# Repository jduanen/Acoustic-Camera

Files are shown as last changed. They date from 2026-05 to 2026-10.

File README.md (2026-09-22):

# Acoustic-Camera
The design and implementation of a low-cost, high-performance, acoustic camera

An Acoustic Camera computes a power map of the sound scene that exists within a video camera's field of view and overlays it onto the video in real time.
Capturing, visualizing, and tracking the position of sound sources is useful in a variety of different use cases, including the detection and localization of sources of vibration, gas leaks, electrical breakdown, etc. 
Acoustic Cameras can also serve as a useful prosthetic device for people who have lost hearing in one ear and can no longer localize sound sources.

See an example of a commercial product here [Fluke](https://youtu.be/UPVcwDzhBZ8) and a low-cost consumer product here [Fotric](https://youtu.be/MBhJoPzHv2Y)

# Table of Contents

* [Technical Background](#technical-background)
  - How Microphone Arrays Localize Sound Sources
  - Selected Beamforming Algorithm Families
  - Key Concepts in Beamforming
    * Half-Power Bandwidth (HPBW)
    * Max Sidelobe Level (MSL)
    * Far-Field vs. Near-Field Effects
    * Spatial Nyquist Frequency
    * Low-frequency Limit
    * Cross-Spectral Matrix (CSM)
    * Point Spread Function (PSF)
    * Incoherent Octave-band Averaging
  - Microphone Array Configurations
    * 2D patterns
    * 3D patterns
* [Design Trade-offs](#design-trade-offs)
  - Core Tradeoffs/Tensions
  - Key Specifications
    * Spatial Nyquist Frequency
    * Beamforming Sampling Grid Size
    * Resolution vs. Aperture (HPBW ≈ 58° × λ/D)
    * Array Pattern: Underbrink multi-arm log-spiral (chosen pattern)
* [System Requirements](#system-requirements)
* [Target Design](#target-design)
  - Microphone Array
  - Interface
  - Compute
  - Software
* [Development Plan](#development-plan)
  - [Phase 1: Simulation Findings](#phase-1)
    * Recommended Array Configuration
    * Beamwidth vs Frequency
    * Algorithm Selection
    * Where This System Works Well
    * Where This System is NOT Well-Suited
  - [Phase 2: Smoke Test -- ReSpeaker 4-Mic Array](#phase-2)
    * Hardware Findings
    * Pipeline Validation (nb13)
    * Calibration (nb14)
    * Live Script
  - [Phase 3: Intermediate Array Test -- miniDSP UMA-16 v2](#phase-3)
    * Hardware Findings
    * Live Script
      - Touch UI: Frequency Sliders & Spectrum Pan
      - Touch UI: Energy Threshold Tab & Auto/Manual Range
      - Touch UI: Zoom Mode
      - Power/Throttle Indicator
      - Settings Persistence
    * Algorithm Benchmark Script
    * Lessons from the UMA-16 Experiments
      - Key Intuition
      - Rule of Thumb
      - UMA-16 Usable Frequency Range
  - [Phase 4: Custom Hardware -- 96-mic with FPGA on custom PCB](#phase-4)
  - [Phase 5: ML-based approach](#phase-5)
* [Acoustic Camera Products Overview](#acoustic-camera-products-overview)
* [Beamforming Projects and Libraries](#beamforming-projects-and-libraries)
* [References](#references)
  - Beamforming Algorithms
  - Microphone Array Patterns
  - Commercial Acoustic Camera Products
  - Open-Source Projects and Libraries
* Docs
* Notes

---

## Technical Background

### How Microphone Arrays Localize Sound Sources

The mic array captures the sound field simultaneously at all microphones. A **steering matrix** encodes the expected inter-mic phase pattern for each candidate direction (az, el). A beamformer correlates the received signals against each steering vector and assigns a power value to each grid cell, producing an **energy map** that is overlaid on the video frame.

The key parameters are: **aperture** (sets beam width: larger = sharper), **mic spacing** (sets the spatial Nyquist ceiling; closer = higher frequency limit), and **snapshot count** (sets CSM estimation quality; more = lower noise floor).

### Selected Beamforming Algorithm Families

| Family | Algorithms | Characteristic |
|---|---|---|
| **Delay-and-Sum** | D&S (time or freq domain), Differential, Functional Beamforming | Simple; robust; wide beam; sidelobes mask weak sources |
| **Adaptive / data-dependent** | MVDR (Capon), LCMV, GSC, Frost | Null interferers; sensitive to CSM quality and steering errors |
| **Deconvolution** | CLEAN-SC, CLEAN-PSF, DAMAS, DAMAS2, CMF, COMET2 | Remove PSF artifacts iteratively; reveal secondary sources |
| **Subspace** | MUSIC, Root-MUSIC, ESPRIT, CSSM, TR-MUSIC | Decompose CSM into signal + noise subspaces; super-resolution; require source count estimate |
| **Sparse / Bayesian** | SBL, Atomic Norm Minimization | Gridless; auto-estimates source count; expensive |
| **Spherical-harmonic** | PWD, CroPaC | For spherical arrays; Ambisonics / HOA domain |
| **ML-based** | CNN/CRNN DoA, Transformer (SELD-Conformer), PILOT, Deep MUSIC, NN-MVDR | Learned models; top DCASE benchmarks; need training data matched to array geometry |

In the initial phases of this project, I will explore representative algorithms from each of the first for families -- i.e., D&S, MVDR, CLEAN, and MUSIC.
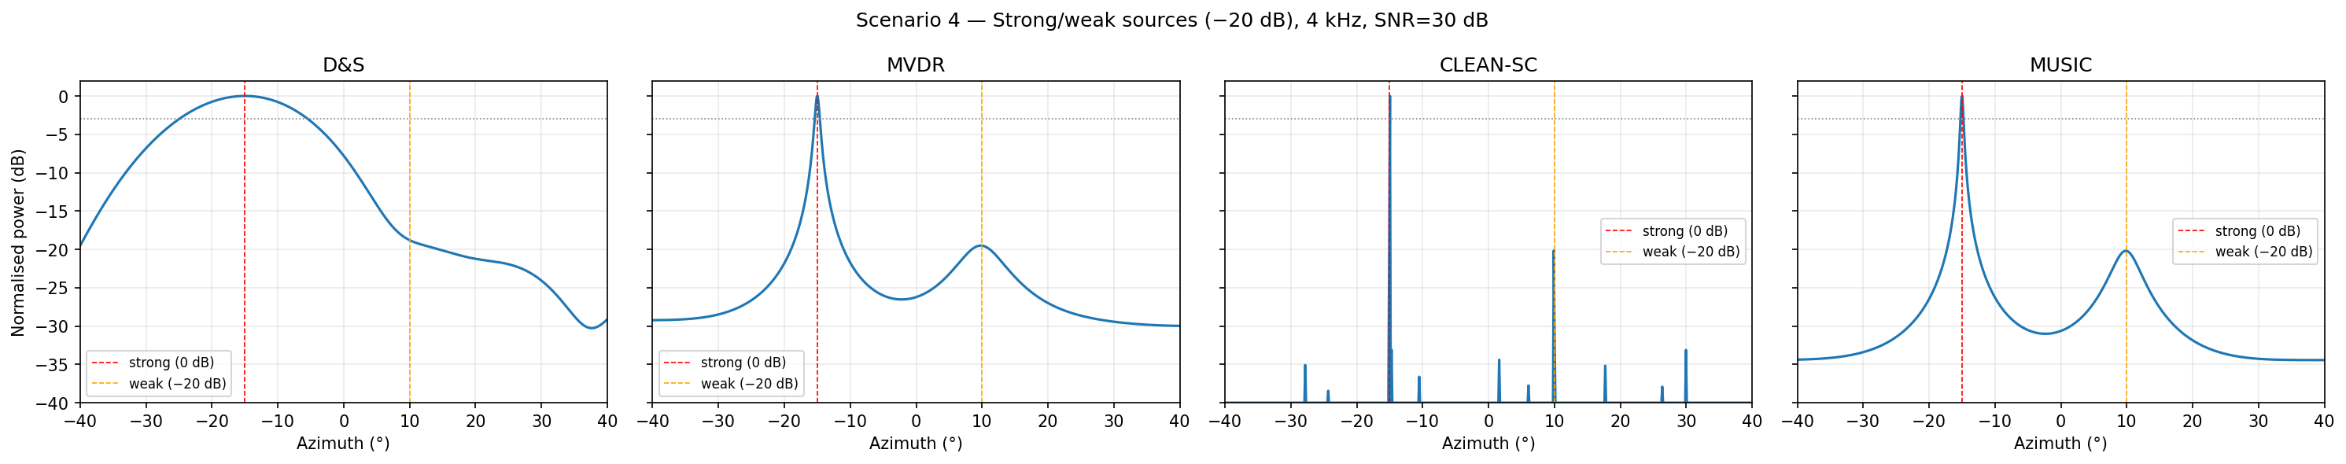
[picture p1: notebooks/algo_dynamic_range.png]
Power vs. Azimuth

**Figure:** *Example power vs. azimuth plots for a strong and a weak sound source for different algorithms*

### Key Concepts in Beamforming

#### Half-Power Bandwidth (HPBW)

HPBW characterizes the angular width of the main lobe of the beam pattern (typically at the −3 dB points).

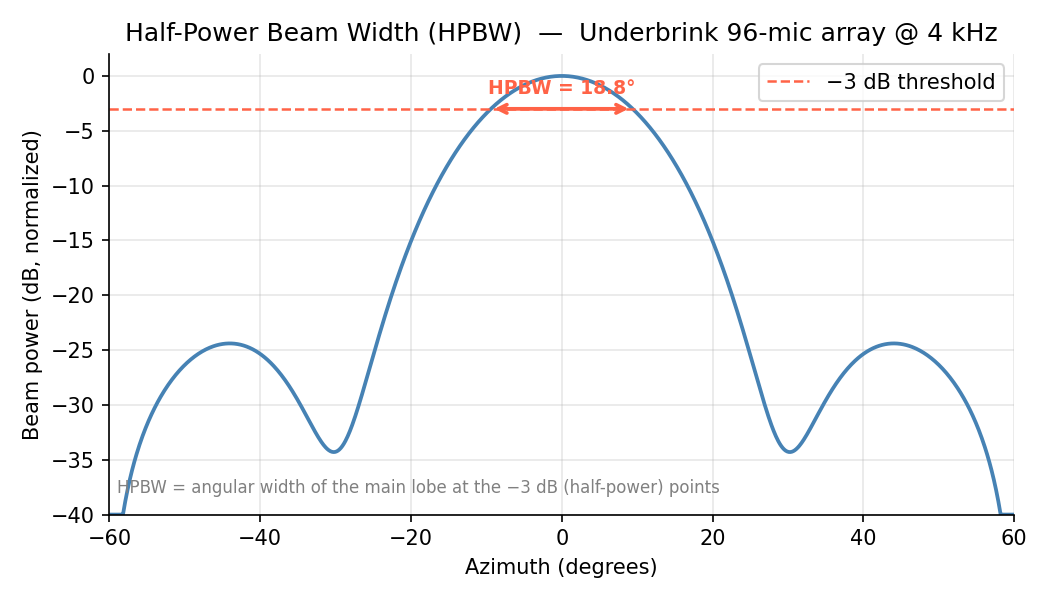
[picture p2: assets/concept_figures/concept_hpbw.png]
HPBW

**Figure:** *Beam pattern with -3 dB crossing points annotated*

#### Max Sidelobe Level (MSL)

MSL is a metric that measures the power of the sidelobes relative to the main‑lobe peak, usually expressed in decibels (e.g., "20 dB below the main lobe"). MSL is largely defined by the distribution of microphones; irregular spacing suppresses aliasing artifacts.

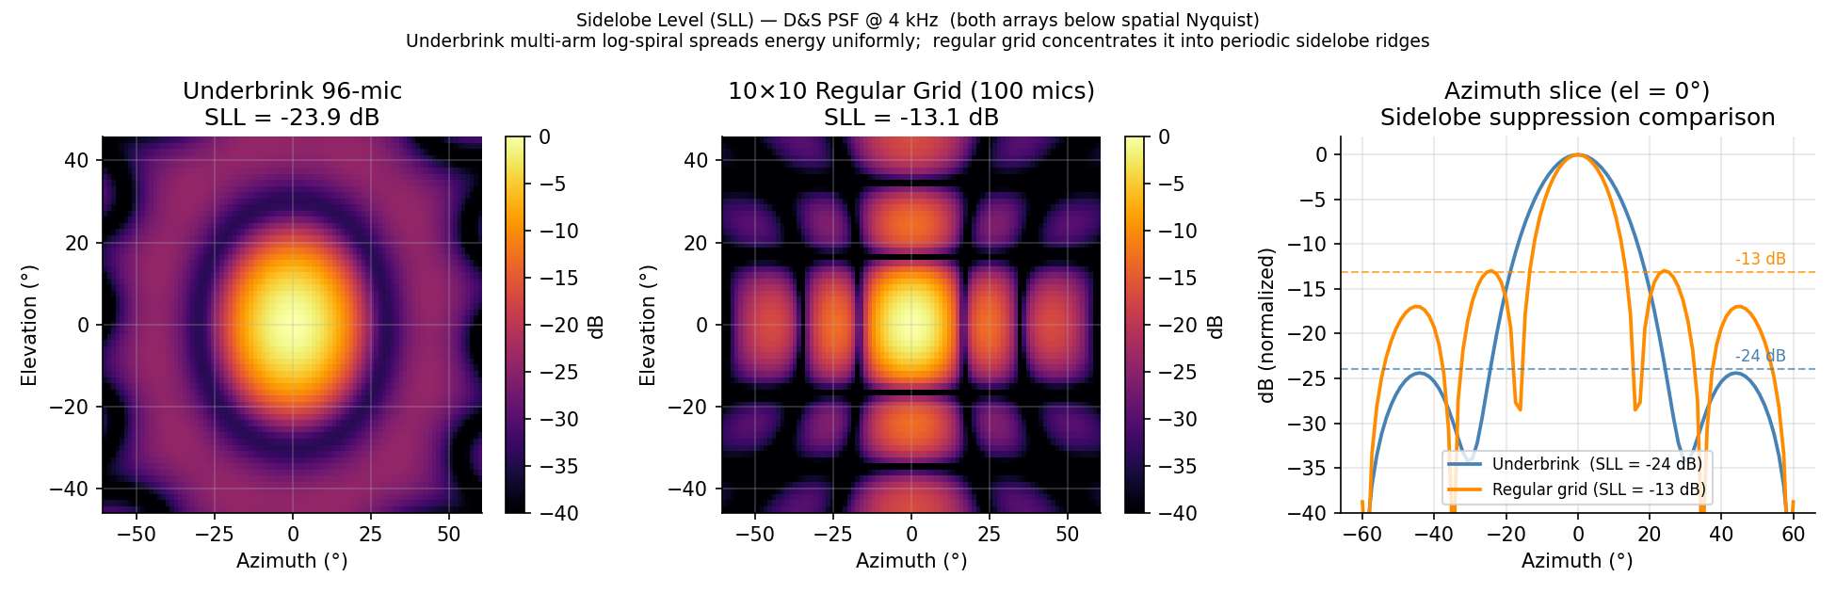
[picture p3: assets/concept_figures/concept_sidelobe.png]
Sidelobe Level

**Figure:** *2D PSF with azimuth slice for Underbrink vs. Regular Grid*

#### Far-Field vs. Near-Field Effects

Far-field (beyond the Fraunhofer distance: *r > 2D²/λ*) assumes plane waves and requires only angle steering; near-field requires a spherical-wave model and adds range estimation.

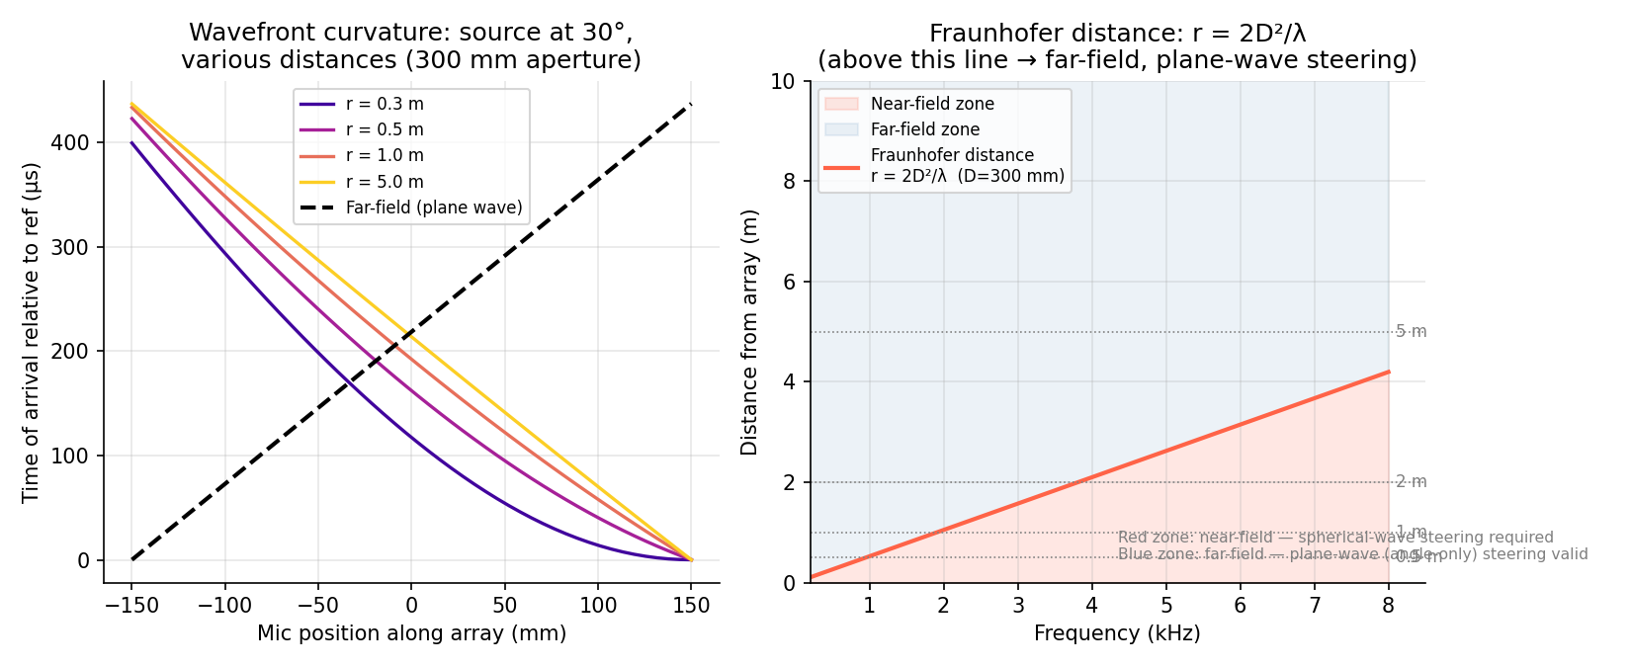
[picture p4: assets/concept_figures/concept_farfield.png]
Far-Field vs Near-Field

**Figure:** *Left: wavefront curvature at different distances; Right: Frauenhofer boundary vs. frequency*

#### Spatial Nyquist Frequency

The upper frequency limit set by mic spacing: *f_max = c / (2 × d_min)*; at frequencies above this, grating lobes appear.

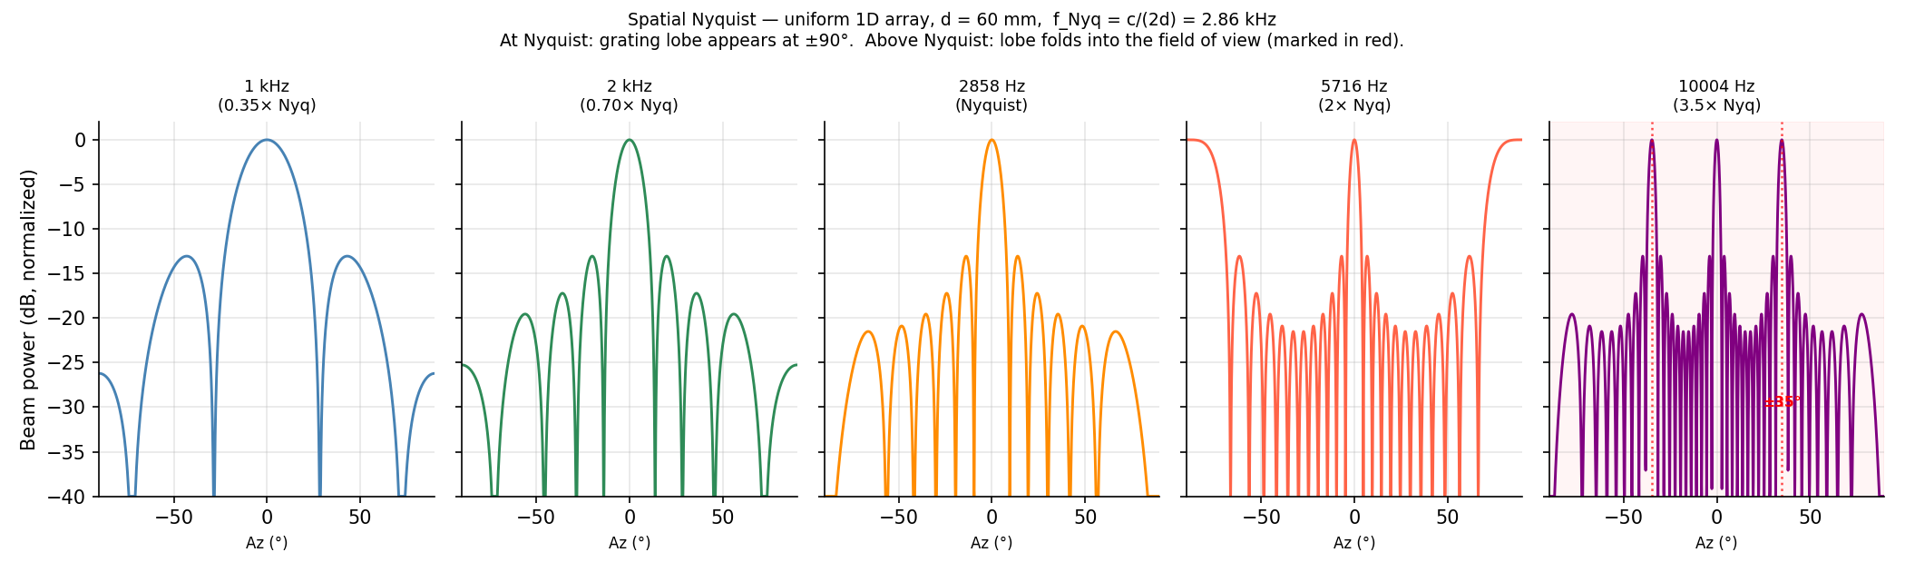
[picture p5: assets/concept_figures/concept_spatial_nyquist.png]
Spatial Nyquist

**Figure:** *1D PSF at five frequencies spanning sub-Nyquist to 3.5x Nyquist*

#### Low-frequency Limit

Usable directionality requires a frequency of roughly *f > c / D* (which is aperture-limited); below this HPBW exceeds ~57° and the array is near-omnidirectional.

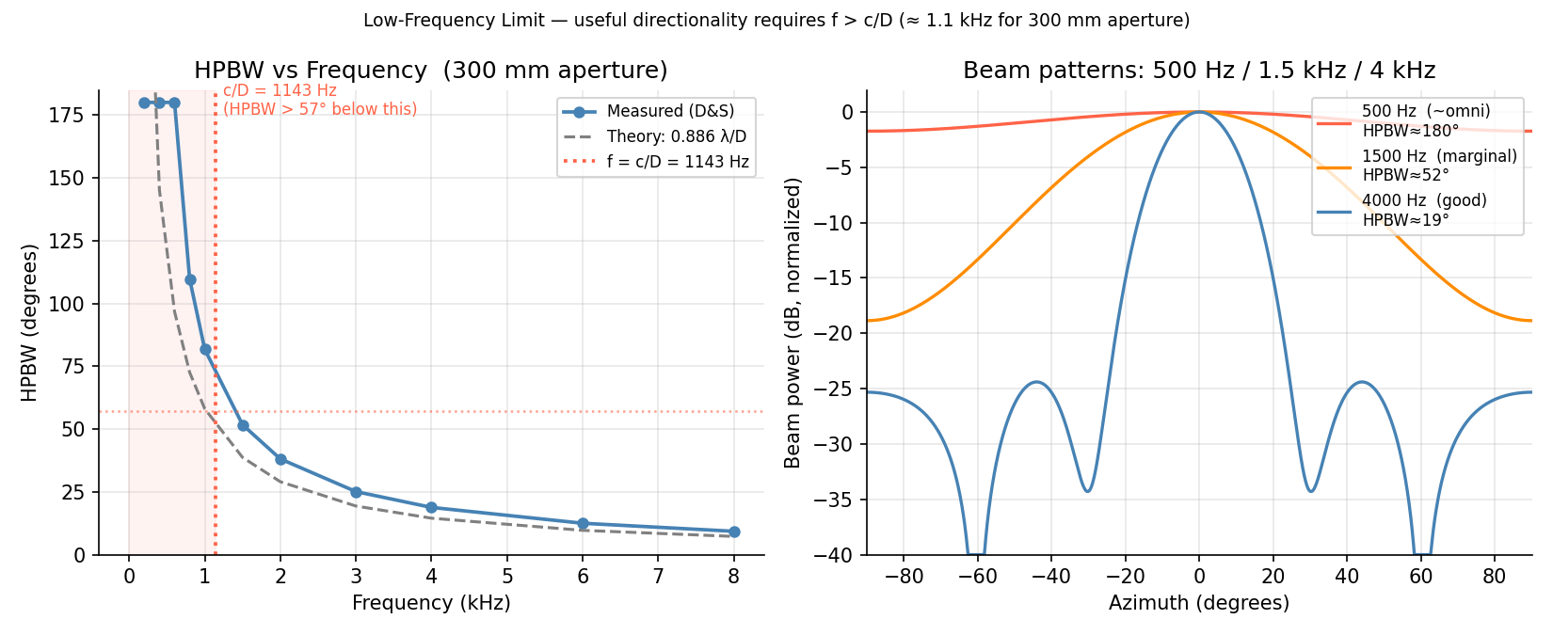
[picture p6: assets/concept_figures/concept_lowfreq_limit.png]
Low-Frequency Limit

**Figure:** *HPBW vs. frequency (measured and theoretic) and three beam patterns*

#### Cross-Spectral Matrix (CSM)

CSM is a frequency-domain matrix of cross-powers between every mic pair; the universal input to all adaptive and subspace beamformers.

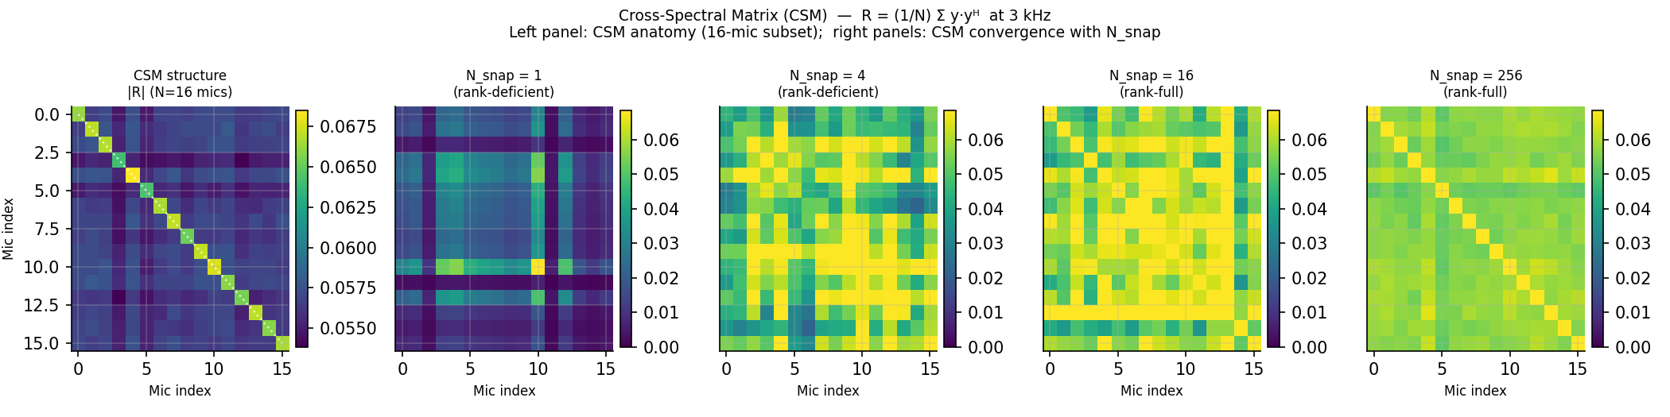
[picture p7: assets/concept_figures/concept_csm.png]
CSM

**Figure:** *Left: |CSM| magnitude heatmap for a single snapshot. Right: CSM convergence as N_snap increases (1 → 256), where N_snap is the number of independent short-time frames averaged to estimate the CSM -- more snapshots reduce the noise floor and improve MVDR/MUSIC stability.*

#### Point Spread Function (PSF)

PSF illustrates how the array smears a true point source; deconvolution methods subtract it out and offer a sharper response.

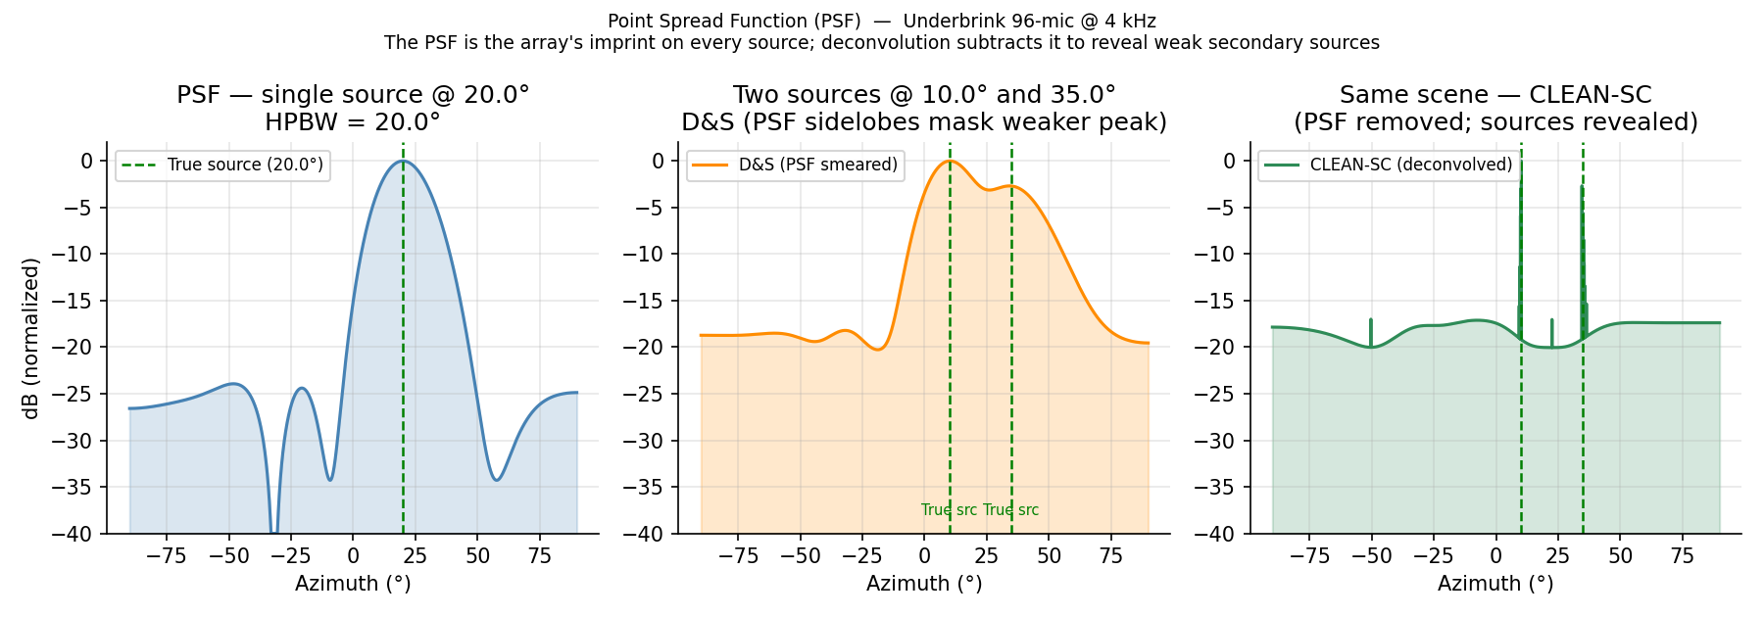
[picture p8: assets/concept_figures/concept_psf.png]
PSF

**Figure:** *Single-source PSF, two-source D&S (smeared) and CLEAN-SC (resolved)*

#### Incoherent Octave-band Averaging

Commercial cameras compute one CSM per frequency bin, beamform each, then average power across an octave band; this suppresses noise by *√K* and produces a band-averaged PSF.

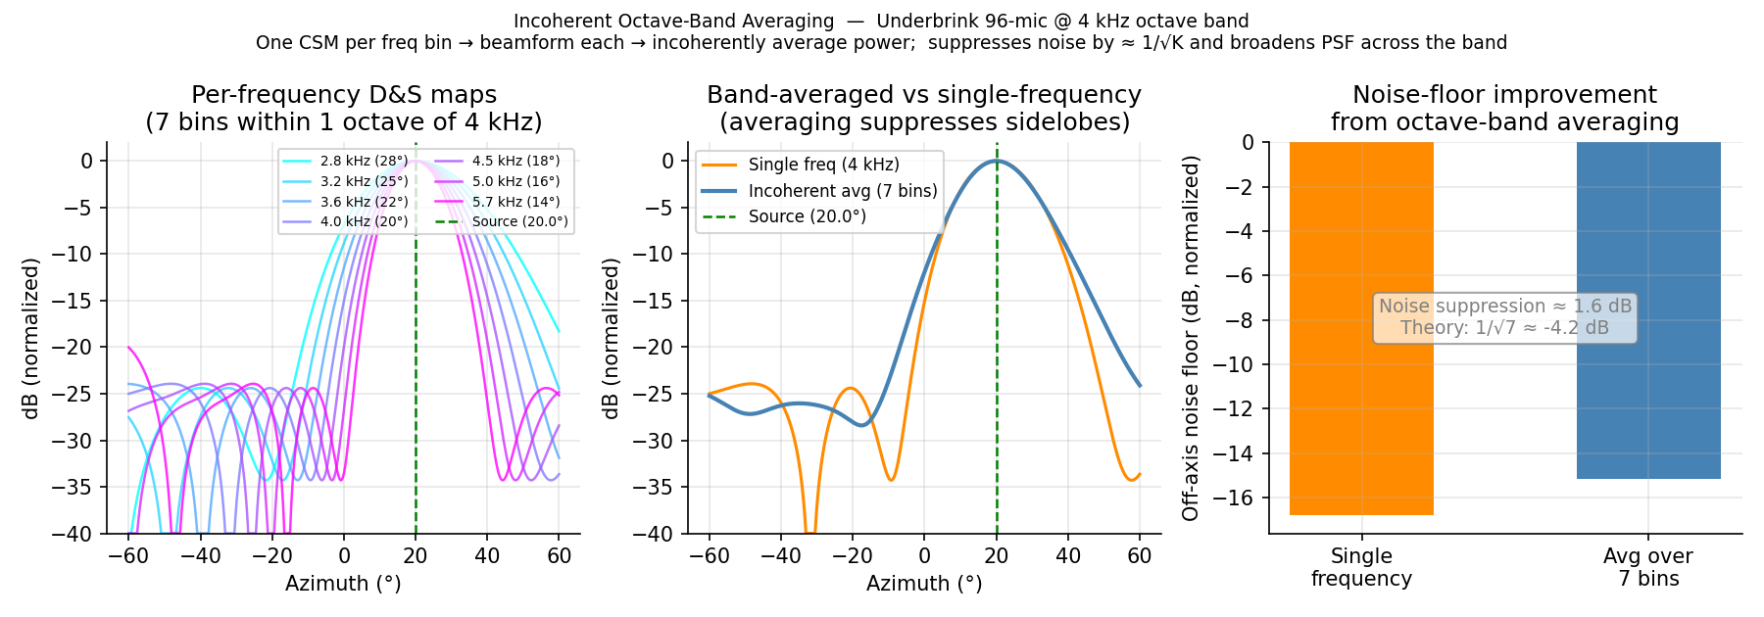
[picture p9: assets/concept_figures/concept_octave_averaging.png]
Octave-Band Averaging

**Figure:** *Per-bin maps, band average, noise-floor bar chart*

See [BACKGROUND.md](./BACKGROUND.md) for full algorithm descriptions and references.

### Microphone Array Configurations

See [MIC_ARRAYS.md](./MIC_ARRAYS.md) for more details on microphone arrays.

Array geometry controls two things: **beam width** (set by aperture; larger = sharper) and **maximum side-lobe level / MSL** (set by mic distribution; irregular spacing suppresses aliasing artifacts). More mics improve both, but with diminishing returns and linear cost growth.

#### 2D patterns

| Pattern | Spacing | Strengths | Weaknesses |
|---|---|---|---|
| **Regular grid** | Uniform | Easy to build; predictable PSF | High, periodic sidelobes; spatial aliasing above Nyquist |
| **Archimedean spiral** | Linear increase with angle | Simple single-arm; even radial coverage | Worse MSL than multi-arm variants |
| **Dougherty log-spiral** | Equal arc-length | Denser center; >10 dB sidelobe suppression at high freq | Single arm; less uniform outer coverage |
| **Arcondoulis** | Adjustable squash | Elliptical or non-circular shapes; tunable center density | More design parameters to optimize |
| **Underbrink** ★ | Multi-arm log-spiral | Best all-around: high resolution + good MSL over wide area; circular symmetry | Patented (US 6,089,671); more complex layout |
| **Brüel & Kjær spiral** | Non-uniform along spokes | Easily disassembled; two concentric hoops | Proprietary geometry |

★ Underbrink is the recommended pattern for this project (see Phase 1 findings). Literature confirms it outperforms other patterns in both resolution and MSL across tested frequencies.

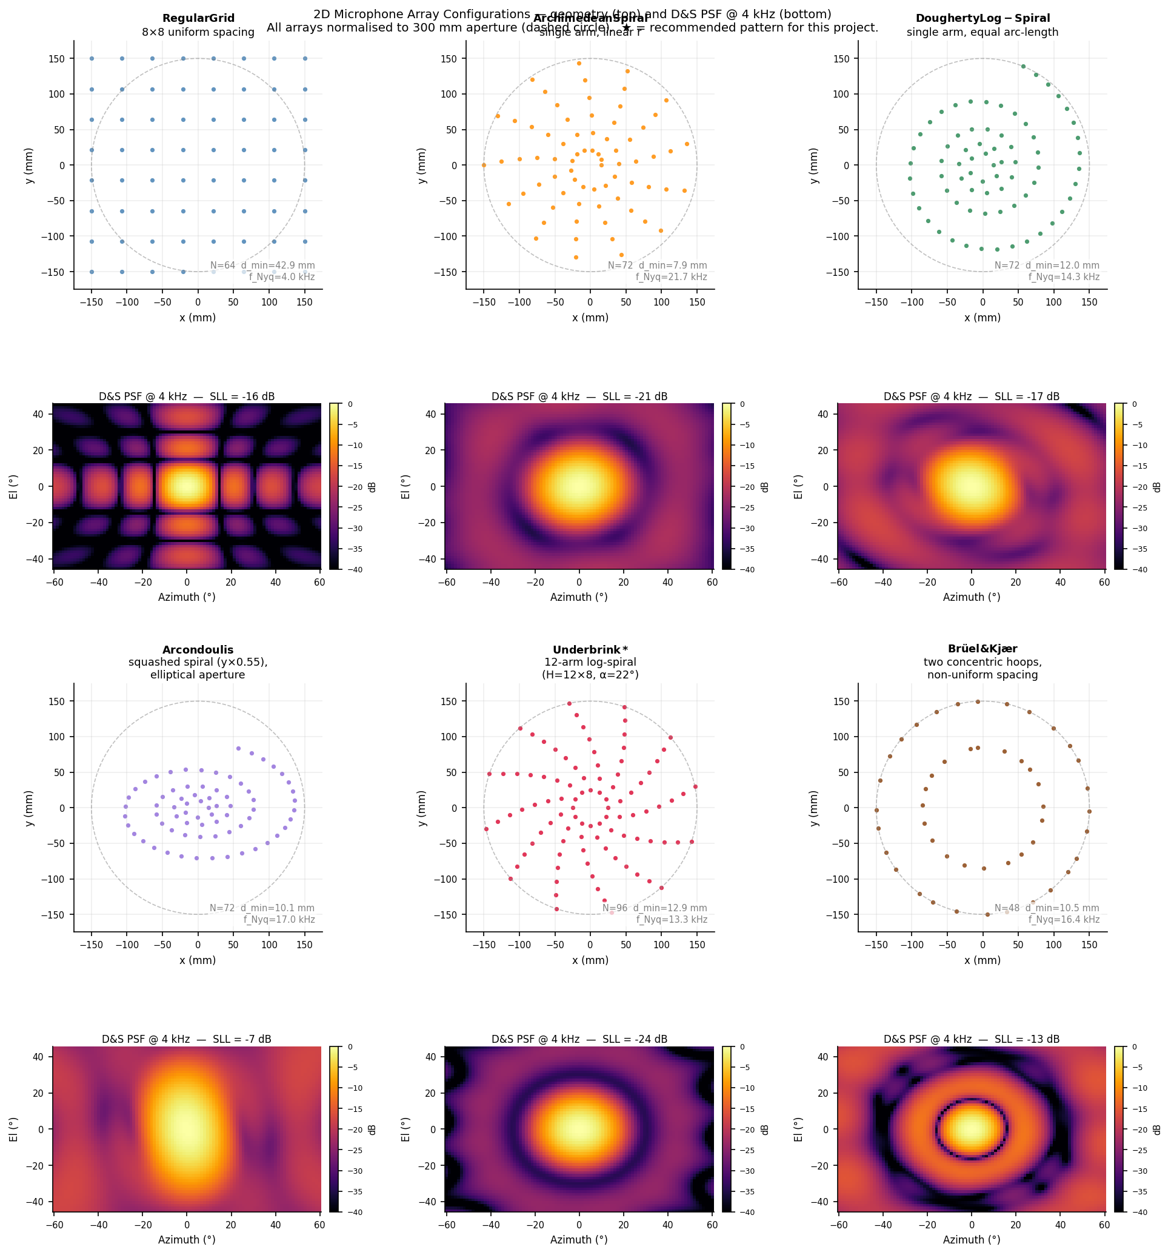
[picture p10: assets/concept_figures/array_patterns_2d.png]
2D Array Configurations

**Figure:** *Top row: mic positions (all arrays normalised to 300 mm aperture); Bottom row: D&S PSF @ 4 kHz -- SLL and aperture shape are visible consequences of each layout choice*

In the initial phases of this project, I will use a 2D microphone array. In later phases a 3D array might be used.

#### 3D patterns

| Pattern | Coverage | Framework | Notes |
|---|---|---|---|
| **Spherical** | Full *4π sr* | Higher-Order Ambisonics (HOA) | Order *N* needs *(N+1)²* mics; order 7 = 64 mics; radius sets freq ceiling |
| **Cylindrical** | 360° az; limited el | Cylindrical Harmonics | Good for horizontal-plane localization in tall spaces |
| **Tetrahedral / Platonic solid** | 3D DoA | First-order Ambisonics (4 mics) up to HOA | Smallest 3D array; Zylia ZM-1 (19 mics) = 3rd-order |
| **Nested / concentric spheres** | Full *4π sr* | Multi-shell HOA | Inner shell = high freq; outer shell = low freq; enables range estimation |

---

## Design Trade-offs

For more details, see: [TRADEOFFS](./TRADEOFFS.md)

### Core Tradeoffs/Tensions

The core tradeoffs/tensions in this project's design have to do with the specifications of the microphone array as captured in the table below:

| Parameter | Larger/More | Smaller/Fewer | Sweet spot |
|---|---|---|---|
| **Aperture** | Narrower beam, better at low-freq | Portable, cheaper, closer far-field | **300 mm** (8°@8kHz, 66°@1kHz) |
| **Mic count** | Lower sidelobes, better SNR | Less compute and cost | **96 mics** (47% packing at 300 mm) |
| **Mic spacing** | Better directionality at low freq | Aliasing-free to higher freq | **21 mm min** (Nyquist at 8 kHz) |
| **Density** | Better high-freq detail | Lower cost | 96 mics at ~27 mm avg spacing |

### Key Specifications

#### Spatial Nyquist Frequency

Raising *f_Nyq = c / (2 × d_min)* requires smaller mic spacing, which extends the upper edge of the
usable beamforming window ([*c/D*, *f_Nyq*]) and improves angular resolution at a given frequency
(*HPBW ∝ λ/D = c/(f·D)*). For the UMA-16's 126 mm aperture, the window is only 2.7–4.1 kHz
because *f_Nyq* = 4.1 kHz; halving the spacing to 21 mm would open it to 2.7–8.2 kHz.

The costs are steep: mic count scales as (aperture/d)², so halving spacing roughly quadruples
mic count, multiplying cost, PCB complexity, bandwidth, and compute (CSM scales as *N²*,
beamforming as *N × n_grid*). Mechanical tolerances tighten proportionally. At 8 kHz,
*λ/10* ≈ 4 mm, which is comparable to a MEMS mic body (~3–4 mm), leaving almost no layout margin.

The Phase 4 design (21 mm, 96 mics, 300 mm aperture) hits the practical sweet spot: *f_Nyq* = 8.2 kHz
matches the target upper limit exactly, and the aperture pulls the lower limit down to ~1.1 kHz.
Pushing spacing smaller would require ~400+ mics for marginal gain above 8 kHz, which is outside
the target range.

#### Beamforming Sampling Grid Size

The sampling grid used in the beamforming algorithms defines the limits to the achievable resolution of the device. It is chosen based on practical considerations and is not derived from the only meaningful limit, which is the HPBW. Practically speaking, two to three grid points per HPBW are needed to reliably capture a peak without aliasing. For example, with the UMA-16 mic array described below, at 3 KHz the HPBW is ~43°, so a grid of 0.5°/pt makes for ~86 samples across the full main lobe, which is about 30x oversampled for this array's resolution. Even at 4KHz (HPBW ~32°) there are 64 samples per lobe, which is more than enough.

Increasing the number of sampling grid points will consume considerably more computation and memory resources and slow the frame rate down, but will not provide any improvement in the device's resolution. The benchmarks run below indicate that the algorithms' resource consumption is dominated by the steering matrix allocation (5.3 MB for the UMA-16 experiments with a half degree grid) and not the math itself.

Using 0.5°/pt (90° ÷ 180 steps, 60° ÷ 120 steps) results in a grid of 181 x 121.

Decreasing the sampling grid saves considerable time and memory. For example, going to a 1°/pt grid (91 × 61 = 5,551 points) would result in no visible quality loss for the UMA-16 array. However, this would reduce the size of the steering matrix from 5.3 MB to 1.3 MB, which would bring D&S, MVDR, and MUSIC frame time down from ~22 msec to ~5-6 msec (a roughly linear scaling factor), and CLEAN-SC with 20 iters would go from ~85 msec to ~20 msec (making it viable for real-time display).

Grid resolution does become an issue with the Phase 4 array (300 mm aperture, HBPW ~5° @ 4 kHz), where a 0.5°/pt gives just 10 samples across the main lobe and finer grid is warranted.

#### Resolution vs. Aperture (HPBW ≈ 58° × λ/D)

| Aperture | @ 1 kHz | @ 4 kHz | @ 8 kHz |
|---|---|---|---|
| 500 mm | ~40° | ~10° | ~5° |
| **300 mm** | **~66°** | **~17°** | **~8°** |
| 200 mm | ~100° | ~25° | ~12° |

5° resolution at 1 kHz requires *D* ≈ 4 m, which is impractical. Deconvolution algorithms (e.g.,
CLEAN-SC, Functional BF) can recover some resolution beyond the physical aperture limit but
cannot overcome the hard floor.

#### Array Pattern: Underbrink multi-arm log-spiral (chosen pattern)

Outperforms concentric rings, cross arms, and simple spirals on both sidelobe level and spatial
aliasing. The **gfai Mikado** commercial product uses exactly 96 mics in this pattern. Logarithmic
radial spacing naturally covers multiple spatial scales, which is well-suited for the 200 Hz–8 kHz
target.
For this project I've selected **8 arms × 12 mics**. I will simulate 6 × 16 as alternative in Phase 1.

---

## System Requirements

The basic requirements for this project are given in the following table:

| Parameter | Value | Notes |
|---|---|---|
| Min Distance | ~0.5 m | Far-field criterion *r > 2D²/λ*; 2×0.3²/0.343 ≈ 0.5 m for 300 mm array at 1 kHz |
| Max Distance | ~10 m | Practical limit for compact array at 200 Hz |
| Resolution | ~8° @ 8 kHz, ~17° @ 4 kHz, ~66° @ 1 kHz | Scales as *λ/D*; HPBW ≈ 58° × *λ/D* for 300 mm aperture |
| FOV | ±45° H, ±30° V | Matched to co-located video camera field of view |
| Mic Array Diameter | ~300 mm | 96 mics in Underbrink spiral, ~21 mm min spacing (Nyquist at 8 kHz) |
| Frequency Range | 200 Hz - 8 kHz | Broadband; mic spacing ≤21 mm avoids spatial aliasing at 8 kHz |
| Environment | General-purpose | Indoor/outdoor, low-to-moderate reverberation, single/multiple sources |

---

## Target Design

For full details on the design, see: [DESIGN](./DESIGN.md)

### Microphone Array

- **96× Infineon IM69D120** PDM MEMS mics: 69 dBA SNR, ±1 dB sensitivity, ±2° phase match (factory-calibrated)
- **Underbrink multi-arm log-spiral**: 8 arms × 12 mics (simulate 6 × 16 as alternative in Phase 1)
- **~300 mm diameter aperture; ~21 mm minimum mic spacing**: Spatial Nyquist at 8 kHz
- **Custom PCB(s)**: mics share (carefully distributed) PDM clock, paired L/R → 48 DATA + 1 CLK to FPGA

### Interface

- prototype with embedded web UI over WiFi
- 5-7" touchscreen
- battery-powered operation

### Compute

- **Pipeline**: PDM mics → FPGA hub → GbE → Linux host PC with GPU
- **FPGA** handles: PDM clock distribution, per-channel CIC + FIR decimation (3.072 MHz PDM → 48 kHz 24-bit PCM), synchronous sampling, GbE packetization (UDP, with sequence numbers)
- **Data rate**: 96 ch × 48 kHz × 24 b ≈ 110 Mbps; fits within 1 GbE
- **FPGA** candidates: Lattice ECP5 (open-source toolchain) or Xilinx Artix-7 XC7A100T (resource headroom)
- inspired by Ben Wang's 192-mic FPGA design

### Software

- Python and Acoular for beamforming core; GPU acceleration via PyTorch/CuPy
- Algorithm progression: D&S → MVDR → CLEAN-SC → ML
- USB webcam at array center; OpenCV overlay of energy map on video
- GUI Components: Live video overlay · frequency band selector · dynamic range sliders · algorithm selector ·
persistence slider · record/stop · SPL meter · status bar

---

## Development Plan

For additional details on the project plan, see: [PLAN](./PLAN.md)

This project has been decomposed into multiple phases, each of which has a specific goal/output. Additionally, each phase delivers a working end-to-end system -- there will never be more than one phase in the "not yet working" state at any point in time.

| Phase | Hardware | Goal | Status |
|---|---|---|---|
| **1** | None (simulation) | Validate algorithms and array geometry in simulation; generate training datasets | Complete |
| **2** | ReSpeaker XVF3800 (4-mic, 90 mm) | End-to-end pipeline: capture → beamform → overlay; surface real-world issues | Complete |
| **3** | miniDSP UMA-16 v2 (16-mic, 126 mm) | Scale to 16 channels; 2D Az × El beamforming; validate MVDR/MUSIC benefit | Complete |
| **4** | Custom PCB (96-mic, 300 mm, FPGA hub) | Full-performance system meeting all requirements | In progress |
| **5** | Phase 3/4 hardware | ML-based beamformer (PILOT / CRNN); benchmark vs CLEAN-SC | Not started |

### Phase 1: Simulation Findings

Full results and methodology are in: [PHASE1](./PHASE1.md)

#### Recommended Array Configuration

**Underbrink H=12×8, α=22°**: 96 mics, 300 mm aperture, 12.9 mm min spacing

- Best side-lobe suppression of all patterns tested: -24.4 dB @ 4 kHz, -18.9 dB @ 8 kHz
- Alias-free to ~13 kHz (target ceiling: 8 kHz, 1.7× margin)
- Perfect circular symmetry; azimuth and elevation HPBW are identical at all frequencies

Alternative: *H*=8×12, *α*=35° (-14.4 dB MSL, simpler layout, more uniform spacing, which is good if PCB routing is constrained)

#### Beamwidth vs Frequency

| Frequency | HPBW | Practical meaning |
|---|---|---|
| 200–500 Hz | > 180° | Omnidirectional -- no spatial selectivity |
| 1 kHz | ~82° | Barely directional; cannot resolve sources within ~80° |
| 2 kHz | ~37° | Minimum frequency for useful imaging |
| 4 kHz | ~19° | Clear maps; commercial acoustic cameras primarily operate here |
| 8 kHz | ~9° | High-resolution; closely-spaced sources resolvable |

#### Algorithm Selection

| Use case | Recommended |
|---|---|
| Real-time display, single dominant source | CLEAN-SC |
| Multiple sources or weak source detection | MVDR |
| Closely-spaced sources, source count known | MUSIC |
| Lowest latency / embedded compute | D&S |
| Near-field range + angle estimation | Focused D&S or MVDR/MUSIC with NF steering |

Recommended snapshot count: **N_SNAP = 256** (5.3 ms, 188 fps). All algorithms converge at N_SNAP = 16
(0.3 ms); 256 provides 16× margin while remaining below the ~10 ms perceptual latency threshold.

#### Where This System Works Well

- **Mechanical/industrial source hunting at 2-8 kHz**: the primary sweet spot. Fan noise, gear mesh,
  bearing defect harmonics, structural resonances. MVDR/MUSIC resolve sources separated by 10-15° that
  D&S cannot
- **Multi-source scenes**: MVDR and MUSIC maintain 100% resolution reliability down to DRR = -3 dB
  (reverb exceeding direct power). MUSIC handles sub-HPBW separations when source count is known
- **Typical indoor rooms and labs (DRR ≥ 10 dB)**: 96 channels provide ~20 dB array gain; DoA error
  at typical office DRR is indistinguishable from anechoic (~0.035°). Mild reverberation suppression is essentially free
- **Near-field operation at 0.5-3 m**: spherical-wave steering recovers range to within ~10 cm and
  azimuth within grid quantization. Sub-centimeter range error at 1.5 m in simulation
- **Outdoors or in treated spaces**: consistent strong performance; no special mitigation needed

#### Where This System is NOT Well-Suited

- **Below 1 kHz**: the array is omnidirectional at 200–500 Hz and barely directional at 1 kHz
  A dedicated low-frequency array would need ~1.7 m aperture for 10° resolution at 1 kHz
- **Highly reverberant industrial environments (DRR < 3 dB)**: concrete rooms, large metal enclosures,
  live rooms. Spatial pre-filtering (WPE) is needed before beamforming
- **Same-azimuth, different-range source separation**: range resolution along a single bearing at
  4 kHz / 300 mm aperture is ~1 m. Co-azimutal sources closer than ~1 m merge into a single peak.
  A colocated depth camera is the practical solution
- **Low SNR (< 10 dB) with MUSIC**: overcounting `n_sources` produces 93-100% false alarm rate below
  10 dB SNR. D&S and MVDR degrade more gracefully; use AIC/MDL model-order selection or conservative
  `n_sources` at low SNR
- **High dynamic range (weak source near a strong source) with D&S or CLEAN-SC**: a -20 dB weak source
  25° from a strong source is reliably detected only by MVDR and MUSIC
- **Sources beyond ~3-4 m**: range estimation degrades sharply beyond the Fraunhofer distance (2.1 m
  at 4 kHz). Far-field azimuth-only mode still works at long range; range information is unavailable

### Phase 2: Smoke Test -- ReSpeaker 4-Mic Array

Full results and methodology: [PHASE2](./PHASE2.md)

End-to-end pipeline validation on real hardware. The goal to create a fully functional (not high performance) pipeline: audio capture → beamforming → energy map → video overlay.

Hardware: **ReSpeaker XVF3800 USB 4-Mic Array** (4 mics, 90mm aperture, 16 kHz, driverless USB).
https://www.seeedstudio.com/ReSpeaker-XVF3800-USB-Mic-Array-p-6488.html

#### Hardware Findings

- USB device index 12; 6 channels at 16 kHz; 23.9 ms latency
- Channel mapping: ch0 = Conference processed, ch1 = ASR processed, **ch2-5 = Mic 0-3 raw**
- Mic gain imbalance up to ~3.6× across raw channels (Mic 1 consistently lower); motivates calibration

#### Pipeline Validation (nb13)

Welch-style CSM from 3 sec ambient recording (~373 blocks at 256-sample blocks, 128-sample hop):

| Algorithm | Peak (°) | Notes |
|---|---|---|
| D&S | 2.7° | Near boresight; consistent with dominant frontal source |
| MVDR | 7.5° | Near boresight |
| CLEAN-SC | 2.7° | Near boresight |

All three agree within 5° -- **PASS**.

Peaks are stable 500-1750 Hz; scatter increases at 2000-2250 Hz as expected near the 2695 Hz spatial Nyquist.

#### Calibration (nb14)

Cross-correlation-based gain and phase calibration. Run `notebooks/14_respeaker_calibration.ipynb` while playing a 1 kHz sine tone from boresight at 0.5-1 m to obtain valid calibration. Calibration vector saved to `test/ReSpeaker/cal.npy`.

#### Live Script

```bash
python src/acoustic_camera_p2.py                              # D&S, 1000 Hz
python src/acoustic_camera_p2.py --algo music --freq 2000     # MUSIC, 1 source
python src/acoustic_camera_p2.py --algo music --freq 2000 --nsrc 2 --video 4
python src/acoustic_camera_p2.py --algo mvdr --freq 1500 --cal test/ReSpeaker/cal.npy
```

Real-time two-thread pipeline: `sounddevice.InputStream` → sliding CSM → beamform → COLORMAP_INFERNO energy strip overlaid on webcam frame. Strip brightness reflects absolute audio level (running peak reference, ~10 s decay). Peak direction shown as a green vertical line. FPS displayed in overlay.

Algorithms: `ds`, `mvdr`, `clean` (CLEAN-SC), `music`. For MUSIC, `--nsrc` sets the signal subspace dimension (default 1); noise subspace = N − n_src eigenvectors. Use 1500–2000 Hz for meaningful directionality with this 4-mic array.

### Phase 3: Intermediate Array Test -- miniDSP UMA-16 v2

Full results and methodology: [PHASE3](./PHASE3.md)

16-mic 4×4 URA pipeline validation: audio capture → 2D beamforming (Az × El) → full-frame overlay.
The goals of this phase include validating 2D beamforming, calibration, and video overlay on real hardware (at higher resolution than Phase 2), measuring the resources required by each algorithm, and gaining experience with practical application in the real-world environment.

Hardware: **miniDSP UMA-16 v2** (16 mics, 126 mm × 126 mm aperture, 48 kHz, driverless USB).
https://www.minidsp.com/products/usb-audio-interface/uma-16-microphone-array

#### Hardware Images

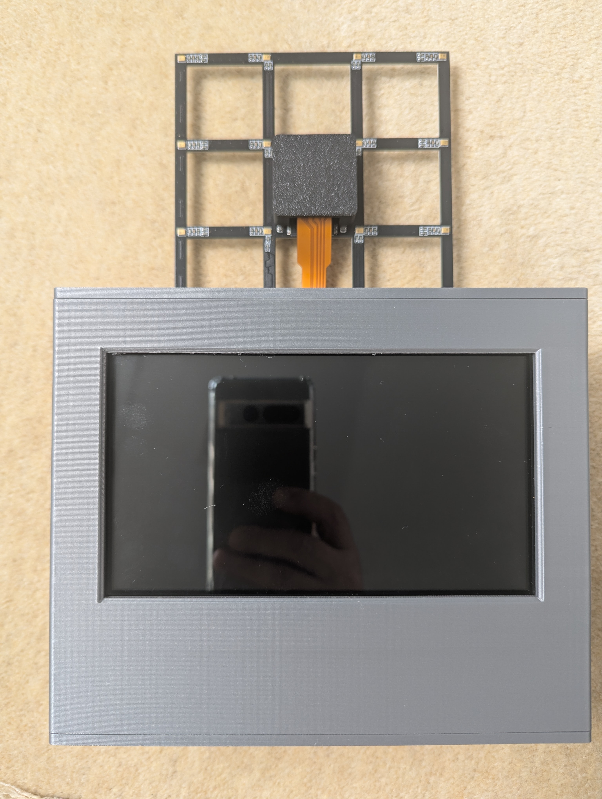
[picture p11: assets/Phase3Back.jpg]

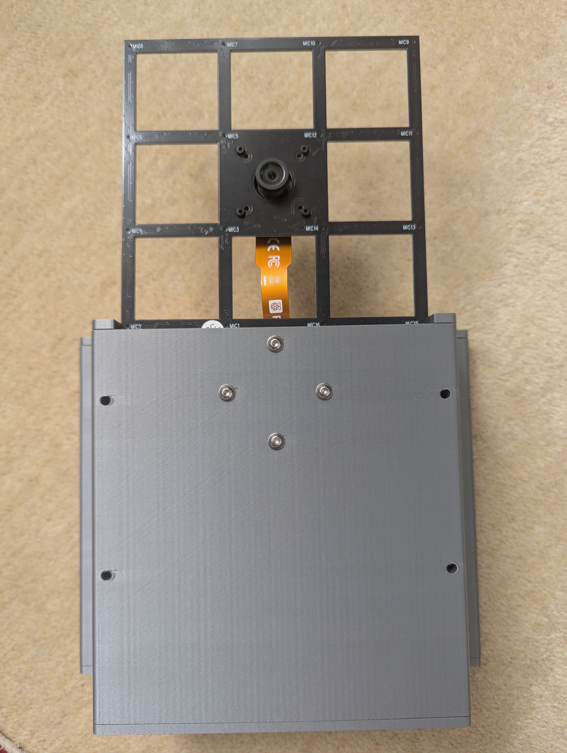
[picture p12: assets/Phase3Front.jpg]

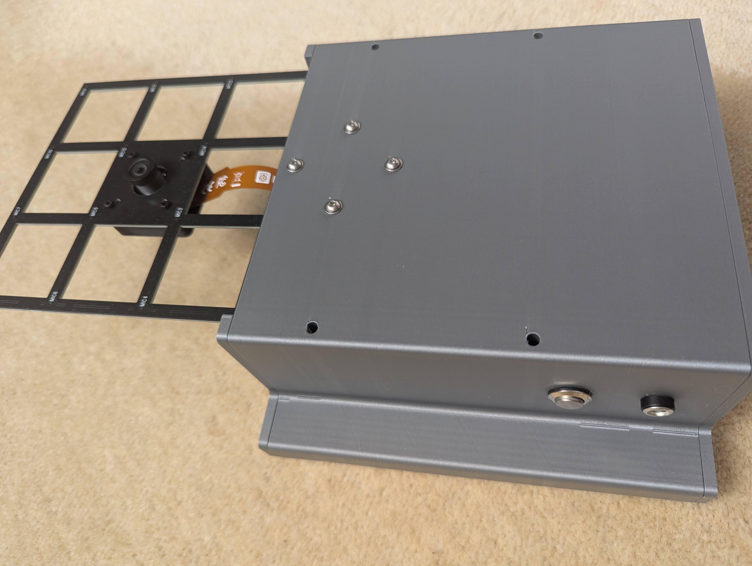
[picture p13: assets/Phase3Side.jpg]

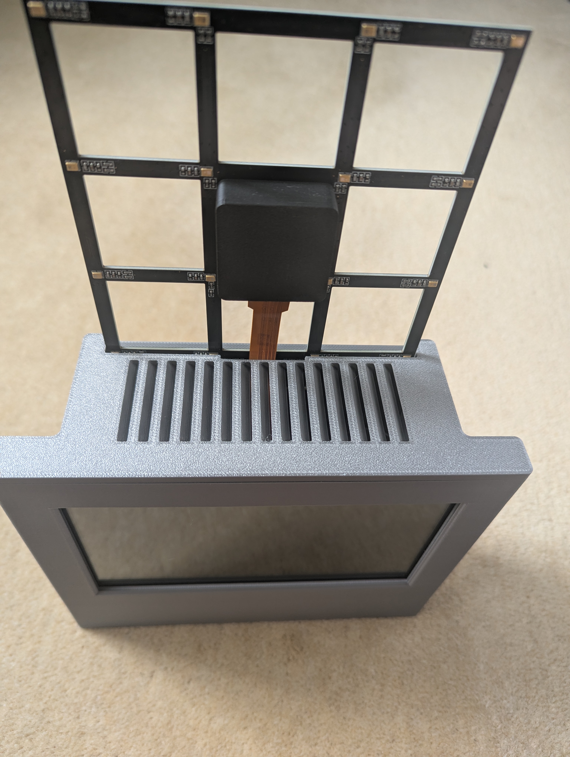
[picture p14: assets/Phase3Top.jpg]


#### Hardware Findings

- USB device index 12; 16 channels at 48 kHz; Knowles SPH1668LM4H-1 MEMS mics (65.5 dB SNR)
- All 16 USB channels are raw mic data (no processed channels as in Phase 2)
- RMS levels balanced across channels (~5e-5 ambient noise floor)
- Channel ordering: PDM L/R pairs per data line (see [PHASE3](./PHASE3.md) for mapping)

#### Live Script

```bash
python src/acoustic_camera_p3.py                                  # D&S
python src/acoustic_camera_p3.py --algo mvdr                      # MVDR
python src/acoustic_camera_p3.py --algo music --nsrc 2            # MUSIC, 2 sources
python src/acoustic_camera_p3.py --cal test/UMA16/cal.npy         # with calibration
```

The beamforming frequency is set live by the on-screen F lo / F hi sliders (there is no
`--freq` argument). The shared beamforming math (geometry, steering matrix, D&S/MVDR/
CLEAN-SC/MUSIC, CSM) lives in `src/beamforming.py`, used by both this script and
`src/benchmark_algos.py`, with a pytest suite in `tests/`.

##### Example Screengrab
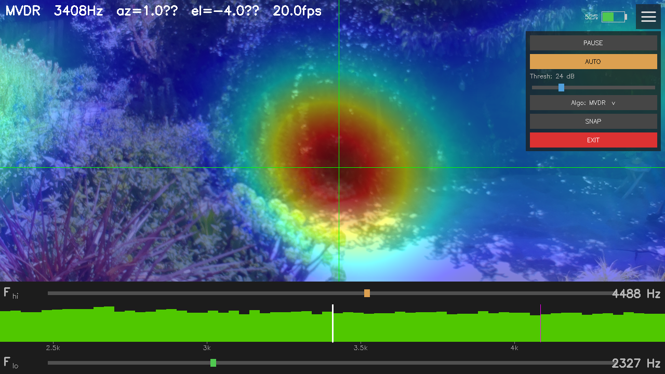
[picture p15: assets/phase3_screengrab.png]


Real-time two-thread pipeline: `sounddevice.InputStream` (16-ch, 48 kHz) → sliding CSM →
2D beamform (azimuth × elevation grid) → COLORMAP_JET full-frame overlay blended onto
webcam video, in one of two modes (Auto/Manual — see "Touch UI: Energy Threshold Tab"
below). Green cross-hair marks peak direction (az, el). FPS displayed in overlay.

Below the video, top to bottom: an **F<sub>hi</sub>** slider strip, a spectrum plot, then an **F<sub>lo</sub>**
slider strip (the two are on opposite sides of the plot, not stacked together — see
"Touch UI" below for why). The green bars in the spectrum plot show energy per frequency
bin, from `f_lo` on the left to `f_hi` on the right; a white vertical line at the center
marks the current beamforming frequency (`freq = (f_lo + f_hi) / 2`), also shown in the
status line at the top of the video pane. Defaults: `f_lo=500Hz`, `f_hi=4000Hz`. Dragging
the spectrum plot itself (rather than either slider) pans `f_lo`/`f_hi` together,
preserving the gap between them, instead of resizing the range.

The algorithms that are implemented in this application are `ds`, `mvdr`, `clean` (CLEAN-SC), and `music`. The microphone array has a Spatial Nyquist frequency of ~4.1 kHz. This device should be operated at between 2000-3700 Hz for it to provide meaningful 2D directionality.

With *N*=16 mics, the MVDR/MUSIC algorithms provide measurable super-resolution benefit over D&S.

##### Touch UI: Zoom Mode

A **ZOOM** / **RECENTER** control pair in the settings popup (below Pause/Resume) switches
the display from the normal wide realtime view into a locked-on close-up of the loudest
detected source:

- **ZOOM**: captures the current beamformer peak (az, el), reconfigures the camera to its
  full native sensor resolution, and crops a ~3x digital-zoom window around that direction —
  held fixed ("frozen") even as the live video and heatmap keep updating inside it. The
  button relabels to **REALTIME**.
- **RECENTER** (only shown while zoomed): re-reads the current beamformer peak and
  re-freezes the crop there, without leaving Zoom mode.
- **REALTIME** (the same button, now relabeled): exits Zoom, reconfigures the camera back
  to its normal display resolution, and returns to the full wide-angle view.

Audio/CSM beamforming keeps running continuously while zoomed, so RECENTER always has a
fresh peak to jump to, and the green cross-hair keeps tracking the live peak position
inside the frozen crop. The JET heatmap overlay is cropped and resized in lock-step with
the video so the two stay aligned. `[ZOOM]` appears in the status line while active. For
the CSI camera, `Picamera2.sensor_resolution` (falling back to
`camera_properties['PixelArraySize']`) supplies the native resolution; for a plain USB
webcam, the native resolution is queried by requesting an oversized
`CAP_PROP_FRAME_WIDTH`/`HEIGHT` and reading back whatever the driver actually clamped it to.

A **Dwell** slider (shown only while zoomed, below Recenter) controls how long the crop
holds still before automatically re-centering on its own, without waiting for a manual
Recenter tap. It has discrete detents rather than a continuous range: `Follow` (0s) at
one end re-centers on every frame, tracking the loudest source continuously; `HOLD` at
the other end is today's original behavior — stay frozen until Recenter or Exit Zoom is
tapped. In between are fixed steps from a couple of seconds up to a few minutes
(2s, 5s, 10s, 15s, 20s, 30s, 45s, 1m, 1.5m, 2m, 2.5m, 3m), so both fine adjustments near
"follow" and longer holds are easy to dial in. Like the frequency band and energy
threshold, the Dwell setting is saved to `config.json` and restored on the next run.

#### Algorithm Benchmark Script

```bash
python src/benchmark_algos.py                             # all four algorithms, 3 kHz, 20 fps target
python src/benchmark_algos.py --algos ds mvdr music       # skip CLEAN-SC
python src/benchmark_algos.py --clean_iters 5 --fps 10    # CLEAN-SC feasibility at 10 fps
python src/benchmark_algos.py --freq 2000 --iters 100     # higher-confidence timing at 2 kHz
python src/benchmark_algos.py --grid_deg 1.0              # coarser grid; ~4× faster
```

Loads a pre-recorded WAV (`test/UMA16/capture_nb16.wav` by default), computes a single CSM
(128 snapshots, calibration applied), then benchmarks each algorithm over `--iters` repetitions.

Reports per-algorithm mean time, std dev, peak Python-heap allocation, and RT% (time as a
fraction of the frame budget at the target fps). A pipeline total (CSM + algo) is shown for
each algorithm.

Grid density is set by `--grid_deg` (degrees per point); number of grid points is derived as
`round(fov / grid_deg) + 1` in each axis. At the default 0.5°/pt the UMA-16's ~43° HPBW at
3 kHz is already sampled ~86×, which is far more than needed. A 1°/pt grid is sufficient for this
array and cuts steering matrix memory 4× (5.3 MB → 1.4 MB), bringing all four algorithms
within the 20 fps budget.

| `--grid_deg` | Grid points | Steer MB | D&S ms | MVDR ms | CLEAN-SC ms | MUSIC ms |
|---:|---:|---:|---:|---:|---:|---:|
| 0.5° (default) | 181 × 121 = 21,901 | 5.3 | ~21 | ~22 | ~85 | ~22 |
| 1.0° | 91 × 61 = 5,551 | 1.4 | ~7  | ~5  | ~14 | ~5  |

CLEAN-SC scales with `--clean_iters`; at 0.5°/pt, use ≤ 10 iters for 20 fps viability.
Peak MB reflects Python-heap allocations only; actual RSS will be higher due to C/LAPACK
internal buffers.

Key CLI options: `--audio`, `--freq`, `--snap`, `--iters`, `--algos`, `--clean_iters`,
`--nsrc`, `--grid_deg`, `--az_fov`, `--el_fov`, `--fps`, `--cal`.

#### Lessons from the UMA-16 Experiments

##### Key Intuition
- mic arrays figure out locations based on direction of arrival
  * they figure out direction of arrival based on the input signal's phase differences at different mics
  * at high frequency, a 10deg shift in angle of arrival results in a large, easily measureable phase difference 
- phase differences grow with frequency
  * low frequency sound waves are hard to localize
  * at low frequency, the phase shift that results from a 10deg shift in angle of arrival is lost in the noise
- min spacing of mics defines Spatial Nyquist
  * can't go to higher frequency than this to get better localization

##### Rule of Thumb
- Useful directionality requires roughly *λ < D*, i.e.:
  * *f > c / D* = 343 / 0.126 ≈ 2.7 kHz for the UMA-16
- Below that frequency, the HPBW exceeds ~57° and degrades fast:

| Freq | HPBW | Character |
|---:|-----:|:---|
| 3000 Hz|  43° | Good localization  |
| 2000 Hz|  73° | Marginal |
| 1000 Hz| 116° | Poor |
|  500 Hz| 180° | Fully omni |

##### UMA-16 Usable Frequency Range
- for the UMA-16, the usable window is roughly 2–4 kHz
  * this is bounded below by aperture-limited directionality and above by spatial Nyquist aliasing
  * this happens to overlap well with speech consonants and many mechanical tones
     - this is why a 126 mm array is a practical choice for a desktop acoustic camera

---

### Phase 4: Custom Hardware -- 96-mic with FPGA on custom PCB

**WIP** — full details: [PHASE4](./PHASE4.md)

Custom 96-mic Underbrink spiral array (12 arms × 8 mics) with on-FPGA PDM→CIC/FIR
decimation. Two hardware architectures are being pursued in parallel:

- **Single-FPGA (primary, ALINX AC7200 module)** — one XC7A200T SOM runs all 96 channels'
  CIC/FIR in parallel plus a GbE/UDP host link, instead of splitting the work across 5
  FPGAs. RTL feasibility is confirmed on real placed/routed numbers (43.5% LUT utilization
  for the pipeline alone, 48.1% combined with the GbE MAC and packetizer). The physical
  design splits into two mating boards — `mic_array` (the 96-mic disc) and `front_end`
  (FPGA module, buck regulator, GbE PHY) — joined by board-to-board connectors; currently
  in active PCB layout, not yet fabricated.
- **Multi-FPGA alternate** — 4 cluster boards (Cmod A7-35T, 24 mics each) feed a hub board
  (Cmod A7-35T) over a shared-clock spoke bus; the hub relays the stream to a Raspberry Pi 5
  over USB. RTL (per-channel CIC/FIR, spoke framing, USB framing) is fully implemented,
  verified bit-exact against golden models, and synthesizes/places/routes clean on real
  hardware (`xc7a35tcpg236-1`). PCB layout for both board types is in progress.

A co-located video camera (Pi Camera Module 3 Wide) mounts through the mic array's centre.

### Phase 5: ML-based approach

This phase requires real data from Phase 3/4 to train and validate ML models.

---

## Acoustic Camera Products Overview

See [PRODUCTS.md](./PRODUCTS.md) for full details.

A number of existing commercial products were examined to get a sense of their specs, features, and costs.

| Vendor | Product | Mics | Aperture | Freq range | Interface | Notes |
|---|---|---|---|---|---|---|
| miniDSP | UMA-16 v2 | 16 (4×4 URA) | 42×42 mm | 8–48 kHz SR | USB | Phase 3 hardware; XMOS Xcore200 PDM→PCM |
| Convergence Instruments | ACAM-64 | 64 (32×32) | ~187×182 mm | 20 Hz–8 kHz | USB | $2,100; open protocol; 16 kHz audio |
| Sorama | CAM64 | 64 MEMS PDM | 160×160 mm | 1.2–15 kHz (FF) | PoE | Pyramid form factor with handle |
| Sorama | CAM1K | 1024 MEMS | 640×640 mm | 300 Hz–15 kHz (FF) | PoE | Integrated HD camera; 5.5 kg |
| gfai Tech | Mikado | 96 MEMS | hexagon | -- | -- | Also Ring32/48/72 and large wind-tunnel arrays |
| Head acoustics | Visor VMA V | 60 or 120 MEMS | 0.3 m or 1 m disk | -- | -- | Depth camera at center; paired/irregular spacing |
| mh Acoustics | Eigenmike em32/em64 | 32 or 64 | spherical | 20 Hz–20 kHz | USB/Dante | HOA reference platform; up to 7th-order Ambisonics |
| Brüel & Kjær | various | -- | spherical/wheel/grid | -- | -- | Research-grade; many geometries |
| Clockworks SP | A²B array | 8 | 100 mm ring | -- | A²B bus | Infineon IM68D130 PDM mics; twisted-pair daisy-chain |
| introlab | 16SoundsUSB | 8 or 16 | configurable | 8–96 kHz SR | USB | Open hardware; XMOS xCORE-200; electret or MEMS |

Key observations from the survey:
- **64-96 mics** is the commercial sweet spot for handheld far-field use (1-8 kHz, ~0.16-0.64 m aperture)
- **USB** dominates for portable/desktop use; **PoE** for fixed installations; **A²B/Dante** for multi-node
- **PDM MEMS mics** are standard; electret arrays appear only in large wind-tunnel configurations
- **Integrated video camera** is universal in commercial products and is always co-located at array center
- **Near-field acoustic holography** (25 Hz) requires much closer source distances and a separate processing path from far-field beamforming

---

## Beamforming Projects and Libraries

See [PROJECTS.md](./PROJECTS.md) for additional details.

A number of open-source beamforming projects and software packages were also studied to get an idea of what can practically be accomplished in such a project.

| Project | Scale | Interface | Notable technique |
|---|---|---|---|
| Ben Wang (2023) | 192-mic MEMS, 24 radial arms, exponential spacing | FPGA → GbE → GPU host | GPU-fused cross-correlation calibration; PyTorch gradient descent for mic positions + speed of sound |
| Sonicam / CMU ECE (2020) | 96-mic, 6× 4×4 MEMS panels | FPGA → Ethernet | TDK InvenSense mics; large-format panel array |
| Kickstarter handheld (2018) | 64-mic, 3 concentric rings | ARM Cortex-A53, Linux | Battery-powered; 7" touchscreen; 10–24 kHz; 100 fps acoustic |
| 1024-pixel sound camera (2016) | 32×32 MEMS (4× 8×8 tiles) | -- | Early large-format MEMS grid demo |

Key takeaways:
- **FPGA → GbE → GPU** is the established pattern for large arrays (96+ mics) -- offloads PDM decimation and keeps the host pipeline simple
- **Calibration via cross-correlation** (Ben Wang's approach) is practical at scale: GPU-fused FFT pairs + gradient descent converges in seconds and recovers both mic positions and speed of sound simultaneously
- **Concentric-ring and spiral geometries** appear in handheld products; rectangular grids appear in panel/tile designs
- **Standalone operation** (ARM + touchscreen + battery) is achievable at 64 mics; larger arrays require tethered compute

**acoular** is a Python open-source beamforming framework that includes a reference 64-mic demo.
I'm using this package in some of this project's experiments.
Matlab has a lot of support for beamforming, but I'm sticking with open-source software in this project,
so I haven't really looked at what it has to offer.

---

# References

## Beamforming Algorithms

**Delay-and-Sum (D&S)**
- de Santana, L. (n.d.). *Fundamentals of Acoustic Beamforming*. NATO AVT-287 Lecture Notes. ([docs/EN-AVT-287-04.pdf](docs/EN-AVT-287-04.pdf))

**MVDR (Minimum Variance Distortionless Response / Capon beamformer)**
- Capon, J. (1969). "High-resolution frequency-wavenumber spectrum analysis." *Proceedings of the IEEE*, 57(8), 1408–1418.

**CLEAN-SC**
- Sijtsma, P. (2007). "CLEAN Based on Spatial Source Coherence." *International Journal of Aeroacoustics*, 6(4), 357–374.

**MUSIC (Multiple Signal Classification)**
- Schmidt, R.O. (1986). "Multiple emitter location and signal parameter estimation." *IEEE Transactions on Antennas and Propagation*, 34(3), 276–280.

**DAMAS (Deconvolution Approach for Mapping of Acoustic Sources)**
- Brooks, T.F. & Humphreys, W.M. (2004). "A Deconvolution Approach for the Mapping of Acoustic Sources (DAMAS) Determined from Phased Microphone Arrays." AIAA Paper 2004-2954. ([docs/20080015889.pdf](docs/20080015889.pdf))

---

## Microphone Array Patterns

**Underbrink Multi-Arm Log-Spiral**
- Underbrink, J.R. (2000). *Aeroacoustic Phased Array*. US Patent 6,089,671.

**Dougherty Log-Spiral (equal arc-length spacing)**
- Dougherty, R.P. (2002). "A Spiral Phased Array." *Proc. 8th AIAA/CEAS Aeroacoustics Conference*, Paper 2002-2529.
- de Santana (n.d.) covers the equal-arc-length formulation. ([docs/EN-AVT-287-04.pdf](docs/EN-AVT-287-04.pdf))

**Arcondoulis Design and Calibration**
- Arcondoulis, E.J.G., Doolan, C.J., Zander, A.C. & Brooks, L.A. (2010). "Design and Calibration of a Small Aeroacoustic Beamformer." *Proc. ICA 2010*, Sydney, Australia. ([docs/p453.pdf](docs/p453.pdf))

**Optimal Planar Microphone Array Arrangements**
- Sarradj, E. (2015). "Optimal planar microphone array arrangements." *Proc. CFA/VISHNO 2016*. ([docs/000468.pdf](docs/000468.pdf))
- Sarradj, E. (2016). "A Generic Approach to Synthesize Optimal Array Microphone Arrangements." *Berlin Beamforming Conference (BeBeC) 2016*. ([docs/BeBeC-2016-S4.pdf](docs/BeBeC-2016-S4.pdf))

**Array Pattern Comparison**
- Prime, Z. & Doolan, C. (2013). "A comparison of popular beamforming arrays." *Proc. ACOUSTICS 2013*, Victor Harbor, Australia. ([docs/p5.pdf](docs/p5.pdf))

**MEMS Microphone Array Design**
- Poets, A., Schlieper, R., Preihs, S. & Peissig, J. (2020). "On the Design of a MEMS Microphone Array for a Mobile Beamforming Application." *DAGA 2020*. ([docs/000405.pdf](docs/000405.pdf))

**General Tutorial**
- McCowan, I. (2001). *Microphone Arrays: A Tutorial*. ([docs/microphone_array.pdf](docs/microphone_array.pdf))

---

## Commercial Acoustic Camera Products

| Product | Manufacturer | Link |
|---|---|---|
| ReSpeaker XVF3800 | Seeed Studio | https://www.seeedstudio.com/ReSpeaker-XVF3800-USB-Mic-Array-p-6488.html |
| UMA-16 v2 | miniDSP | https://www.minidsp.com/products/usb-audio-interface/uma-16-microphone-array |
| ACAM-64 | Convergence Instruments | https://www.convergenceinstruments.com |
| CAM64 / CAM1K | Sorama | https://sorama.eu |
| Mikado | gfai Tech | https://www.gfaitech.com |
| Eigenmike em32/em64 | mh Acoustics | https://mhacoustics.com |
| Various arrays | Brüel & Kjær | https://www.bksv.com |
| A²B mic array | Clockworks Signal Processing | https://www.clockworkssignalprocessing.com |
| 16SoundsUSB | introlab | https://github.com/introlab/16SoundsUSB |

---

## Open-Source Projects and Libraries

**Acoular — Python microphone array beamforming framework**
- Sarradj, E. & Herold, G. (2017). "A Python framework for microphone array data processing." *Applied Acoustics*, 116, 50–58.
- GitHub: https://github.com/acoular/acoular — Website: https://acoular.org
- Workshop: Sarradj, E. et al. *Acoular Workshop: Accessible and Reproducible Microphone Array Signal Processing with Python*. ([docs/373.pdf](docs/373.pdf))

**AcouPipe — ML training dataset generation for mic arrays**
- GitHub: https://github.com/acoular/acoupipe

**Ben Wang (2023) — 192-mic FPGA-based array with GPU calibration**
- Wang, B. (2023). "Research on multi-sound source localization performance based on leaf-shaped microphone array." *J. Phys.: Conf. Ser.*, 2479, 012026. ([docs/Wang_2023_J._Phys.__Conf._Ser._2479_012026.pdf](docs/Wang_2023_J._Phys.__Conf._Ser._2479_012026.pdf))

**introlab 16SoundsUSB — open-hardware 16-mic USB audio interface**
- GitHub: https://github.com/introlab/16SoundsUSB

---

## Docs -- to be sorted and annotated

* 000405.pdf: On the Design of a MEMS Microphone Array for a Mobile Beamforming Application
  - built a mic array for the back of a smartphone
  - simulated different mic array configurations
  - used a genetic algorithm to optimize the placement of mics on a spiral
  - used XMOS dev board and 16x mics
    * Infineon’s IM69D130 digital MEMS mic
* 000468.pdf: Optimal planar microphone array arrangements [2015]
  - simulated lots of array arrangements for Vogel's Spiral with different H and V values
  - showed Underbrink Spiral is best trade-off between beam width and side-lobe levels
* 0080015889.pdf
  - ?
* 20080015889.pdf: A Deconvolution Approach for the Mapping of Acoustic Sources (DAMAS) Determined from Phased Microphone Arrays [2004]
  - ?
* 2021_12_De+Lucia.pdf: Implementation of a low-cost acoustic camera using arrays of MEMS microphones [2020]
  - ?
* 254.pdf: Comparison of Different Beamforming-based Approaches for Sound Source Separation of Multiple Heavy Equipment at Construction Job Sites
  - ?
* 373.pdf: Acoular Workshop: Accessible and Reproducible Microphone Array Signal Processing with Python
  - history and overview of Acoular
* BeBeC-2016-S4.pdf: A Generic Approach to Synthesize Optimal Array Microphone Arrangements [2016]
  - same material as 000468.pdf
* BeBeC-2022-D06.pdf
  - ?
* BeBeC-2022-S07.pdf
  - ?
* bp2144.pdf
  - ?
* Chakravarthula_Seeing_With_Sound_Long-range_Acoustic_Beamforming_for_Multimodal_Scene_Understanding_CVPR_2023_paper.pdf [2023]
  - ?
* EN-AVT-287-04.pdf: Fundamentals of Acoustic Beamforming [?]
  - ?
* GB2438259A.pdf: Audio recording system utilising a logarithmic spiral array [2006]
  - UK Patent application
  - ?
* IN-Pflug-Krischker-AspectsOfTheUseOfMemsMicrophones-2017.pdf: Aspects of the Use of MEMS Microphones in Phased Array Systems [2017]
  - compared MEMS mics to electrec capsule mics in 2015 and again in 2017
    * while MEMS got better in 2017, they still were worse than electret mics
  - MEMS mic EIN levels were worse than analog electrec in 2017, but cheaper per channel
    * can use more mics and effectively reduce the noise
  - also MEMS mic freq response was not as good in 2017
    * can do digital equalization filters to improve this for MEMS mics
* 'Lecture 4 - Microphone Arrays.pdf'
* mccormack2017parametric.pdf: Parametric Acoustic Camera for Real-Time Sound Capture, Analysis and Tracking [2017]
  - ?
* microphone_array.pdf: Microphone Arrays : A Tutorial [2001]
  - ?
* Mon-1-2-5.pdf
* noise-and-vibration-image-brochure-2024-gfaitech.pdf
  - ?
* p453.pdf: Design and Calibration of a Small Aeroacoustic Beamformer [2010]
  - ?
* p5.pdf: A comparison of popular beamforming arrays [2013]
  - ?
* s13272-019-00383-4.pdf
  - ?
* 'Schumacher - 2022 - Evaluation of microphone array methods for aircraf.pdf'
  - ?
* Sound_Localization_and_Speech_Enhancement_Algorith.pdf
  - ?
* time-domain-beamforming-3d-micarray-doebler-heilmann-meyer-2008-bebec.pdf
  - ?
* TP-2007-345.pdf
  - ?
* Wang_2023_J._Phys. Conf._Ser._2479_012026.pdf: 
Research on multi-sound source localization performance
based on leaf-shaped microphone array [2022]
  - ?
---

## Notes

* Outstanding Questions
  - what camera/optics are needed to match the mic array's FOV and resolution?
  - how should I partition the functionality between the front-end (FPGA) and backend (embedded processor)
  - what FPGA should I use
  - what processing and display to use

* TODOs
  - match camera and mic array resolution
  - figure out packaging
  - careful layout of audio front-end to ensure low noise
  - look at creating add-on arms to increase the aperture to improve resolution at low frequencies

* Advantages of low SNR mic in beamforming applications
  - https://audioxpress.com/article/microphone-array-beamforming-with-optical-mems-microphones
  - a better SNR mic can do better than multiple lesser SNR mics
  - lower SNR mic means more compact array is possible
    * 42mm mic spacing for a BW of  4KHz requires 17dB gain @ 100Hz -> min mic SNR = 65dBA
    * 21mm mic spacing for a BW of  8KHz requires 22dB gain @ 100Hz -> min mic SNR = 70dBA
    *  7mm mic spacing for a BW of 24KHz requires 32dB gain @ 100Hz -> min mic SNR = 80dBA

* I2S PCM MEMS mics comparisons
  - I have, and tested
    * INMP441 (441 NEO447)
    * MSM261S4030H0 (Xiao Sense?)
  - Amazon
    * SPH0645LM4H-B (Knowles?)
    * MSM261S4030H0
  - others
    * InvenSense ICS-52000 -- not I2S, TDM
    * InvenSense ICS-43434
    * InvenSense ICS-43432

* reSpeaker
  - ST MP34DT01TR-M
    * 4x PDM Omni MEMS mics
    * 90mm diameter, 33mm inter-mic spacing
    * SNR: 61 dB
    * Sensitivity: -26 dBFS
    * Overload: 120 dBSPL
    * Max sample-rate: 16 kHz (limited by onboard XMOS firmware, not the mic hardware)
  - micro USB interface, USB 2.0 (UAC1.0)
  - Linux/macOS driverless; Windows requires driver

* UMA-16
  - ?

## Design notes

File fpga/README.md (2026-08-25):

# fpga/

This directory contains the Verilog for the acoustic camera's FPGA front-end.
There are currently two independent implementations of the same 96-mic array
(see `DESIGN.md`'s "FPGA Choice" section for the full tradeoff writeup and
`PHASE4.md` for the current phase's hardware decisions):

## Multiple FPGA (`multi_fpga/`) — primary design

5 small Xilinx 7-series FPGAs: 4 "cluster" FPGAs (Cmod A7-35T, one per 3-arm/24-mic
quadrant) + 1 "hub" FPGA (also Cmod A7-35T) that aggregates all 4 spokes and bridges to a
Raspberry Pi 5 over USB. Fully implemented and simulated bit-exact; synthesizes, places, and
routes clean on real hardware targets (cluster: 71% LUT; hub: 9.8% LUT / 18.4% register,
both with timing margin). Breadboard bring-up (hub + one cluster + one mic) is in progress —
reset/LED handshake and the audio path confirmed on real hardware, USB streaming to a host is
next. See `multi_fpga/README.md` for the full breakdown.

## Single FPGA (`single_fpga/`) — alternate design being explored

One larger FPGA (Xilinx Artix-7 XC7A200T, on an ALINX AC7200 module) handling all 96
channels directly and bridging to the host over Gigabit Ethernet/UDP instead of USB.
There is no inter-chip spoke bus, so no cross-board sample-alignment problem to solve.
This has been evaluated at roughly $240/unit cheaper in BOM cost than the multi-FPGA
design, but not the currently-chosen design; it's being kept and developed as a real,
working alternate, staged in three parts:

- **Stage 1** (96-channel CIC+FIR pipeline alone, `rtl/single_fpga_top_spike.v`): real placed
  result **43.52% Slice LUTs** on `xc7a200tfbg484-1`
- **Stage 2** (+ UDP packetizer + vendored open-source 1G RGMII MAC, `rtl/gbe_packetizer.v` + `rtl/third_party/verilog-ethernet/`): real placed result
  **48.14% Slice LUTs**, 12.97% DSP48E1, 20.70% Bonded IOB, control sets a clean 1.54% (down
  from 27.59%/"required reduction" before a payload-memory redesign; see
  `rtl/gbe_packetizer.v`'s header comment for what changed and why). Protocol documented in
  `GBE_FRAMING.md`; golden model + two bit-exact testbenches in `golden/`/`sim/`
  (`sim-gbe-packetizer`, `sim-gbe-pipeline`).
- **Stage 3** (carrier-board PCB for the AC7200 module) has not been started — see
  `pcb/single_fpga/`.

The MAC is `alexforencich/verilog-ethernet` (MIT license), vendored unmodified — see
`rtl/third_party/verilog-ethernet/README.md` for provenance and why it was chosen over
Xilinx's own Tri-Mode Ethernet MAC IP (blocked by a license entitlement this project doesn't
have) and other open-source alternatives.

## Running the simulations

Both trees' testbenches run from the repo root:

    make sim-all       # every RTL testbench, both trees
    make golden-test   # just the Python golden-model unit tests
    make clean-sim     # remove xsim build artifacts

See the top-level `Makefile` for the full per-module target list (`sim-cic`, `sim-hub-top`,
`sim-gbe-pipeline`, etc.) and each tree's own `README.md`/protocol docs (`multi_fpga/
SPOKE_FRAMING.md`, `multi_fpga/USB_FRAMING.md`, `single_fpga/GBE_FRAMING.md`) for
implementation detail.

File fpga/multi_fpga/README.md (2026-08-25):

# fpga/multi_fpga/

Verilog for the multi-FPGA acoustic camera design (`pcb/multi_fpga/`). Currently covers only
the **cluster FPGA** (Digilent Cmod A7-35T, Xilinx Artix-7 XC7A35T -- moved from the
originally-planned Cmod S7/XC7S25, which couldn't fit this design; see
`fpga/multi_fpga/cluster/xdc/cluster_top.xdc`'s header comment) that sits on each of the 4 arm boards --
PDM capture from 24 local mics, CIC decimation, FIR compensation, framing onto the spoke
bus back to the hub board, and an on-board RGB LED health indicator (`clk_reset.v`,
YELLOW while resetting / GREEN once running -- same convention as the hub's own LED).

`fpga/multi_fpga/cluster/xdc/cluster_top.xdc` has real pin constraints and the design synthesizes,
places, and routes cleanly (71% LUT utilization, timing closes with margin). Breadboard
bring-up (hub + one cluster + one mic) is in progress: reset/LED handshake and the audio path
have been confirmed on real hardware; USB streaming to a host is next (see
`fpga/multi_fpga/host/usb_stream_test.py`).

The **hub FPGA** (also a Cmod A7-35T) covers power-up reset sequencing (`reset_seq.v`),
`SPOKE_CLK` generation, per-spoke deframing (`spoke_deframer.v` x4, one per spoke), and USB
FIFO framing to the Pi 5 (`usb_framer.v`) over the FT232H bridge's (an FTDI UM232H module)
synchronous 245 FIFO interface -- all wired together in `hub_top.v`. Bit-exact in simulation
(`make sim-hub-top`) and synthesizes, places, and routes cleanly (9.8% LUT / 18.4% register
utilization, timing closes with margin, `report_methodology` clean). Cross-spoke
sample-alignment/cable-skew calibration is the one remaining piece of scope, still not
attempted anywhere in this project.

See `PHASE4.md` and `pcb/multi_fpga/SCHEMATIC_NOTES.md` for the full system architecture this
implements a piece of, `fpga/multi_fpga/SPOKE_FRAMING.md` for the spoke-bus protocol both sides
implement, and `fpga/multi_fpga/USB_FRAMING.md` for the hub-to-Pi5 USB protocol.

```
cluster/
  rtl/      Verilog modules (see cluster_top.v for the top-level port list)
  sim/      Testbenches, one per module + one end-to-end integration tb
  golden/   Python reference models (numpy/scipy) — the source of truth testbenches check against
  vectors/  Checked-in .mem stimulus/expected-output fixtures generated by golden/, reused by
            hub/sim/'s testbenches too (spoke_deframer.v is spoke_framer.v's inverse)
hub/
  rtl/      Verilog modules (see hub_top.v for the top-level port list)
  sim/      Testbenches, one per module + one end-to-end integration tb
  golden/   Python reference models for protocols not derived from fpga/multi_fpga/cluster/ (currently
            just usb_framer_golden.py -- spoke_deframer.v reuses cluster/golden/ instead,
            see above)
  vectors/  Checked-in .mem fixtures generated by hub/golden/ (currently just usb_framer's)
vivado/cluster/, vivado/hub/   Vivado batch-mode run scratch (journals/logs from ad-hoc
                                synth/place/route runs) — no checked-in build script yet
host/
  usb_stream_test.py   Breadboard bring-up diagnostic: reads the hub's USB stream over a
                       UM232H (pyftdi, synchronous 245 FIFO mode), checks sync-lock/seq_num
                       drops/throughput, optionally dumps selected channels to WAV. See its
                       own docstring for setup/usage. Not the production Pi 5 reader.
```

Run `make sim-all` from the repo root (requires Vivado's `xsim`; see `Makefile`).

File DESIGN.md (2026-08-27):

# Acoustic Camera Design Target

## Table of Contents

* Hardware
  - Microphone Array
  - FPGA Front-End
    * FPGA Responsibilities (hard real-time, parallel)
    * FPGA Choice
      - Primary: Single-FPGA (ALINX AC7200 Module)
      - Alternate: Multi-FPGA (Clustered)
      - Alternate: Lattice ECP5-45F
      - Considered and rejected: Zynq-7020
  - Supporting ICs
  - Touchscreen Display
  - Power Supply
* Host Configurations
  - Config A — Standalone (Raspberry Pi 5, 8 GB)
  - Config B — Tethered, GbE-attached Host with GPU
  - Interface: USB to Pi 5, GbE relay for Config B
* Video
* Software
* Device Functions
  - Core Functions
  - Extended Functions
* Interface Design
  - Phase 2: Host-tethered (USB)
  - Phase 3: Standalone (Pi 5, 5" touchscreen, battery-powered)
  - Phase 4: Standalone Field Use (Pi 5, 7" touchscreen, battery-powered)
  - Phase 5: **TBD**

---

## Hardware

### Microphone Array

* **96× Infineon IM72D128** PDM MEMS mics
  - 72 dB(A) SNR, 128 dBSPL AOP, IP57 ingress protection
  - Factory-calibrated: ±1 dB sensitivity match, ±2° phase match
  - Part: IM72D128V01XTMA1 (DigiKey / Mouser)
* **Underbrink multi-arm log-spiral** pattern
  - 12 arms × 8 mics (6 × 16 alternative simulated in Phase 1; 12 × 8 chosen)
* **~300 mm diameter aperture; ~13 mm minimum mic spacing**
  - Spatial Nyquist ~13 kHz — no aliasing within 8 kHz operating range
  - Far-field distance: 0.52 m @ 1 kHz · 1.6 m @ 3 kHz · 4.2 m @ 8 kHz
* **Custom PCB(s)**
  - Primary design: two mating boards, `mic_array` (96-mic disc, 48 DATA + 1 CLK to the
    board-to-board connector) and `front_end` (ALINX AC7200 module, buck regulator, GbE PHY)
  - Alternate Multi-FPGA design: 4 quadrant boards (3 arms/24 mics each), paired L/R on data
    lines → 12 DATA + 1 CLK per board, to that quadrant's cluster FPGA

### FPGA Front-End

#### FPGA responsibilities (hard real-time, parallel)

One FPGA (the AC7200 module) does the entire pipeline end-to-end in the primary design (full
detail in [`PHASE4.md`](./PHASE4.md#fpga-responsibilities-hard-real-time-parallel)): PDM clock
generation, 48-line PDM capture + L/R demux, CIC decimation + FIR compensation (96ch, fully
parallel), sample alignment, and direct GbE/UDP packetization (5 frames × 96ch + sequence
number + timestamp → RGMII → PHY).

The alternate Multi-FPGA design splits the same responsibilities across cluster and hub tiers
instead:

| Block | Cluster (×4) | Hub (×1) |
|---|---|---|
| PDM clock | fan-out to 24 local mics | generate from 12.288 MHz TCXO; forward to all 4 clusters |
| PDM capture / L/R demux | 12 local data lines | — |
| CIC decimation + FIR compensation | per-channel, 24ch | — |
| Framing | onto spoke bus, 24ch | reassemble 4×24ch = 96ch; USB FIFO out to Pi 5 |
| Sample alignment | — | all 96 channels locked to one 48 kHz word-select boundary |
| PPS input (optional) | — | 1 Hz GPIO for absolute time-tagging; enables multi-unit sync |

#### FPGA Choice

##### Primary: Single-FPGA (ALINX AC7200 Module)

One Xilinx XC7A200T does the entire 96-channel CIC + FIR pipeline plus direct GbE/UDP
packetization, carried on a real, currently-sold **ALINX AC7200** System-on-Module (FPGA +
1GB DDR3 + QSPI flash + clocks + full power delivery, fully assembled — ~$299) rather than a
from-scratch bare-chip board. This avoids the XC7A200T's two structural costs (484-pin BGA
needing a dev board at prototype stage and BGA rework at custom-PCB stage; 48 PDM lines
needing to route the full ~300mm array span on one monolithic PCB) the same way the alternate
design avoids them — by using a pre-assembled module — without needing to split the pipeline
across 5 chips: no BGA soldering or rework at any build stage, and the module's own 4× 80-pin
board-to-board connectors (195 usable GPIO) comfortably cover the 48 PDM lines + GbE + JTAG
this design needs.

Physically two mating boards: `mic_array` (96-mic disc: mics, PDM clock fan-out, local power)
and `front_end` (AC7200 module, buck pre-regulator, GbE PHY), sharing one project-local KiCad
library (`pcb/libraries/`).

| Device | LUTs | DSP | BRAM | 96-ch headroom | 128-ch headroom | Notes |
|---|---|---|---|---|---|---|
| XC7A35T | 20,800 | 90 | 1.8 Mb | No | No | Too small |
| ECP5-25F | 25,500 | 56 | 1.67 Mb | No | No | Too small |
| ECP5-45F | 44,500 | 90 | 1.93 Mb | Tight (5%) | No | Open toolchain only |
| XC7A100T | 63,400 | 240 | 4.86 Mb | 35% | 16% | Considered; headroom tight for expansion |
| **XC7A200T** | **134,600** | **740** | **13.1 Mb** | **~75%** | **~60%** | **Chosen** |

XC7A200T chosen over XC7A100T: ~75% LUT headroom vs 35% (comfortable margin for future
additions), ~60% vs 16% at a 128-channel upgrade, 740 DSP48E1 blocks (all FIR chains in
dedicated DSPs, zero LUT MAC cost), same Artix-7 Vivado/ILA-VIO flow. Real placed/routed RTL
results on `xc7a200tfbg484-1`: 43.52% LUT for the pipeline alone, 48.14% combined with the
GbE MAC + UDP packetizer (`alexforencich/verilog-ethernet`, open-source, used instead of
Xilinx's TEMAC IP core, which needs a separate license Xilinx doesn't bundle by default).

Full reasoning, real RTL numbers, and rejected alternatives are in
[`PHASE4.md`](./PHASE4.md#fpga--single-fpga-alinx-ac7200-module).

##### Alternate: Multi-FPGA (Clustered)

Splits the front end across 4 small "cluster" FPGAs — one per 90° quadrant of 3 arms / 24
mics each, doing local PDM capture + CIC/FIR — plus 1 hub FPGA that aggregates their output
over a parallel single-ended bus (not true LVDS — the Cmod A7-35T's exposed I/O has no
differential-capable pins). Both tiers use the same part, Xilinx Artix-7 XC7A35T: the cluster
tier originally targeted a smaller Spartan-7 XC7S25, but that part couldn't fit the CIC/FIR
pipeline even after sharing optimizations (see `fpga/multi_fpga/cluster/rtl/cluster_top.v`'s header
comment), so it moved to the same XC7A35T the hub already used — landing on one part number
for all 5 modules instead of two. The hub never speaks Ethernet: it bridges the aggregated
stream over USB (FTDI FT232H sync FIFO) to a co-located Raspberry Pi 5, which either runs
beamforming locally (standalone) or relays the stream out its own on-board GbE port to an
external host (tethered) — no RGMII PHY chip or GbE MAC anywhere in this design. Both FPGA
tiers are far smaller than the primary single-chip design (the hub uses under 10% of its LUTs,
the cluster ~71% — see `fpga/README.md` for current synthesis numbers), all on
hand-assembly-friendly Digilent Cmod A7-35T modules, no BGA rework needed even at prototype
stage.

Kept as a proven, already-working alternate — fully implemented, synthesizes/places/routes
clean on real hardware. Splitting the front end into several independently buildable,
testable, replaceable tiles was the original motivation before the AC7200 module made the
single-chip path practical without paying its BGA/routing costs.

Full reasoning, LUT/pin/bandwidth budgets, and rejected alternatives (finer/coarser
grouping, daisy-chain topology, Lattice iCE40 tiles, hub-direct GbE) are in
[`PHASE4.md`](./PHASE4.md#fpga--alternate-multi-fpga-clustered).

##### Alternate: Lattice ECP5-45F

Applies to the primary single-FPGA design above (not the alternate Multi-FPGA design, whose
cluster tiles never touch GbE). Use only if a fully open-source toolchain (Yosys + nextpnr,
no Vivado) is a hard requirement. Fits 96 channels with ~5% LUT margin; does **not** fit 128
channels. GbE SerDes integration on the ECP5 open tools is harder (~4–6 weeks extra).
Suitable for a rev-2 board.

##### Considered and rejected: Zynq-7020

The XC7Z020 combines 85,000 LUTs of FPGA fabric with a dual-core ARM Cortex-A9 processor on
the same die. Potentially interesting for Config A (standalone) because the ARM could replace
the Pi 5. Rejected for the first board because:
- Cortex-A9 @ 1 GHz is 4–5× slower than Pi 5's Cortex-A76 @ 2.4 GHz for NumPy/BLAS;
  96-ch D&S at 3°/pt would run at ~5–10 fps rather than ~15–20 fps
- 85,000 LUT fabric gives only ~50% headroom for 96-ch; tighter than the primary design's
  XC7A200T
- Added complexity of PS+PL integration (Vitis toolchain in addition to Vivado)
- Pi 5 + either FPGA front-end gives better standalone performance at comparable cost
- Worth revisiting if a future rev integrates everything into one board

### Supporting ICs

* **GbE PHY**: needed only by the primary single-FPGA design — chosen: Microchip KSZ9031RNX
  (48-QFN, no BGA, ~$4–6, RGMII ↔ FPGA MAC); Marvell 88E1111 considered and rejected (117-ball
  BGA, real sourcing difficulty at low volume). The alternate design's hub has no GbE MAC/PHY
  at all
* **Master clock**: 12.288 MHz TCXO (temperature-compensated oscillator)
  - ÷ 4 = 3.072 MHz PDM clock (exact)
  - × 4 via PLL = 49.152 MHz FPGA master; ÷ 1024 = 48.000 kHz word select (exact)
  - TCXO required (not plain crystal) — sample-rate drift accumulates in the CSM over long captures

### Touchscreen Display

**TBD**

### Power Supply

External 5V/4A+ supply → Raspberry Pi 5's USB-C input. The Pi 5's own +5V
rail is tapped to power the hub board directly and each of the 4 arm
boards over a dedicated 2-pin connector (separate from the spoke data
bus — see `pcb/multi_fpga/SCHEMATIC_NOTES.md`'s "Power architecture" for
why). Each arm board has its own local +1.8V LDO for its 24 mics
(independent per board, not shared); the hub has its own +3.3V LDO for
the FT232H USB bridge and TCXO. Full rail-by-rail detail, part numbers,
and confidence flags: `pcb/multi_fpga/SCHEMATIC_NOTES.md`.

---

## Host Configurations

In the primary single-FPGA design, the front-end drives GbE/UDP directly to whichever host is
present — no relay required. Two operating modes share the same hardware. (The alternate
Multi-FPGA design instead talks USB to a co-located Raspberry Pi 5, which is present in every
deployment and, in tethered mode, relays the stream onward over its own GbE port.)

### Config A — Standalone (Raspberry Pi 5, 8 GB)

Self-contained field unit. Pi mounts in the camera housing alongside the front-end board;
receives the front-end's UDP stream directly over its native GbE port.

* **Compute**: NumPy + OpenBLAS (no GPU)
  - 3°/pt grid for live display: D&S ~20 ms (~20 fps), MVDR/MUSIC ~50 ms (~10 fps)
  - 0.5°/pt used for offline post-processing of recordings
* **Camera**: Pi Camera Module 3 Wide (IMX708, 120° FoV) via MIPI CSI
* **Upgrade path**: PCIe M.2 slot → Hailo-8 NPU (~$70) for Phase 5 ML beamforming
* **Display**: HDMI touchscreen or SSH + web UI for field use

### Config B — Tethered, GbE-attached Host with GPU

High-performance workstation connected directly to the front-end via GbE — no Pi 5 relay
needed; the Pi 5 is not present in this configuration at all. Full-resolution real-time
beamforming.

* **Compute**: CuPy on CUDA GPU
  - 0.5°/pt grid: D&S ~10 ms, MVDR/MUSIC ~5 ms, all at 20+ fps
  - VRAM required: ~33 MB for steering matrix (complex128, 96 × 21,901) — any GPU fits
  - Minimum GPU: GTX 1070 (8 GB). Recommended: RTX 3060 (12 GB)
* **Camera**: USB 3.0 webcam via OpenCV `VideoCapture`

### Interface: direct GbE, no relay

Data rate: 96 ch × 48 kHz × 24 b = 110 Mbps — well within 1 GbE.

Frames carry: sequence number, timestamp, 5 frames × 96 channels PCM. Host ingestion:
background thread → thread-safe deque → sliding audio buffer — identical code path for
Config A or Config B, since both receive the same UDP stream directly off their own NIC.

> Alternate Multi-FPGA design: hub bridges USB to a co-located Pi 5 instead; in tethered mode
> the Pi 5 relays the same stream out its own GbE port to the GPU workstation — the Pi 5 is
> mandatory in every deployment of that design, unlike the primary design where it's optional
> in Config B.

## Video

* **Config A**: Pi Camera Module 3 Wide (IMX708) via MIPI CSI; accessed via `picamera2`
* **Config B**: USB 3.0 camera via OpenCV `VideoCapture`
* Co-located at array center; FoV matched to array aperture at expected working distance
* Real-time overlay of energy map on video stream

## Software

* Custom Python pipeline (no Acoular dependency for Phase 4)
  - Reuses beamforming functions from `src/acoustic_camera_p3.py`
  - Entry point: `src/acoustic_camera_p4.py`
* Backend selection via `--backend {numpy,cupy}`:

```python
if args.backend == 'cupy':
    import cupy as xp
    from cupy.linalg import inv, eigh
else:
    import numpy as xp
    from scipy.linalg import inv, eigh
```

All beamforming functions operate on `xp` arrays transparently. Grid resolution default:
`--grid_deg 3.0` for numpy (Pi 5), `--grid_deg 0.5` for cupy (GPU host).

* CLEAN-SC does not parallelize well across grid points; use Functional Beamforming
  (D&S power map raised to exponent ν) for real-time GPU display. CLEAN-SC for offline.
* Algorithm progression: D&S → MVDR → CLEAN-SC → Functional BF → ML (Phase 5)

## Device Functions

### Core Functions

Every commercial acoustic camera supports these:

* Real-time energy map: beamformed sound field rendered as a 2D heatmap image
* Video + acoustic overlay: live video with energy map overlaid (colormap on camera image)
* Selectable frequency range: bandpass filter to focus on frequencies of interest (octave or 1/3 octave bands)
* Dynamic range control: adjustable display floor and ceiling (analogous to brightness/contrast for the acoustic image)
* Field of view selection: selectable FoV (e.g., 90° or 60°); must match video camera optics
* Image persistence/temporal averaging: controls the time window over which energy is averaged
  - fast = tracks transients; slow = reveals weak stationary sources
  - range: 10 ms to 10 s
* Record/playback: capture synchronized audio, video, and energy map sequences; replay offline

### Extended Functions

Features that differentiate higher-end products; implement progressively:

* Algorithm selector: choose beamforming algorithm at runtime: D&S → MVDR → CLEAN-SC (and later ML-based)
* Frequency-resolved maps: display energy maps at multiple octave bands simultaneously (side-by-side or toggled)
* Source tracking: lock on and follow the loudest detected source across frames
* Near-field/far-field mode: toggle assumption about wave curvature; affects steering delay computation
* Depth/range estimation: estimate distance to source using a co-located depth camera (e.g., Intel RealSense); enables 3D source localization
* Calibration mode: guided workflow to measure and store mic-to-mic sensitivity, phase, and position corrections

## Interface Design

### Phase 2: Host-tethered (USB)

Follow the ACAM_64 (Convergence Instruments) model: USB audio streaming to host PC, open protocol, Python-based desktop GUI.

GUI elements:
* Live video window with energy map overlay (adjustable colormap, opacity)
* Frequency band selector (octave and 1/3 octave buttons or slider)
* Dynamic range sliders (floor/ceiling dB)
* Algorithm selector dropdown (D&S, MVDR, CLEAN-SC)
* Persistence/averaging time slider
* FOV selector (if multiple optics supported)
* Record/Stop button and session file naming
* Real-time SPL meter and peak-hold indicator
* Status bar: sample rate, latency, mic count, connection state

### Phase 3: Standalone (Pi 5, 5" touchscreen, battery-powered)

Same GUI elements as Phase 2/3, running on Pi 5. Display via HDMI touchscreen attached to
housing, or web UI served over WiFi for phone/tablet access.

Full-resolution energy maps at all algorithms. GUI runs on workstation display.
Additional elements:
* GbE packet ingestion status (sequence gaps, drop rate)
* Calibration workflow UI (guided mic position / sensitivity estimation)
* Offline playback and post-processing mode (load recorded audio, re-beamform at 0.5°/pt)

### Phase 4: Standalone Field Use (Pi 5, 7" touchscreen, battery-powered)

* Embedded web UI (served from Pi, accessed via phone or tablet over WiFi)
* Small integrated touchscreen (7" is the commercial standard: HEAD VMA V pattern)
* Physical record/stop button(s) on the housing
* Battery-powered operation with charge indicator

### Phase 5: TBD

**TBD**

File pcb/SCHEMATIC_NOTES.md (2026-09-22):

# Phase 4 Mic Array — Schematic Notes

Reflects the current `pcb/single_fpga/` design (single-FPGA is the primary
design track; `pcb/multi_fpga/` is kept as the proven alternate). The
project outgrew a single "Nexys Video + FMC" board and is now a **two-board
system**: the FPGA lives on its own board, the mic array is a second,
physically separate board, and the two connect with a single high-density
board-to-board connector.

---

## Architecture — Two Boards

| Board | KiCad project | Carries |
|---|---|---|
| **front_end** | `front_end.kicad_pcb` / `front_end.kicad_sch` | ALINX AC7200 FPGA SOM, +5V→+3V8 power regulation, inter-board connector |
| **mic_array** | `mic_array.kicad_pcb` / `mic_array.kicad_sch` | 96 mics, master clock (TCXO) + full clock distribution tree, local 3.3V regulation, inter-board connector |

`top.kicad_sch` is the hierarchical parent that ties "Front End" and
"Microphone Array" together as sub-sheets, for whole-project ERC/BOM
purposes — it is **not** a third physical board (`top.kicad_pcb` has no
routing of its own beyond what's mirrored from the two real boards).

This replaces the earlier plan of driving the mic array from an external
FPGA dev board (Nexys A7-200T / Nexys Video) over an FMC LPC connector.
There is no external dev board and no FMC connector in the current design —
the FPGA (Xilinx XC7A200T-2FBG484I) is the ALINX AC7200 SOM, mounted
directly on the front_end board.

### Hierarchical sheets

```
top.kicad_sch
├── mic_array.kicad_sch        ("Microphone Array")
│   ├── mic_arm_00.kicad_sch   … mic_arm_11.kicad_sch   (8 mics + 1 clock buffer each)
│   └── array_connector.kicad_sch   ("Array Inter-board Connector")
└── front_end.kicad_sch        ("Front End")
    ├── ac7200_conn1.kicad_sch … ac7200_conn4.kicad_sch (AC7200 SOM, one symbol split 4 ways)
    └── (sheet-local: power regulation, J2/J3)
```

`ac7200_conn1–4` each place one unit of the same multi-unit `single_fpga:AC7200`
schematic symbol (U109) — the AC7200's 4× 80-pin connectors (CON1–CON4),
split across 4 sheets for readability, not 4 separate parts.

---

## Reference Designators

| Range | Board | Parts |
|---|---|---|
| U1–U8, U10–U17, U19–U26, … (9 per arm) | mic_array | 8× IM72D128 mics + 1× CDCLVC1108 clock buffer, per arm (arm 0 = U1–U9, arm 1 = U10–U18, … arm 11 = U100–U108) |
| C1–C96 | mic_array | 100 nF decoupling, one per mic VDD pin |
| C97–C101 | mic_array | TCXO / CDCLVC1112 decoupling + bulk |
| R1 (one per arm sheet) | mic_array | 10 kΩ pull-up on each arm's CDCLVC1108 output-enable pin |
| R13 | mic_array | 10 kΩ pull-up on CDCLVC1112's output-enable pin |
| Y1 | mic_array | 12.288 MHz TCXO |
| U110 | mic_array | CDCLVC1112, stage-1 (1:12) PDM clock buffer |
| VR1, VR2 | mic_array | MCP1700T-3302E 3.3V LDOs — separate MIC_3V3 and CLK_3V3 rails |
| J1 | mic_array | Inter-board connector (Panasonic AXK6S80347YG header) |
| U109 | front_end | AC7200 FPGA SOM (Xilinx XC7A200T-2FBG484I), one symbol across CON1–CON4 |
| U111 | front_end | TLV62569DBV, +5V→+3V8 synchronous buck |
| L1 | front_end | 2.2 µH inductor for U111 |
| R14, R15 | front_end | 499 kΩ / 100 kΩ feedback divider setting U111's +3V8 output |
| C102–C104 | front_end | U111 input/output/bulk caps |
| J2 | front_end | Inter-board connector (AXK5S80347YG socket, mates J1) |
| J3 | front_end | +5V/GND power input |

Mic numbering (U references) is no longer a clean U1–U96 block — the
per-arm clock buffer is interleaved into the same reference sequence, so
each arm consumes 9 consecutive U numbers (8 mics + 1 buffer), not 8.

---

## FPGA: ALINX AC7200 SOM

Xilinx **XC7A200T-2FBG484I**, on ALINX's AC7200 module. Pinout and
mechanical placement are cross-checked against ALINX's real manual and
schematic (see [`pcb/libraries/AC7200/AC7200_README.md`](libraries/AC7200/AC7200_README.md)
— 320/320 connector pins verified, zero discrepancies). The module mounts
on the front_end board through 4× 80-pin, 0.5mm-pitch board-to-board
connectors (Panasonic AXK580137YG/AXK680337YG family, 3.0mm mated height).

This fully supersedes the old Nexys A7-200T / Nexys Video I/O-budget
discussion below (kept for historical context only — see
"Superseded: External Dev-Board Connector" at the bottom of this file).

---

## Power

```
+5V (J3, front_end) → TLV62569DBV buck (U111, L1, R14/R15 FB divider) → +3V8
   +3V8 → AC7200 SOM (U109, front_end)
   +3V8 → J2/J1 inter-board connector → mic_array board
             +3V8 → VR1 (MCP1700-3302E) → MIC_3V3   (mic analog supply)
             +3V8 → VR2 (MCP1700-3302E) → CLK_3V3   (TCXO + clock buffers)
```

MIC_3V3 and CLK_3V3 are deliberately separate LDO outputs from the same
+3V8 rail, isolating the mic analog supply from clock-buffer switching
noise. Only +3V8 and GND cross the inter-board connector — no +5V or
regulated 3.3V rail is shared directly between boards.

---

## Data Line Assignment

`test/phase4/data_line_assignment.csv` has the full table; unchanged in
concept from the original plan — 48 DATA lines, 2 mics per line:

| DATA line | Mic L (SEL=GND) | Mic R (SEL=MIC_3V3) | Pair distance |
|---|---|---|---|
| DATA_00 | mic 0, arm 0 | mic 1, arm 0 | ~19 mm |
| DATA_01 | mic 2, arm 0 | mic 3, arm 0 | ~19 mm |
| ... | ... | ... | ... |
| DATA_47 | mic 94, arm 11 | mic 95, arm 11 | ~19 mm |

Rule: within each pair, the mic with the lower index has SEL=GND (L), the
higher index has SEL=MIC_3V3 (R). Within each arm, pairs are (0,1), (2,3),
(4,5), (6,7). Data line index = arm × 4 + pair_within_arm. Confirmed
against the actual schematic wiring (MIC_3V3/GND tie counts per arm match
this pairing exactly).

---

## IM72D128 Pin Assignment — corrected from earlier draft

The pin order below is taken directly from the `multi_fpga:IM72D128`
symbol actually used in `mic_arm_00–11.kicad_sch` (the original draft had
pins 1/2 and 3/4 swapped):

| Pin | Name | Connect to |
|---|---|---|
| 1 | DATA | DATA_nn net |
| 2 | VDD | MIC_3V3 + 100 nF to GND |
| 3 | CLK | MIC_CLK_nn (buffered, one net per mic) |
| 4 | SEL | GND (L mic) or MIC_3V3 (R mic) |
| 5 | GND | GND plane |

---

## PDM Clock Distribution — two-stage buffer tree

The master clock is generated **on the mic_array board** and never
crosses the inter-board connector — a change from the original single
central-buffer plan, and it also drops the earlier ÷4 divider idea (the
TCXO's 12.288 MHz drives the buffer tree directly):

```
Y1  ECS-TXO-5032-122.8, 12.288 MHz TCXO, ±2.5 ppm  (mic_array, CLK_3V3)
 │
 ├─ Stage 1: U110 CDCLVC1112 (1:12 LVCMOS buffer)
 │     TCXO_CLK → ARM_00_CLK … ARM_11_CLK   (one output per arm)
 │
 └─ Stage 2: one CDCLVC1108 (1:8 LVCMOS buffer) per arm sheet
       (U9 in mic_arm_00, U18 in mic_arm_01, … U108 in mic_arm_11)
       ARM_nn_CLK → MIC_CLK_(8·nn) … MIC_CLK_(8·nn+7)
```

Each mic gets its own buffered clock net, globally numbered
`MIC_CLK_00`–`MIC_CLK_95` (index = arm × 8 + position-in-arm = mic_idx),
so there's no per-sheet net-name collision risk despite every arm sheet
being a copy of the same template. Both buffer ICs have their
output-enable pin pulled up locally (R13 for U110, one R1 per arm for
each CDCLVC1108) rather than driven from the FPGA.

**Matched-length traces** from each buffer stage to its loads are still
important above 1 MHz; keep CLK traces within ±5 mm of each other within
a given fan-out stage.

---

## Inter-board Connector

| Side | Board | Part |
|---|---|---|
| J1 | mic_array | Panasonic AXK6S80347YG (80-pin + 4 fixing pads, 0.5mm pitch, 7.0mm mated height, header) |
| J2 | front_end | Panasonic AXK5S80347YG (mating socket, same family) |

Carries all 48 DATA_nn nets plus +3V8 and GND. No clock signal crosses
this connector — see "PDM Clock Distribution" above.

---

## Layer Stack — implemented

`mic_array.kicad_pcb` is routed on the planned 4-layer stack:

```
F.Cu   (signal)  — mic pads, DATA traces, per-arm clock fan-out
In1.Cu (plane)   — solid reference plane
In2.Cu (plane)   — solid reference plane
B.Cu   (signal)  — longer DATA runs, connector fanout
```

---

## Board Outline

`mic_array.kicad_pcb`'s Edge.Cuts geometry measures **320 mm × 320 mm**
(circular, Ø320 mm) — matches the original plan and is now the as-routed
outline, not just a target.

`front_end.kicad_pcb` has no board outline yet — only its 10 footprints
(AC7200 SOM connectors, U111 buck regulator + support parts, J2, J3) are
placed; routing hasn't started.

---

## Status (as of the schematics/layouts on disk)

- **mic_array.kicad_pcb**: actively being routed (most recent PCB commits
  are all on this file — clock-driver grounding/pull-ups done, general
  routing in progress).
- **front_end.kicad_pcb**: components placed only; no outline, no routing
  yet.

---

## Superseded: External Dev-Board Connector (historical, no longer used)

The project originally planned to drive the mic array from an external
FPGA dev board rather than a custom FPGA carrier:

- Nexys A7-200T exposes only ~32 user I/O (4× Pmod) — 17 short of the 49
  needed for 96 mics (48 DATA + 1 CLK).
- Nexys Video (same XC7A200T, FMC LPC connector, 68 SE I/O) was the
  recommended fix, connecting via a Samtec/Molex FMC LPC plug.
- A 32-channel bring-up option using 3 Pmods on the Nexys A7-200T was also
  scoped.

None of this applies to the current design — the ALINX AC7200 SOM
provides the FPGA directly on the front_end board, and the array connects
to it via the AXK5S/6S80347YG board-to-board connector described above.

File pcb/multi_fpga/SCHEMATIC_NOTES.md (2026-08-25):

# Phase 4 Multi-FPGA (Clustered) Alternative — Schematic Notes

Companion to [`PHASE4.md`](../../PHASE4.md#fpga--multi-fpga-clustered-alternative).
Generated by [`pcb/make_schematic_multi_fpga.py`](../make_schematic_multi_fpga.py).

Scope: **dev-board interconnect** — which physical header pin carries which
signal, using real FPGA pin names from the Digilent reference manuals. The
per-mic wiring itself is **not redrawn**: each cluster's 3 arm sub-sheets
(`arm_NN.kicad_sch`) are generated by the same `make_arm()` function used by
`pcb/mic_array/` (see that project's own `SCHEMATIC_NOTES.md` for the mic-level
conventions — pin assignment, decoupling, SEL/L-R convention — all unchanged
here), just called with a cluster-specific clock label and this project's page
numbers. `mic_array` and `multi_fpga` are deliberately separate KiCad projects
(mutually exclusive alternative front-ends) — only that one generator function
is shared, not the projects themselves.

Dev boards (Cmod A7-35T, one per cluster and one for the hub) are drawn as
simplified connector-block symbols exposing only the header pins actually
used, not Digilent's own internal board schematic.

> **Cluster FPGA note**: the cluster tier originally targeted a Digilent Cmod
> S7 (XC7S25) and this document (like `make_schematic_multi_fpga.py`) was
> written against that part throughout. Real HDL synthesis later showed the
> CIC/FIR pipeline didn't fit the XC7S25 (see `fpga/multi_fpga/cluster/rtl/cluster_top.v`'s
> header comment and `PHASE4.md`'s "Superseded by real synthesis" note), so
> the cluster tier moved to the same Cmod A7-35T the hub already used. This
> document has been updated to describe that target state throughout, and
> `make_schematic_multi_fpga.py`'s `make_cluster()` now instantiates the
> `CMOD_A7_35T` symbol accordingly -- but the checked-in `cluster_0N.kicad_sch`
> files themselves still reflect the old Cmod S7 generator output as of this
> writing, pending a regeneration pass (re-run the generator, then
> `kicad-cli sch erc`, per this project's usual workflow) that hasn't been
> done yet.

---

## Sheets

| File | Contents |
|---|---|
| `top.kicad_sch` | 4x cluster sub-sheet + 1x hub sub-sheet |
| `cluster_00..03.kicad_sch` | Cmod A7-35T (A1-A4) + spoke bus to hub + 3x arm sub-sheet |
| `arm_00..11.kicad_sch` | Per-mic wiring (8 mics each), reused from `pcb/mic_array/` |
| `hub.kicad_sch` | Cmod A7-35T (A5) + 4x spoke bus (all DIP, no Pmod) + TCXO (Y1) + USB bridge (A6) |

Page numbering: 1 = top, 2-5 = cluster_00-03, 6 = hub, 7-18 = arm_00-11 (in
cluster order: cluster N's arms are 3N, 3N+1, 3N+2, i.e. pages 7+3N..9+3N).

---

## Reference designators

| Ref | Sheet | Part |
|---|---|---|
| A1-A4 | cluster_00-03 | Digilent Cmod A7-35T (XC7A35T-1CPG236C), one per cluster |
| U1-U96, C1-C96 | arm_NN | IM72D128 mics + decoupling caps — same numbering as `pcb/mic_array/` |
| A5 | hub | Digilent Cmod A7-35T (XC7A35T-1CPG236C) |
| A6 | hub | FTDI FT232H USB-FIFO breakout (e.g. Adafruit #2264) |
| Y1 | hub | 12.288 MHz TCXO (NDK NZ2520SD or TXC 7M series, ±2.5 ppm) |

Dev-board/breakout modules use the "A" (assembly) prefix, not "U" — the "U"
range is reserved for the 96 mics (`U1`-`U96`). Originally these all used
"U1"/"U2" and collided both with mic `U1`/`U2` and with each other (all 4
clusters' Cmod said "U1"); fixed by moving them to their own prefix.

---

## Spoke bus: parallel single-ended, not LVDS

Both the cluster's and the hub's Cmod A7-35T run every exposed I/O pin
(Pmod and 48-pin DIP header alike) through a 200-240Ω series protection
resistor, capped at 25 MHz — there is no differential-capable pin anywhere on
either module. See PHASE4.md's "Spoke link" section for the full reasoning.
Each spoke is an 8-signal parallel bus:

| Signal | Cluster (Cmod A7-35T Pmod JA) | Hub | Direction |
|---|---|---|---|
| D0-D5 | 6 data bits | 6 data bits | cluster → hub |
| STROBE | byte/word strobe | — | cluster → hub |
| CLK | forwarded PDM clock | — | hub → cluster |

~4.6 MHz per wire (27.6 Mbps ÷ 6 bits) — ~5x margin under the Cmod A7-35T's
25 MHz cap (same cap on both the DIP and Pmod pins, both tiers).

Cmod A7-35T has one real Pmod (JA, 8 signals), but all 4 spokes land on the
hub's 48-pin DIP header instead (see PHASE4.md "Why all-DIP, no Pmod" for why
the hub's own Pmod goes unused). Alongside the FT232H bridge and TCXO clock
in, that's 45 DIP signals total. Hub-side pin assignment (`CMOD_A7_35T_DIP`, DIP pins in
physical order, 45 of the 46 usable — see below): spoke 0 D0-CLK (first 8),
spoke 1 D0-CLK (next 8), spoke 2 D0-CLK (next 8), spoke 3 D0-CLK (next 8),
then USB D0-D7/RXF#/TXE#/RD#/WR#, then TCXO clock in — exactly 45, no DIP
pins left spare. The 45th signal needed one more pin than the 44
confirmed-digital DIP pins provide; filled by DIP pin 16 (FPGA ball H2),
documented by Digilent as an XADC auxiliary analog input (`vaux12`) rather
than plain GPIO — unused-for-analog 7-series aux pins are ordinary fabric
I/O, and this design has no XADC use, but this specific pin hasn't been
confirmed against a plain-GPIO-mode example the way the other 44 have.

Real FPGA pin names for both ends come from Digilent's own reference
material, both now the same Cmod A7-35T module: Digilent's published
`CmodA7_Master.xdc` (`Cmod-A7-35T-GPIO` reference project, same as
`fpga/multi_fpga/demo/CmodA735tDemo/Src/CmodA735tDemo.xdc`, which the RTL side's own
`fpga/multi_fpga/cluster/xdc/cluster_top.xdc`/`fpga/multi_fpga/hub/xdc/hub_top.xdc` already source
pin names from) — a real constraint file, not reference-manual prose, for
both tiers now (originally the cluster side, still on Cmod S7 at the time,
was sourced from that part's RM §8 text table instead, less reliable than a
real XDC). Cross-check the generator's pin assignments against a synthesized
`.xdc` for *this* design specifically before committing to real hardware.

### Spoke connector (mechanical): board-to-board, no cable

The hub now mounts at the physical centre of the array (standoff- and
connector-mated to all 4 arm boards — see `pcb/layout_multi_fpga.py`'s
`place_hub()`), which changed how each spoke physically gets from a
cluster's Cmod A7-35T to the hub, compared to earlier revisions of this
document: **a plain 2.54mm 2x6 header (arm board) mates with a matching
2x6 socket (hub board)** — no cable anywhere. This connector is no longer
plugged directly into the cluster's own Pmod JA socket. Its position (and
the mechanical standoff's, and the Cmod module's own) are fixed constants
approximating manual KiCad edits the user made — see
`CLUSTER_HUB_CONNECTOR_*`/`CLUSTER_STANDOFF_*`/`CLUSTER_CMOD_PLACEMENT_*` in
`pcb/layout_multi_fpga.py` for exactly how those were recovered each time
(find the file's manual page-centring translation by comparing a mic's
actual position against its known `array_xy.csv` position, subtract it
back out). Current values: connector at r=48.3mm/25.6deg (offset from the
cluster's own 90c base, rotation 0deg), standoff at r=69.6mm/37.4deg, Cmod
module at r=91.5mm/43.8deg (rotation 0deg) — three different angles, not
radially in line the way an earlier revision of this design had them;
that's what the manual edits actually did, so that's what this
approximates. (These placement constants are chip-agnostic — the same
generic DIP-48 footprint is placed regardless of which Cmod A7 variant
occupies it, so the Cmod S7 -> Cmod A7-35T FPGA swap didn't itself change
any of these numbers, only the part silkscreened there.) Keeping the
connector and standoff close to centre is what lets the hub board be
smaller (`HUB_HALF_SIDE_MM` ~95mm half-side vs. 105mm radius with the
connectors originally co-located with the Cmod module — see "Hub board:
square outline..." below for the switch from a circular to a square hub).
The 8 Pmod signals reach this connector via a PCB trace from the Cmod's Pmod pins, not a
direct plug-in; routing those traces is a later, not-yet-done pass (see
below).

Each board file is also individually recentred on its own A4 page
(`center_board_on_page()`) — purely cosmetic (doesn't affect fabrication),
matching the same manual edit.

### One arm board design, fabricated 4x (not 4 distinct board files)

**Update**: `arm_board.kicad_pcb` (referenced throughout this section) was
itself later removed; the project went back to `cluster_00.kicad_pcb` for a
while (4 hand-copied files), which then drifted apart, and has now settled
on the same "one PCB, fabricated 4x" model this section describes but with
**`cluster_00.kicad_pcb` as the golden file** instead of `arm_board.kicad_pcb`
-- `cluster_01/02/03.kicad_pcb` are removed again. The 4 physical copies are
now told apart by a `UNIT_ID` silkscreen text variable (see
`cluster_00.kicad_pro`'s `text_variables` and the `${UNIT_ID}`
`F.Silkscreen` text object on the board) resolved per-Gerber-export-run via
`pcb/export_cluster_gerbers.py` (`kicad-cli --define-var UNIT_ID=0..3`),
rather than by the physical-mounting-quadrant convention this section
originally described. The schematic-side correspondence table below and the
"no per-instance project pairing" reasoning still apply unchanged, just
substitute `cluster_00.kicad_pcb` for `arm_board.kicad_pcb` throughout.

`pcb/layout_multi_fpga.py` used to emit 4 separate files
(`cluster_00..03.kicad_pcb`), each built at its own rotated angle. The user
then hand-laid-out the arm board once (on `cluster_00`) and asked for that
single design to be reused for all 4 quadrants instead: **one
`arm_board.kicad_pcb`, fabricated 4x, physically mounted rotated
0/90/180/270deg around the hub** to form the full 96-mic array — not 4
distinct boards. This works because the whole array is exactly 4-fold
rotationally symmetric by construction (`arm_board` is built at c=0;
c=1..3's geometry is the *same* shape rotated 90c degrees, not an
independently-derived layout), so a physical copy of the c=0 board, bolted
into the c=1 slot rotated 90deg, lands exactly on the c=1 mic positions.

The **schematic side is unaffected** — `cluster_00..03.kicad_sch` still
model 4 electrically distinct clusters with different net names
(`DATA_00-11` vs `DATA_12-23`, `SPOKE0_*` vs `SPOKE1_*`, etc.); only the
PCB happens to reuse one physical footprint/outline layout 4 times. All 4
physical copies will carry the same silkscreen reference designators
(`U1`-`U24`, `A1`, `J1`, `H1A`, `H1E1`, `H1E2`) — normal for a repeated
identical module (each board is a standalone electrical + mechanical unit,
disambiguated by which quadrant it's mounted in, not by a project-wide
unique reference), not a naming bug.

The hub is still a genuinely single, non-repeated board, and its own file
still needs all 4 conceptual (rotated) positions internally — one real
physical connector/standoff per quadrant — even though only the c=0 angle
gets built out into the arm board file itself.

**Schematic correspondence for each fabricated copy**: `arm_board.kicad_pcb`
is electrically generic (its net names are board-local, not
quadrant-specific), so which schematic sheet a given physical copy
"belongs to" is purely a matter of which spoke/quadrant slot it's mounted
in on final assembly, not something baked into the PCB file:

| Physical copy (quadrant, rotation) | Schematic sheet |
|---|---|
| c=0, 0deg (as laid out) | `cluster_00.kicad_sch` |
| c=1, 90deg | `cluster_01.kicad_sch` |
| c=2, 180deg | `cluster_02.kicad_sch` |
| c=3, 270deg | `cluster_03.kicad_sch` |

There is intentionally no `cluster_00..03.kicad_pcb` per-instance PCB file
and no per-instance project pairing — `arm_board.kicad_pcb`/`.kicad_pro` is
the one master board file, reused as-is for all 4 assemblies. This table
is bookkeeping only, so an assembler/reader knows which schematic to
consult for a given physical board's expected netlist.

Because `arm_board.kicad_pcb` and `hub.kicad_pcb` each get their own
independent page-centring offset, their raw saved coordinates don't match
each other numerically (e.g. the arm board's standoff position vs. the
hub's corresponding one for that same quadrant) — that numeric-equality
convenience is gone, but physical alignment is still guaranteed the same
way it always was: both sides call the identical position formula (at
whichever of the 4 angles is relevant) before either file's own
page-centring shift is applied.

An earlier revision of this design tried to carry +5V/GND out to each
cluster board over this same Pmod connector (`SPOKE_VU`/`SPOKE_GND` at
Pmod positions 6/5). That turned out not to be physically possible:
Digilent's real Cmod A7 schematic (`datasheets/cmod_a7_sch_rev_c0.pdf`)
shows those positions are hard-wired on the module itself to
`GND`/`VCC3V3` — that module's own onboard regulator output, generated
locally from its own `VU` — not a spare power-input pin. Driving the hub's
+5V into it would fight the Cmod's own regulator. See "Power
architecture" below for how +5V actually reaches each cluster board now
(a separate dedicated connector).

This connector is the *physical entry point* for the 8 spoke signals onto
the hub board only — which of the hub's `CMOD_A7_35T_DIP` pins each one
ultimately reaches is still exactly what's defined in the spoke bus table
above; routing traces from the socket to those DIP pins (on both boards —
cluster board: its own Cmod A7-35T Pmod to connector; hub board: connector
to `CMOD_A7_35T_DIP` pins) is a later, not-yet-done pass (this project is
still placement-only, see `pcb/layout_multi_fpga.py`'s module docstring).

### FT232H breakout: USB-C revision swap (A6, hub only)

`A6` was updated from the original micro-USB Adafruit FT232H breakout
(2x7=14 approximate pads) to the current USB-C revision (Adafruit PID
2264, "unique 2264 board size/mounting-holes/pinout back-compatible"
per Adafruit — but the *pin layout itself* changed: the new board is
2x11=22 real pads, `3V,5V,GND,D0-D7` on one row and `GND,C9-C0` on the
other, vs. the old 2x10). New symbol pinout in `hub.kicad_sch`, new
footprint `multi_fpga:Adafruit_FT232H` (dimensions/pin pitch sourced
from Adafruit's own fabrication print, `cdn-learn.adafruit.com/downloads/
pdf/adafruit-ft232h-breakout.pdf` p.48 — read off a scanned diagram, so
treat as best-effort, confirm against a physical board before fab). Only
the 13 pins this design actually uses (`D0-D7`, and `C0-C3` as
`RXF#/TXE#/RD#/WR#` in FT245 sync FIFO mode, plus one `GND`) are wired;
the other 9 real pads (`3V` out, `5V` in, the 2nd `GND`, `C4-C9`) are
present in the footprint/symbol but intentionally left unconnected
(marked with `no_connect` flags in the schematic to keep ERC clean).

**Bug fixed in the same pass**: the old symbol had a 14th pin called
`VCCIO`, wired to the hub's `+3V3` rail. That doesn't correspond to any
real pin on either board revision — the FT232H breakout is entirely
self-powered over its own USB-C cable from the Raspberry Pi 5 (see "Host
interface" below), not powered from the hub. Removed that pin and its
`+3V3` branch on both the schematic and PCB sides.

Swapping the footprint required rotating `A6` 180° (still "horizontal",
just flipped top/bottom + mirrored left/right) rather than the naive 0°
placement, because the pre-existing routing's local stub ends (from
`A5`) land much closer to the new pad positions that way — this alone
cut the total local reconnection distance roughly in half.

**PCB routing status (as of this pass): 6 of 13 signals fully
reconnected and DRC-clean** (`USB_D2`, `USB_D3`, `USB_D4`, `USB_RXF_N`,
`USB_TXE_N`, `USB_WR_N`). The other 7 gaps are left as clean,
unambiguous single breaks — a real `A6` pad on one end, the existing
pre-routed stub (already reaching most of the way to `A5`) on the
other — **not yet manually completed**: `USB_D0`, `USB_D1`, `USB_D5`,
`USB_D6` (2 breaks: A6 side *and* a separate pre-existing gap near `A5`
pad 43 that surfaced during this work, unrelated to the footprint swap),
`USB_D7`, `USB_RD_N`. This is the same class of hyper-congested
short-hop routing this project has repeatedly needed manual (KiCad
interactive router) completion for elsewhere (see the arm board's
U20/U4 notes) — the blocker is genuine: `A5`'s existing escape routes
for several *other* signals (`USB_D1`'s own stub, `D4_full`/`D5_full`/
`D6_full`'s nearly-parallel diagonal bundle, `SPOKE3_D0`) already occupy
this same small area with only ~0.57mm gaps between adjacent traces —
right at the design rule minimum, too tight for a few more hand-routed
detours or vias (via clearance needs ~0.75mm+) to reliably fit without
tripping something else.

Two pre-existing minor DRC clearance warnings (not new, not electrical
shorts — both are real signal traces passing slightly too close to
*unused* pads on the new `A6` footprint, `pad 15`/`pad 17` = `C7`/`C5`):
`SPOKE1_STROBE` vs. `A6` pad 15, and part of `USB_D2`'s own pre-existing
route vs. `A6` pad 17. Left as-is rather than force a fix, same
reasoning as above.

### Hub board: square outline, axis-aligned modules, camera keepout

The hub board (`place_hub()`) was reworked from a circular outline with
`CMOD_A7_35T`/`Adafruit_FT232H`/`TCXO_Can` mounted tangentially at angled
positions, to a **square outline with all 3 modules mounted axis-aligned**
(rotation ∈ {0, 90, 180, 270}deg only — "horizontal and vertical", no
angled/tangential placement). `HUB_HALF_SIDE_MM` replaces the old
`HUB_RADIUS_MM`, computed the same way (from the actual furthest reach of
all hub content, plus a 10mm margin) but as a largest-axis-extent
(`max(|x|,|y|)`) rather than a Euclidean radius, since a square's sizing
constraint is per-axis, not radial.

New fixed placements (`HUB_CMOD_A7_XY_MM`/`_ROT_DEG`,
`HUB_FT232H_XY_MM`/`_ROT_DEG`, `HUB_TCXO_XY_MM`/`_ROT_DEG` in
`pcb/layout_multi_fpga.py`), found by treating the 4 spoke
sockets/standoffs (already axis-aligned themselves, since
`CLUSTER_HUB_CONNECTOR_ROT_DEG=0.0`) plus the centre keepout (below) as a
fixed obstacle field and fitting each module into a clear cardinal-axis
lane: `CMOD_A7_35T` horizontal straddling the +X axis (`(25, 7.62)`,
rot=90deg), `FT232H` vertical straddling the +Y axis (`(0, 48)`, rot=0deg),
`TCXO` vertical on the -Y axis (`(0, -30)`, rot=0deg). Verified
collision-free against the socket/standoff obstacle field (plain AABB
overlap, exact here since every obstacle involved is already axis-aligned)
and against each other.

A **35×35mm keepout** (`KEEPOUT_SIZE_MM`) centred on the hub reserves space
for the camera — drawn as a reference square on the `User.Comments` layer
(`add_keepout_square()`), not a physical `Edge.Cuts` cutout, so it's
visible in KiCad but doesn't change the board's fabricated shape. All 3
relocated modules are clear of it; only the camera's own hardware
(`HCAM1`/`HCAM2` mounting holes, the camera cutout itself) sits inside it,
which is expected.

The camera **cutout diameter** (`CAMERA_CUTOUT_DIA_MM`) was shrunk from
20mm to 12mm so it no longer overlaps `HCAM1`/`HCAM2` (at
±`CAMERA_MOUNT_HOLE_SPACING_MM`/2 = ±10.5mm, courtyard half-extent
~2.975mm) — 20mm diameter (10mm radius) left those mount holes' courtyards
overlapping the cutout edge; 12mm diameter (6mm radius) leaves a clean
~2mm annular gap (verified: closest `HCAM1`/`HCAM2` courtyard corner to
centre is 8.09mm).

**Signal integrity flag (not solved, carried forward for the HDL/routing
pass)**: a plain 2x6 Pmod-style header/socket gives only 1 shared GND pin
for all 8 signal lines. With 6 data lines + strobe potentially switching
together, that's simultaneous-switching noise on a single shared return
path — mediocre-but-usually-fine for a Pmod's typical control/slow-signal
use, but the one line here that's actually timing-critical is `CLK`: this
design needs phase-coherent sampling across all 4 clusters for
beamforming, so jitter injected onto `CLK` by ground bounce matters more
than it would for a generic control signal. Mitigating factors: the rigid
standoff-mounted stack keeps the electrical length short and fixed
(better than a variable-length cable would have been), and the spoke bus
carries each cluster's already-decimated 48kHz PCM output (a few Mbps
range per line), not raw multi-MHz PDM, so absolute switching speed is
modest. Net call: keep the plain header/socket (no reason for a fancier
connector when Cmod's Pmod is single-ended only regardless), but revisit
`CLK` once HDL exists — either give it its own adjacent ground pin if the
Pmod pinout allows, or add a small re-clocking/filter stage on the hub
side so link jitter doesn't propagate straight into the sample clock.

---

## Power architecture

Source: an external 5V/4A+ supply into the Raspberry Pi 5's USB-C port;
the Pi 5's own +5V rail is tapped to power the hub board and (via a
dedicated connector, below) each of the 4 arm boards. `+5V`/`GND` are
externally supplied throughout (`PWR_FLAG`-satisfied, no on-schematic
source — see "ERC: zero errors").

- **+5V distribution**: reaches the hub board directly (feeds `A5`/Cmod
  A7-35T's own `VU`). Reaching each arm board needs a connector separate
  from the spoke bus — see the spoke-connector section above for why that
  one can't carry it (its Pmod power pins are the Cmod's own onboard
  regulator output, not a usable input). Instead: a small dedicated 2-pin
  connector, `J2` (`PinHeader_1x02_P2.54mm_Vertical`) on the arm board,
  mating `J5`-`J8` (`PinSocket_1x02_P2.54mm_Vertical`, one per cluster) on
  the hub, mounted next to the existing spoke connector at each quadrant.
  Pin 1 = `+5V`, pin 2 = `GND`.
- **+1.8V (mic array)**: one LDO per arm board, `VR1` (MCP1700T-1802E/TT,
  SOT-23, 250mA — plenty for ~31mA/board at 24 mics × ~1.3mA typical per
  the datasheet), fed from that board's own `+5V` (via `J2`), output on
  `C{idx}_3V3` — a per-cluster-scoped net (via `make_arm()`'s `vdd_label`
  parameter in `pcb/make_schematic.py`), not the single-FPGA design's
  shared `+3V3` power symbol, since 4 independent LDOs can't share one
  global net. Bypass caps `C25`(in)/`C26`(out), 1uF ceramic per the
  datasheet's typical application circuit.
- **+3.3V (hub's FT232H + TCXO)**: one LDO on the hub, `VR5`
  (MCP1700T-3302E/TT, same family/package), fed from the hub's own `+5V`,
  output on `+3V3` (only ever exists on this one board, no per-cluster
  naming needed). Bypass caps `C1`(in)/`C2`(out).
- Both LDOs are simple linear regulators, not switching bucks — loads are
  tens of mA, heat is negligible, and this avoids inductor placement on
  boards that are already tight (especially the arm board).
- MCP1700's exact SOT-23 pin-to-function mapping (`LDO_PINS` in
  `pcb/make_schematic_multi_fpga.py`: pad1=GND, pad2=OUT, pad3=IN) and the
  mic/Cmod A7-35T current-draw estimates above are flagged to confirm against
  the datasheet before ordering hardware, same confidence level this file
  uses elsewhere (e.g. `CMOD_A7_35T_DIP` pin 16).

**Decoupling cap placement (mics)**: each mic's own cap (`C1`-`C24`) is
now placed as close as physically possible to that specific mic's VDD
(pin 2) and GND (pin 5) pads — not just "somewhere near the mic," which
the previous radial-offset scheme did (see `_mic_and_cap_xy()` in
`pcb/layout_multi_fpga.py`). Found by a directed search over cap
position/rotation minimising the worse of the two resulting stub lengths,
subject to staying >=0.2mm clear of the mic's DATA/CLOCK pads and its own
NPTH hole: cap pad "1" lands ~0.68mm from VDD, pad "2" ~0.28mm from GND.
This depends on the corrected mic pinout above — the old (wrong) pin
numbering would have made "close to VDD/GND" close to the wrong physical
locations entirely.

---

## PDM wiring (per cluster)

13 signals (`C{n}_PDM_CLK` + `DATA_00`-`DATA_47`, 2 mics per data line, global
label names matching `pcb/mic_array/`'s own numbering) routed from the
cluster's Cmod A7-35T DIP header straight to the cluster's 3 arm sub-sheets — no intermediate
connector, since the arm sheets live in the same project. `DATA_NN` indices
are globally unique across all 12 arms (cluster N uses `DATA_{12N}` through
`DATA_{12N+11}`), so there's no cross-cluster collision even though all 4
clusters' arm sheets share one project namespace.

The clock is **not** shared across clusters, unlike `pcb/mic_array/` (which
has one `PDM_CLK` net for all 96 mics from a single FMC source): each cluster
receives its own forwarded-clock copy over its own spoke (see below), so each
cluster's 3 arms use a cluster-specific label (`C0_PDM_CLK`, `C1_PDM_CLK`,
etc.) instead of the shared `PDM_CLK` name `make_arm()` uses by default.

DIP pin numbers used on the cluster's Cmod A7-35T side (1-13 of the header's
44 available GPIO — see `fpga/multi_fpga/cluster/xdc/cluster_top.xdc`'s header comment
for the real, already place-and-routed pin count) are representative — cross-
check the generator's assignments against that XDC (same ground-truth source
`route_arm_board.py` should use) before wiring.

---

## Host interface: USB bridge to Raspberry Pi 5

No GbE MAC or RGMII PHY on the hub — see PHASE4.md's "Host interface" section.
`A6` (FT232H) talks a synchronous 245-mode 8-bit FIFO to the hub over 12 of
the hub's DIP pins (`USB_D0`-`USB_D7` = data, `USB_RXF_N`/`USB_TXE_N`/
`USB_RD_N`/`USB_WR_N` = control — see Spoke bus, above, for how these share
the DIP header with all 4 spokes), then a USB cable to a Raspberry Pi 5 USB 3.0
port (device is USB2 Hi-Speed, ~320 Mbps, well over the 110 Mbps payload).
Cmod A7-35T has no on-board Ethernet PHY at all (unlike the Arty A7-35T
originally considered — see PHASE4.md "Why Cmod A7-35T, not Arty A7-35T"), so
there's nothing to leave unused here.

---

## ERC: zero errors

`kicad-cli sch erc` on this project (`top.kicad_sch`, full hierarchy) reports
**zero errors**. `pcb/mic_array/` shares the per-mic wiring generator
(`make_arm()`) and has been regenerated with the same fixes, so it carries
them too — its only remaining errors (`power_pin_not_driven` ×2,
`pin_not_driven` ×1) are pre-existing and unrelated (no `PWR_FLAG`s added
there; out of scope so far). Error classes that showed up during development
were fixed at the root rather than documented as accepted:

- `pin_to_pin` ("Output and Output connected") on each mic pair's shared PDM
  data line (L/R time-multiplexed via `SEL`, never driving simultaneously) —
  fixed by giving the IM72D128 `DATA` pin `tri_state` electrical type instead
  of `output` in `pcb/make_schematic.py`'s `_lib_mic()`, matching the mic's
  real behavior (tri-stated on the half-cycle it isn't selected).
- `power_pin_not_driven` on GND/+5V — these are genuinely externally
  supplied (from the Raspberry Pi 5, see "Power architecture" below), no
  on-schematic source, so ERC has no driver for them. Fixed with
  `power:PWR_FLAG` symbols (the standard KiCad idiom for this): one pair
  each for GND/+5V in `hub.kicad_sch` — see `_pwr_flag_pair()` in
  `pcb/make_schematic_multi_fpga.py`. `+3V3` (`C{idx}_3V3`) used to
  need the same treatment, but now that `VR1`/`VR5` (the per-board LDOs)
  drive them with a real output pin, ERC is satisfied naturally — no flag
  needed, and adding one would be redundant.

Two further defects weren't ERC violations at all (KiCad's type-conflict
rules don't cover them) but were real bugs in the generated schematic,
found by inspection:

- **CLK silently shorted to SEL on every mic pair.** `CLK_DX` and `SEL_DX`
  (in `pcb/make_schematic.py`) put both pins on the same x column, 2.54mm
  apart; a straight CLK-to-CLK wire between the L and R mic ran directly over
  the R mic's SEL pin. Fixed by jogging the CLK wire left, clear of the SEL
  column, before running it vertically (`CLK_CLEAR`).
- **`SEL`/`DATA`/`CLK`/`VDD`/`GND` pin-name text all rendered on top of each
  other** at the body centre, illegible. Caused by `_lib_mic()`'s
  `pin_names (offset 0.508)` — the offset drags name text *inward* from the
  pin's outer tip toward the body centre, not outward; with 5 pins this
  close together, anything above `offset 0` collides. Fixed by setting it to
  `0`, which places each name right at its own pin tip.
- **Every mic's pin *numbers* were wrong — a real, board-killing bug, not
  just a cosmetic one.** `_lib_mic()` used an invented numbering
  (1=VDD, 2=GND, 3=DATA, 4=CLK, 5=SEL) that doesn't match the real
  IM72D128V01 part at all. The actual pinout (confirmed against both the
  datasheet's Table 9 and the vendor's own KiCad symbol,
  `pcb/IM72D128/KiCad/IM72D128V.kicad_sym`, already in the project but
  never cross-checked against): **1=DATA, 2=VDD, 3=CLOCK, 4=SELECT,
  5=GND**. As coded, the PCB net-assignment script
  (`pcb/route_arm_board.py`) drove these wrong numbers straight onto
  physical footprint pads — pad 1 (really DATA) would have had +1.8V
  driven onto it, and pad 2 (really VDD) would have been shorted straight
  to GND, on every one of the 96 mics. Found by the user comparing the
  generated schematic against the vendor CAD files directly (`./lib`),
  not by any automated check — ERC/DRC have no way to catch "these pin
  numbers don't match the real part," since nothing in this project
  encodes the datasheet as ground truth to check against. Fixed by
  correcting only the `number` fields in `_lib_mic()` (pin names/positions
  were already fine) and correspondingly `route_arm_board.py`'s
  `mic_nets()`. See "Power architecture" below for the cap-placement and
  GND-stub consequences.

Two more weren't ERC violations *or* electrical bugs, but duplicate reference
designators — a project-wide annotation check the KiCad GUI reports
separately from `kicad-cli sch erc` (which doesn't catch either of these):

- **CMOD_S7/Arty/FT232H reused the "U" mic range.** All 4 clusters' CMOD_S7
  said `U1` (colliding with each other *and* with the first mic in every
  arm sheet), and the hub's Arty/FT232H said `U1`/`U2` (colliding with mics
  1 and 2). Fixed by moving these dev-board modules to their own "A"
  (assembly) prefix: `A1`-`A4` per cluster, `A5` (Arty), `A6` (FT232H) — see
  the reference designator table above.
- **`#PWR0001`-`#PWR0018`-ish duplicated across files.**
  `pcb/make_schematic.py` and `pcb/make_schematic_multi_fpga.py` each kept
  their own independent `_pwr_n` counter for auto-numbering `#PWR` symbols,
  both starting at 0. `main()` calls `make_arm()` (12x, via
  `make_schematic.py`'s counter) before `make_cluster()`/`make_hub()` (via
  this file's own, separate counter) — so the low numbers in the arm-file
  group and the cluster/hub-file group collided, since KiCad treats the
  whole project as one flat reference namespace regardless of which file a
  symbol is defined in. Fixed by having `make_schematic_multi_fpga.py`'s
  `_pref()` share `make_schematic.py`'s counter instead of keeping its own
  (imported as `ms`, incrementing `ms._pwr_n[0]`) — the numbering is now one
  continuous sequence (`#PWR0001`-`#PWR0498`) across the whole project.

Remaining violations are all warnings, in the same classes already present in
`pcb/mic_array/`'s own ERC output:

- `lib_symbol_issues` / `lib_symbol_mismatch` — symbols are embedded directly
  in each sheet (no project `sym-lib-table`), same approach as the primary
  design's generator. `lib_symbol_mismatch` count is non-deterministic
  run-to-run (varies with the random per-instance UUIDs each regeneration
  produces) — cosmetic, not a connectivity issue.
- `footprint_link_issues` (×2, `Y1`/`TCXO_OSC` and `A6`/`FT232H_BRK`) —
  `kicad-cli sch erc` reports "configuration does not include the footprint
  library 'multi_fpga'" even though `pcb/multi_fpga/fp-lib-table` exists at
  the standard project-local location and defines that nickname; `kicad-cli`
  appears not to merge project-local `fp-lib-table` into this particular
  headless check (opening `multi_fpga.kicad_pro` in the GUI resolves it
  normally, since that's the standard place KiCad looks). Cosmetic, same
  category as the `lib_symbol_*` warnings above — not a connectivity issue.

`endpoint_off_grid` no longer appears at all: every placement constant in
both generators (`pcb/make_schematic.py` and
`pcb/make_schematic_multi_fpga.py`) is now an exact multiple of `GRID = 1.27`
(KiCad's default 50 mil schematic grid), so every pin, wire endpoint, and
label lands on-grid by construction.

---

## Not yet done

- This is now laid out as a real carrier PCB (`pcb/layout_multi_fpga.py`):
  footprints assigned, board outlines drawn, mechanical stack (hub at the
  array centre, standoffs, spoke connectors, camera, Pi 5) placed — but
  **placement only, no routing yet**. Traces from each spoke socket to the
  hub's `CMOD_A7_35T_DIP` pins, PDM traces, and power distribution all
  still need to be routed.
- Several mechanical dimensions are placeholders pending physical parts in
  hand: Cmod A7-35T pin protrusion (~9mm, carried over unconfirmed from the
  earlier Cmod S7 assumption — sets standoff height, needs re-measuring
  against an actual Cmod A7-35T module before fab), Pi Camera
  Module 3's lens-barrel diameter (cutout sized generously), Pi 5's exact
  hole-pattern offsets, and the header/socket pin-length variant needed to
  match the chosen standoff height — see `pcb/layout_multi_fpga.py`'s
  `place_hub()` comments for each.
- FPGA pin names here are meant to come from Digilent's own published `.xdc`
  for both tiers now (both are Cmod A7-35T) — cross-check the generator's
  actual pin assignments against `fpga/multi_fpga/cluster/xdc/cluster_top.xdc`/
  `fpga/multi_fpga/hub/xdc/hub_top.xdc` (the RTL side's already-real, already
  place-and-routed pin constraints) before ordering connectors.
- No HDL exists yet for either FPGA (see PHASE4.md) — this schematic is the
  physical interconnect only. The spoke connector's signal-integrity flag
  (shared Pmod ground / `CLK` jitter, see above) should be revisited once
  it does.

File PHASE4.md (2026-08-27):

# Phase 4 — Full Custom Array

96-mic Underbrink-spiral array + single-FPGA front-end (one ALINX AC7200 module, Xilinx
XC7A200T) doing the entire 96-channel CIC/FIR pipeline plus direct GbE/UDP packetization to
the host — no cluster/hub split, no USB bridge. Physically two mating boards: `mic_array`
(the 96-mic disc) and `front_end` (FPGA module, buck regulator, GbE PHY). RTL feasibility is
confirmed on real placed/routed numbers; PCB layout is in progress. The original Multi-FPGA
(Clustered) design (5× Xilinx 7-series FPGAs, USB bridge to a Raspberry Pi 5) is kept as a
proven, already-working alternate — its RTL is fully implemented and verified, and it
synthesizes/places/routes clean on real hardware.
Goal: full-performance acoustic camera meeting system requirements (200 Hz – 8 kHz, ±45° FoV,
~5° resolution @ 1 kHz).

---

## Hardware Design Decisions

### Microphone — Infineon IM72D128

Upgraded from the IM69D120 originally noted in DESIGN.md.

| Spec | IM69D120 (previous) | IM72D128 (chosen) |
|---|---|---|
| SNR | 69 dB(A) | **72 dB(A)** (+3 dB) |
| AOP | 120 dBSPL | **128 dBSPL** (+8 dB) |
| Sensitivity match | ±1 dB | ±1 dB |
| Phase match | ±2° | **±2°** (unchanged — factory calibrated) |
| Ingress protection | — | **IP57** (dust and moisture) |
| Interface | PDM | PDM |
| Approximate unit cost | ~$0.76 | ~$0.90–1.10 |

The phase matching spec is unchanged — critical for coherent array beamforming. The 3 dB SNR gain
improves weak-source detectability (dynamic range). IP57 is useful for outdoor / industrial use.
At 96 units the cost difference is approximately $14 total.

**Part number**: IM72D128V01XTMA1  
**Source**: DigiKey / Mouser / Future Electronics (standard lead times as of May 2026)

No strong competitor exists at this price point with documented ±2° factory phase matching.
TDK, STMicro, and Vesper PDM mics in this range do not publish comparable phase tolerance specs.

---

### FPGA — Single-FPGA (ALINX AC7200 Module)

One Xilinx XC7A200T does the entire 96-channel CIC + FIR pipeline plus direct GbE/UDP
packetization to the host, instead of splitting the front end across 5 smaller FPGAs (the
alternate Multi-FPGA design, described below). This was originally deferred behind two
structural costs: the XC7A200T ships only in a 484-pin BGA (bare-chip prototyping would need
a dev board, and custom-PCB assembly would need BGA rework), and all 48 direct PDM lines
would need routing the full ~300mm array span on one monolithic PCB. Both costs are resolved
by using the **ALINX AC7200** — a real, currently-sold XC7A200T System-on-Module (FPGA + 1GB
DDR3 + QSPI flash + clocks + full power delivery, fully assembled) — as the FPGA subsystem,
carried on a custom carrier board, rather than designing around the bare chip: no BGA
soldering or rework at any build stage, and the module's own 4× 80-pin/0.5mm board-to-board
connectors (195 usable GPIO across FPGA banks 13/14/15/16/34) comfortably cover the 48 PDM
DATA lines + PDM_CLK + RGMII/MDIO + JTAG this design needs.

Real quoted price (Aug 2026, CodeRobin/eBay): ~$299 — only ~$23 over the bare
XC7A200T-1FBG484C chip's own $275.99 DigiKey price for a complete, working, BGA-assembled
module. Compared to the alternate Multi-FPGA design's 5× Digilent Cmod A7-35T modules (~$520
for the FPGAs alone), this comes out roughly **$240/unit cheaper** at the component level,
with the real engineering risk of custom BGA power delivery and prototyping removed entirely.

#### Physical design: two mating boards

Unlike the original single-monolithic-PCB plan, the physical design splits into two boards
that stack together via board-to-board connectors:

- **`mic_array`** — the 96-mic disc itself: all 96 IM72D128 mics + decoupling caps, the
  2-tier PDM clock fan-out tree (see Supporting ICs below), and local power regulation.
- **`front_end`** — the ALINX AC7200 module, a buck pre-regulator (TLV62569DBV) feeding the
  module's own +5V input, and the GbE PHY (see Supporting ICs below).

Both boards are managed as independent KiCad projects (`mic_array.kicad_pro`,
`front_end.kicad_pro`) sharing one common project-local symbol/footprint library
(`pcb/libraries/`). PCB layout is in progress; not yet fabricated.

#### Device comparison

| Device | LUTs | DSP | BRAM | 96-ch headroom | 128-ch headroom | Notes |
|---|---|---|---|---|---|---|
| XC7A35T | 20,800 | 90 | 1.8 Mb | No | No | Too small |
| ECP5-25F | 25,500 | 56 | 1.67 Mb | No | No | Too small |
| ECP5-45F | 44,500 | 90 | 1.93 Mb | Tight (5%) | No | Open toolchain; no 128-ch path |
| XC7A100T | 63,400 | 240 | 4.86 Mb | 35% | 16% | Considered; rejected (tight at 128-ch) |
| **XC7A200T** | **134,600** | **740** | **13.1 Mb** | **~75%** | **~60%** | **Chosen** |

#### Why XC7A200T over XC7A100T

The XC7A100T has 35% LUT headroom for 96 channels but only 16% for 128 channels — tight for
a first build where HDL synthesis estimates are uncertain. The XC7A200T gives 75% headroom
at 96 channels and 60% at 128 channels, with room for future FPGA-side additions (octave-band
parallel beamforming, hardware PSF, etc.).

Its 740 DSP48E1 blocks cover all 96 FIR compensation chains in dedicated DSPs with zero LUT
cost for MAC operations. The XC7A100T's 240 DSPs could handle this too but leaves little
margin for any additional DSP-heavy logic.

Both use the same Artix-7 family: same Vivado flow, same ILA/VIO in-circuit debug tools.
(The GbE MAC is not Xilinx's own TEMAC IP — see below.)

#### RTL feasibility: real placed/routed numbers, not estimates

Confirmed on `xc7a200tfbg484-1` — the exact part the ALINX AC7200 carries — via full
`synth_design → opt_design → place_design → route_design`, never trusting a synth-stage or
naively-extrapolated LUT number (this project has been burned by that twice already, see the
alternate Multi-FPGA design's own "Superseded by real synthesis" note below):

| Stage | Slice LUTs | Utilization | Registers | DSP48E1 | Notes |
|---|---|---|---|---|---|
| Pipeline only (96ch CIC+FIR) | 58,232 / 133,800 | **43.52%** | 13.39% | 96/740 (12.97%) | Route clean, 0 errors |
| + GbE MAC + UDP packetizer | 64,406 / 133,800 | **48.14%** | 22.12% | 96/740 (12.97%) | Route clean, 0 errors |

Comfortable margin either way — the fully-parallel (no CIC-sharing) architecture fits with
real margin to spare. GbE MAC is `alexforencich/verilog-ethernet` (MIT license), not
Xilinx's TEMAC IP core — TEMAC requires a separate license Xilinx doesn't bundle by default,
so the design switched to this open-source RGMII MAC instead, verified to elaborate cleanly
against the real Xilinx IODDR/BUFR primitives. Full protocol (fixed-source/dest UDP,
transmit-only, no ARP/DHCP/ICMP, checksum disabled per RFC 768) is in
`fpga/single_fpga/GBE_FRAMING.md`; end-to-end RTL is bit-exact against a golden model,
including the real multi-tone PDM pipeline feeding the packetizer.

#### Build strategy

No dev board, no bare-chip BGA rework, no deferred-to-rev-2 custom hub PCB — the ALINX AC7200
module *is* the finished FPGA subsystem from day one, carried on the `front_end` carrier
board described above. Real connector part numbers for the module's own 4× 80-pin headers
still need sourcing from ALINX's manual before the carrier board's connector footprints are
finalized.

#### Alternate: Lattice ECP5-45F

Only if a fully open-source toolchain (Yosys + nextpnr, no Vivado) is a hard requirement.
Fits 96 channels with ~5% margin; does not fit 128 channels. GbE SerDes integration is
harder (~4–6 extra weeks). Suitable for a rev-2 board after the HDL is proven on Artix-7.

#### Considered and rejected: Zynq-7020

85,000 LUTs + dual-core ARM Cortex-A9. Potentially interesting for Config A (standalone)
because the ARM could replace the Pi 5, but rejected:
- Cortex-A9 @ 1 GHz is 4–5× slower than Pi 5's Cortex-A76 for NumPy/BLAS
- 96-ch D&S at 3°/pt: ~80–100 ms on Zynq ARM vs ~20 ms on Pi 5 (~5–10 fps vs 15–20 fps)
- 85k LUT fabric gives less headroom than XC7A200T
- PS+PL integration adds toolchain complexity (Vivado + Vitis)
- Pi 5 + XC7A200T is better performance at comparable total cost
- Worth revisiting for a future rev-2 if a single-board integrated design is desired

#### Considered and rejected: 128-mic array

Adding 32 mics (96 → 128, 8 arms × 16) was evaluated:
- Benefits: +1.3 dB array gain, ~1 dB sidelobe improvement — marginal
- Costs: FPGA headroom drops from 60% to ~45% on XC7A200T (still fine, but closer);
  ECP5-45F no longer fits; Pi 5 D&S grows from ~20 ms to ~36 ms at 3°/pt
- HPBW is aperture-limited, not mic-count-limited — adding mics does not change resolution
- Verdict: not worth it for the first board; revisit if Phase 4 data shows sidelobe-limited
  performance in a specific measured scenario

> Note: this tradeoff is specific to this design's fixed LUT budget. The alternate Multi-FPGA
> (Clustered) design (below) scales past 96 mics by adding a 5th cluster (each cluster tile's
> own per-FPGA cost stays fixed at 24ch/71% LUT regardless of cluster count, confirmed by real
> synthesis — see `fpga/README.md`) rather than upsizing one chip — this LUT-headroom squeeze
> is itself a reason to prefer that design if the mic count is likely to grow.

#### Considered and rejected: 350 mm aperture

Increasing aperture from 300 mm to 350 mm was evaluated:
- HPBW improvement: ~14% across all frequencies (e.g., 22° → 19° at 3 kHz) — modest
- Far-field distance increases: 4.2 m → 5.7 m at 8 kHz; at a typical 5 m working range the
  system would be operating in near-field at 8 kHz, introducing systematic DoA error
- Spatial Nyquist drops: scaling 96 mics over a larger aperture increases min spacing from
  ~21 mm to ~24.5 mm, dropping Nyquist from 8.2 kHz to ~7.0 kHz; restoring Nyquist requires
  ~131 mics → rounds to 128
- PCB is 17% larger; harder to mount at array center
- Verdict: the far-field regression outweighs the HPBW gain for the first board; revisit with
  a larger mic count after Phase 4 field data is available

---

### FPGA — Alternate: Multi-FPGA (Clustered)

Splits the front-end across **5 small Xilinx 7-series FPGAs**: 4 "cluster" FPGAs, each
handling one quadrant of the array, plus 1 "hub" FPGA that aggregates their output and
bridges it to a Raspberry Pi 5 over USB (see Host interface below) — the hub never speaks
Ethernet itself.

Kept as a proven, already-working alternate to the primary single-FPGA design (above).
Motivation (historical, i.e. why this was originally the primary design before the AC7200
module made the single-FPGA path practical): a single-FPGA design needs the XC7A200T,
which ships only in a 484-pin FBGA (`XC7A200T-1FBG484C`) — forcing a dev board at prototype
stage and BGA rework at custom-PCB stage — and routes all 48 direct PDM lines the full
~300mm span of the array on one monolithic PCB. Splitting the front end across several much
smaller FPGAs — each fitting a hand-assembly-friendly module — removes that constraint at
both the prototype and custom-PCB stage, and turns one 300mm PCB with 48 matched PDM traces
into several independently buildable, testable, and replaceable tiles.

#### Partition: 4 clusters of 3 arms each

96 mics = 12 arms × 8 mics (the chosen Underbrink spiral, see Array Geometry below). The
12 arms divide evenly into 4 symmetric 90° quadrants of 3 arms (24 mics) each — the natural
mechanical unit for this split.

Grouping was evaluated at several granularities. Two blocks — PDM capture control and the
serial-link framing logic — are largely fixed overhead per FPGA rather than scaling with
channel count, so grouping arms uses silicon more efficiently, not just fewer connectors:

| Grouping | FPGAs | Ch/FPGA | Est. LUT/FPGA | Headroom on XC7S25 (14,600 LUT) |
|---|---|---|---|---|
| 1 arm/FPGA | 12 | 8 | ~2,950 | ~80% unused |
| 2 arms/FPGA | 6 | 16 | ~5,350 | ~63% unused |
| **3 arms/FPGA (chosen)** | **4** | **24** | **~7,750** | **~47% unused** |
| 4 arms/FPGA | 3 | 32 | ~10,150 | ~30% unused |

(Model: CIC ≈ 250 LUT/ch and FIR ≈ 25 LUT/ch — both linear, matching the 96-channel
pipeline estimate above — plus PDM control ≈ 150 + 15/ch and link framing ≈ 400 + 10/ch as
fixed-ish terms. Rough estimates pending real HDL synthesis, same caveat as the 96ch
numbers above.)

4 clusters at 24ch each was chosen over 1-per-arm (12 FPGAs, mostly-idle silicon, 3× the
connectors) and over coarser groupings that start eating into headroom without much
further connector reduction.

> **Superseded by real synthesis**: the table above (and the XC7S25-based reasoning through
> this whole section) reflects pre-HDL, pre-synthesis estimates. Once the CIC/FIR pipeline
> was actually built, the chosen 3-arm/24ch grouping's *real* placed cost came back at
> **14,768 LUT** (see `fpga/multi_fpga/cluster/rtl/cluster_top.v`'s header comment) — 1.9× the ~7,750
> estimated above, driven by control-set packing overhead a pre-place estimate doesn't see.
> That's too big for the XC7S25 (14,600 LUT) this section chose, so the cluster tier moved to
> the same XC7A35T (20,800 LUT) the hub already used — landing on **71.00%** utilization
> there, not the ~47% "headroom" this table projected. A later exploration (this project's
> plan file, "Mark II re-partition") built the 4-arm/32ch row for real too: **19,662 LUT =
> 94.53%** of the XC7A35T, nowhere near this table's ~30%-unused projection — confirming the
> 3-arm/24ch grouping chosen here was the right call, just on a bigger, single-part-number
> chip than planned. See `fpga/README.md` for current numbers on both tiers.

#### Architecture: hub-and-spoke, single shared clock domain

- **4× cluster FPGA** (Xilinx Artix-7 **XC7A35T**, 20,800 LUT — originally planned as a
  Spartan-7 XC7S25, moved after real synthesis, see the note above): PDM clock fan-out to its
  24 local mics, per-cluster CIC decimation + FIR compensation, then frames the decimated
  48kHz PCM onto a parallel single-ended bus back to the hub (see Spoke link below — not
  true LVDS; the Cmod A7-35T's exposed I/O has no differential-capable pins). No GbE MAC, no
  PHY chip, no TCXO on the tile. Fits on the **Digilent Cmod A7-35T module** (~$99) — BGA
  pre-mounted, no hand rework needed even at prototype stage.
- **1× hub FPGA** (Xilinx Artix-7 **XC7A35T**, 20,800 LUT — same part as the clusters, see
  above): holds the single 12.288 MHz TCXO, generates the 3.072 MHz PDM clock and forwards it
  to all 4 clusters over the same spoke links — source-synchronous, one clock domain
  end-to-end (only a fixed, calibrate-once per-spoke cable-length skew, not drift).
  Reassembles the 4 incoming streams (96 channels total) and frames the result out over a
  **USB FIFO bridge to a Raspberry Pi 5** (see Host interface below) — no GbE MAC, no RGMII
  PHY chip, no Ethernet routing on the hub board at all. Available on the **Digilent Cmod
  A7-35T module** (~$99) — same compact 48-pin DIP breadboardable form factor as the cluster
  tiles (see "Why Cmod A7-35T, not Arty A7-35T" below); no on-board Ethernet PHY to leave
  unused, since this module doesn't have one at all.

Star topology, not a daisy-chain: each cluster connects directly to the hub over its own
short link (clusters already sit close to the center), rather than chaining cluster→
cluster→hub, which would add latency and let one broken link take out others downstream
of it.

| | Cluster FPGA (×4) | Hub FPGA (×1) |
|---|---|---|
| CIC decimation (24ch) | ~6,000 LUT | — (moved to clusters) |
| FIR compensation (24ch) | ~600 LUT | — |
| PDM capture/demux | ~500 LUT | — |
| Spoke bus framing/deframing | ~400 LUT | 4× deframer ≈ 1,000-1,200 LUT |
| USB FIFO bridge interface (sync FIFO ctrl + framing) | — (not needed) | ~300-400 LUT |
| Clock gen (PLL from TCXO) | — (receives forwarded clock) | ~500 LUT |
| **Total estimate** | **~7,500 LUT** | **~1,800-2,100 LUT** |

#### Spoke link: parallel single-ended bus, not LVDS

Both the cluster's and the hub's Cmod A7-35T modules route every exposed I/O pin (Pmod and
48-pin DIP header alike) through a 200-240Ω series protection resistor, capped at 25 MHz —
standard practice for a breadboard-friendly module on both boards, but it rules out true
differential LVDS: a series resistor at the connector breaks the controlled 100Ω
differential impedance a real LVDS receiver needs. Digilent only exposes genuine
shunt-configurable/high-speed differential pins on other boards (e.g. the Arty A7's JB/JC);
neither Cmod module has that option on any connector.

Instead, each spoke is an ordinary **parallel single-ended bus**: **6 data bits + 1 strobe +
1 forwarded PDM clock (in) = 8 signals**, one cable per spoke. 27.6 Mbps payload ÷ 6 bits ≈
4.6 MHz per wire — about 5× margin under the 25 MHz cap, comfortable for a short cable at
prototype stage. Cluster-side, each cluster carries its spoke on its own Cmod A7-35T's single
Pmod, JA. Hub-side, all 4 spokes land on the hub's DIP header, not its Pmod —
see "Why all-DIP, no Pmod" below.

#### Host interface: USB bridge to Raspberry Pi 5

This hub always talks to a co-located **Raspberry Pi 5** over USB, and the Pi 5 decides what
to do with the stream (unlike the primary single-FPGA design, whose hub drives GbE directly to a
network switch, received by either host in Configuration A or B — see Host Configurations,
below):

- **Hub → Pi 5**: one **FTDI FT232H** USB-to-FIFO bridge (~$5 chip, ~$15 breakout module),
  wired to the hub FPGA as a synchronous 245-mode 8-bit parallel FIFO (~12 signals: 8 data +
  RXF#/TXE#/RD#/WR#, no SerDes/GTP needed — a small enough pin count to fit on the hub's
  DIP header alongside the spoke links, see Spoke link above). USB 2.0
  Hi-Speed sync-FIFO mode sustains ~320 Mbps, comfortably over the 110 Mbps (96ch × 24-bit ×
  48kHz) payload, with headroom to spare if channel count or bit depth grows later. Talks to
  either of the Pi 5's USB 3.0 ports (USB2-speed device, backward compatible).
- **Standalone**: Pi 5 reads the stream over USB and runs beamforming/display locally
  (Configuration A — see Host Configurations, below).
- **Tethered**: Pi 5 relays the same stream out its own on-board Gigabit Ethernet port to an
  external GPU workstation (Configuration B — see Host Configurations, below). Unlike the
  primary single-FPGA design's direct hub→switch→workstation link, this path is
  hub→USB→Pi 5→GbE→workstation. The Pi 5's native GbE, otherwise idle in standalone mode, is
  reused for this rather than adding a second Ethernet interface.

This removes the hub's GbE MAC + RGMII PHY entirely (see the LUT table above and the
"Why XC7A35T" note below) at the cost of routing every byte through the Pi 5 even in
tethered mode — an extra hop, but a trivial one: 110 Mbps is ~11% of the Pi 5's own GbE
link, and Cortex-A76 UDP relay/forwarding overhead at this rate is not a real bottleneck.
The Pi 5 becomes a mandatory part of the BOM for both configurations, not just standalone.

#### Why XC7A35T for the hub, not XC7S25 like the clusters were originally planned

Historical reasoning (from when the clusters were still planned as XC7S25 — see the
"Superseded by real synthesis" note earlier in this section for what actually happened to
that plan): dropping GbE MAC/PHY from the hub, and replacing its LVDS deserializer with a
simpler parallel-bus deframer (see Spoke link and Host interface, above/below), shrinks its
LUT need well below the earlier GbE-hub estimate — the hub's ~1,800-2,100 LUT would leave
**~86-88% headroom on the same XC7S25** planned for the clusters at the time, an even
stronger case for one single part number (5× identical Cmod S7 modules) than before.

Chosen instead: **XC7A35T for the hub** (~90-91% headroom at this LUT count),
matching the primary single-FPGA design's reasoning for picking the bigger XC7A200T over XC7A100T —
headroom for future FPGA-side additions (octave-band parallel beamforming, hardware PSF
correction) — while still being a small, cheap part relative to the XC7A200T it replaces.
With GbE gone, LUT budget no longer drove this choice in either direction; it was purely a
bet on whether future hub-side additions were worth keeping open. All-XC7S25 was noted here
as a documented lower-cost/single-part-number fallback if that headroom wasn't needed —
**that fallback never happened, but the "one single part number" outcome did anyway**: once
real synthesis forced the clusters off XC7S25 (see above), they landed on this same XC7A35T,
so the hub's choice here turned out to set the part both tiers would eventually share.

#### Why Cmod A7-35T, not Arty A7-35T

The chip choice above (XC7A35T) is independent of which physical board carries it. The
original build used the **Arty A7-35T dev board** (~$130): 4 pluggable Pmods (one per spoke
— no DIP-header wiring needed) plus a shield connector roomy enough for the FT232H bridge,
at the cost of being a full-size dev board unlike the clusters' compact Cmod modules.

Chosen instead: the **Digilent Cmod A7-35T module** (~$99) — same XC7A35T die, but in the
identical 48-pin DIP breadboardable form factor as the cluster tiles, rather than a
different, larger board family for the one-off hub. Digilent's own reference design
(`Cmod-A7-35T-GPIO`) confirms 44 digital DIP GPIO pins across the header, enough on its own
for all 4 spokes (32 signals) + the FT232H bridge (12) + TCXO clock in (1) = 45 signals with
1 pin to spare, once the module's one Pmod is also folded into the DIP-wired scheme — see
"Why all-DIP, no Pmod" below.

The tradeoff: unlike the Arty's 4 identical pluggable Pmods, none of the hub's spoke cables
get a plug-and-play connector — all 4 spokes plus the FT232H breakout are point-to-point
wiring on the DIP header. A real, if modest, bring-up inconvenience relative to the Arty. In
exchange: one part family (Cmod, not Cmod + Arty) across all 5 tiles, a smaller/cheaper
board, and a form factor that fits the same rev-2 compact-tile ambition already planned for
the clusters (see Rev-2, in Hardware Sub-Tasks below) instead of needing a separate path for
the hub.

#### Why all-DIP, no Pmod

Cmod A7-35T does have one real Pmod (JA, 8 signals) — the first version of this hub kept
spoke 0 on it, matching how every cluster's own spoke already uses a pluggable Pmod cable,
and used the DIP header only for spokes 1-3 + FT232H + TCXO (37 of 44 DIP pins).

Moved everything to the DIP header instead, spoke 0 included: mixing connector types (1
Pmod cable + DIP wiring for the rest) is *more* bring-up complexity than a single consistent
scheme, not less — one cable type to keep track of, one set of DIP wiring for the whole
board, rather than "which spoke is the pluggable one" as a special case to remember. The
cost is one additional DIP pin: 4 full spokes + FT232H + TCXO = 45 signals, one more than
the 44 confirmed-digital DIP pins. Filled by DIP pin 16 — documented as an XADC auxiliary
analog input (`vaux12`) rather than plain GPIO, but 7-series aux-analog pins are ordinary
fabric I/O when not driven into analog mode (the same reasoning already applied to unused
analog-capable FMC pins on the primary single-FPGA design's mic-array connector, and this design
has no use for the XADC at all). This specific pin hasn't been confirmed against a
plain-GPIO-mode example from Digilent, unlike the other 44 — flag for verification before
ordering hardware.

#### Why this design satisfies the modularity/cost motivation

- **Clock coherence is preserved, not compromised.** All 96 channels must stay phase-locked
  to one 48kHz word clock for coherent beamforming (see Sample alignment in FPGA
  responsibilities, below). Giving each cluster its own TCXO would reintroduce exactly the
  drift problem TCXOs were chosen to prevent in the first place; keeping the single TCXO on
  the hub and forwarding its clock preserves the existing clock-plan numbers unchanged
  (12.288 MHz → ÷4 → 3.072 MHz PDM → ×4 PLL → 49.152 MHz → ÷1024 → 48.000 kHz WS) — just
  distributed over cable instead of PCB trace.
- **Both tiers are far smaller than the XC7A200T** (134,600 LUT) — under 6% of it either way.
- **PCB routing simplifies at both levels**: each cluster only routes matched PDM traces
  within its own 90° sector (short spans to 3 nearby arms) instead of the full 300mm span,
  and the hub routes 4 spoke links instead of 48 matched PDM lines — likely drops the
  6-layer PCB recommendation for the mic array board.
- **No RGMII PHY chip or GbE MAC on the hub at all** (see Host interface, above) — a USB
  FIFO bridge to the Pi 5 is a far simpler board-level interface than routing RGMII plus an
  external PHY, and sidesteps PHY part selection entirely.

#### Honest tradeoffs

- New engineering work not needed for the primary single-FPGA design: the cluster-to-hub
  synchronous link protocol (clock forwarding, framing, per-spoke cable-skew calibration) has
  to be designed from scratch — it replaces what would otherwise be an internal parallel bus.
- PDM routing within a cluster reaches 3 arms per board, not 1 — a modest but real routing
  exercise, worth a first-pass floorplan sketch during detailed design.
- More BOM line items and connector points than the primary single-FPGA design (5 FPGAs instead of
  1, plus 4 cluster-to-hub cables) — each individually simpler/cheaper and independently
  testable, but more total assembly points to design connector keying/strain-relief for.
- Cost comparison here is directional, not quoted, matching how the primary single-FPGA design
  hedges its own $ figures — confirm with current distributor quotes once package/qty are
  picked.

#### Considered and rejected

- **1 FPGA per arm (12 total)**: each tile would use only ~20% of even the smallest
  practical FPGA — maximizes connector/BOM count for no headroom benefit.
- **2 FPGAs per arm-pair (6 total)**: a reasonable middle ground, superseded by the further
  consolidation to 4×24ch, which also enabled the hub-unification option above.
- **Daisy-chain instead of star topology**: rejected — adds latency, and a single broken
  link takes out all downstream clusters.
- **Per-cluster GbE PHY (no hub, parallel topology)**: rejected — 4× GbE PHY chips + 4×
  TEMAC MAC logic costs strictly more silicon/parts than one shared hub MAC+PHY, for no
  benefit given the array needs one coherent clock domain regardless.
- **Hub drives GbE directly (own RGMII PHY, no Pi 5 relay)**: the first version of this
  design gave the hub its own GbE MAC + PHY, mirroring the primary single-FPGA design's approach
  exactly. Rejected in favor of the USB-to-Pi-5 bridge above: it removes an entire PHY
  part-selection problem and ~3,000 LUT of TEMAC/UDP gateware from the hub, at the cost of
  making the Pi 5 mandatory in every deployment (including tethered/GPU-host mode) rather
  than optional.
- **Lattice iCE40UP5K for the cluster tiles**: considered for its open toolchain
  (Yosys/nextpnr/IceStorm) and lower per-chip cost (~$5-8) — clusters never touch GbE, so
  the ECP5 alternate's GbE-SerDes objection (above) wouldn't apply here either. Rejected:
  its 5,280 LUT ceiling doesn't fit the chosen 24ch/cluster load (~7,750 LUT estimate; even
  16ch would leave near-zero margin), and its few small hard multipliers make DSP-based FIR
  compensation (the same approach used here and in the primary single-FPGA design) unreliable at
  this channel count. Would also reintroduce a second toolchain alongside the hub's Vivado flow.

---

### Supporting ICs

#### GbE PHY

Needed only by the primary single-FPGA design (above) — the alternate Multi-FPGA design's hub
talks USB to a Raspberry Pi 5 instead and has no GbE MAC/PHY at all (see Host interface). The
FPGA implements the MAC layer in fabric (`alexforencich/verilog-ethernet`'s 1G RGMII MAC, MIT
license — not Xilinx's TEMAC IP core, which turned out to need a separate license Xilinx
doesn't bundle by default); a separate PHY chip handles the analog physical layer and
provides the RGMII interface.

**Chosen: Microchip KSZ9031RNX** — 48-pin QFN (no BGA reflow needed, unlike the other
candidate below), real quoted price ~$3.70–5.96, RGMII, widely used in hobbyist designs.
Marvell 88E1111 was considered and rejected: industry-standard and well-documented, but ships
only in a 117-ball BGA package and has real, confirmed sourcing difficulty at low volume —
neither advantage outweighs the extra BGA-assembly risk on a board that otherwise has none.

#### Master Clock — 12.288 MHz TCXO

A temperature-compensated oscillator (TCXO) is required rather than a plain crystal because
sample-rate drift accumulates in the CSM over long captures and corrupts coherence.

The 12.288 MHz frequency divides cleanly to all required audio clocks:

| Derived clock | Division | Value |
|---|---|---|
| PDM clock to mics | ÷ 4 | **3.072 MHz** (exact) |
| FPGA PLL output | × 4 | **49.152 MHz** |
| PCM word select (WS) | ÷ 1024 | **48.000 kHz** (exact) |

Recommended: any 12.288 MHz TCXO in ±2.5 ppm or better (e.g., NDK NZ2520SD, TXC 7M series).

#### PDM Clock Distribution (single-FPGA mic array board)

96 mics is too much fan-out for a bare TCXO output or a single 1:10-class buffer, and driving
it directly would exceed the TCXO's own rated output load. Two-tier real fan-out tree, TI
CDCLVC11xx family throughout (same low-skew family, pin-compatible members):

```
TCXO (12.288 MHz) -> 1x CDCLVC1112 (1:12) -> 12x CDCLVC1108 (1:8, one per mic arm) -> 96 mics
```

- **Tier 0**: a single CDCLVC1112 (1:12 LVCMOS buffer) takes the TCXO output directly — its
  only load, well inside the TCXO's rated drive. One output per arm, so all 12 second-tier
  buffers see the identical upstream edge (no device-to-device skew at this hop at all, since
  there's only one Tier-0 chip).
- **Tier 1**: one CDCLVC1108 (1:8) per arm, driven by its own Tier-0 output, driving that
  arm's 8 mic CLK pins directly (star topology, not daisy-chained).
- **Real skew budget** (from the CDCLVC11xx datasheet, not estimated): same-device output
  skew 50ps max (mics sharing one arm's buffer) vs. part-to-part skew 0.5ns max (mics on
  different arms) — the cross-arm figure dominates by 10x and is a fixed silicon
  characteristic, not fixable by trace-length matching. If beamforming coherence ever needs
  tighter than 0.5ns across arms, the fix is a one-time per-channel calibration measurement,
  not tighter routing.
- 13 buffer ICs total (1 + 12), all one part family — single BOM line, easy sourcing.

#### Power Supply (single-FPGA mic array board)

Real combined 3.3V load, computed from actual datasheet current figures (not estimated):

| Load | Per-unit | Count | Total |
|---|---|---|---|
| IM72D128 mics @ 3.072 MHz PDM clock | 980µA typ / 1120µA max | 96 | 94–108mA |
| CDCLVC1112 + 12x CDCLVC1108 (static, near 3.3V) | ~6mA typ / ~10mA max each | 13 | 78–130mA |
| Clock-tree dynamic (C_PD x VDD x f, ~108 active outputs) | ~61µA/output | — | ~7mA |
| ECS-TXO-5032 TCXO | 6.0mA | 1 | 6mA |
| **Total** | | | **~185mA typ, ~250mA worst-case** |

(AC7200 module power is separate — it takes +5V directly and generates its own onboard rails.)

A single small linear regulator off +5V (originally an MCP1700T-3302E/TT, 250mA max) is not
adequate: the worst-case load sits right at that part's current ceiling with no margin, and
at a 1.7V dropout (5V in, 3.3V out) it would dissipate up to ~425mW in a SOT-23 package — a
real thermal problem, not just a current-margin one. Real fix, buck pre-regulator + split
linear post-regulation:

```
+5V -> TLV62569DBV (buck, adjustable, 2A) -> ~3.6V -> 2x MCP1700T-3302E/TT -> clean 3.3V
                                                        (VR5: mics, VR6: clock tree + TCXO)
```

- Buck output set to ~3.6V (R1=499k / R2=100k feedback divider, VOUT = 0.6V x (1 + R1/R2)) —
  enough headroom for clean LDO dropout without wasting buck efficiency.
- Splitting the two LDOs by load *type* (quiet analog mic rail vs. noisy digital clock-tree
  rail), not by mic arm — per-arm splitting buys nothing once the buck removes the thermal/
  current problem, since every mic already has its own local decoupling cap; digital/analog
  separation is the split that actually reduces correlated-noise risk on a 96-channel
  coherent beamformer.
- Each LDO now sees ≤143mA against a 250mA rating (43–57% of max) with a ~0.3V dropout instead
  of 1.7V — comfortable current and thermal margin on both rails.

---

## Array Geometry

Same as established in Phase 1 simulation (nb05–nb11):

| Parameter | Value |
|---|---|
| Mic count | 96 |
| Pattern | Underbrink multi-arm log-spiral |
| Arms × mics per arm | 12 × 8 (6 × 16 simulated as alternative in Phase 1) |
| Aperture | ~300 mm diameter |
| Min mic spacing | ~13 mm |
| Spatial Nyquist | ~13 kHz (no aliasing within 8 kHz operating range) |
| Far-field distance | 0.52 m @ 1 kHz · 1.6 m @ 3 kHz · 4.2 m @ 8 kHz |

The geometry was optimized in Phase 1 simulation. The Underbrink pattern is preferred over a
regular grid because its logarithmic spiral arm spacing suppresses grating lobes across the full
frequency range, giving better sidelobe performance at low mic count.

---

## Host Configurations

In the primary single-FPGA design, the front-end drives GbE/UDP directly to whichever host is
present — a Pi 5 in standalone mode, or a GPU workstation in tethered mode — with no
intermediate relay required (see Interface, below). Two operating modes share the same
`acoustic_camera_p4.py` script, selected via a `--backend {numpy,cupy}` flag. (The alternate
Multi-FPGA design instead talks USB to a co-located Raspberry Pi 5, which is present in every
deployment and, in tethered mode, relays the stream onward over its own GbE port — see the
blockquote in Interface, below.)

---

### Configuration A — Standalone (Raspberry Pi 5, 8 GB)

Self-contained field unit. Pi is mounted in the camera housing alongside the FPGA hub board.
Runs from a battery. Display via HDMI touchscreen or SSH + web UI.
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

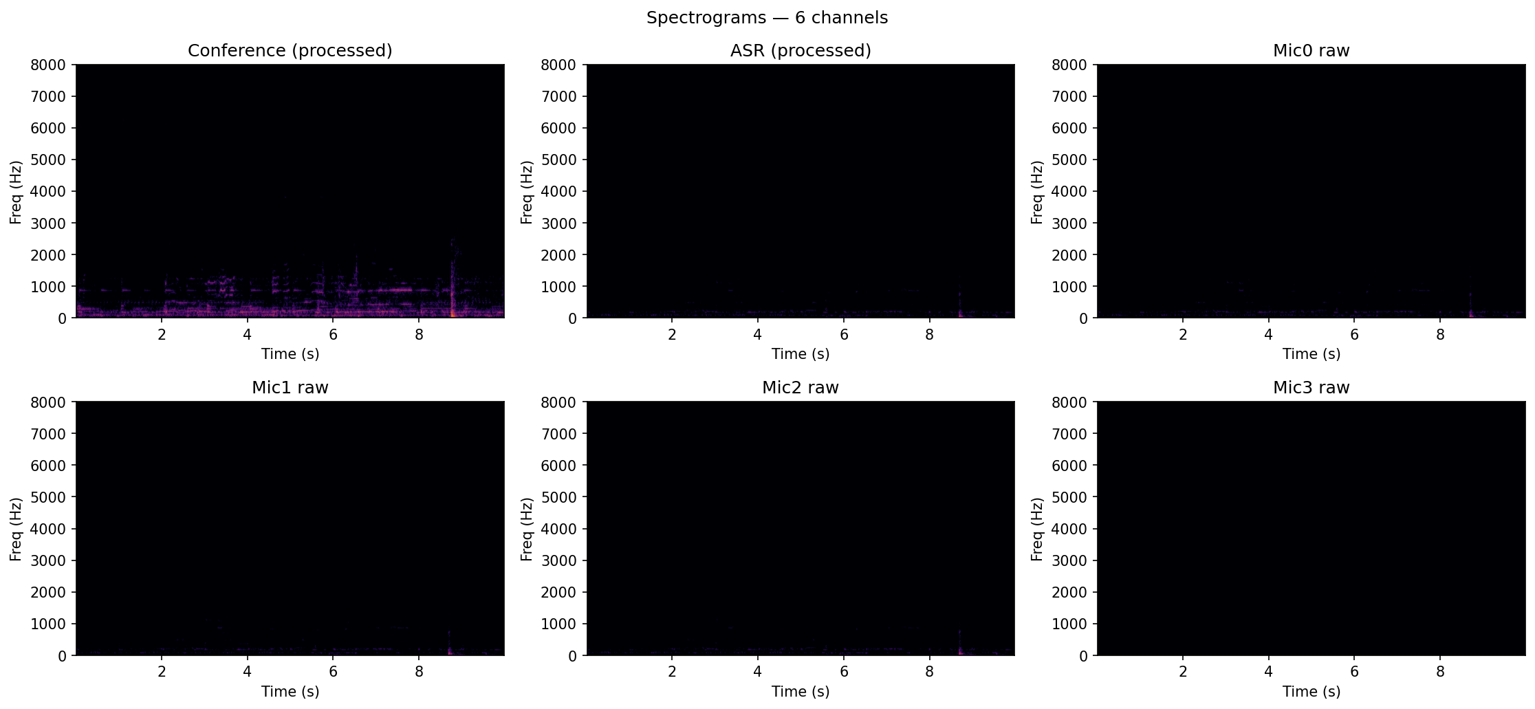
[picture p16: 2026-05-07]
notebooks/respeaker_spectrograms.png

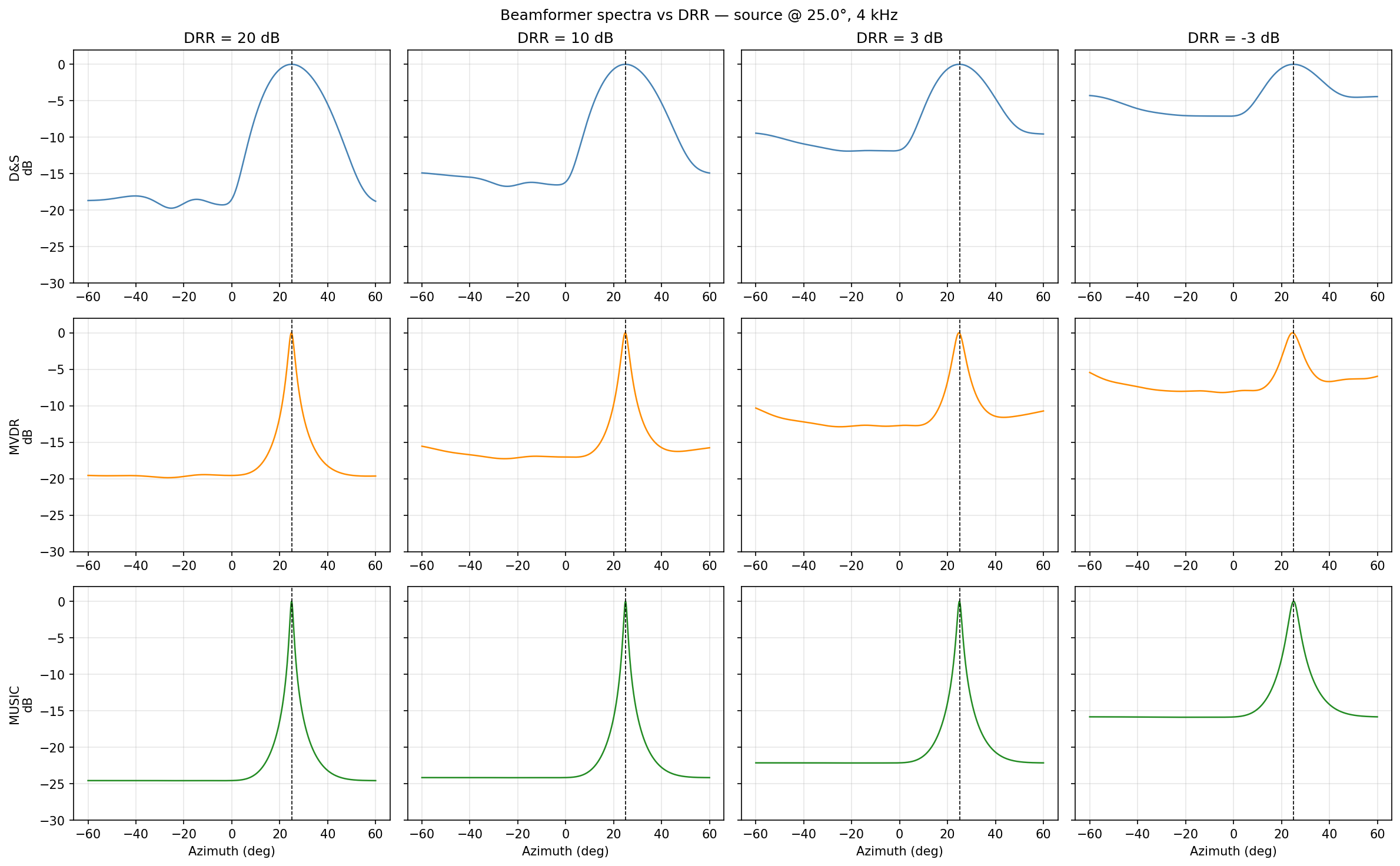
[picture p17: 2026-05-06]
notebooks/reverb_spectra.png

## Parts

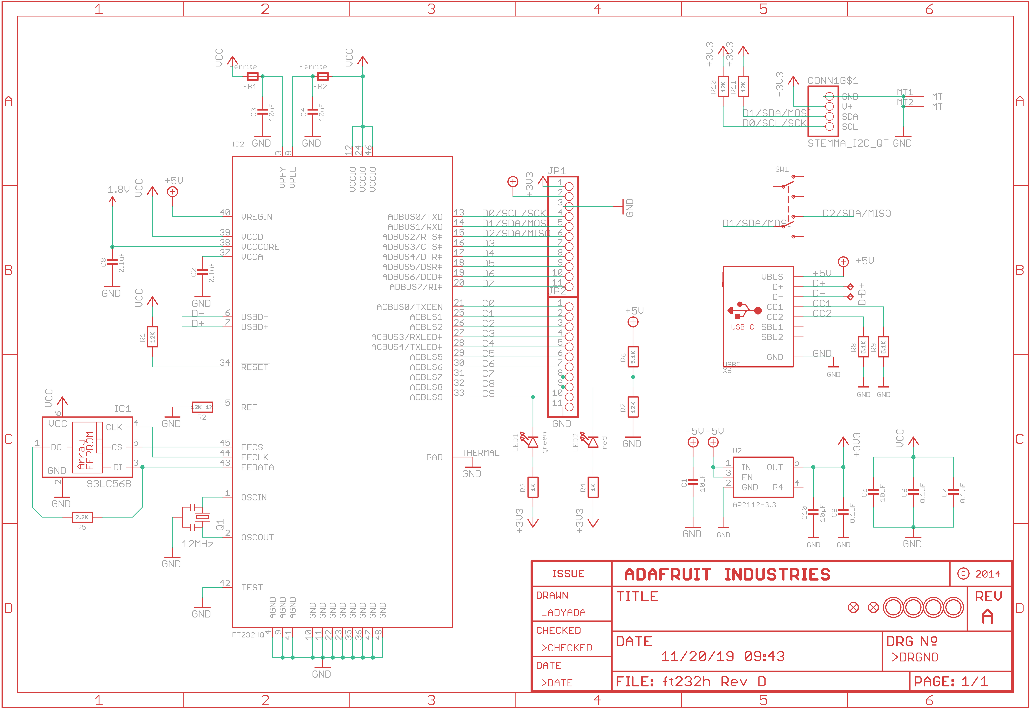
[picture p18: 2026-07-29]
datasheets/components_FT232H_sch.png

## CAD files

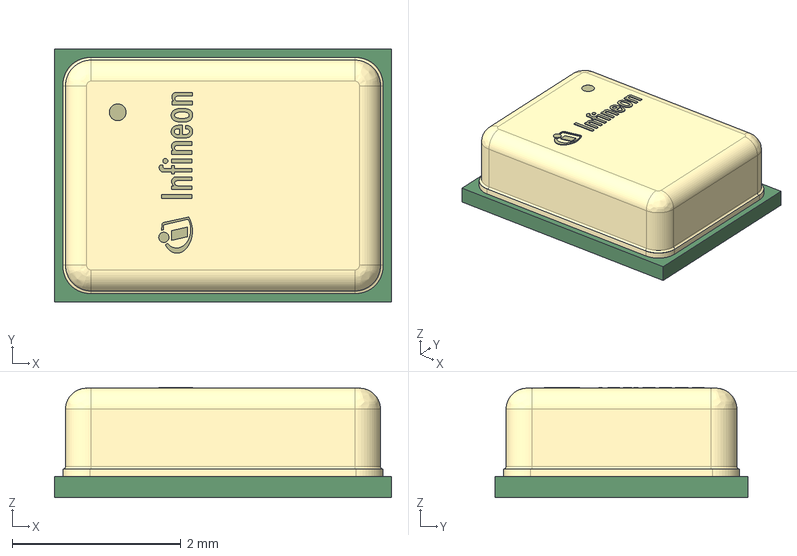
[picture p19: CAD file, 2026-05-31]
pcb/IM72D128/infineon-pg-llga-5-3-3d-stp-package-en.stp
4.00 x 3.00 x 1.31 mm

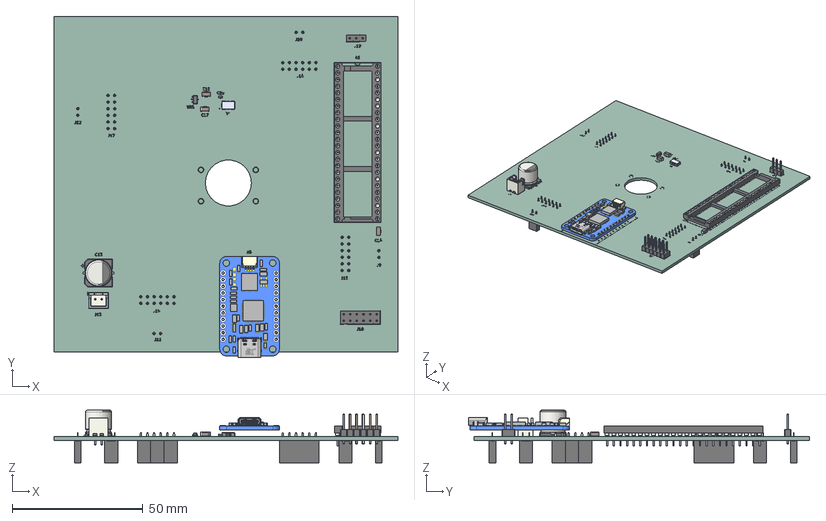
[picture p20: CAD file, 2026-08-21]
pcb/multi_fpga/hub.step
131.8 x 130.7 x 20.2 mm
BoardAdafruit_FT232H_Original
SM04B-SRSS-TB
xb-u50137r16ga042
DIP_48_W1524mm_Socket
PinHeader_2x06_P254mm_Vertical
JST_B2B_XH_A
ECS-TXO-5032-100-TR
C_1206_3216Metric x 3
C_0603_1608Metric
SOT-23
PinHeader_1x03_P254mm_Vertical
CP_Elec_10x10
PinSocket_1x02_P2.54mm_Vertical x 4
PinSocket_2x06_P2.54mm_Vertical x 4
hub_silkscreen x 2
hub_PCB

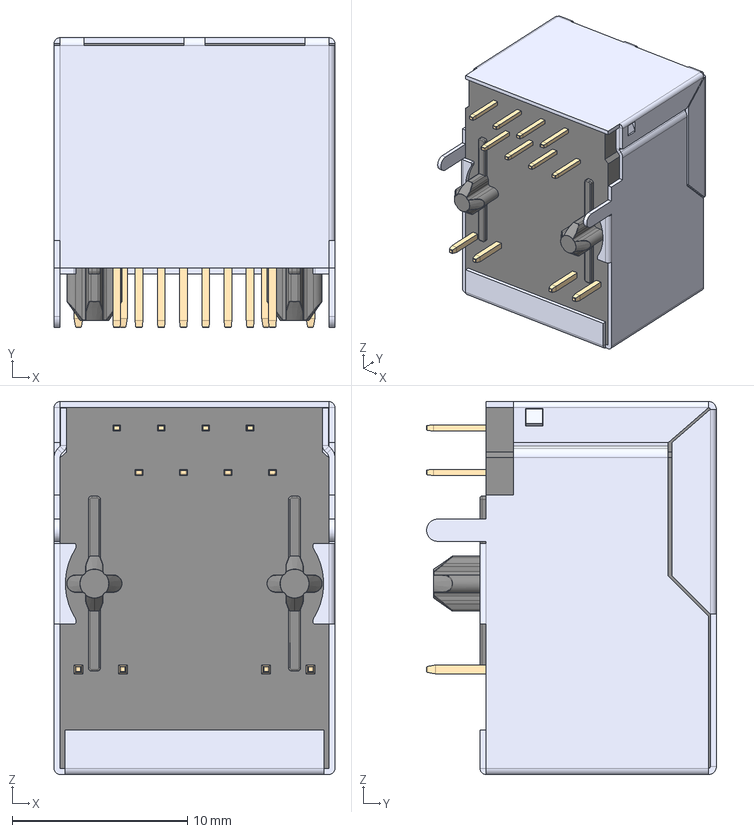
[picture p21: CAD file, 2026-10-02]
cad/hanrun_HR911105A_socket.step
16.0 x 16.6 x 21.3 mm
HR911105A_yellow_led
HR911105A_pin_001
HR911105A_pin_002
HR911105A_pin_003
HR911105A_pin_004
HR911105A_pin_005
HR911105A_pin_006
HR911105A_pin_007
HR911105A_pin_008
HR911105A_pin_009
HR911105A_pin_010
HR911105A_contact_004
HR911105A_contact_003
HR911105A_contact_002
HR911105A_contact_001
HR911105A_red_led
HR911105A_pin_011
HR911105A_pin_012
HR911105A_contact_005
HR911105A_contact_006
HR911105A_contact_007
HR911105A_contact_008
HR911105A_outer_shield
HR911105A_inner_023

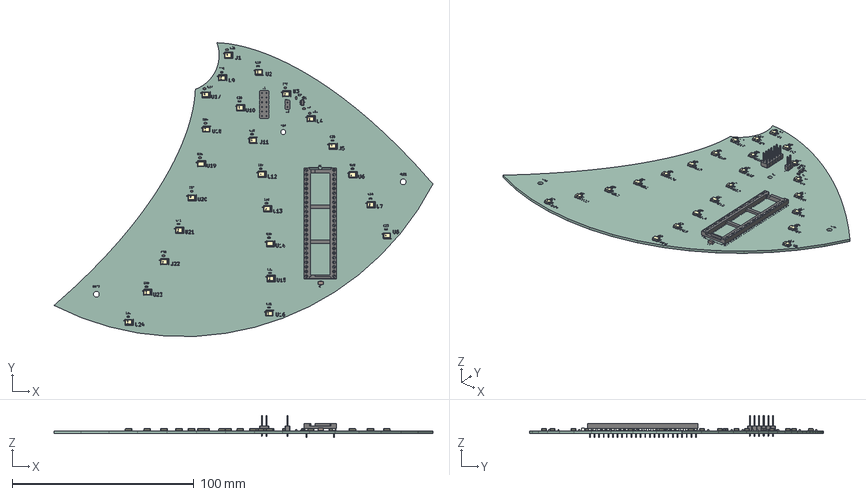
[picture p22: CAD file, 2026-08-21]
pcb/multi_fpga/cluster_00.step
208.8 x 161.7 x 12.3 mm
Product x 24
PinHeader_2x06_P254mm_Vertical
C_0603_1608Metric x 26
PinHeader_1x02_P254mm_Vertical
C_1206_3216Metric
SOT-23
DIP_48_W1524mm_Socket
cluster_00_silkscreen
cluster_00_PCB

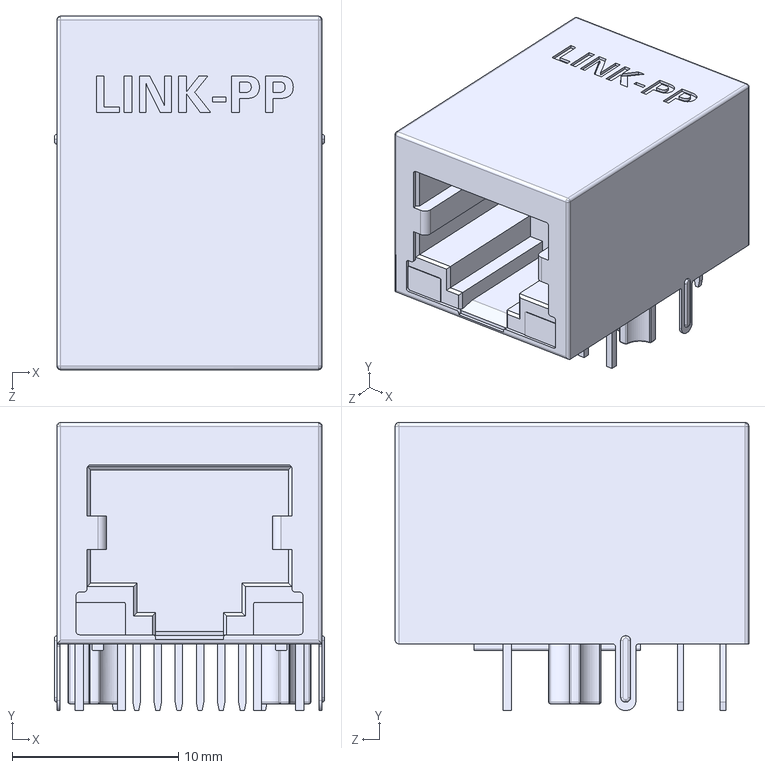
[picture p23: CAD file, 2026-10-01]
cad/LPJ0011FBNL.STEP
16.2 x 17.3 x 21.2 mm

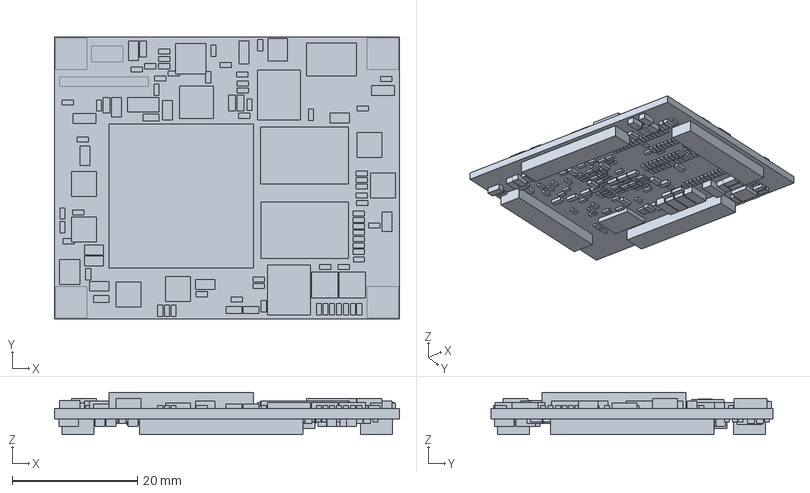
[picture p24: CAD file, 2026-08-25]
cad/AC7200.3.0.stp
55.0 x 45.0 x 6.76 mm
BOARD_OUTLINE
AXK680137YG x 4
MLP8
FBGA_96 x 2
LED_0805 x 3
SOT-23
OSC6-5X7 x 2
KEY_4X4X1_5
COILCRAFT-1008PS_SMALLPAD
HDR1X2
COILCRAFT-1008PS x 2
CMLE051E-5X5
SOT-23-5
FGG484
TLV62130RGT x 3
TPS51200DRCR
HDR1X6
SON10 x 2
FPAD_1 x 4
VQFN_3_5
C0805 x 21
C0603 x 35
C0402 x 118
R0402 x 73
C1206 x 6
L0603 x 4

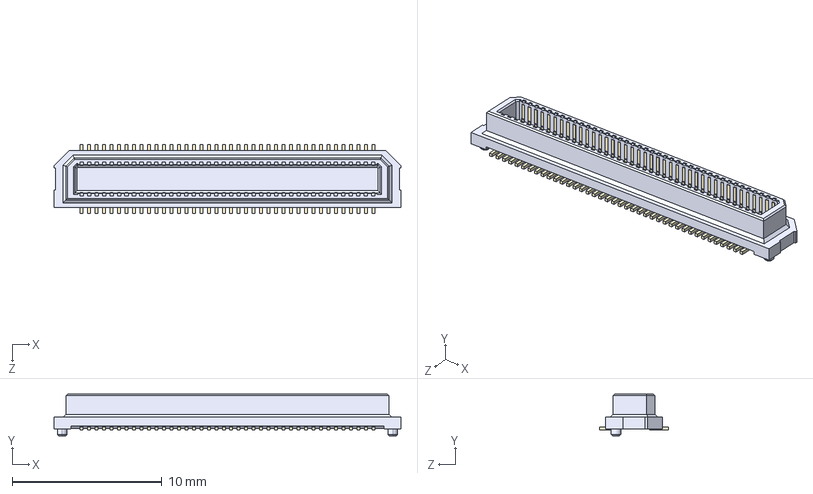
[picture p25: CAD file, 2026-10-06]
cad/AXK680337YG.STEP
23.2 x 2.80 x 4.60 mm
AXK680337YG_AXK6A2347YG
pin^AXK680337YG ass x 80

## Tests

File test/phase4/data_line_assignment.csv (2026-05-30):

data_line | mic_L | sel_L | arm_L | x_L | y_L | mic_R | sel_R | arm_R | x_R | y_R | pair_dist_mm
0 | 0 | GND | 0 | 25.0 | 0.0 | 1 | VDD | 0 | 41.8449 | 9.2594 | 19.2
1 | 2 | GND | 0 | 56.8545 | 21.3025 | 3 | VDD | 0 | 70.311 | 35.069 | 19.3
2 | 4 | GND | 0 | 82.4384 | 50.0238 | 5 | VDD | 0 | 93.4082 | 65.8494 | 19.3
3 | 6 | GND | 0 | 103.3539 | 82.3389 | 7 | VDD | 0 | 112.3825 | 99.3488 | 19.3
4 | 8 | GND | 1 | 21.6506 | 12.5 | 9 | VDD | 1 | 31.6091 | 28.9413 | 19.2
5 | 10 | GND | 1 | 38.5862 | 46.8757 | 11 | VDD | 1 | 43.3566 | 65.5262 | 19.3
6 | 12 | GND | 1 | 46.3819 | 84.5411 | 13 | VDD | 1 | 47.9692 | 103.7313 | 19.3
7 | 14 | GND | 1 | 48.3377 | 122.9846 | 15 | VDD | 1 | 47.6517 | 142.2298 | 19.3
8 | 16 | GND | 2 | 12.5 | 21.6506 | 17 | VDD | 2 | 12.9036 | 40.8685 | 19.2
9 | 18 | GND | 2 | 9.9788 | 59.8886 | 19 | VDD | 2 | 4.7848 | 78.4256 | 19.3
10 | 20 | GND | 2 | -2.1027 | 96.4056 | 21 | VDD | 2 | -10.3231 | 113.8185 | 19.3
11 | 22 | GND | 2 | -19.6306 | 130.6766 | 23 | VDD | 2 | -29.8473 | 147.0005 | 19.3
12 | 24 | GND | 3 | 0.0 | 25.0 | 25 | VDD | 3 | -9.2594 | 41.8449 | 19.2
13 | 26 | GND | 3 | -21.3025 | 56.8545 | 27 | VDD | 3 | -35.069 | 70.311 | 19.3
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

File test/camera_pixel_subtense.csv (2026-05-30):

distance_m | fov_width_m | m_per_pixel | deg_per_pixel
1 | 1.1547005383792515 | 0.0018042195912175805 | 0.09375
3 | 3.4641016151377544 | 0.005412658773652742 | 0.09375
10 | 11.547005383792515 | 0.018042195912175804 | 0.09375
25 | 28.867513459481287 | 0.04510548978043951 | 0.09375

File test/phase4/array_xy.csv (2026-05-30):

mic_idx | arm_idx | x_mm | y_mm
0 | 0 | 25.0 | 0.0
1 | 0 | 41.8449 | 9.2594
2 | 0 | 56.8545 | 21.3025
3 | 0 | 70.311 | 35.069
4 | 0 | 82.4384 | 50.0238
5 | 0 | 93.4082 | 65.8494
6 | 0 | 103.3539 | 82.3389
7 | 0 | 112.3825 | 99.3488
8 | 1 | 21.6506 | 12.5
9 | 1 | 31.6091 | 28.9413
10 | 1 | 38.5862 | 46.8757
11 | 1 | 43.3566 | 65.5262
12 | 1 | 46.3819 | 84.5411
13 | 1 | 47.9692 | 103.7313
14 | 1 | 48.3377 | 122.9846
15 | 1 | 47.6517 | 142.2298
16 | 2 | 12.5 | 21.6506
17 | 2 | 12.9036 | 40.8685
18 | 2 | 9.9788 | 59.8886
19 | 2 | 4.7848 | 78.4256
20 | 2 | -2.1027 | 96.4056
21 | 2 | -10.3231 | 113.8185
22 | 2 | -19.6306 | 130.6766
23 | 2 | -29.8473 | 147.0005
24 | 3 | 0.0 | 25.0
25 | 3 | -9.2594 | 41.8449
26 | 3 | -21.3025 | 56.8545
27 | 3 | -35.069 | 70.311
28 | 3 | -50.0238 | 82.4384
29 | 3 | -65.8494 | 93.4082
30 | 3 | -82.3389 | 103.3539
31 | 3 | -99.3488 | 112.3825
32 | 4 | -12.5 | 21.6506
33 | 4 | -28.9413 | 31.6091
34 | 4 | -46.8757 | 38.5862
35 | 4 | -65.5262 | 43.3566
36 | 4 | -84.5411 | 46.3819
37 | 4 | -103.7313 | 47.9692
38 | 4 | -122.9846 | 48.3377
39 | 4 | -142.2298 | 47.6517
40 | 5 | -21.6506 | 12.5
41 | 5 | -40.8685 | 12.9036
42 | 5 | -59.8886 | 9.9788
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

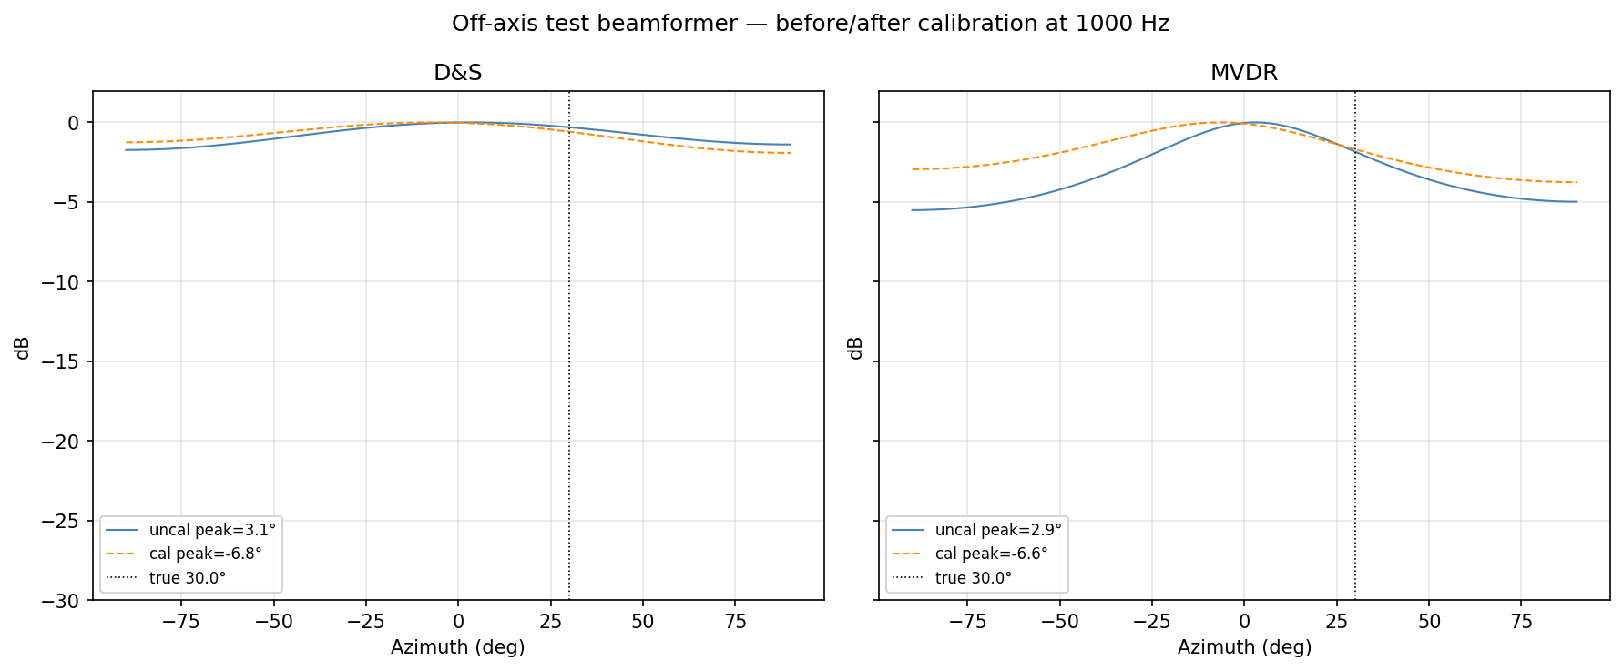
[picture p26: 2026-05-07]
notebooks/respeaker_cal_doa_test.png

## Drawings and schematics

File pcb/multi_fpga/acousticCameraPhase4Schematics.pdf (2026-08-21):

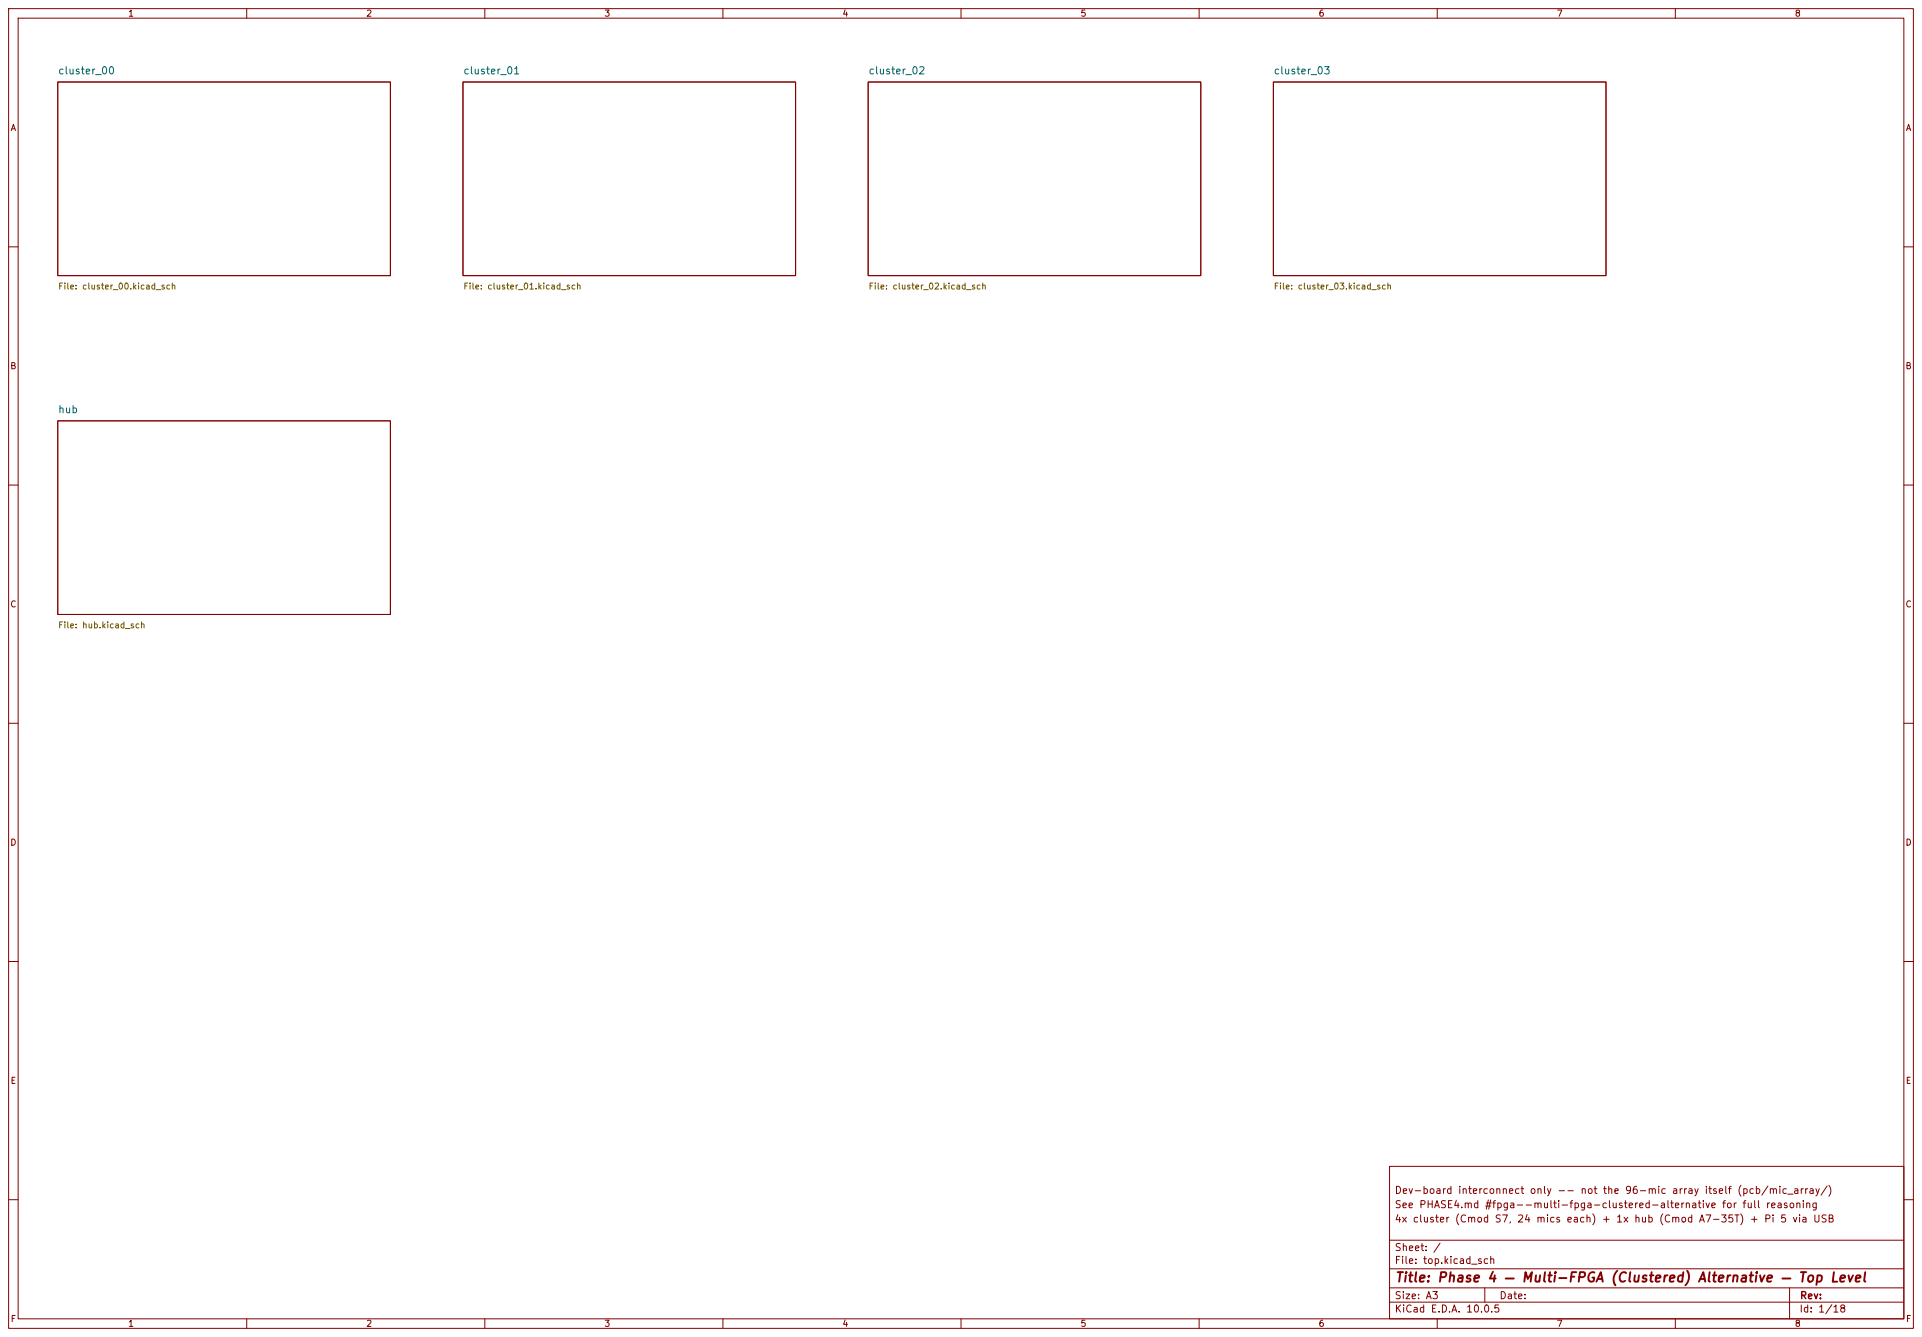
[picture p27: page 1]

Dev-board interconnect only -- not the 96-mic array itself (pcb/mic_array/)
See PHASE4.md #fpga--multi-fpga-clustered-alternative for full reasoning
4x cluster (Cmod S7, 24 mics each) + 1x hub (Cmod A7-35T) + Pi 5 via USB

Sheet: /
File: top.kicad_sch
Title: Phase 4 — Multi-FPGA (Clustered) Alternative — Top Level

Size: A3 | Rev: | F Date:
KiCad E.D.A. 10.0.5 | Id: 1/18

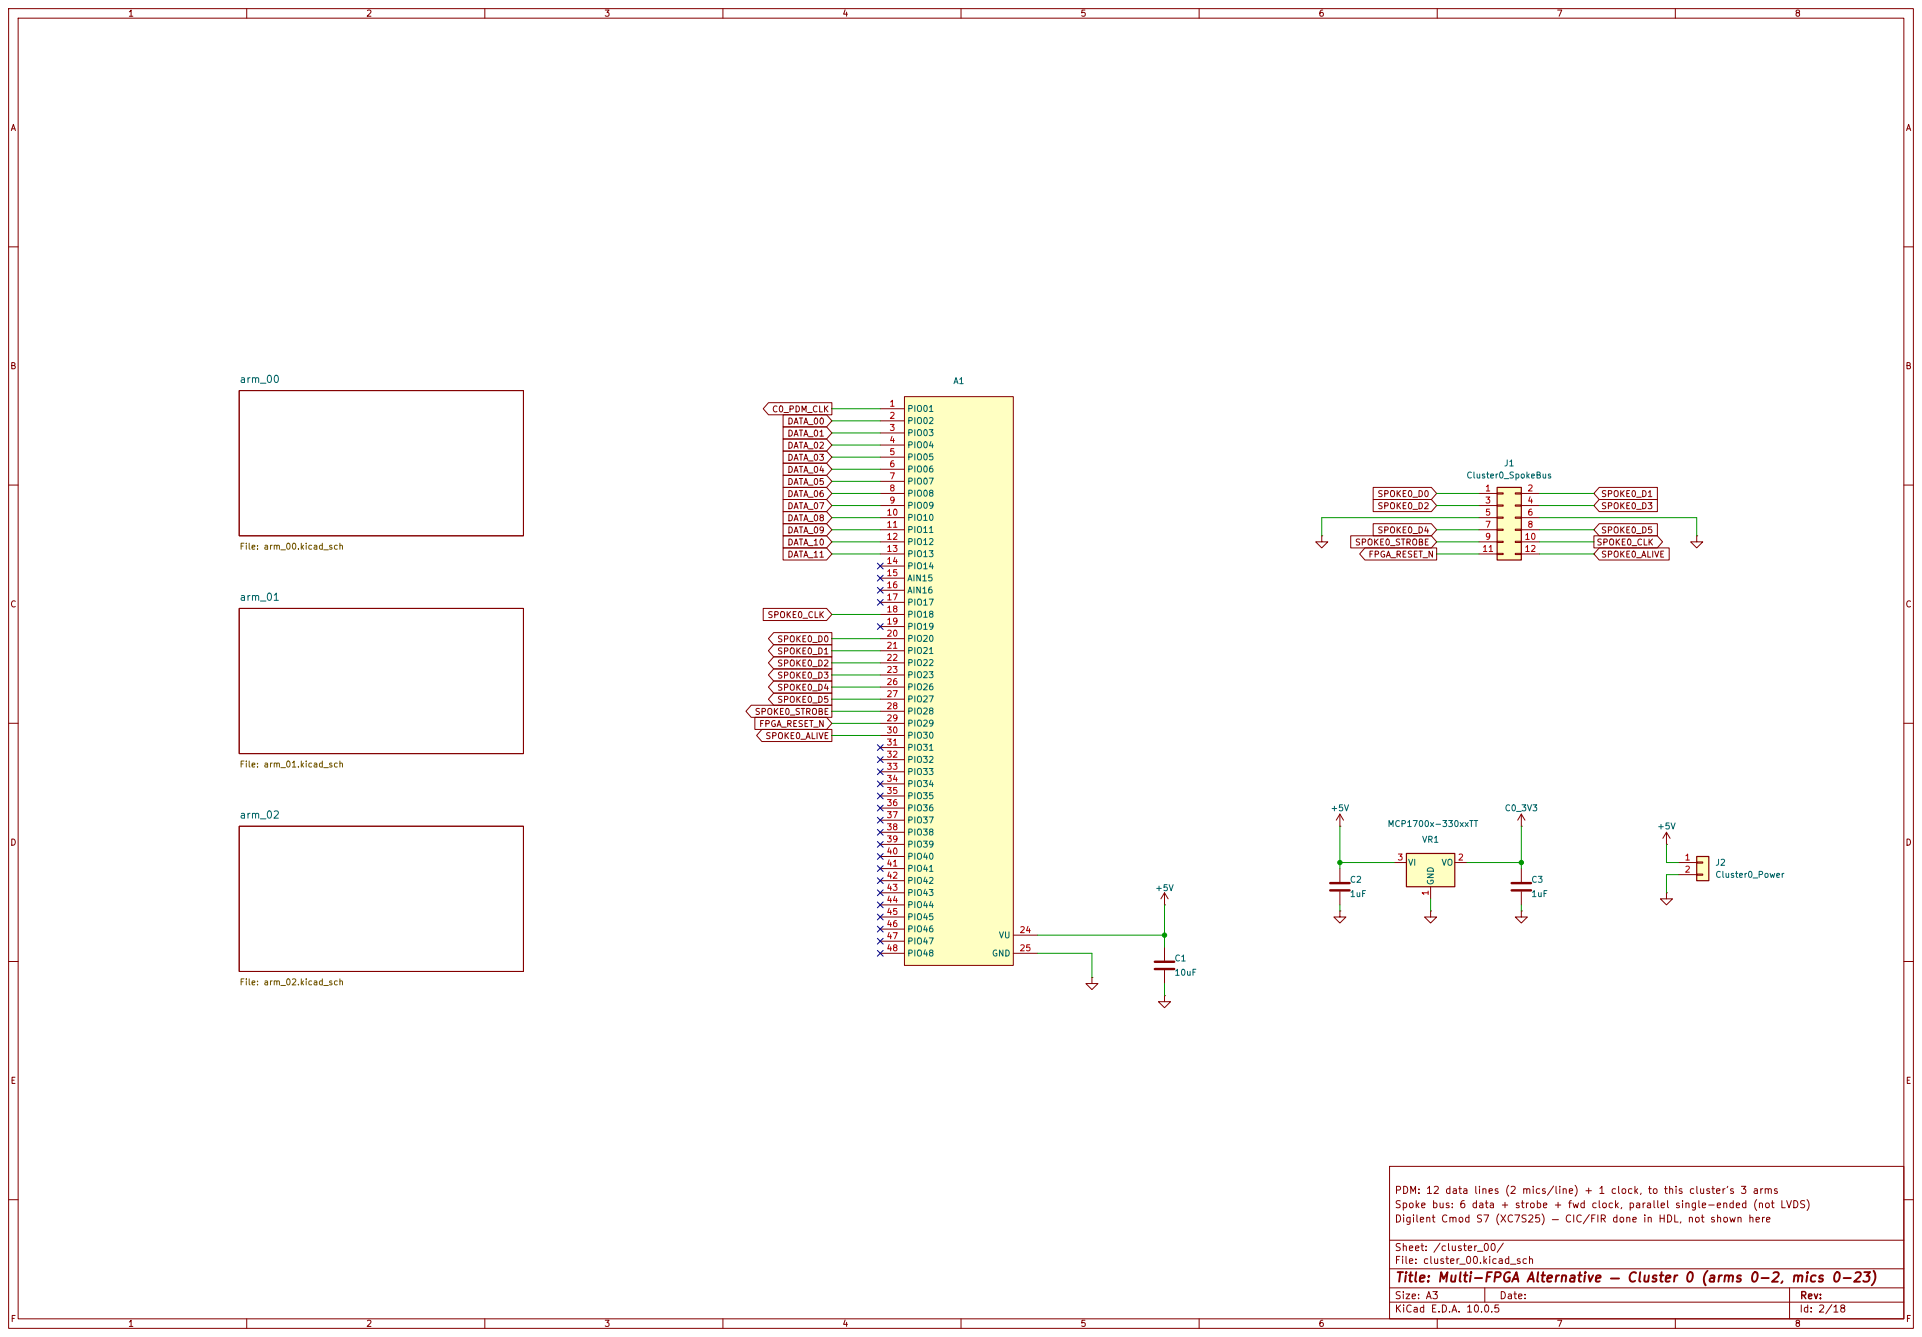
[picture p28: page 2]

PDM: 12 data lines (2 mics/line) + 1 clock, to this cluster's 3 arms arm_02

Spoke bus: 6 data + strobe + fwd clock, parallel single-ended (not LVDS)
Digilent Cmod S7 (XC7S25) — CIC/FIR done in HDL, not shown here

Sheet: /cluster_00/
File: cluster_00.kicad_sch
Title: Multi-FPGA Alternative — Cluster 0 (arms 0-2, mics 0-23)

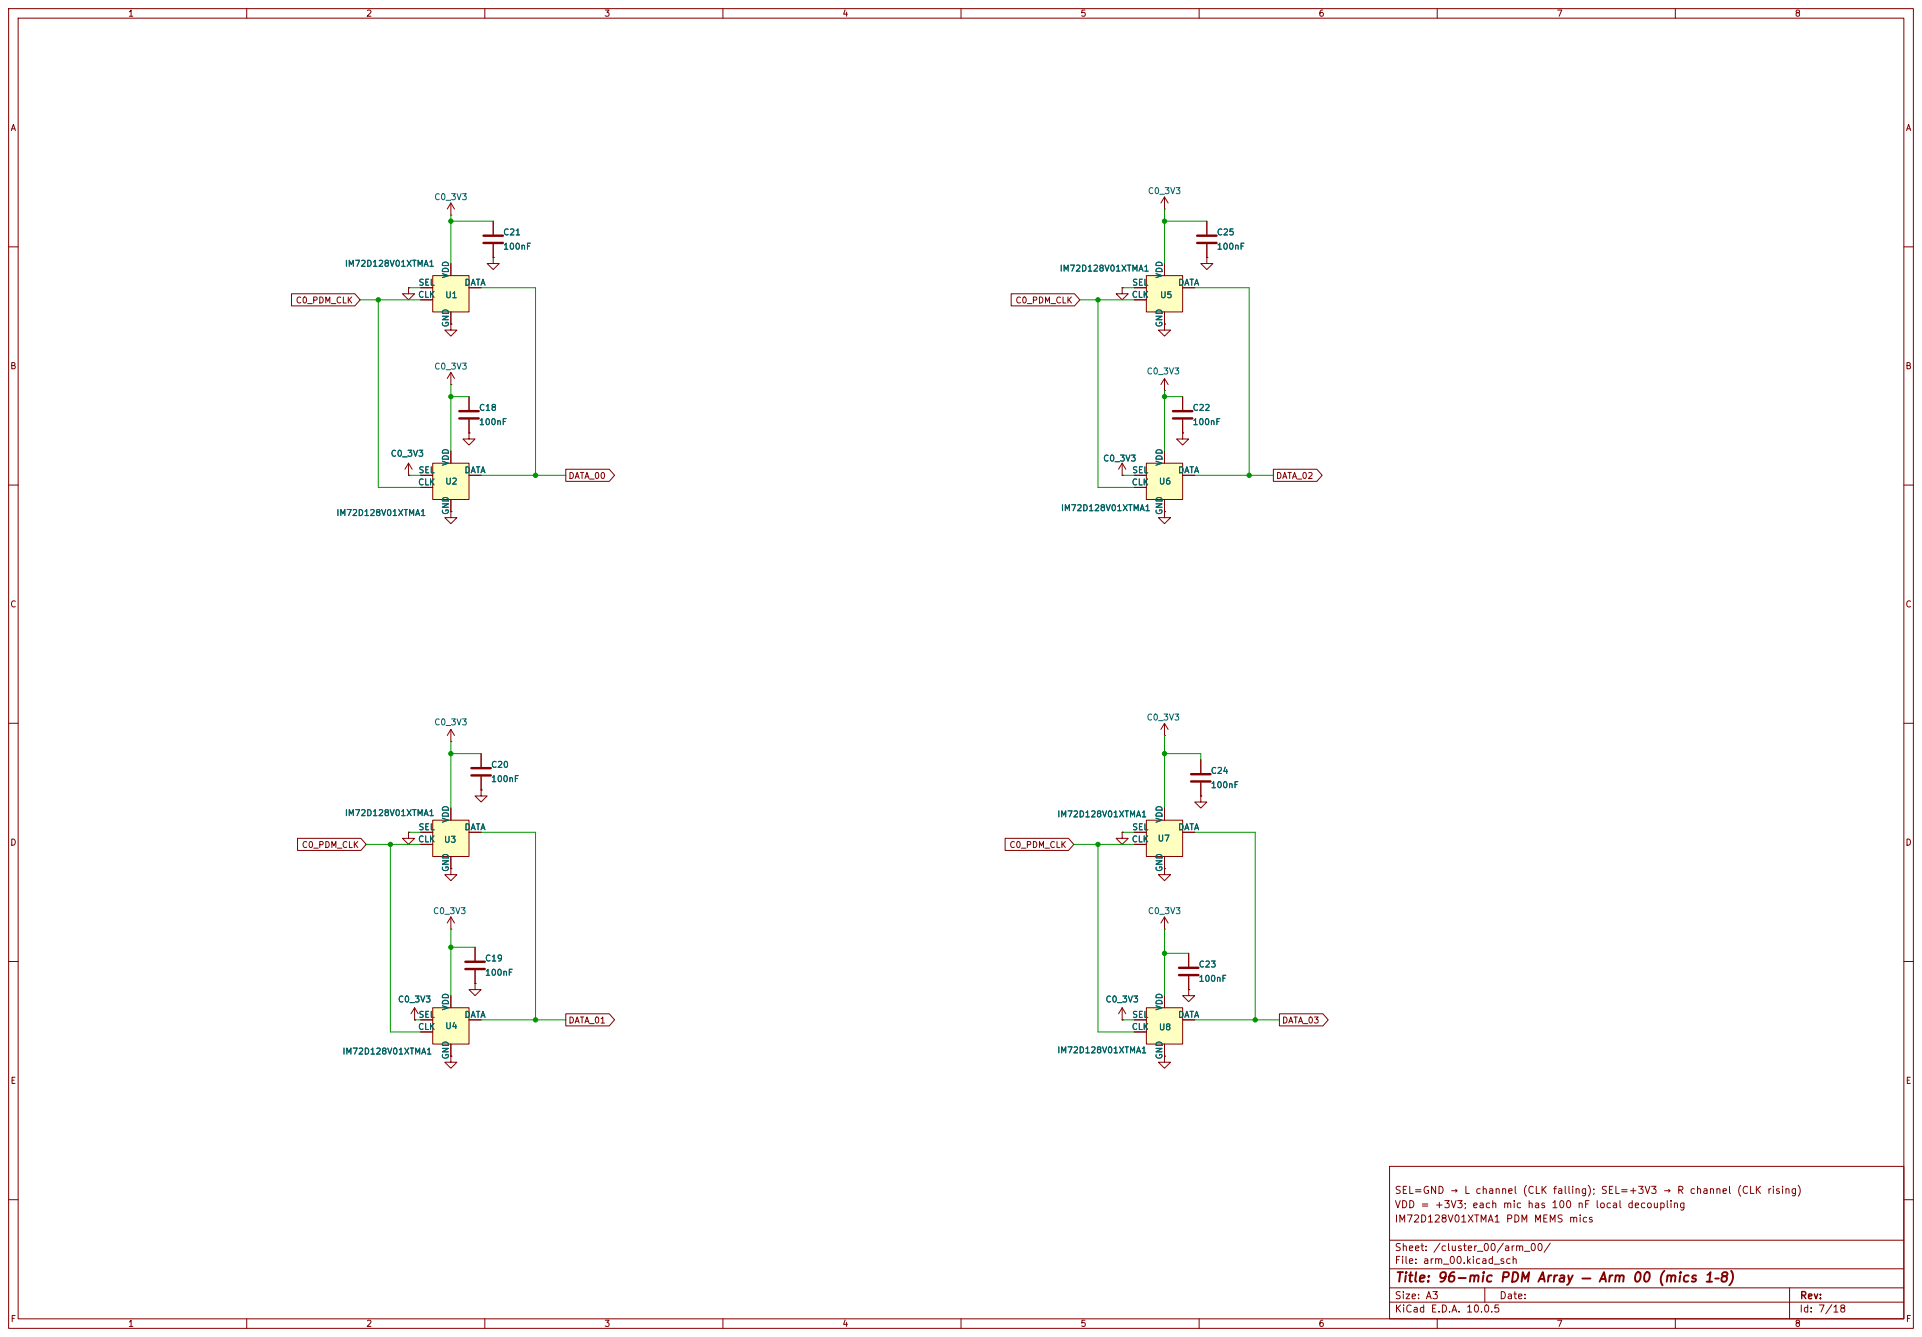
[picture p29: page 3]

SEL=GND → L channel (CLK falling); SEL=+3V3 → R channel (CLK rising)
VDD = +3V3; each mic has 100 nF local decoupling
IM72D128V01XTMA1 PDM MEMS mics

Sheet: /cluster_00/arm_00/
File: arm_00.kicad_sch
Title: 96-mic PDM Array — Arm 00 (mics 1–8)

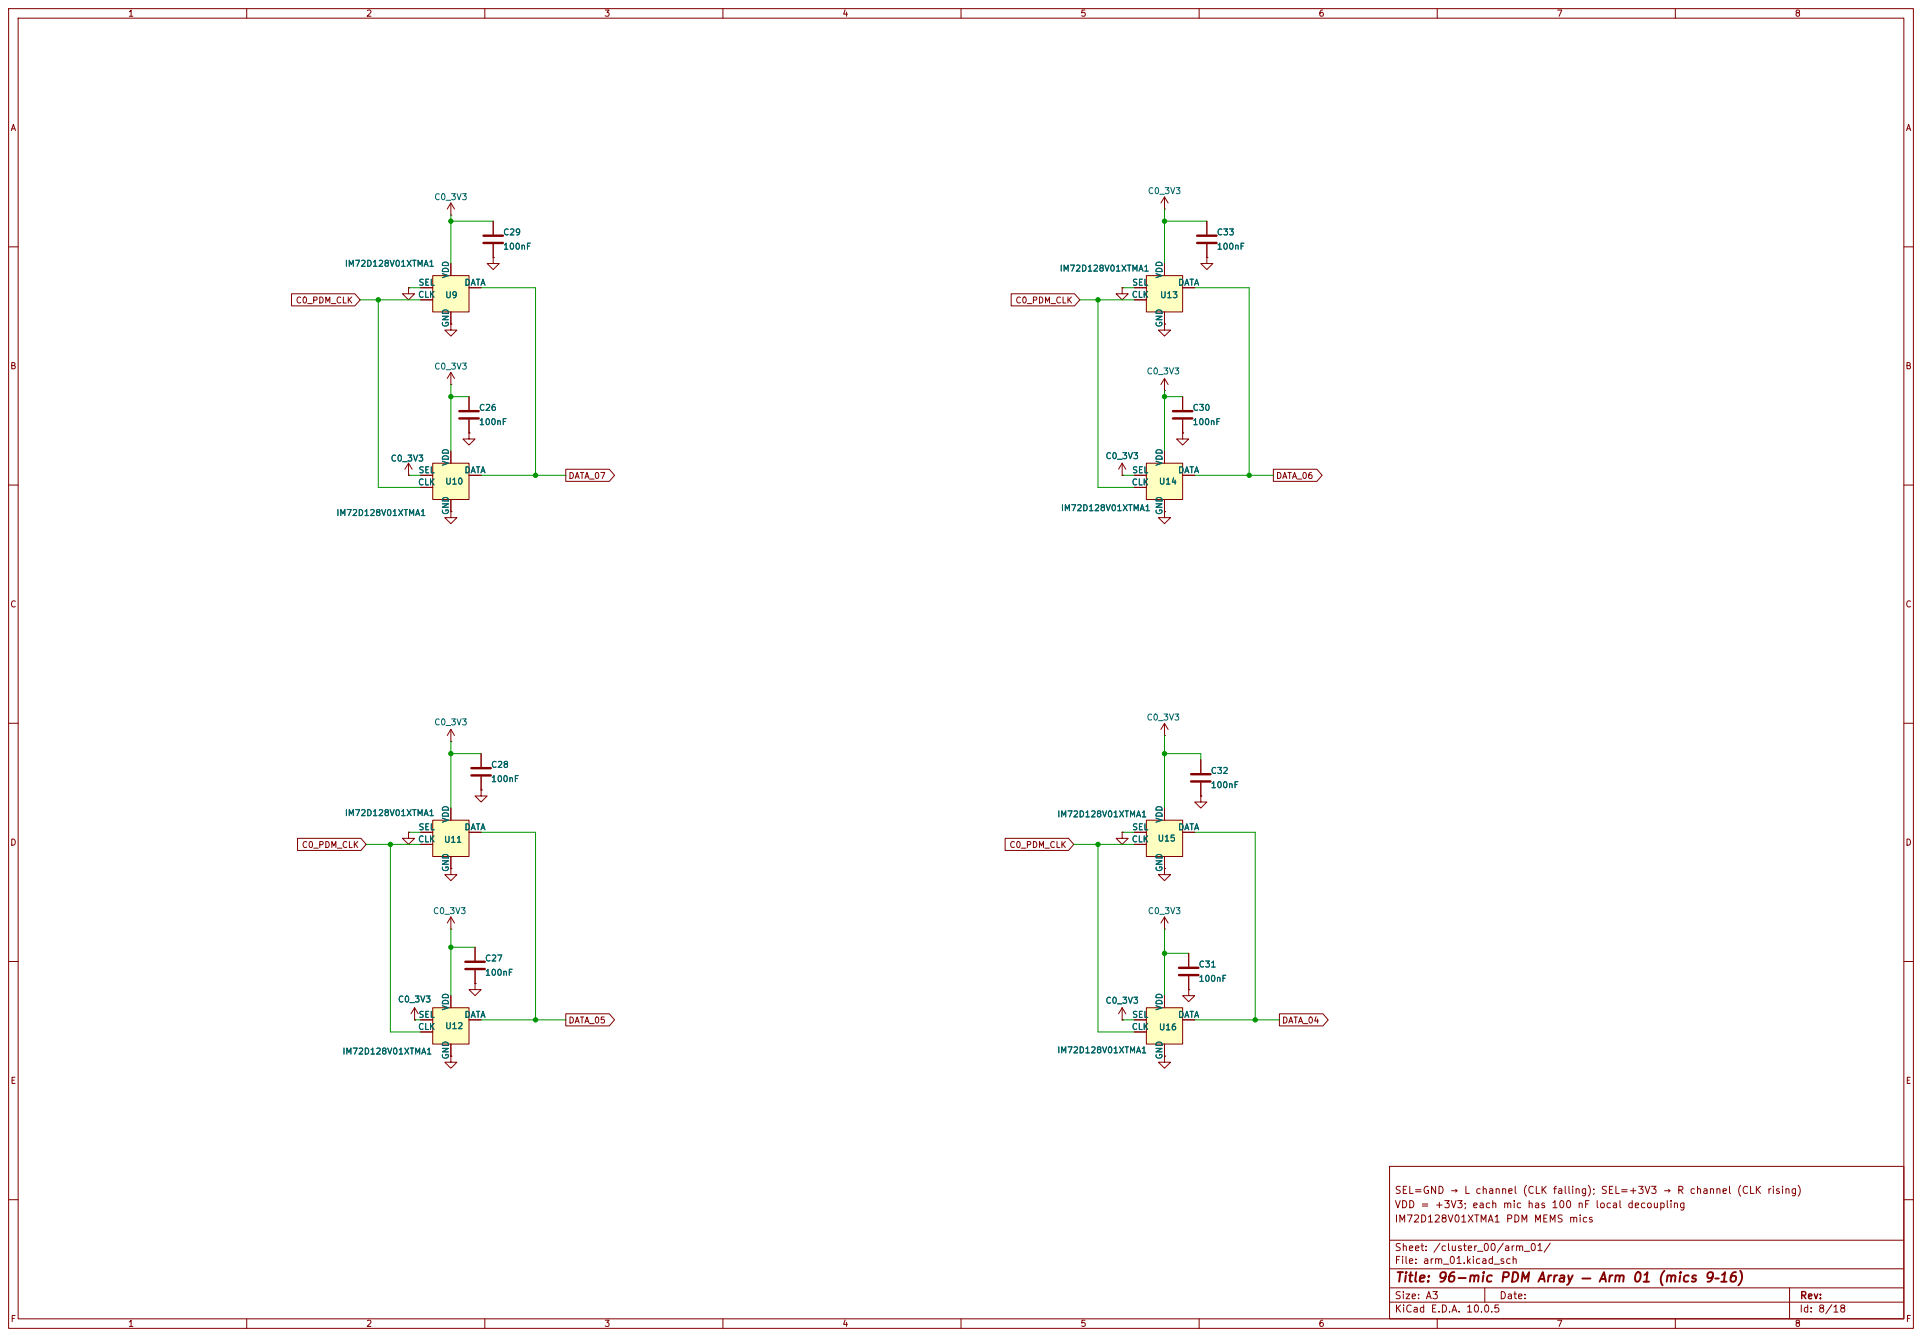
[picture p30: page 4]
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

Sheet: /cluster_00/arm_01/
File: arm_01.kicad_sch
Title: 96-mic PDM Array — Arm 01 (mics 9–16)

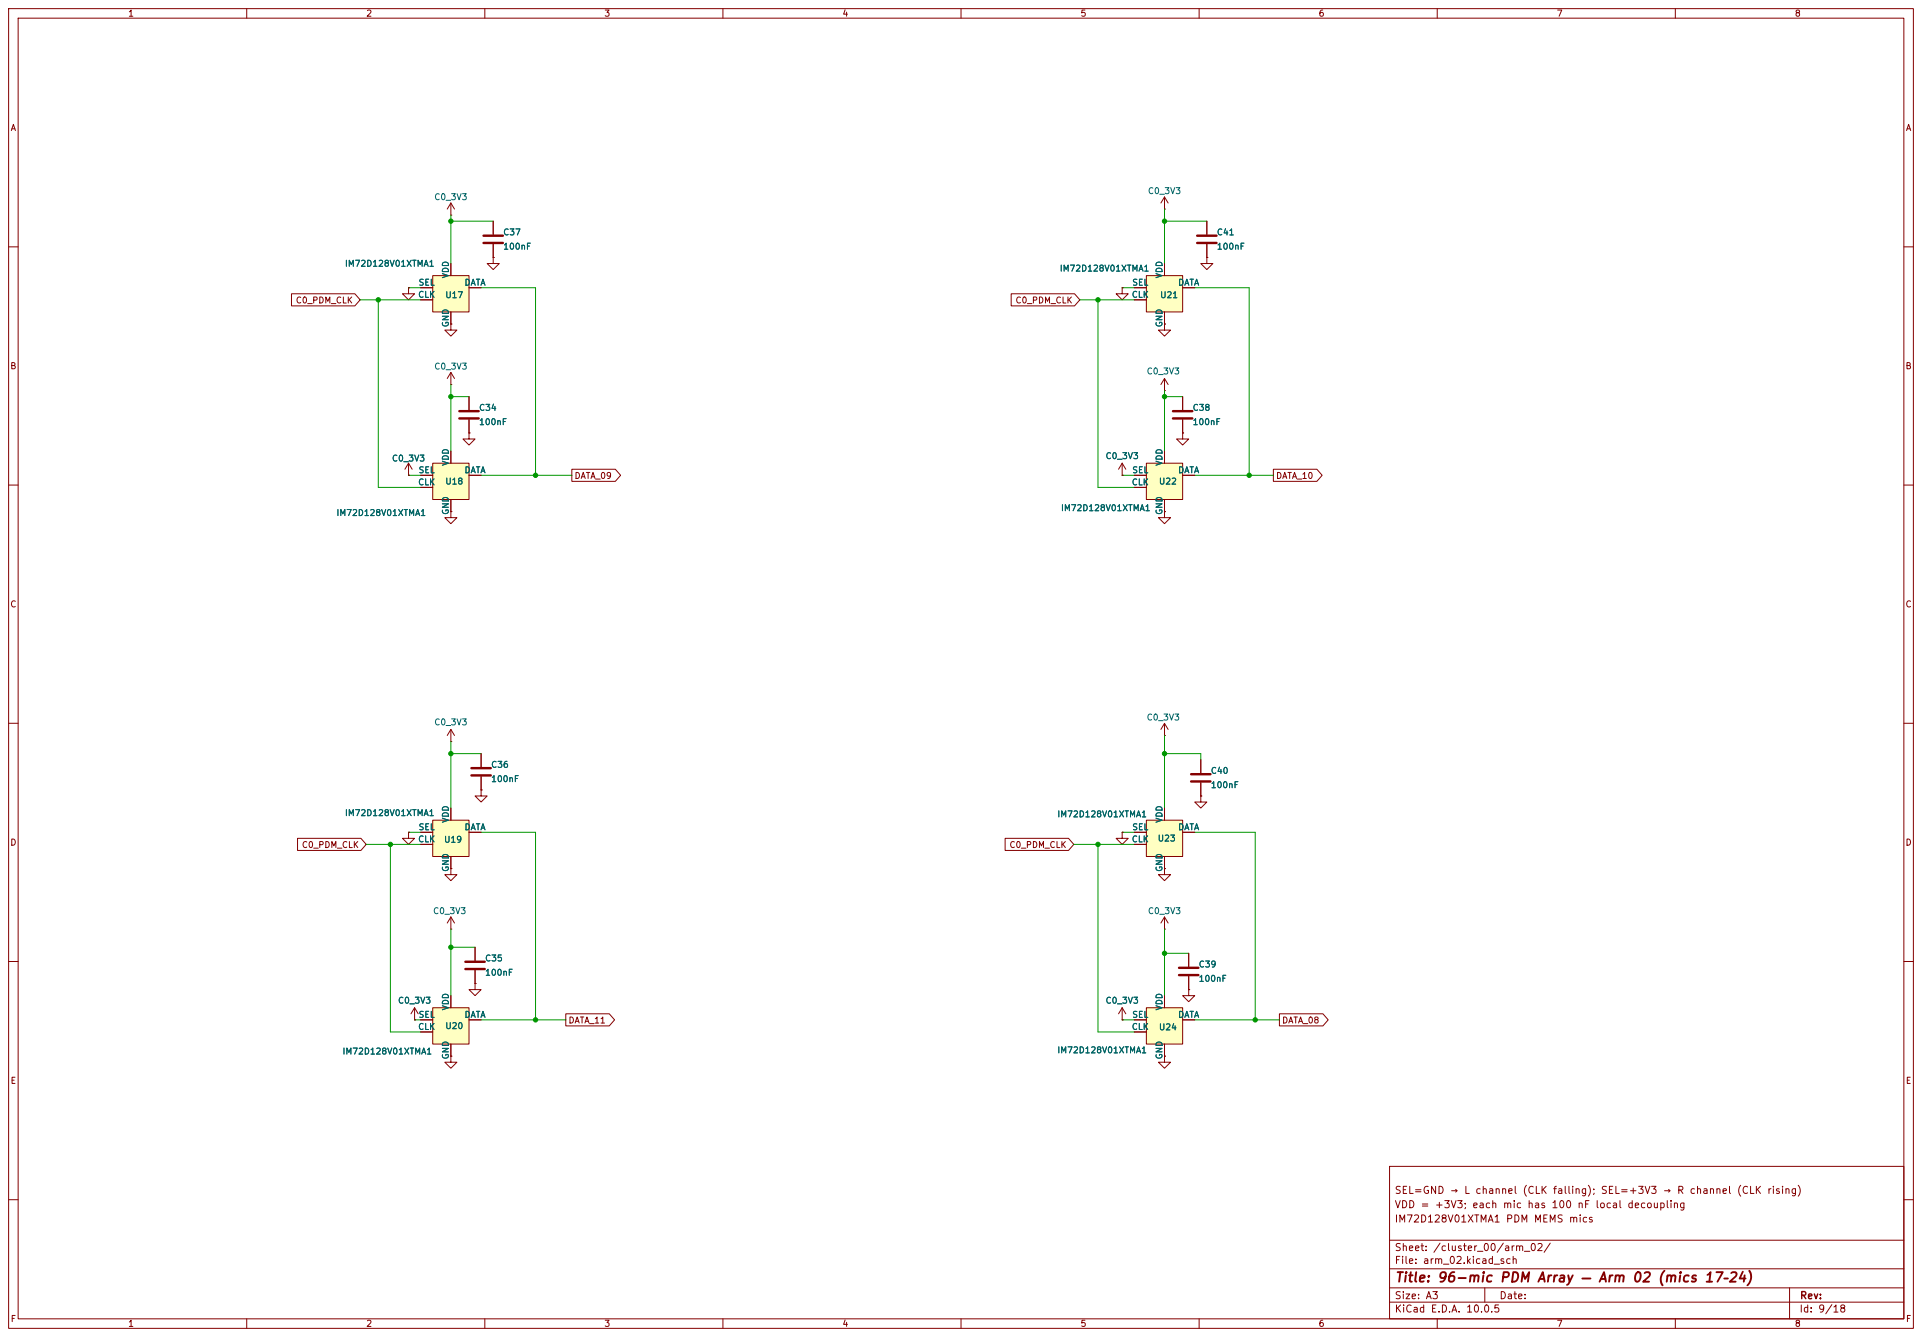
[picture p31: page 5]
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

Sheet: /cluster_00/arm_02/
File: arm_02.kicad_sch
Title: 96-mic PDM Array — Arm 02 (mics 17–24)

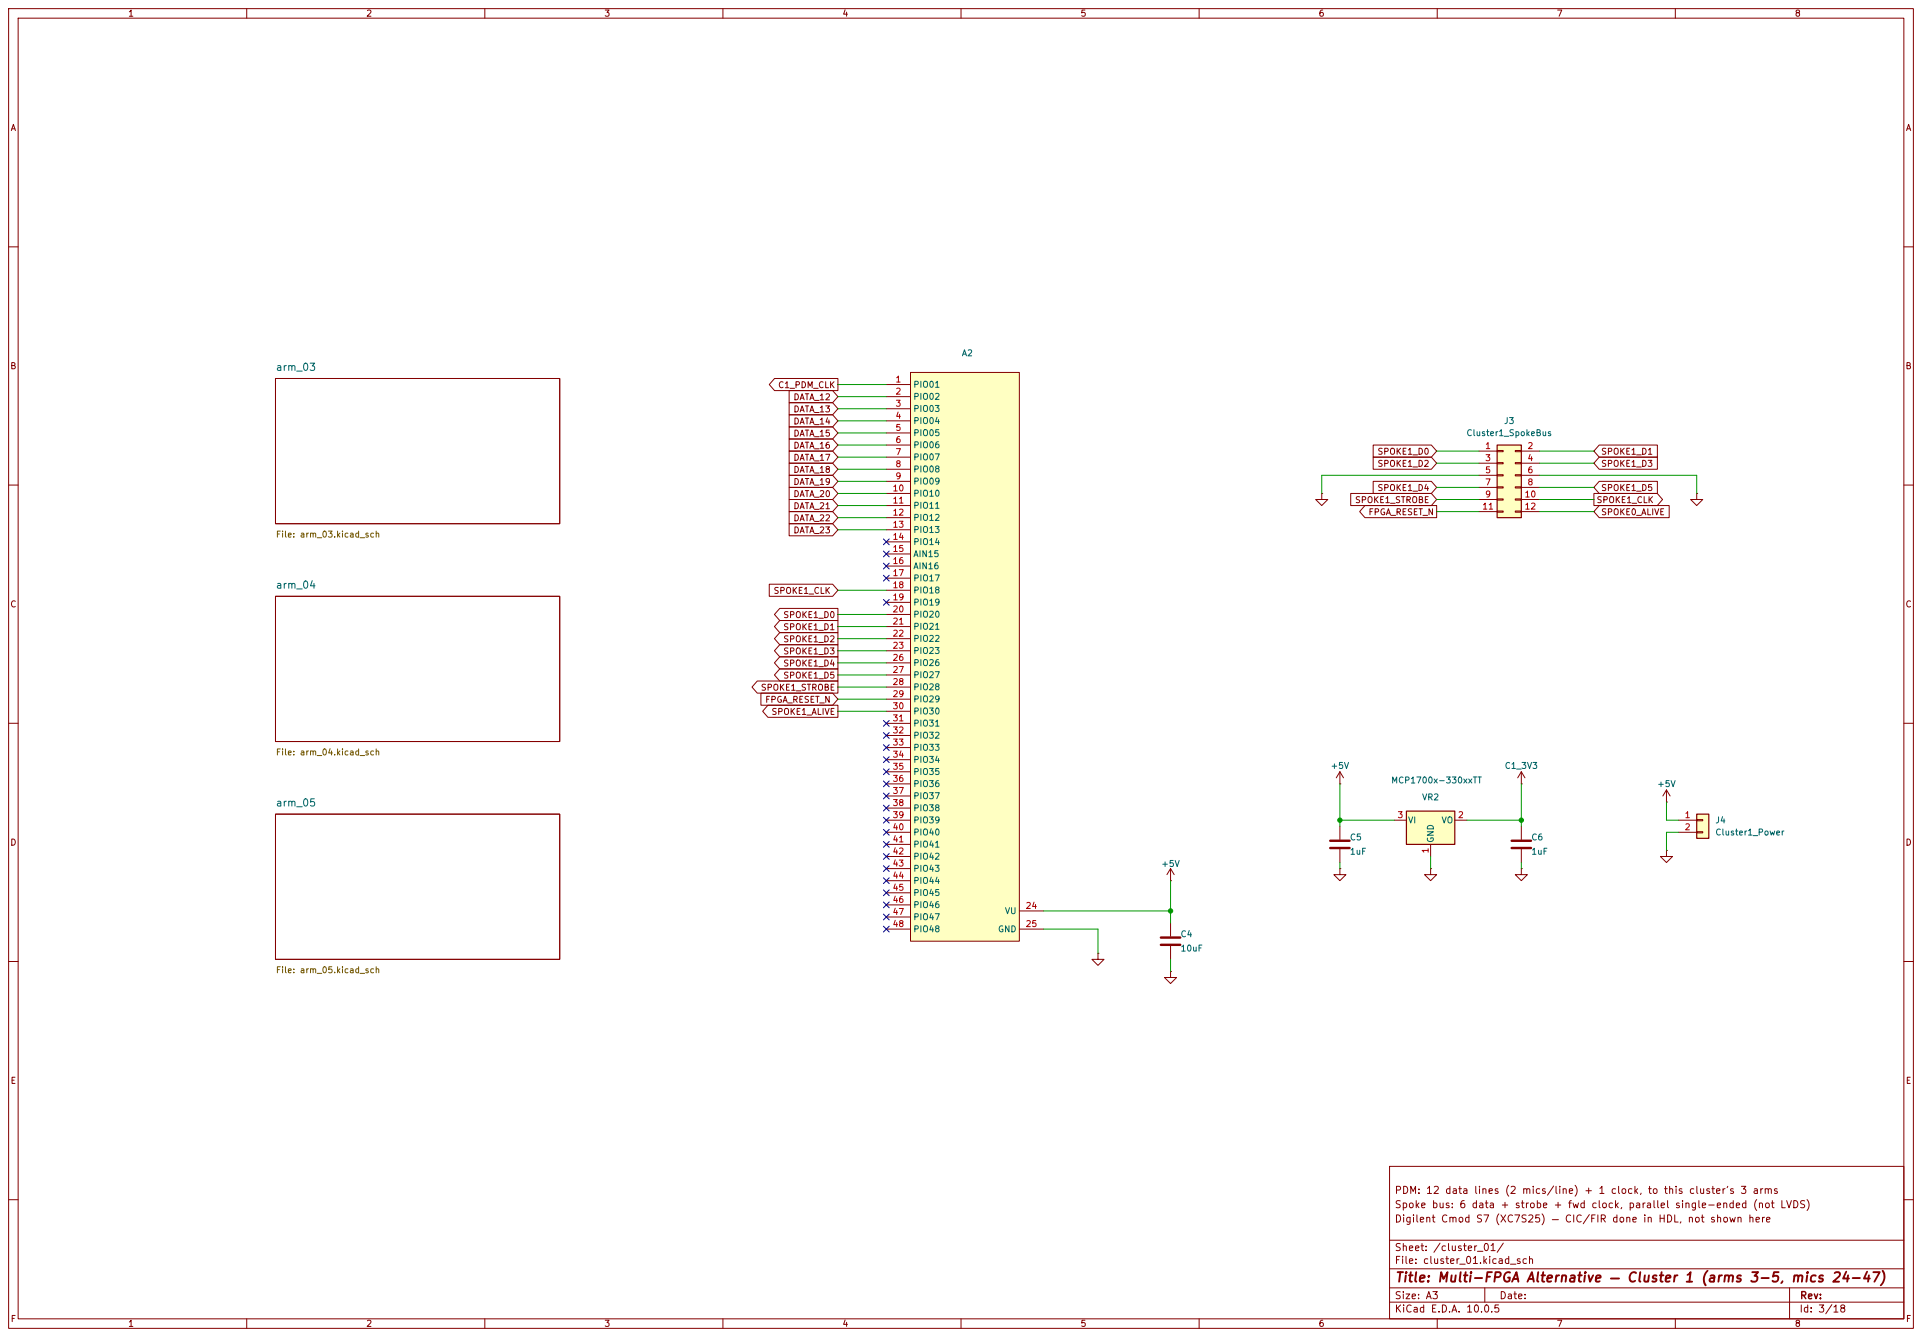
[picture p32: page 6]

PDM: 12 data lines (2 mics/line) + 1 clock, to this cluster's 3 arms
Spoke bus: 6 data + strobe + fwd clock, parallel single-ended (not LVDS)
Digilent Cmod S7 (XC7S25) — CIC/FIR done in HDL, not shown here

Sheet: /cluster_01/
File: cluster_01.kicad_sch
Title: Multi-FPGA Alternative — Cluster 1 (arms 3-5, mics 24-47)

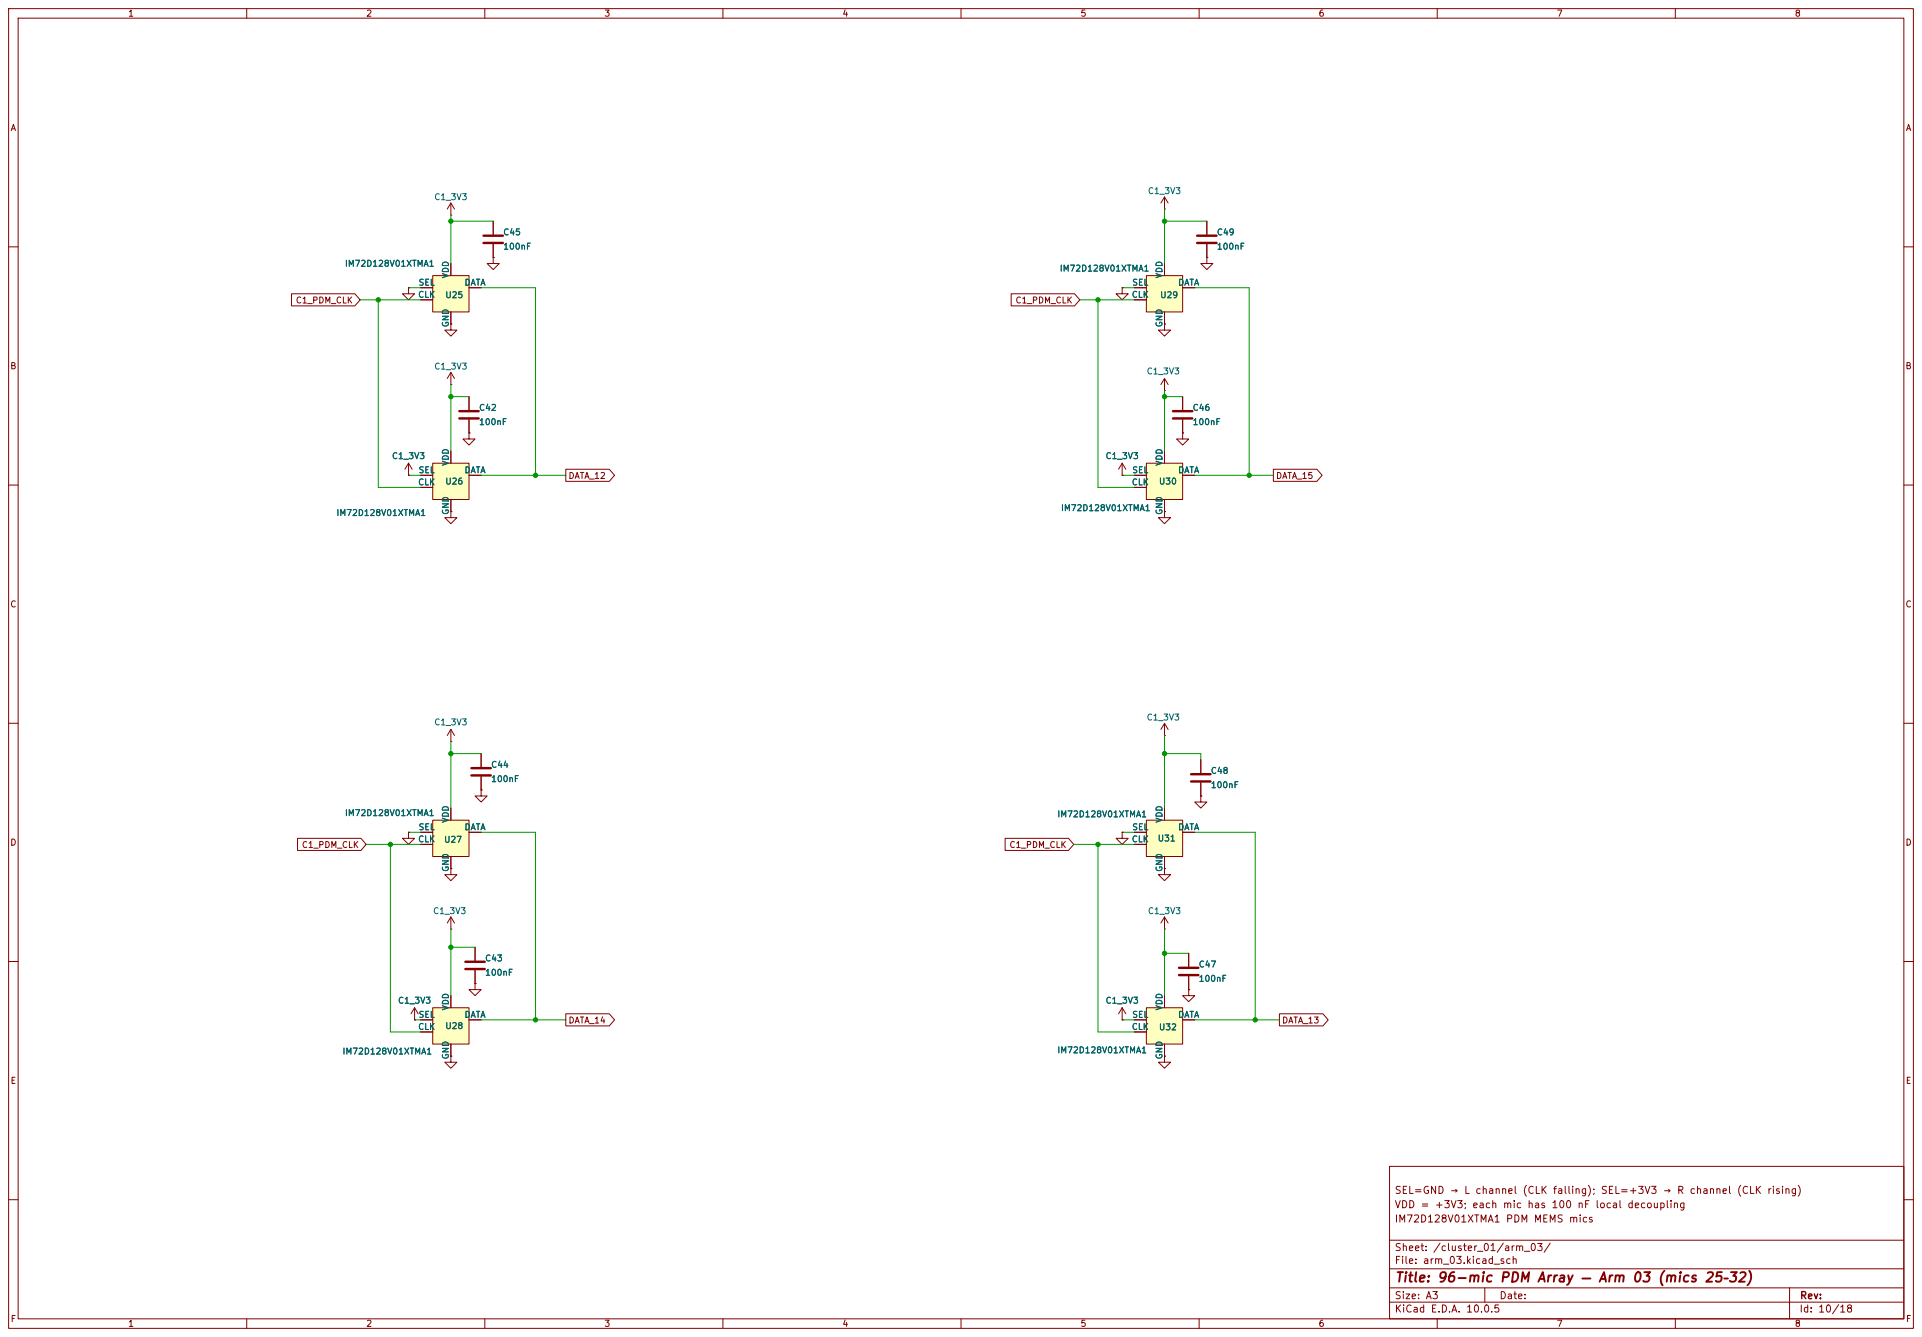
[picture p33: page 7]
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

Sheet: /cluster_01/arm_03/
File: arm_03.kicad_sch
Title: 96-mic PDM Array — Arm 03 (mics 25–32)

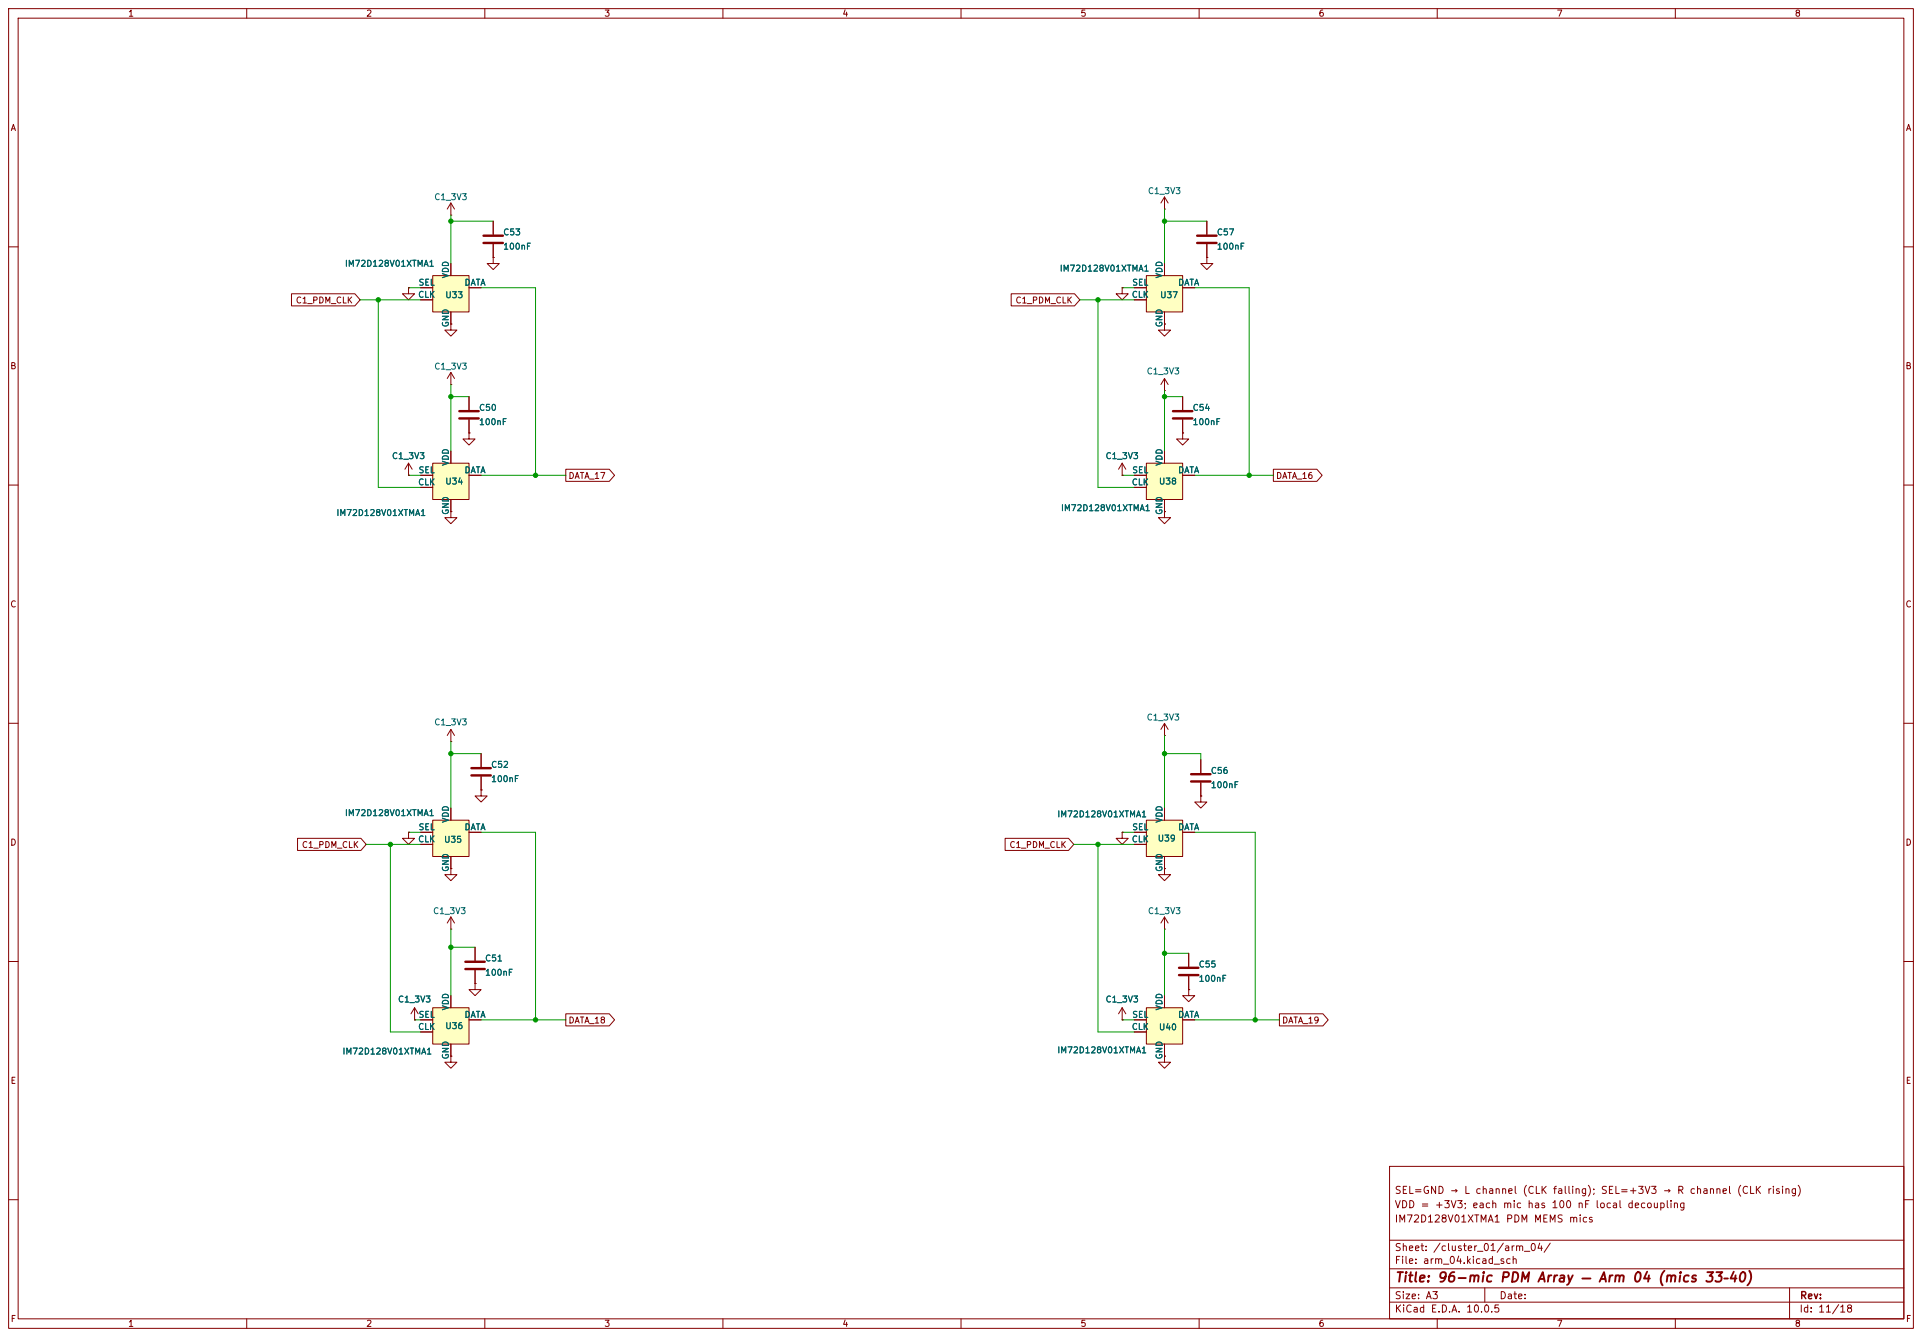
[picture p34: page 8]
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

Sheet: /cluster_01/arm_04/
File: arm_04.kicad_sch
Title: 96-mic PDM Array — Arm 04 (mics 33–40)

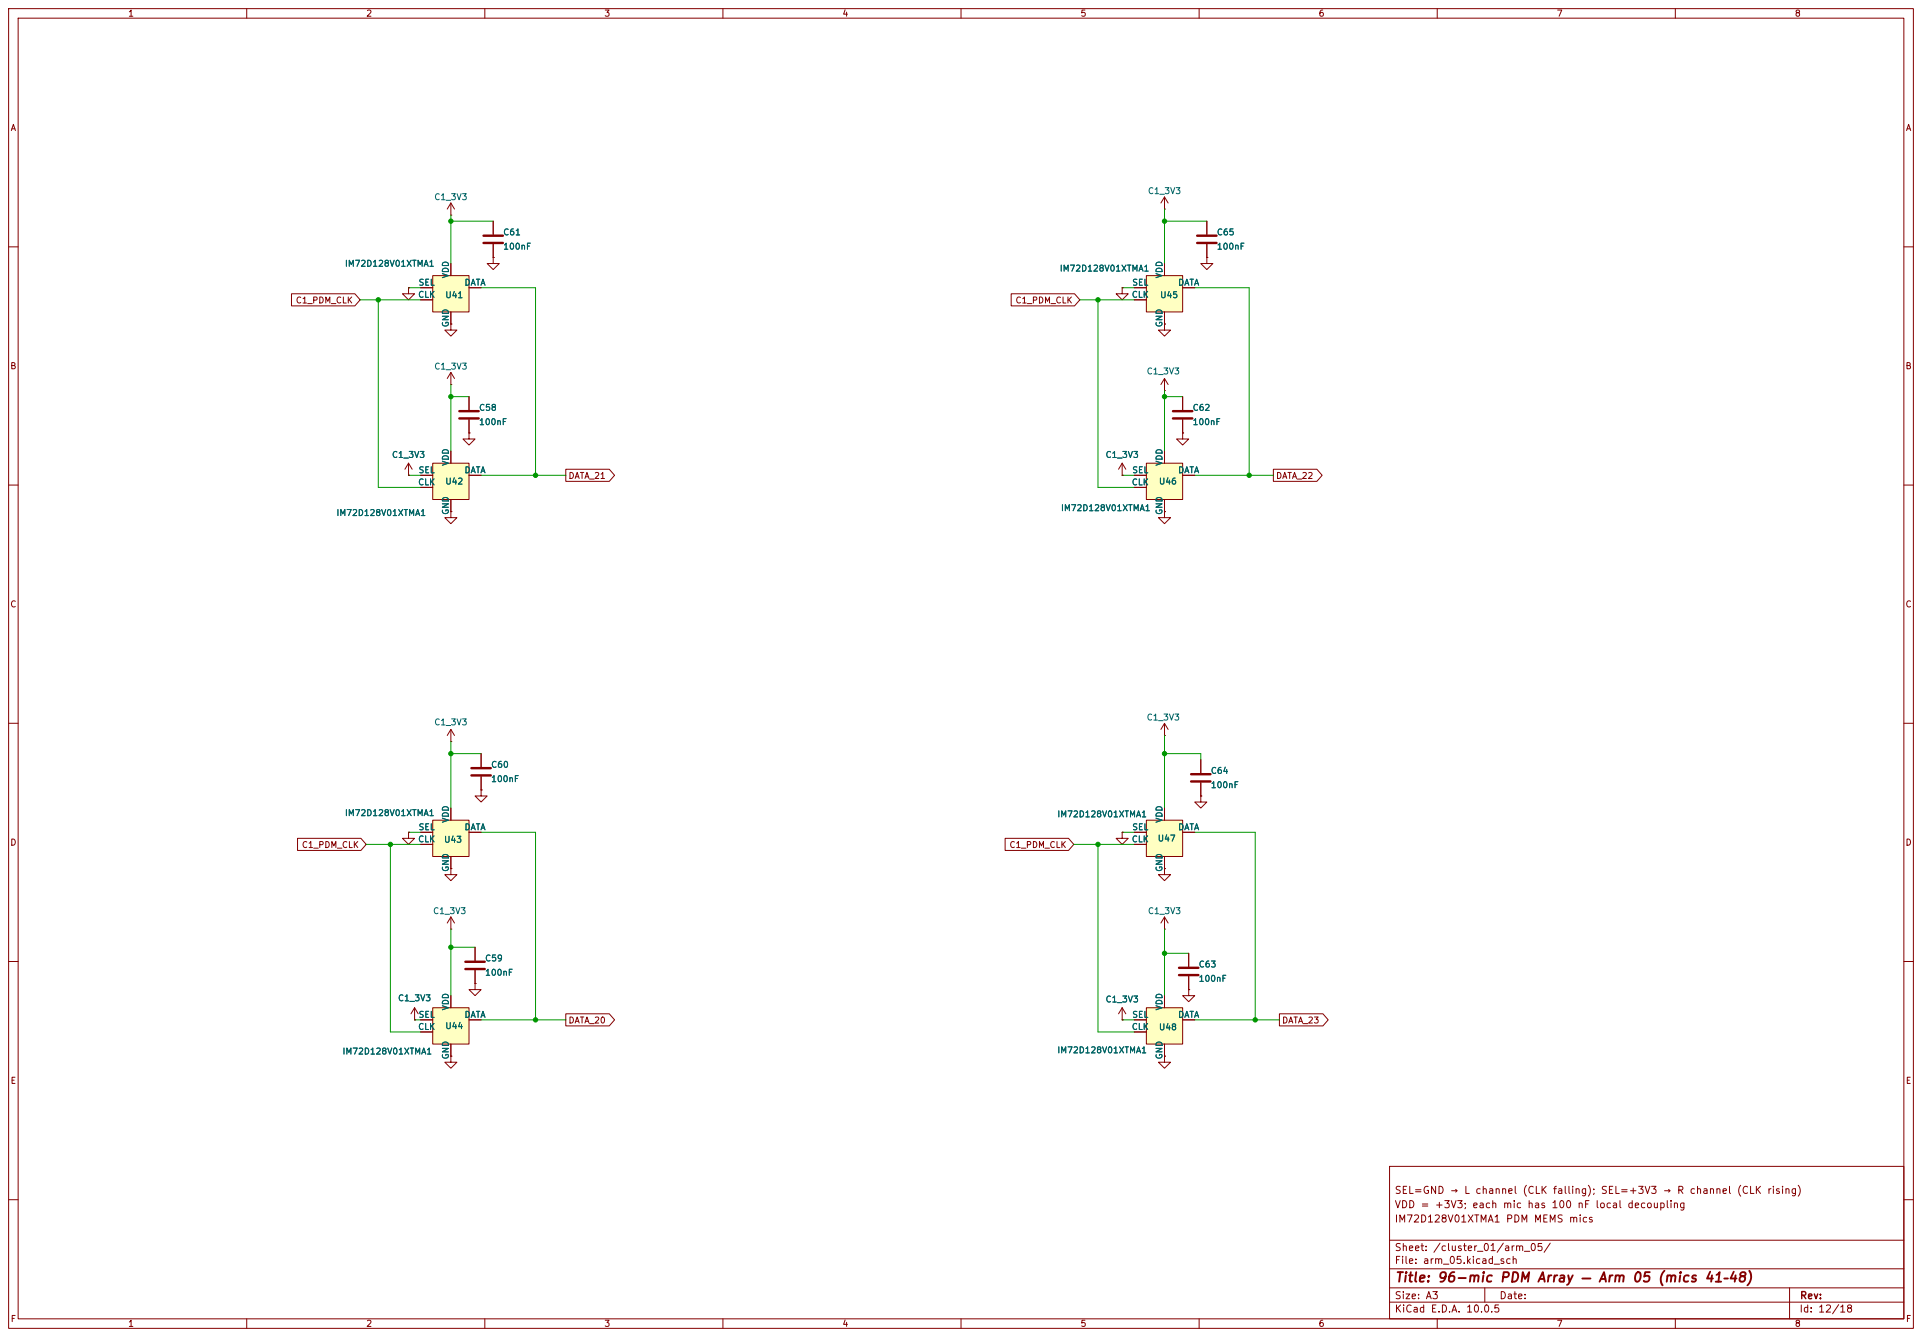
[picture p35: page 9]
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

Sheet: /cluster_01/arm_05/
File: arm_05.kicad_sch
Title: 96-mic PDM Array — Arm 05 (mics 41–48)

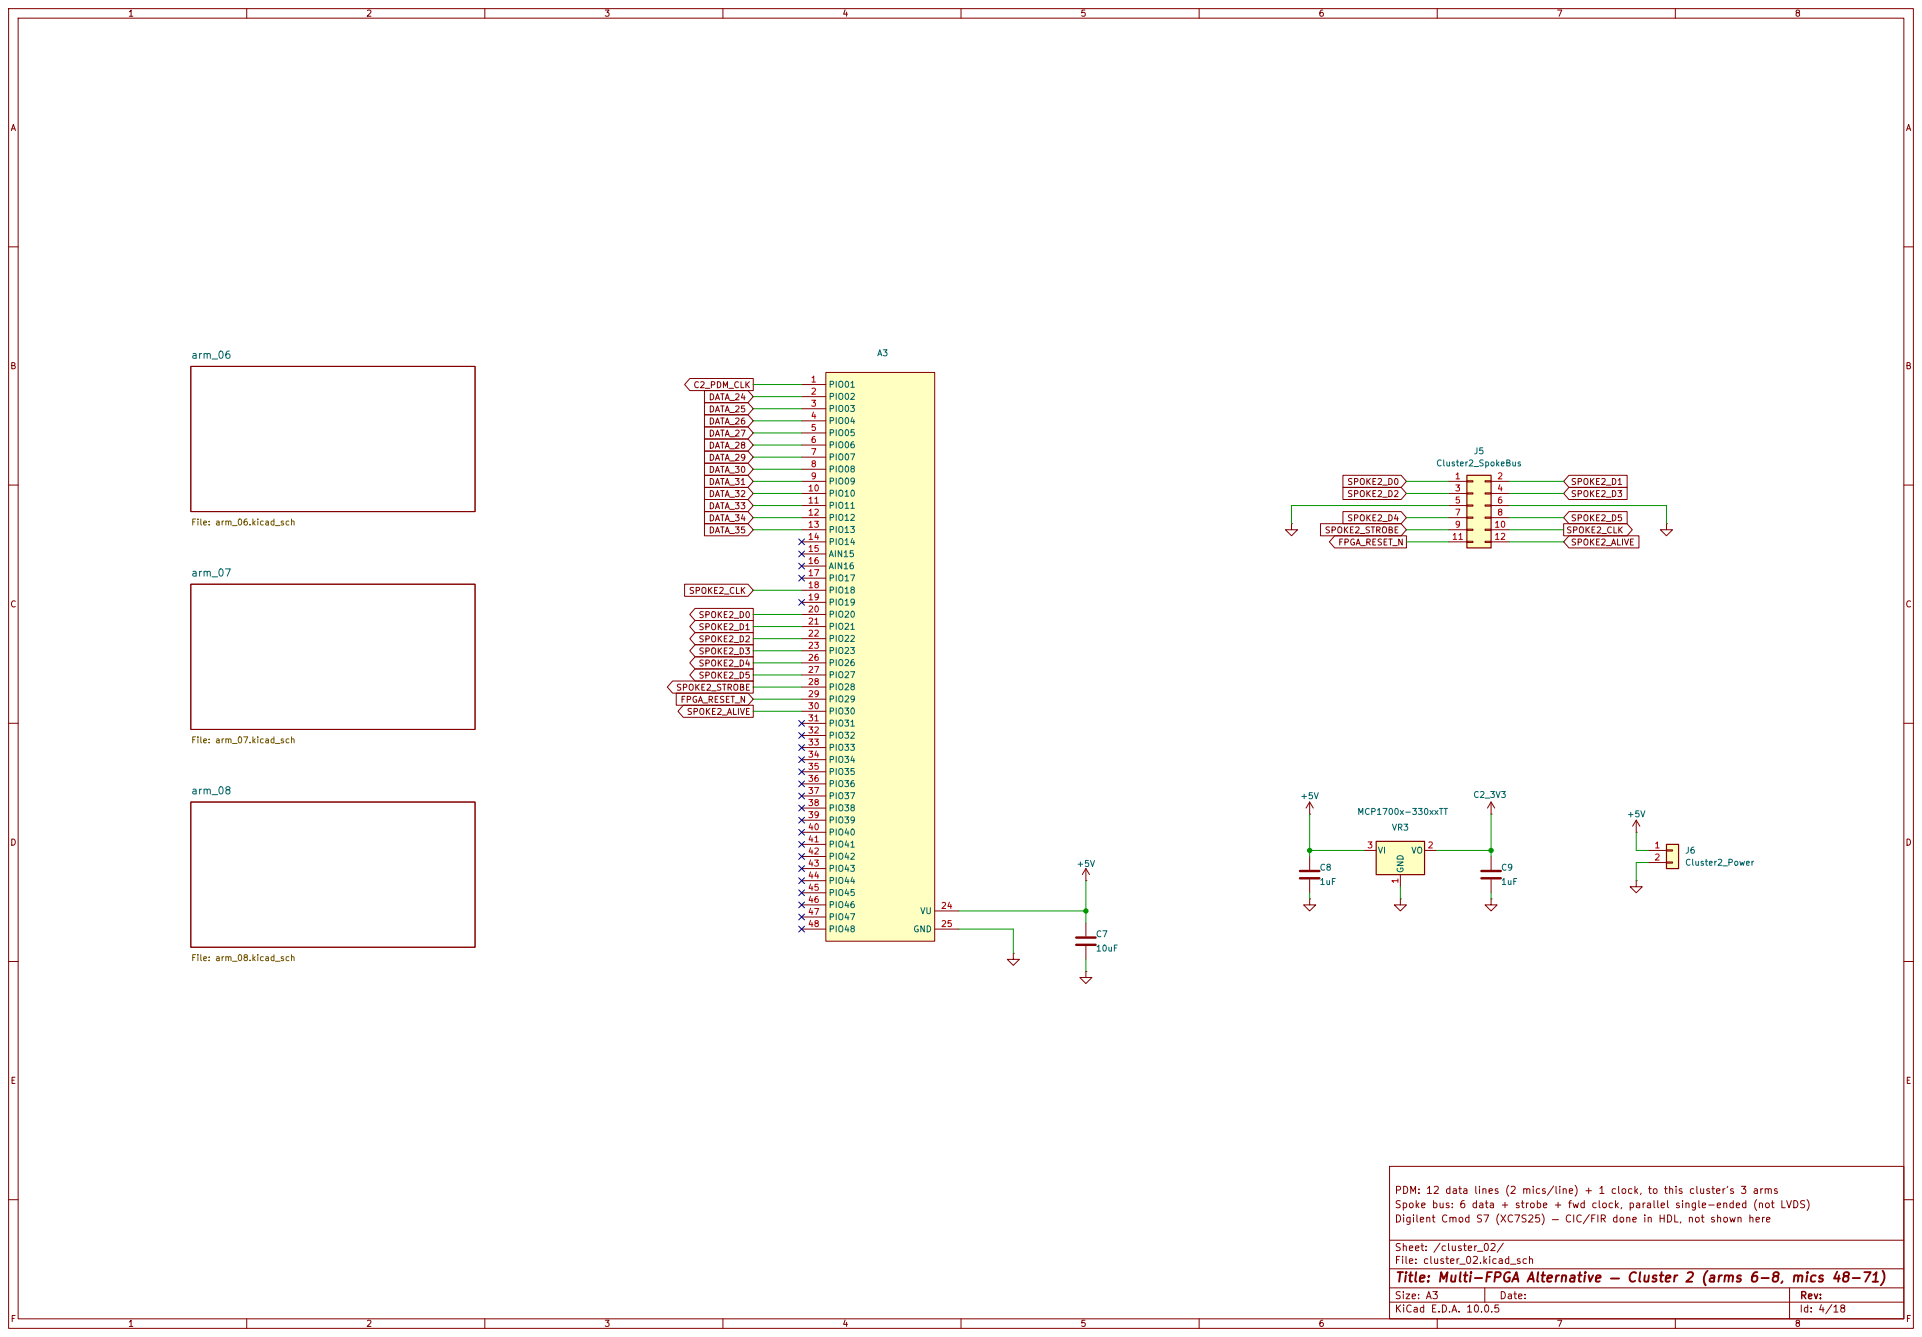
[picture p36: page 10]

PDM: 12 data lines (2 mics/line) + 1 clock, to this cluster's 3 arms arm_08

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

Sheet: /cluster_02/
File: cluster_02.kicad_sch
Title: Multi-FPGA Alternative — Cluster 2 (arms 6-8, mics 48-71)

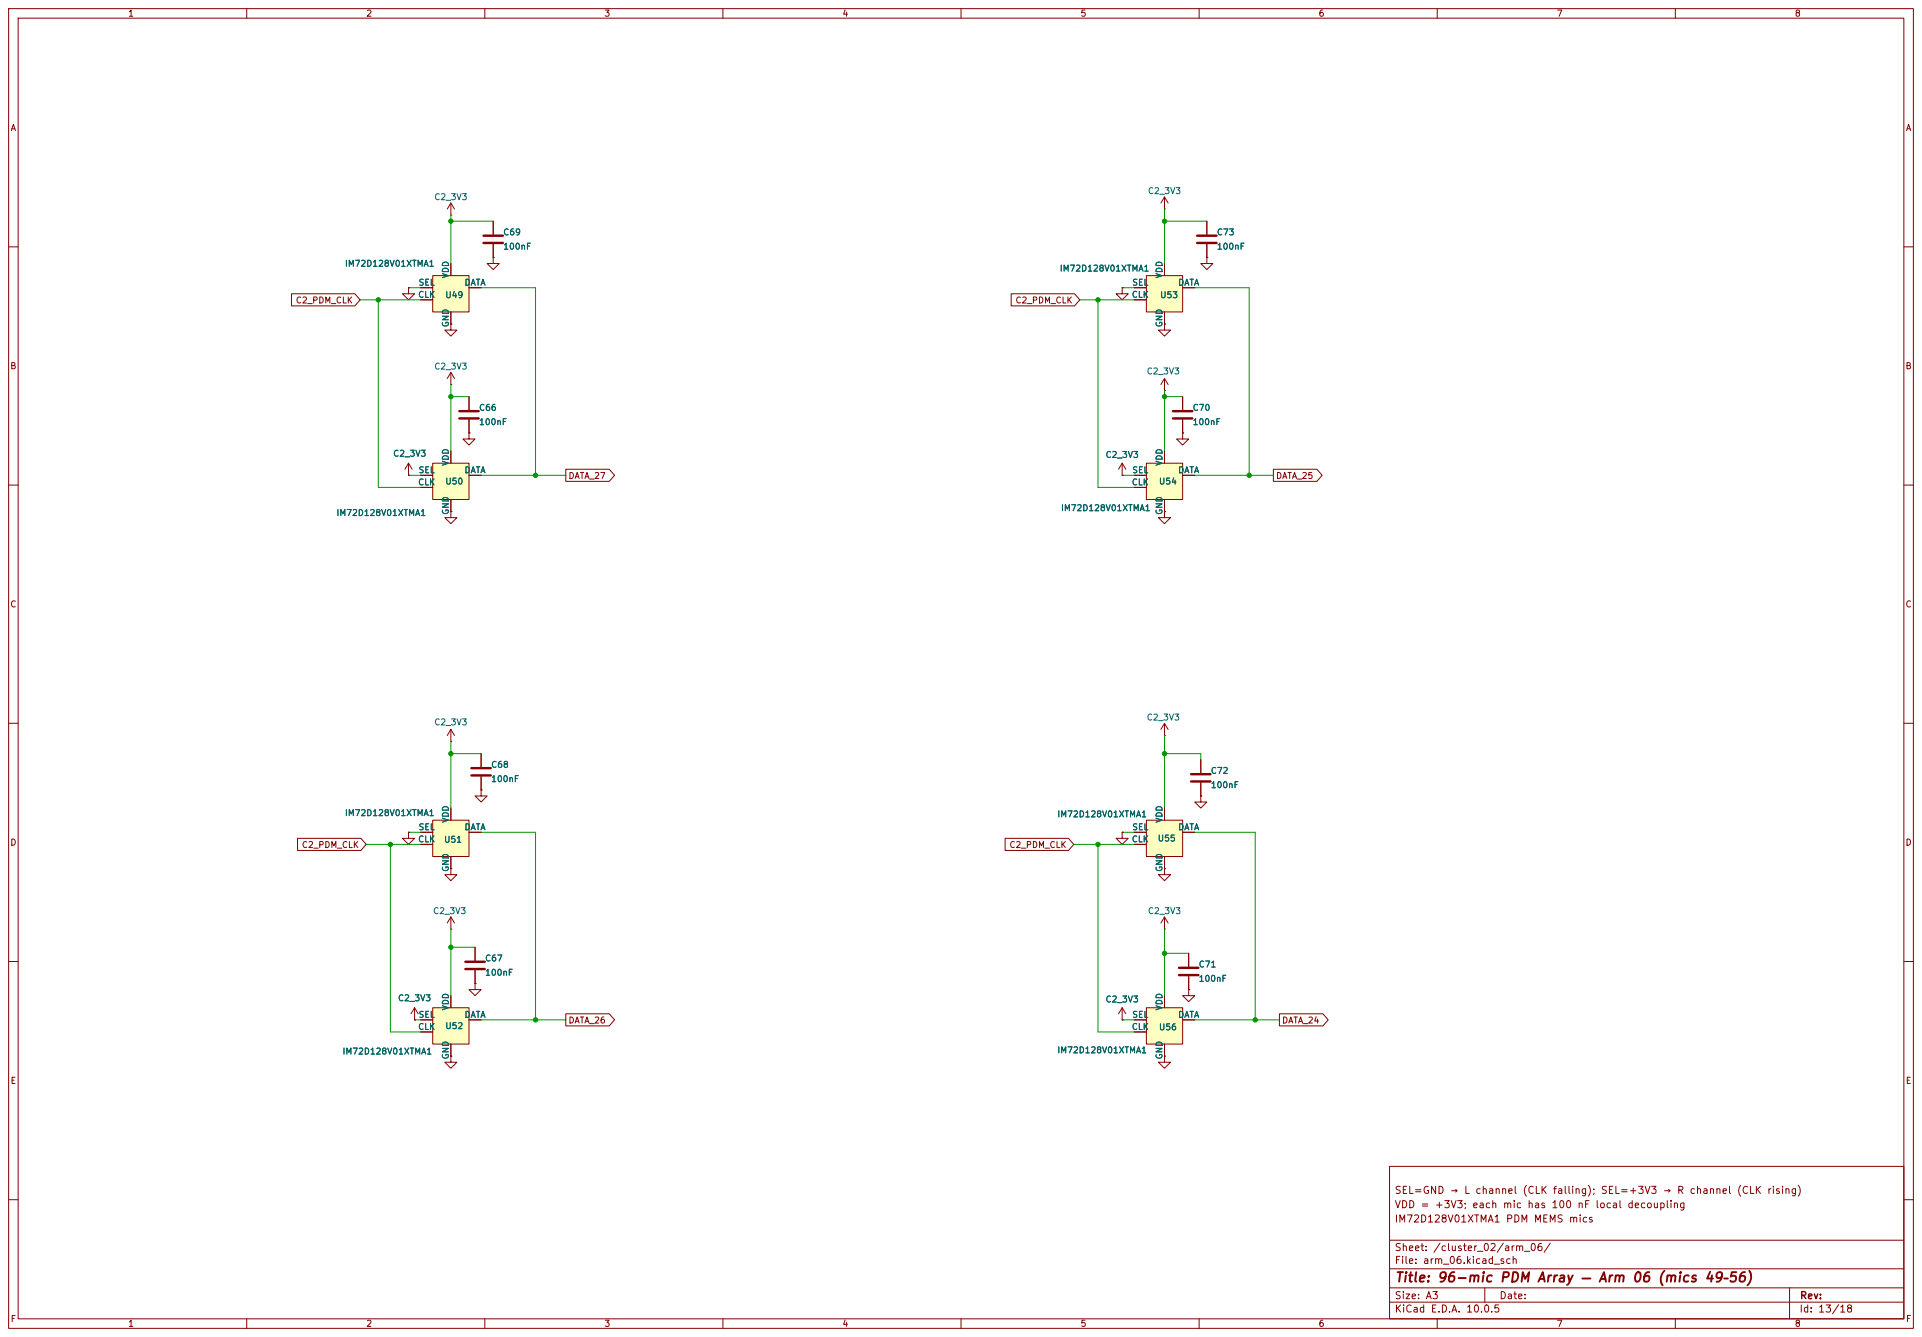
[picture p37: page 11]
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

Sheet: /cluster_02/arm_06/
File: arm_06.kicad_sch
Title: 96-mic PDM Array — Arm 06 (mics 49–56)

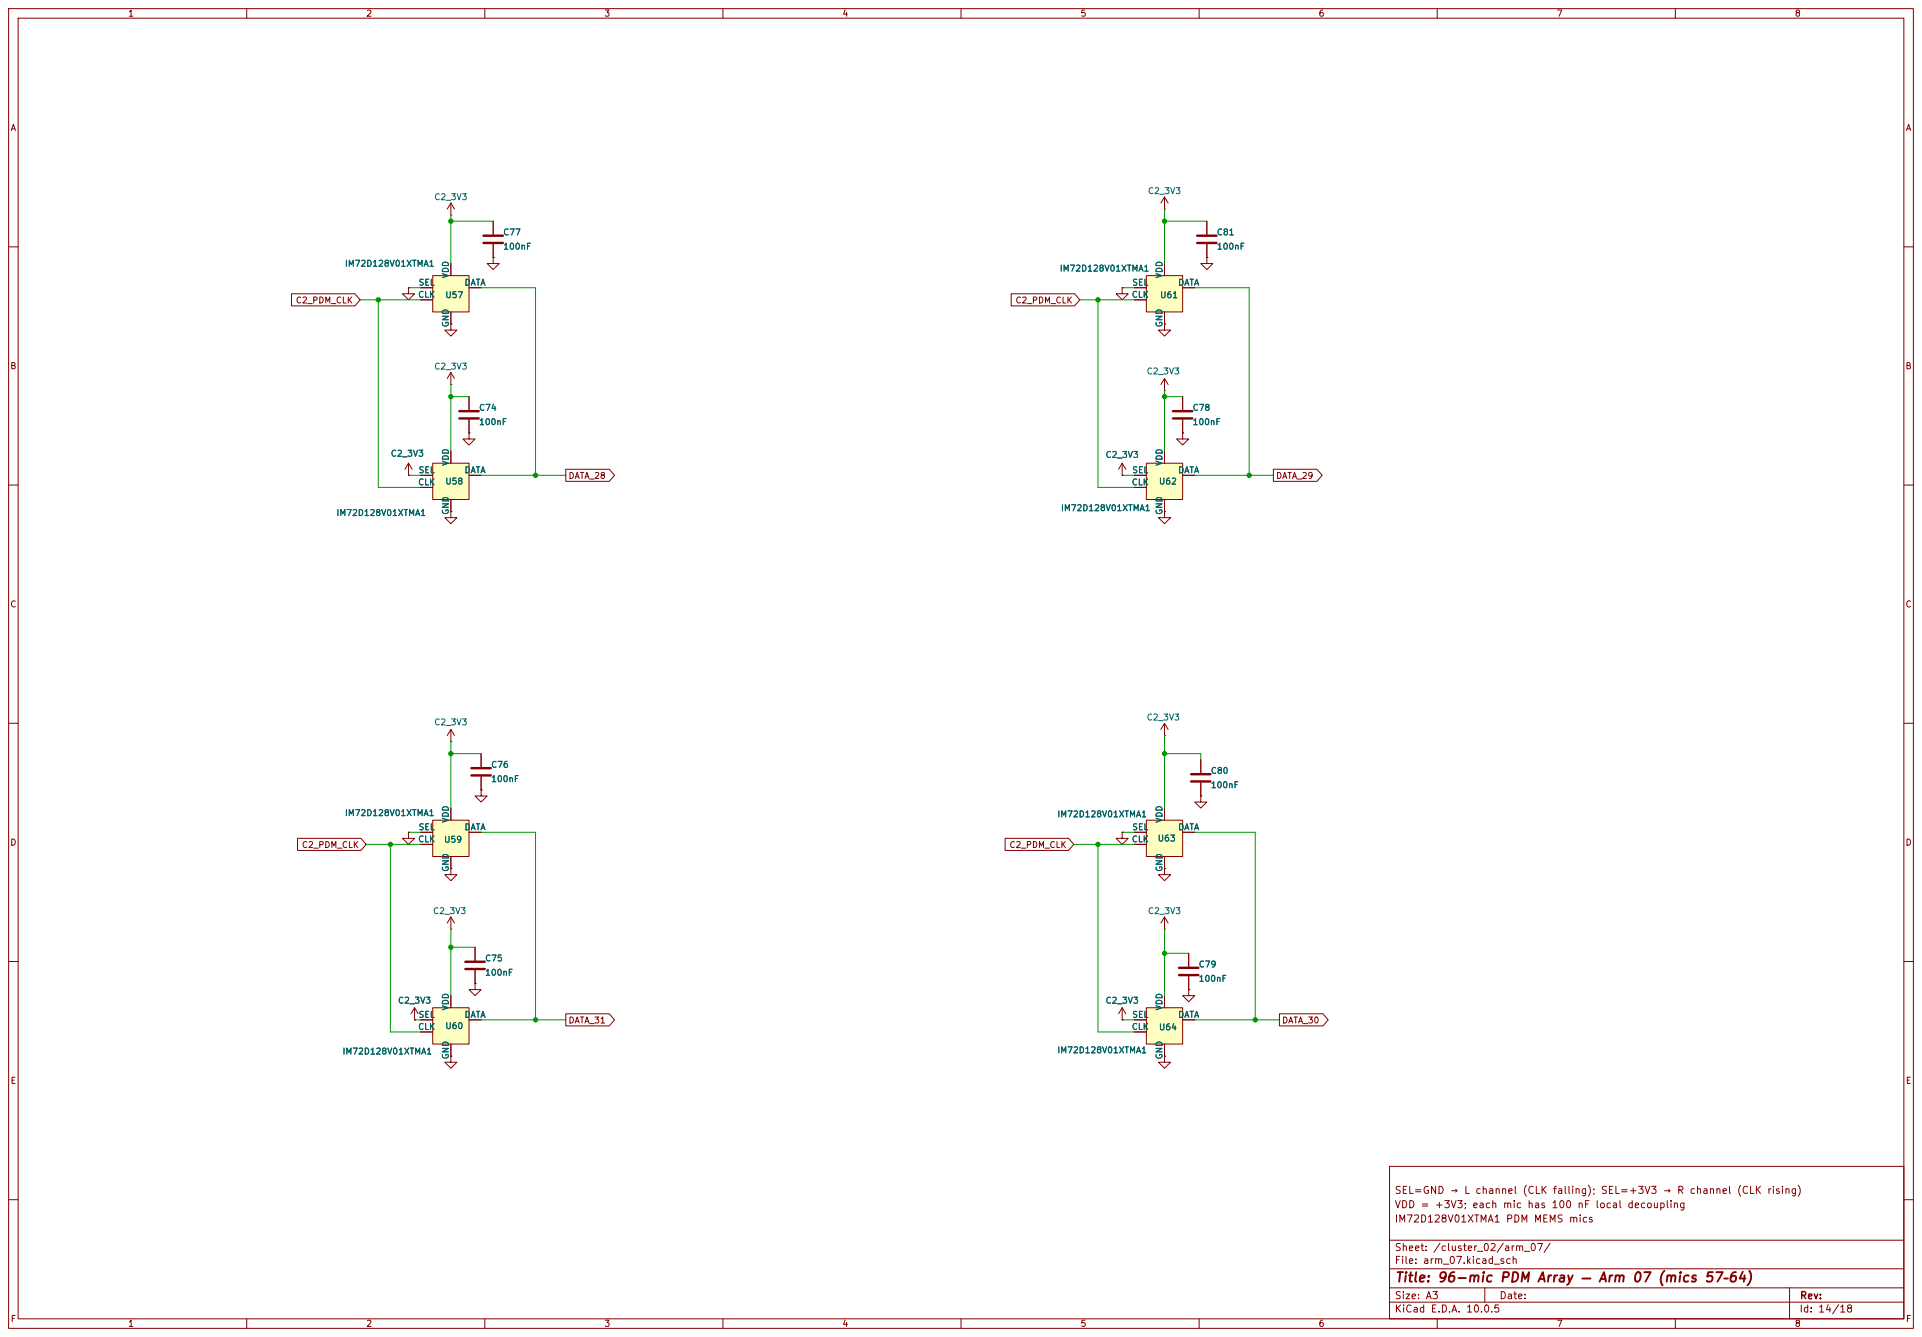
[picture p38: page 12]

SEL=GND → L channel (CLK falling); SEL=+3V3 → R channel (CLK rising) DATA VDD

VDD = +3V3; each mic has 100 nF local decoupling
IM72D128V01XTMA1 PDM MEMS mics

Sheet: /cluster_02/arm_07/
File: arm_07.kicad_sch
Title: 96-mic PDM Array — Arm 07 (mics 57–64)

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

Sheet: /cluster_02/arm_08/
File: arm_08.kicad_sch
Title: 96-mic PDM Array — Arm 08 (mics 65–72)

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

Sheet: /cluster_03/
File: cluster_03.kicad_sch
Title: Multi-FPGA Alternative — Cluster 3 (arms 9-11, mics 72-95)

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

Sheet: /cluster_03/arm_09/
File: arm_09.kicad_sch
Title: 96-mic PDM Array — Arm 09 (mics 73–80)
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

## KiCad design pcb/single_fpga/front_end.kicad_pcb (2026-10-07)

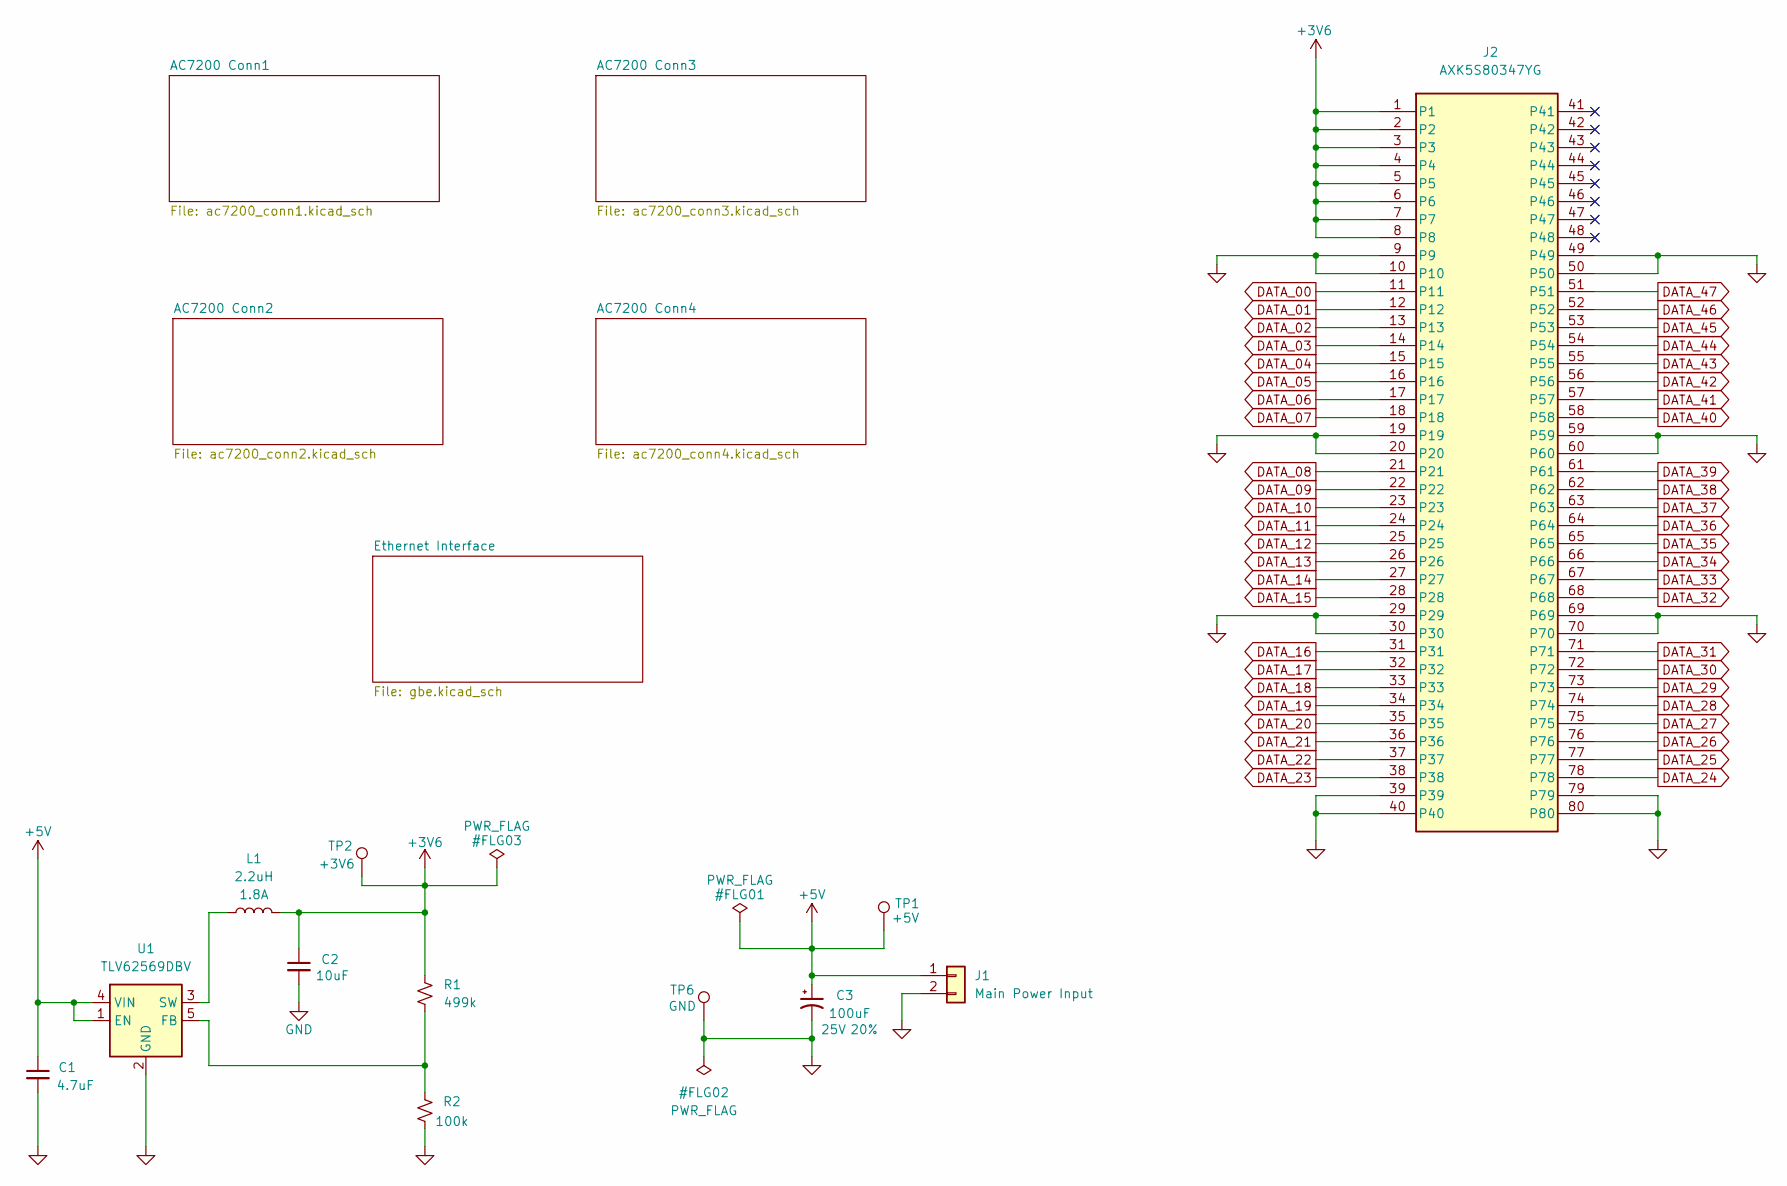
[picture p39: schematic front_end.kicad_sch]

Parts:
C1: 4.7uF; C_1206_3216Metric
C2: 10uF; C_0805_2012Metric
C3: 100uF; Panasonic_D; Voltage 25V; Tolerance 20%
J1: Main Power Input; JST_XH_B2B-XH-A_1x02_P2.50mm_Vertical
J2: AXK5S80347YG; CONN80_AXK5S80347YG_PAN
L1: 2.2uH_2.4A_2016; L_Taiyo-Yuden_NR-20xx_HandSoldering; Part Number DFE201612E-2R2M=P2
R1: 499k; R_0603_1608Metric
R2: 100k; R_0603_1608Metric
TP1: +5V; TestPoint_THTPad_D2.0mm_Drill1.0mm
TP2: +3V6; TestPoint_THTPad_D2.0mm_Drill1.0mm
TP6: GND; TestPoint_THTPad_D2.0mm_Drill1.0mm
U1: TLV62569DBV; SOT-23-5

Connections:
+3V6: C2.1, J2.1, J2.2, J2.3, J2.4, J2.5, J2.6, J2.7, J2.8, L1.2, R1.1, TP2.1 (1_1)
+5V: C1.1, C3.1, J1.1, TP1.1 (1_1), U1.1 (EN), U1.4 (VIN); also elsewhere on the board
DATA_00: J2.11; also elsewhere on the board
DATA_01: J2.12; also elsewhere on the board
DATA_02: J2.13; also elsewhere on the board
DATA_03: J2.14; also elsewhere on the board
DATA_04: J2.15; also elsewhere on the board
DATA_05: J2.16; also elsewhere on the board
DATA_06: J2.17; also elsewhere on the board
DATA_07: J2.18; also elsewhere on the board
DATA_08: J2.21; also elsewhere on the board
DATA_09: J2.22; also elsewhere on the board
DATA_10: J2.23; also elsewhere on the board
DATA_11: J2.24; also elsewhere on the board
DATA_12: J2.25; also elsewhere on the board
DATA_13: J2.26; also elsewhere on the board
DATA_14: J2.27; also elsewhere on the board
DATA_15: J2.28; also elsewhere on the board
DATA_16: J2.31; also elsewhere on the board
DATA_17: J2.32; also elsewhere on the board
DATA_18: J2.33; also elsewhere on the board
DATA_19: J2.34; also elsewhere on the board
DATA_20: J2.35; also elsewhere on the board
DATA_21: J2.36; also elsewhere on the board
DATA_22: J2.37; also elsewhere on the board
DATA_23: J2.38; also elsewhere on the board
DATA_24: J2.78; also elsewhere on the board
DATA_25: J2.77; also elsewhere on the board
DATA_26: J2.76; also elsewhere on the board
DATA_27: J2.75; also elsewhere on the board
DATA_28: J2.74; also elsewhere on the board
DATA_29: J2.73; also elsewhere on the board
DATA_30: J2.72; also elsewhere on the board
DATA_31: J2.71; also elsewhere on the board
DATA_32: J2.68; also elsewhere on the board
DATA_33: J2.67; also elsewhere on the board
DATA_34: J2.66; also elsewhere on the board
DATA_35: J2.65; also elsewhere on the board
DATA_36: J2.64; also elsewhere on the board
DATA_37: J2.63; also elsewhere on the board
DATA_38: J2.62; also elsewhere on the board
DATA_39: J2.61; also elsewhere on the board
DATA_40: J2.58; also elsewhere on the board
DATA_41: J2.57; also elsewhere on the board
DATA_42: J2.56; also elsewhere on the board
DATA_43: J2.55; also elsewhere on the board
DATA_44: J2.54; also elsewhere on the board
DATA_45: J2.53; also elsewhere on the board
DATA_46: J2.52; also elsewhere on the board
DATA_47: J2.51; also elsewhere on the board
GND: C1.2, C2.2, C3.2, J1.2, J2.9, J2.10, J2.19, J2.20, J2.29, J2.30, J2.39, J2.40, J2.49, J2.50, J2.59, J2.60, J2.69, J2.70, J2.79, J2.80, R2.1, TP6.1 (1_1), U1.2 (GND); also elsewhere on the board
unnamed: R1.2, R2.2, U1.5 (FB)
unnamed: L1.1, U1.3 (SW)

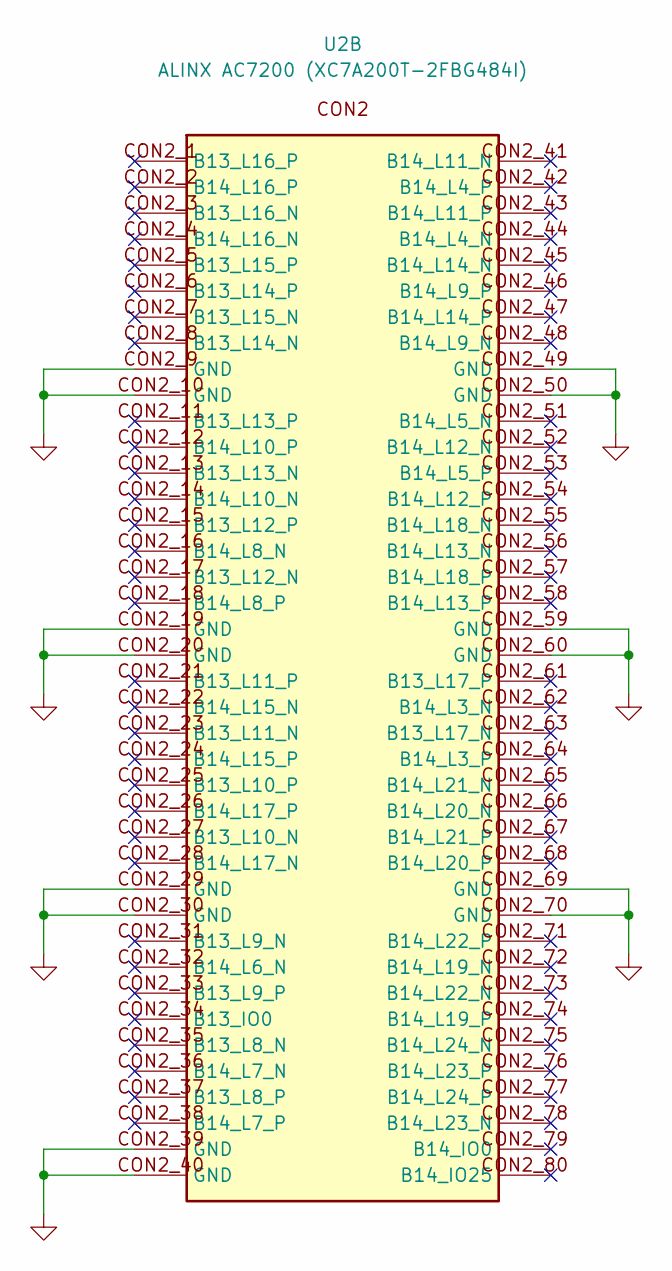
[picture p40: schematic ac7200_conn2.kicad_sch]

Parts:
U2: ALINX AC7200 (XC7A200T-2FBG484I); AC7200

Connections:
GND: U2.CON2_9 (GND), U2.CON2_10 (GND), U2.CON2_19 (GND), U2.CON2_20 (GND), U2.CON2_29 (GND), U2.CON2_30 (GND), U2.CON2_39 (GND), U2.CON2_40 (GND), U2.CON2_49 (GND), U2.CON2_50 (GND), U2.CON2_59 (GND), U2.CON2_60 (GND), U2.CON2_69 (GND), U2.CON2_70 (GND); also elsewhere on the board

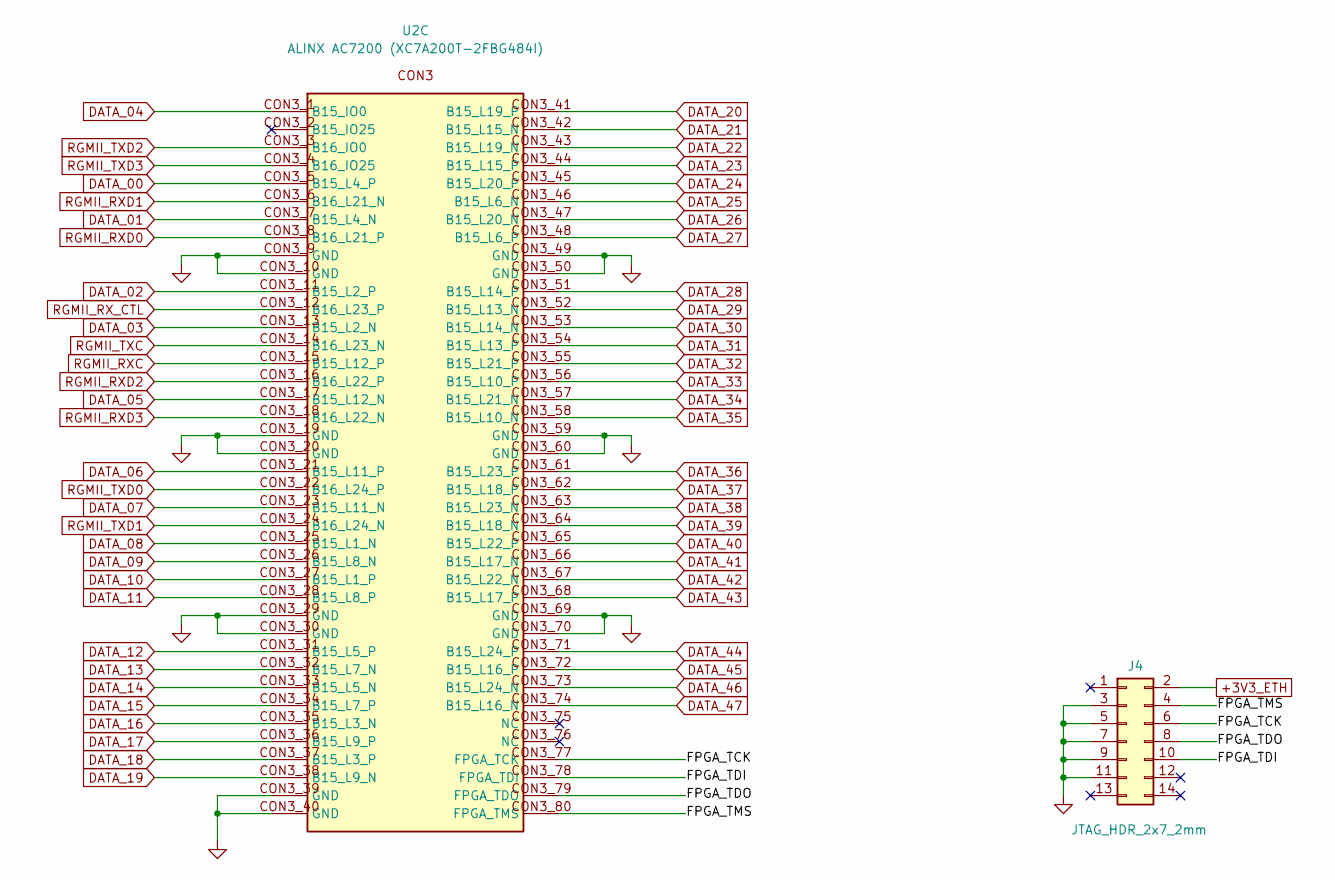
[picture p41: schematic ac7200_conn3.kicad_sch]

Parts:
J4: JTAG_HDR_2x7_2mm; PinHeader_2x07_P2.00mm_Vertical
U2: ALINX AC7200 (XC7A200T-2FBG484I); AC7200

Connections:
+3V3_ETH: J4.2; also elsewhere on the board
/AC7200 Conn3/FPGA_TCK: J4.6, U2.CON3_77 (FPGA_TCK)
/AC7200 Conn3/FPGA_TDI: J4.10, U2.CON3_78 (FPGA_TDI)
/AC7200 Conn3/FPGA_TDO: J4.8, U2.CON3_79 (FPGA_TDO)
/AC7200 Conn3/FPGA_TMS: J4.4, U2.CON3_80 (FPGA_TMS)
DATA_00: U2.CON3_5 (B15_L4_P); also elsewhere on the board
DATA_01: U2.CON3_7 (B15_L4_N); also elsewhere on the board
DATA_02: U2.CON3_11 (B15_L2_P); also elsewhere on the board
DATA_03: U2.CON3_13 (B15_L2_N); also elsewhere on the board
DATA_04: U2.CON3_1 (B15_IO0); also elsewhere on the board
DATA_05: U2.CON3_17 (B15_L12_N); also elsewhere on the board
DATA_06: U2.CON3_21 (B15_L11_P); also elsewhere on the board
DATA_07: U2.CON3_23 (B15_L11_N); also elsewhere on the board
DATA_08: U2.CON3_25 (B15_L1_N); also elsewhere on the board
DATA_09: U2.CON3_26 (B15_L8_N); also elsewhere on the board
DATA_10: U2.CON3_27 (B15_L1_P); also elsewhere on the board
DATA_11: U2.CON3_28 (B15_L8_P); also elsewhere on the board
DATA_12: U2.CON3_31 (B15_L5_P); also elsewhere on the board
DATA_13: U2.CON3_32 (B15_L7_N); also elsewhere on the board
DATA_14: U2.CON3_33 (B15_L5_N); also elsewhere on the board
DATA_15: U2.CON3_34 (B15_L7_P); also elsewhere on the board
DATA_16: U2.CON3_35 (B15_L3_N); also elsewhere on the board
DATA_17: U2.CON3_36 (B15_L9_P); also elsewhere on the board
DATA_18: U2.CON3_37 (B15_L3_P); also elsewhere on the board
DATA_19: U2.CON3_38 (B15_L9_N); also elsewhere on the board
DATA_20: U2.CON3_41 (B15_L19_P); also elsewhere on the board
DATA_21: U2.CON3_42 (B15_L15_N); also elsewhere on the board
DATA_22: U2.CON3_43 (B15_L19_N); also elsewhere on the board
DATA_23: U2.CON3_44 (B15_L15_P); also elsewhere on the board
DATA_24: U2.CON3_45 (B15_L20_P); also elsewhere on the board
DATA_25: U2.CON3_46 (B15_L6_N); also elsewhere on the board
DATA_26: U2.CON3_47 (B15_L20_N); also elsewhere on the board
DATA_27: U2.CON3_48 (B15_L6_P); also elsewhere on the board
DATA_28: U2.CON3_51 (B15_L14_P); also elsewhere on the board
DATA_29: U2.CON3_52 (B15_L13_N); also elsewhere on the board
DATA_30: U2.CON3_53 (B15_L14_N); also elsewhere on the board
DATA_31: U2.CON3_54 (B15_L13_P); also elsewhere on the board
DATA_32: U2.CON3_55 (B15_L21_P); also elsewhere on the board
DATA_33: U2.CON3_56 (B15_L10_P); also elsewhere on the board
DATA_34: U2.CON3_57 (B15_L21_N); also elsewhere on the board
DATA_35: U2.CON3_58 (B15_L10_N); also elsewhere on the board
DATA_36: U2.CON3_61 (B15_L23_P); also elsewhere on the board
DATA_37: U2.CON3_62 (B15_L18_P); also elsewhere on the board
DATA_38: U2.CON3_63 (B15_L23_N); also elsewhere on the board
DATA_39: U2.CON3_64 (B15_L18_N); also elsewhere on the board
DATA_40: U2.CON3_65 (B15_L22_P); also elsewhere on the board
DATA_41: U2.CON3_66 (B15_L17_N); also elsewhere on the board
DATA_42: U2.CON3_67 (B15_L22_N); also elsewhere on the board
DATA_43: U2.CON3_68 (B15_L17_P); also elsewhere on the board
DATA_44: U2.CON3_71 (B15_L24_P); also elsewhere on the board
DATA_45: U2.CON3_72 (B15_L16_P); also elsewhere on the board
DATA_46: U2.CON3_73 (B15_L24_N); also elsewhere on the board
DATA_47: U2.CON3_74 (B15_L16_N); also elsewhere on the board
GND: J4.3, J4.5, J4.7, J4.9, J4.11, U2.CON3_9 (GND), U2.CON3_10 (GND), U2.CON3_19 (GND), U2.CON3_20 (GND), U2.CON3_29 (GND), U2.CON3_30 (GND), U2.CON3_39 (GND), U2.CON3_40 (GND), U2.CON3_49 (GND), U2.CON3_50 (GND), U2.CON3_59 (GND), U2.CON3_60 (GND), U2.CON3_69 (GND), U2.CON3_70 (GND); also elsewhere on the board
RGMII_RXC: U2.CON3_15 (B15_L12_P); also elsewhere on the board
RGMII_RXD0: U2.CON3_8 (B16_L21_P); also elsewhere on the board
RGMII_RXD1: U2.CON3_6 (B16_L21_N); also elsewhere on the board
RGMII_RXD2: U2.CON3_16 (B16_L22_P); also elsewhere on the board
RGMII_RXD3: U2.CON3_18 (B16_L22_N); also elsewhere on the board
RGMII_RX_CTL: U2.CON3_12 (B16_L23_P); also elsewhere on the board
RGMII_TXC: U2.CON3_14 (B16_L23_N); also elsewhere on the board
RGMII_TXD0: U2.CON3_22 (B16_L24_P); also elsewhere on the board
RGMII_TXD1: U2.CON3_24 (B16_L24_N); also elsewhere on the board
RGMII_TXD2: U2.CON3_3 (B16_IO0); also elsewhere on the board
RGMII_TXD3: U2.CON3_4 (B16_IO25); also elsewhere on the board

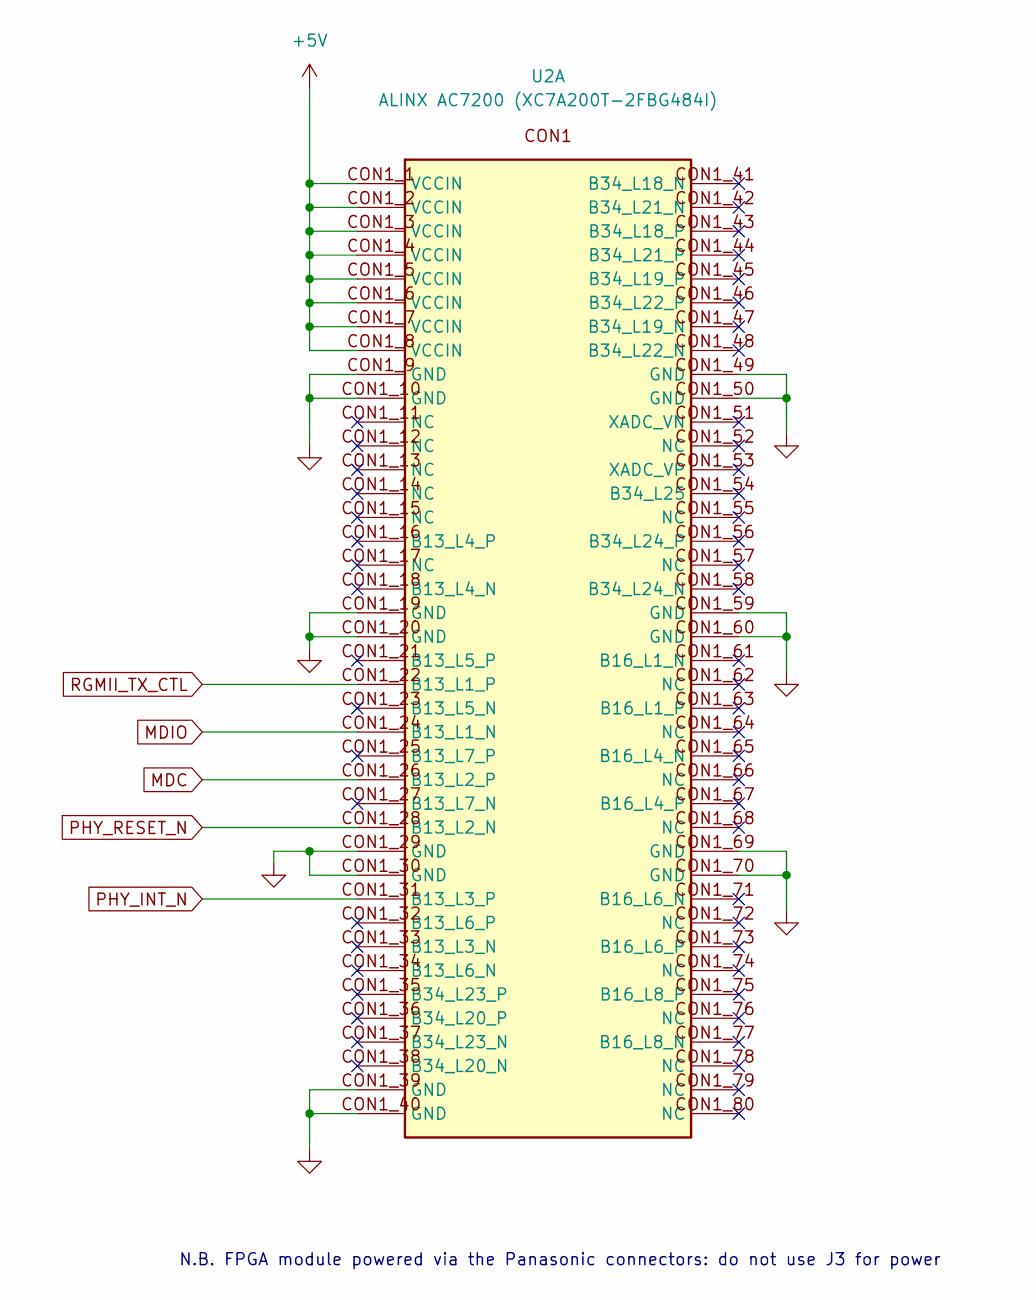
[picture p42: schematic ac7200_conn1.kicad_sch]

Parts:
U2: ALINX AC7200 (XC7A200T-2FBG484I); AC7200

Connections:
+5V: U2.CON1_1 (VCCIN), U2.CON1_2 (VCCIN), U2.CON1_3 (VCCIN), U2.CON1_4 (VCCIN), U2.CON1_5 (VCCIN), U2.CON1_6 (VCCIN), U2.CON1_7 (VCCIN), U2.CON1_8 (VCCIN); also elsewhere on the board
GND: U2.CON1_9 (GND), U2.CON1_10 (GND), U2.CON1_19 (GND), U2.CON1_20 (GND), U2.CON1_29 (GND), U2.CON1_30 (GND), U2.CON1_39 (GND), U2.CON1_40 (GND), U2.CON1_49 (GND), U2.CON1_50 (GND), U2.CON1_59 (GND), U2.CON1_60 (GND), U2.CON1_69 (GND), U2.CON1_70 (GND); also elsewhere on the board
MDC: U2.CON1_26 (B13_L2_P); also elsewhere on the board
MDIO: U2.CON1_24 (B13_L1_N); also elsewhere on the board
PHY_INT_N: U2.CON1_31 (B13_L3_P); also elsewhere on the board
PHY_RESET_N: U2.CON1_28 (B13_L2_N); also elsewhere on the board
RGMII_TX_CTL: U2.CON1_22 (B13_L1_P); also elsewhere on the board

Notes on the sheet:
N.B. FPGA module powered via the Panasonic connectors: do not use J3 for power

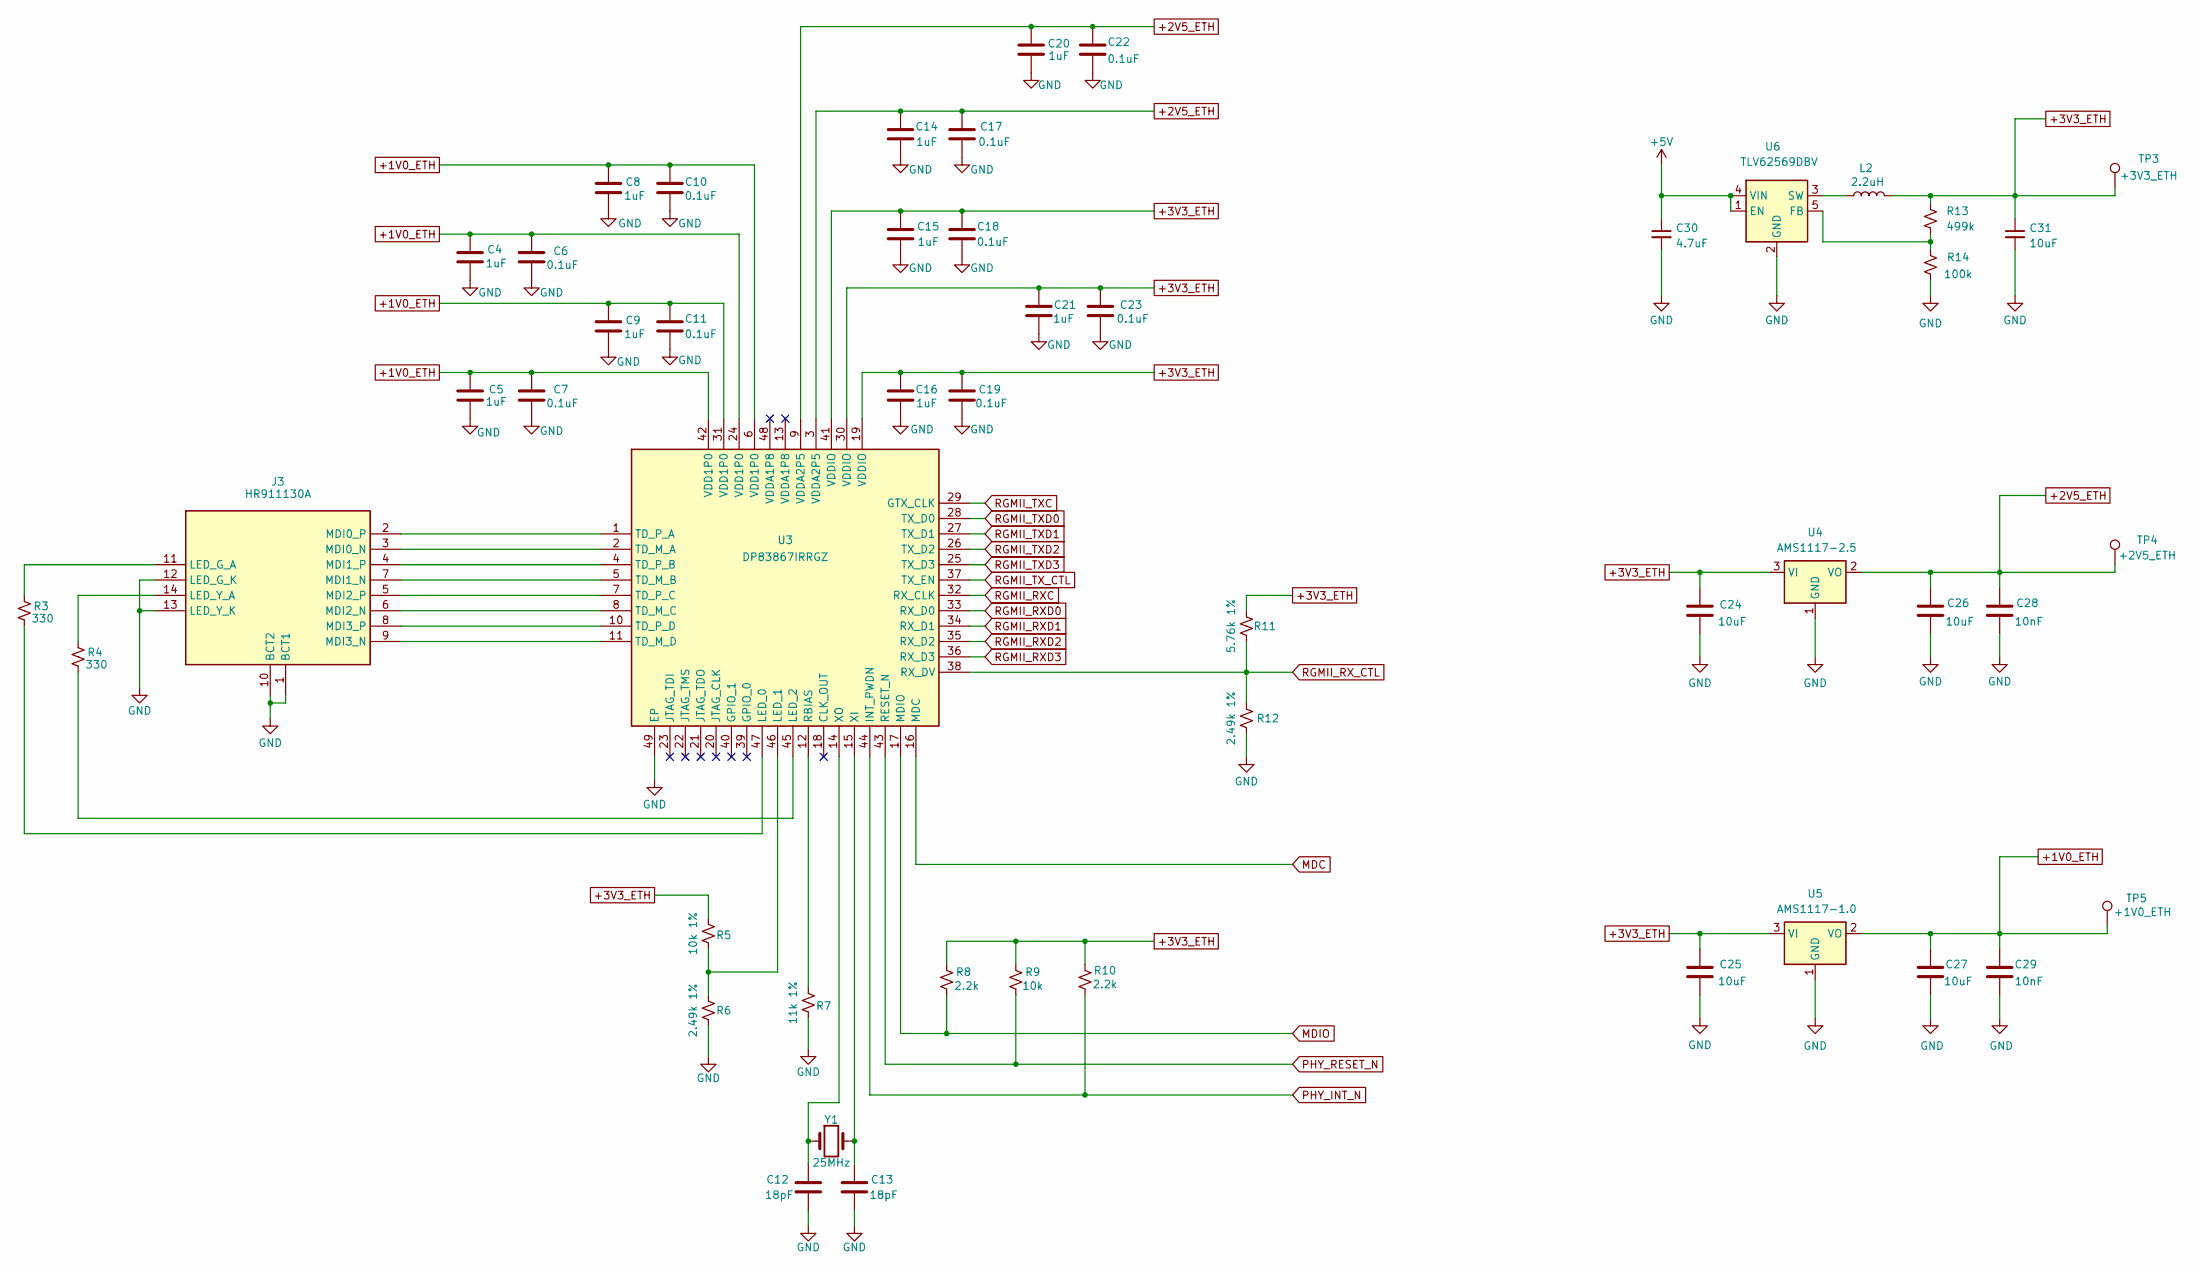
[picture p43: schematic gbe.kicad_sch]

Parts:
C4, C5, C8, C9, C14, C15, C16, C20, C21: 1uF; C_0402_1005Metric
C6, C7, C10, C11, C17, C18, C19, C22, C23: 0.1uF; C_0402_1005Metric
C12, C13: 18pF; C_0402_1005Metric
C24, C25, C26, C27: 10uF; C_0603_1608Metric
C28, C29: 10nF; C_0603_1608Metric
C30: 4.7uF; C_0805_2012Metric
C31: 10uF; C_0805_2012Metric
J3: HR911130A
L2: 2.2uH; L_Taiyo-Yuden_NR-20xx_HandSoldering
R3, R4: 330; R_0402_1005Metric
R5: 10k 1%; R_0402_1005Metric
R6, R12: 2.49k 1%; R_0402_1005Metric
R7: 11k 1%; R_0402_1005Metric
R8, R10: 2.2k; R_0402_1005Metric
R9: 10k; R_0402_1005Metric
R11: 5.76k 1%; R_0402_1005Metric
R13: 499k; R_0603_1608Metric
R14: 100k; R_0603_1608Metric
TP3: +3V3_ETH; TestPoint_THTPad_D2.0mm_Drill1.0mm
TP4: +2V5_ETH; TestPoint_THTPad_D2.0mm_Drill1.0mm
TP5: +1V0_ETH; TestPoint_THTPad_D2.0mm_Drill1.0mm
U3: DP83867IRRGZ; VQFN-48-1EP_6x6mm_P0.4mm_EP4.1x4.1mm
U4: AMS1117-2.5; SOT-223-3_TabPin2
U5: AMS1117-1.0; SOT-223-3_TabPin2
U6: TLV62569DBV; SOT-23-5
Y1: 25MHz; Crystal_SMD_3225-4Pin_3.2x2.5mm

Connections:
+1V0_ETH: C4.1, C5.1, C6.1, C7.1, C8.1, C9.1, C10.1, C11.1, C27.2, C29.2, TP5.1 (1_1), U3.6 (VDD1P0), U3.24 (VDD1P0), U3.31 (VDD1P0), U3.42 (VDD1P0), U5.2 (VO)
+2V5_ETH: C14.1, C17.1, C20.1, C22.1, C26.2, C28.2, TP4.1 (1_1), U3.3 (VDDA2P5), U3.9 (VDDA2P5), U4.2 (VO)
+3V3_ETH: C15.1, C16.1, C18.1, C19.2, C21.1, C23.1, C24.2, C25.2, C31.1, L2.2, R5.2, R8.1, R9.1, R10.1, R11.2, R13.1, TP3.1 (1_1), U3.19 (VDDIO), U3.30 (VDDIO), U3.41 (VDDIO), U4.3 (VI), U5.3 (VI); also elsewhere on the board
+5V: C30.1, U6.1 (EN), U6.4 (VIN); also elsewhere on the board
GND: C4.2, C5.2, C6.2, C7.2, C8.2, C9.2, C10.2, C11.2, C12.2, C13.2, C14.2, C15.2, C16.2, C17.2, C18.2, C19.1, C20.2, C21.2, C22.2, C23.2, C24.1, C25.1, C26.1, C27.1, C28.1, C29.1, C30.2, C31.2, J3.1 (BCT1), J3.10 (BCT2), J3.12 (LED_G_K), J3.13 (LED_Y_K), R6.1, R7.1, R12.1, R14.1, U3.49 (EP), U4.1 (GND), U5.1 (GND), U6.2 (GND); also elsewhere on the board
MDC: U3.16 (MDC); also elsewhere on the board
MDIO: R8.2, U3.17 (MDIO); also elsewhere on the board
unnamed: J3.11 (LED_G_A), R3.1
unnamed: J3.14 (LED_Y_A), R4.2
unnamed: J3.3 (MDI0_N), U3.2 (TD_M_A)
unnamed: J3.2 (MDI0_P), U3.1 (TD_P_A)
unnamed: J3.7 (MDI1_N), U3.5 (TD_M_B)
unnamed: J3.4 (MDI1_P), U3.4 (TD_P_B)
unnamed: J3.6 (MDI2_N), U3.8 (TD_M_C)
unnamed: J3.5 (MDI2_P), U3.7 (TD_P_C)
unnamed: J3.9 (MDI3_N), U3.11 (TD_M_D)
unnamed: J3.8 (MDI3_P), U3.10 (TD_P_D)
unnamed: R3.2, U3.47 (LED_0)
unnamed: R5.1, R6.2, U3.46 (LED_1)
unnamed: R4.1, U3.45 (LED_2)
unnamed: R7.2, U3.12 (RBIAS)
unnamed: C13.1, U3.15 (XI), Y1.2
unnamed: C12.1, U3.14 (XO), Y1.1
unnamed: R13.2, R14.2, U6.5 (FB)
unnamed: L2.1, U6.3 (SW)
PHY_INT_N: R10.2, U3.44 (INT_PWDN); also elsewhere on the board
PHY_RESET_N: R9.2, U3.43 (RESET_N); also elsewhere on the board
RGMII_RXC: U3.32 (RX_CLK); also elsewhere on the board
RGMII_RXD0: U3.33 (RX_D0); also elsewhere on the board
RGMII_RXD1: U3.34 (RX_D1); also elsewhere on the board
RGMII_RXD2: U3.35 (RX_D2); also elsewhere on the board
RGMII_RXD3: U3.36 (RX_D3); also elsewhere on the board
RGMII_RX_CTL: R11.1, R12.2, U3.38 (RX_DV); also elsewhere on the board
RGMII_TXC: U3.29 (GTX_CLK); also elsewhere on the board
RGMII_TXD0: U3.28 (TX_D0); also elsewhere on the board
RGMII_TXD1: U3.27 (TX_D1); also elsewhere on the board
RGMII_TXD2: U3.26 (TX_D2); also elsewhere on the board
RGMII_TXD3: U3.25 (TX_D3); also elsewhere on the board
RGMII_TX_CTL: U3.37 (TX_EN); also elsewhere on the board

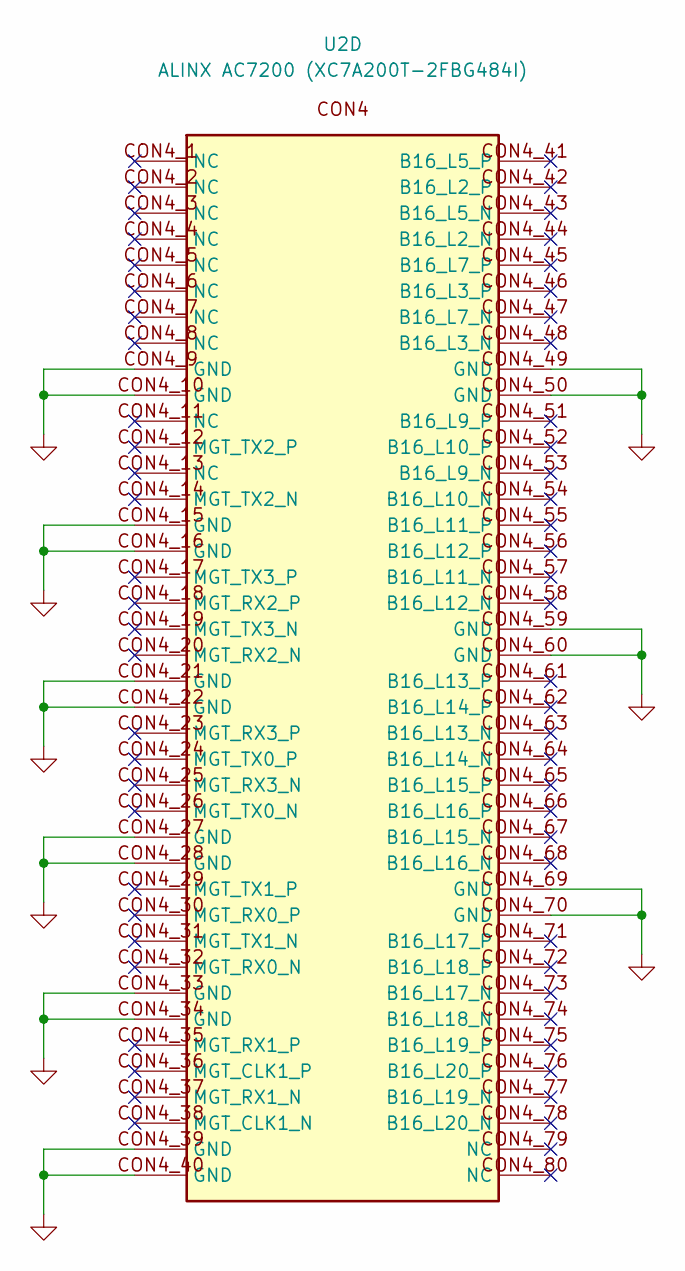
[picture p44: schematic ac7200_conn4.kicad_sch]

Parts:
U2: ALINX AC7200 (XC7A200T-2FBG484I); AC7200

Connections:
GND: U2.CON4_9 (GND), U2.CON4_10 (GND), U2.CON4_15 (GND), U2.CON4_16 (GND), U2.CON4_21 (GND), U2.CON4_22 (GND), U2.CON4_27 (GND), U2.CON4_28 (GND), U2.CON4_33 (GND), U2.CON4_34 (GND), U2.CON4_39 (GND), U2.CON4_40 (GND), U2.CON4_49 (GND), U2.CON4_50 (GND), U2.CON4_59 (GND), U2.CON4_60 (GND), U2.CON4_69 (GND), U2.CON4_70 (GND); also elsewhere on the board

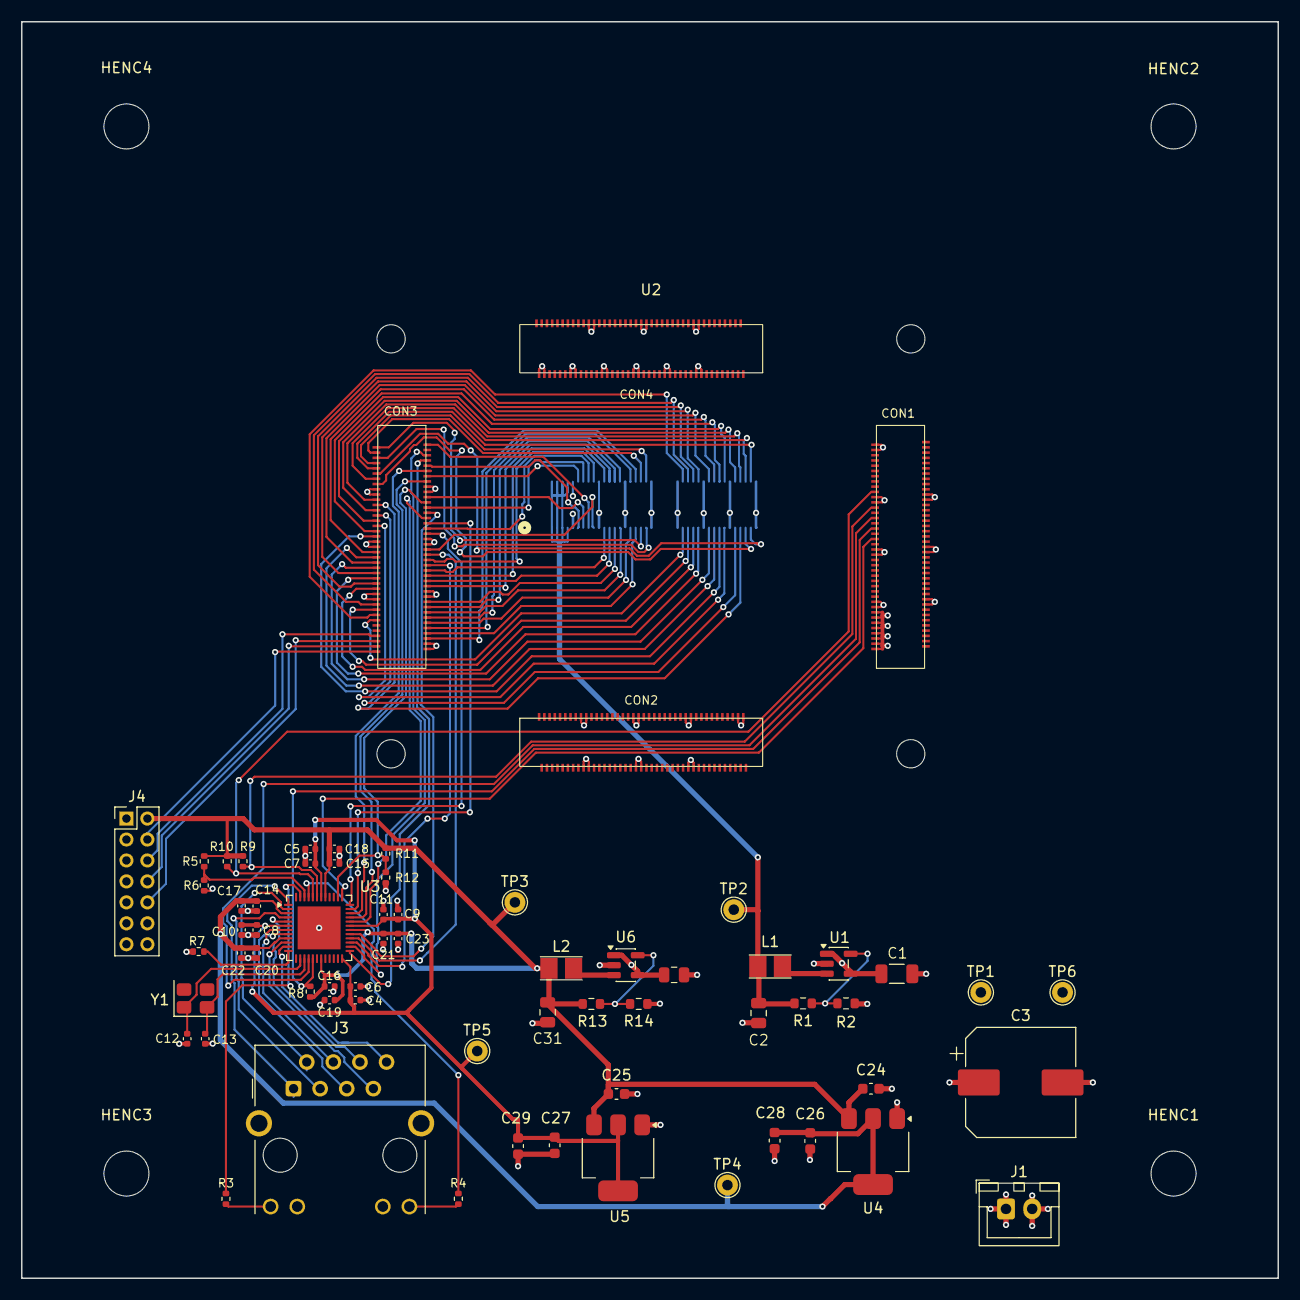
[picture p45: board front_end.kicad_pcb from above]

Board: 4 copper layers, 120.0 x 120.0 mm, 68 parts (1 on the bottom side), 94 nets.

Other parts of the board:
HENC1, HENC2, HENC3, HENC4: MountingHole_4.3mm_M4

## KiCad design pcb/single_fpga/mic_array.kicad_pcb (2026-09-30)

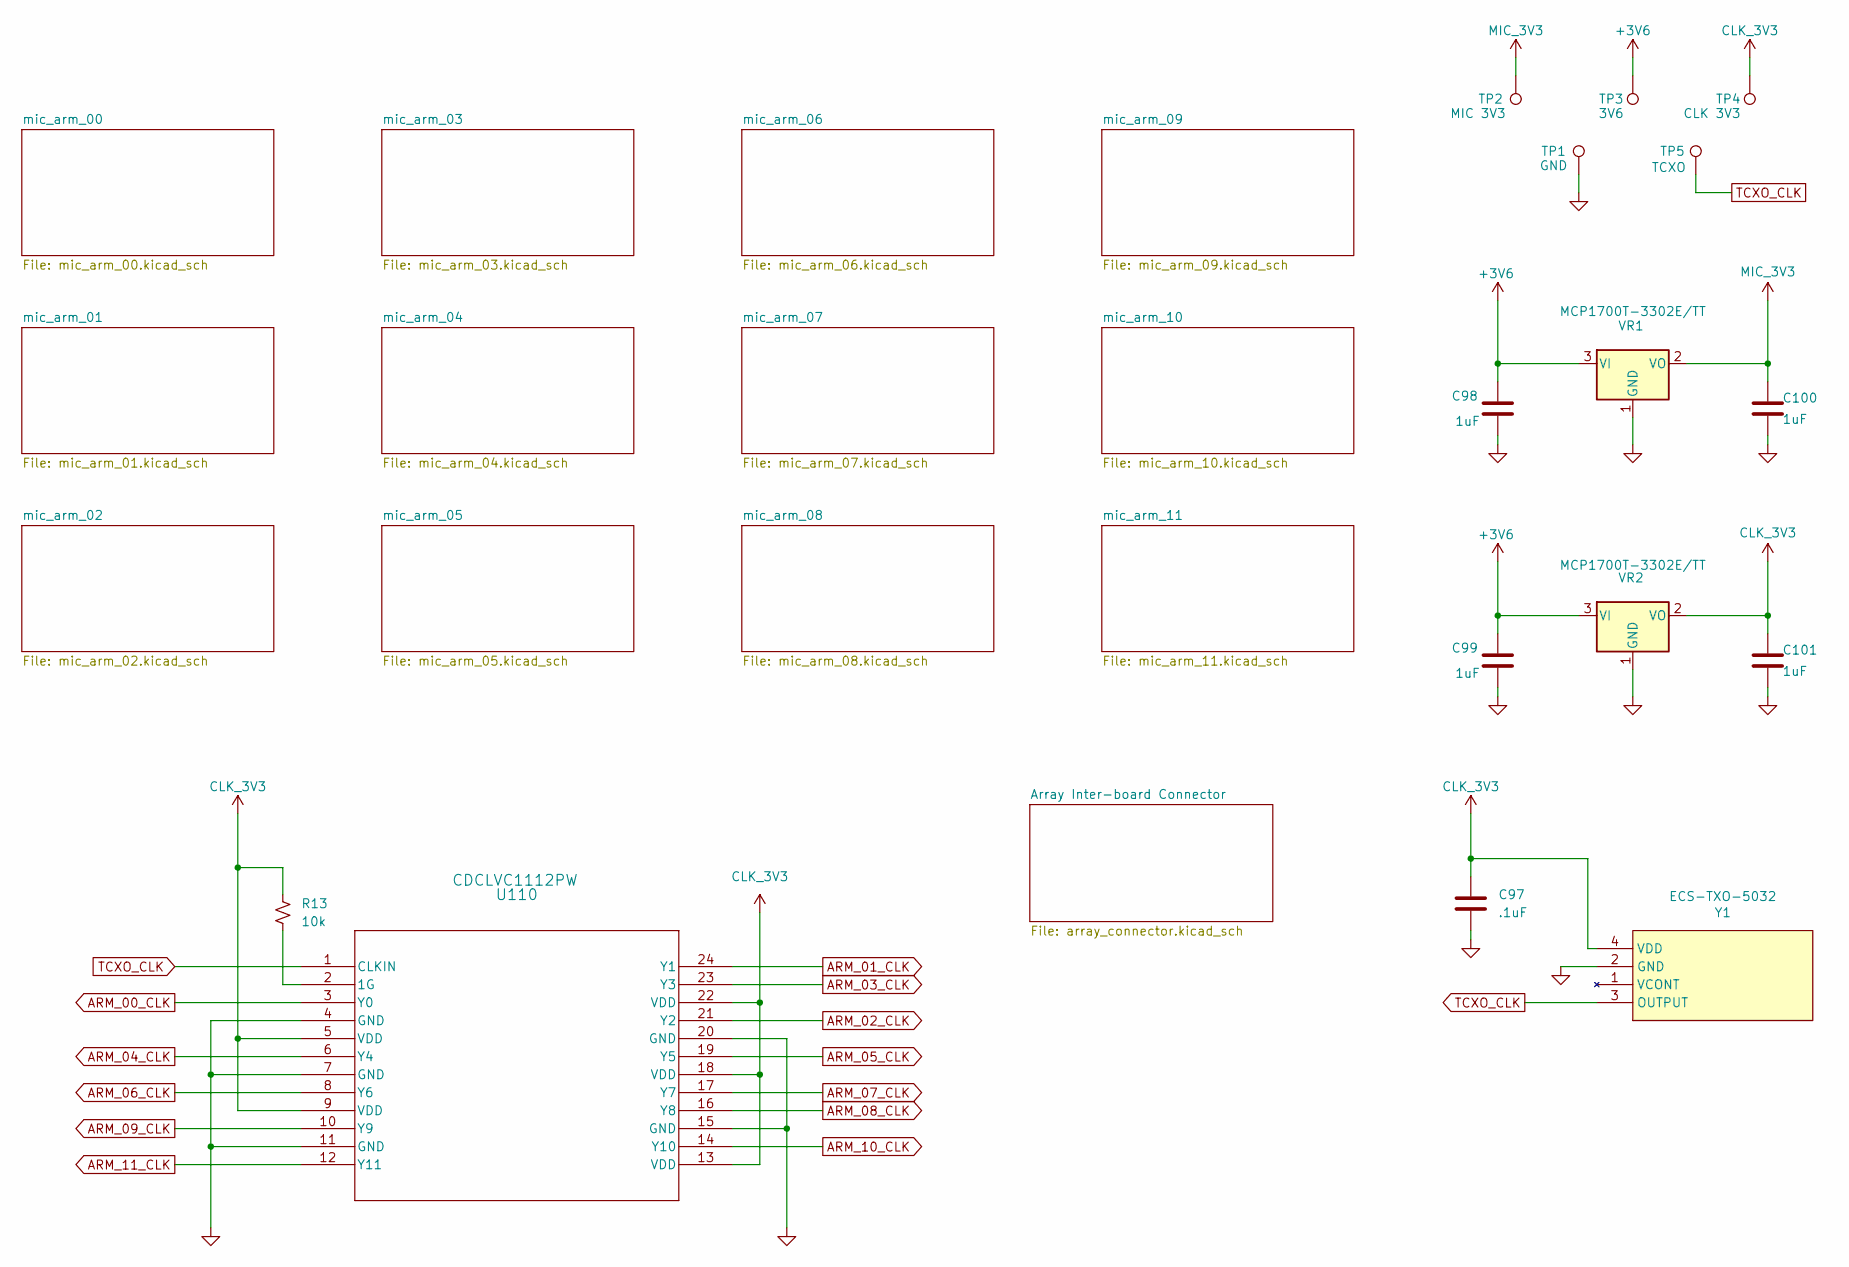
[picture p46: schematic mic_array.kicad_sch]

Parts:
C97: .1uF; C_0603_1608Metric
C98, C99, C100, C101: 1uF; C_1206_3216Metric
R13: 10k; R_0603_1608Metric
TP1: GND; TestPoint_THTPad_D2.0mm_Drill1.0mm
TP2: MIC 3V3; TestPoint_THTPad_D2.0mm_Drill1.0mm
TP3: 3V6; TestPoint_THTPad_D2.0mm_Drill1.0mm
TP4: CLK 3V3; TestPoint_THTPad_D2.0mm_Drill1.0mm
TP5: TCXO; TestPoint_THTPad_D2.0mm_Drill1.0mm
U110: CDCLVC1112PW; PW24
VR1, VR2: MCP1700T-3302E/TT; SOT-23
Y1: ECS-TXO-5032; ECS-TXO-5032-122.8-TR

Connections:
+3V6: C98.1, C99.1, TP3.1, VR1.3 (VI), VR2.3 (VI); also elsewhere on the board
ARM_00_CLK: U110.3 (Y0); also elsewhere on the board
ARM_01_CLK: U110.24 (Y1); also elsewhere on the board
ARM_02_CLK: U110.21 (Y2); also elsewhere on the board
ARM_03_CLK: U110.23 (Y3); also elsewhere on the board
ARM_04_CLK: U110.6 (Y4); also elsewhere on the board
ARM_05_CLK: U110.19 (Y5); also elsewhere on the board
ARM_06_CLK: U110.8 (Y6); also elsewhere on the board
ARM_07_CLK: U110.17 (Y7); also elsewhere on the board
ARM_08_CLK: U110.16 (Y8); also elsewhere on the board
ARM_09_CLK: U110.10 (Y9); also elsewhere on the board
ARM_10_CLK: U110.14 (Y10); also elsewhere on the board
ARM_11_CLK: U110.12 (Y11); also elsewhere on the board
GND: C97.2, C98.2, C99.2, C100.2, C101.2, TP1.1, U110.4 (GND), U110.7 (GND), U110.11 (GND), U110.15 (GND), U110.20 (GND), VR1.1 (GND), VR2.1 (GND), Y1.2 (GND); also elsewhere on the board
MIC_3V3: C100.1, TP2.1, VR1.2 (VO); also elsewhere on the board
unnamed: R13.1, U110.2 (1G)
TCXO_CLK: TP5.1, U110.1 (CLKIN), Y1.3 (OUTPUT)

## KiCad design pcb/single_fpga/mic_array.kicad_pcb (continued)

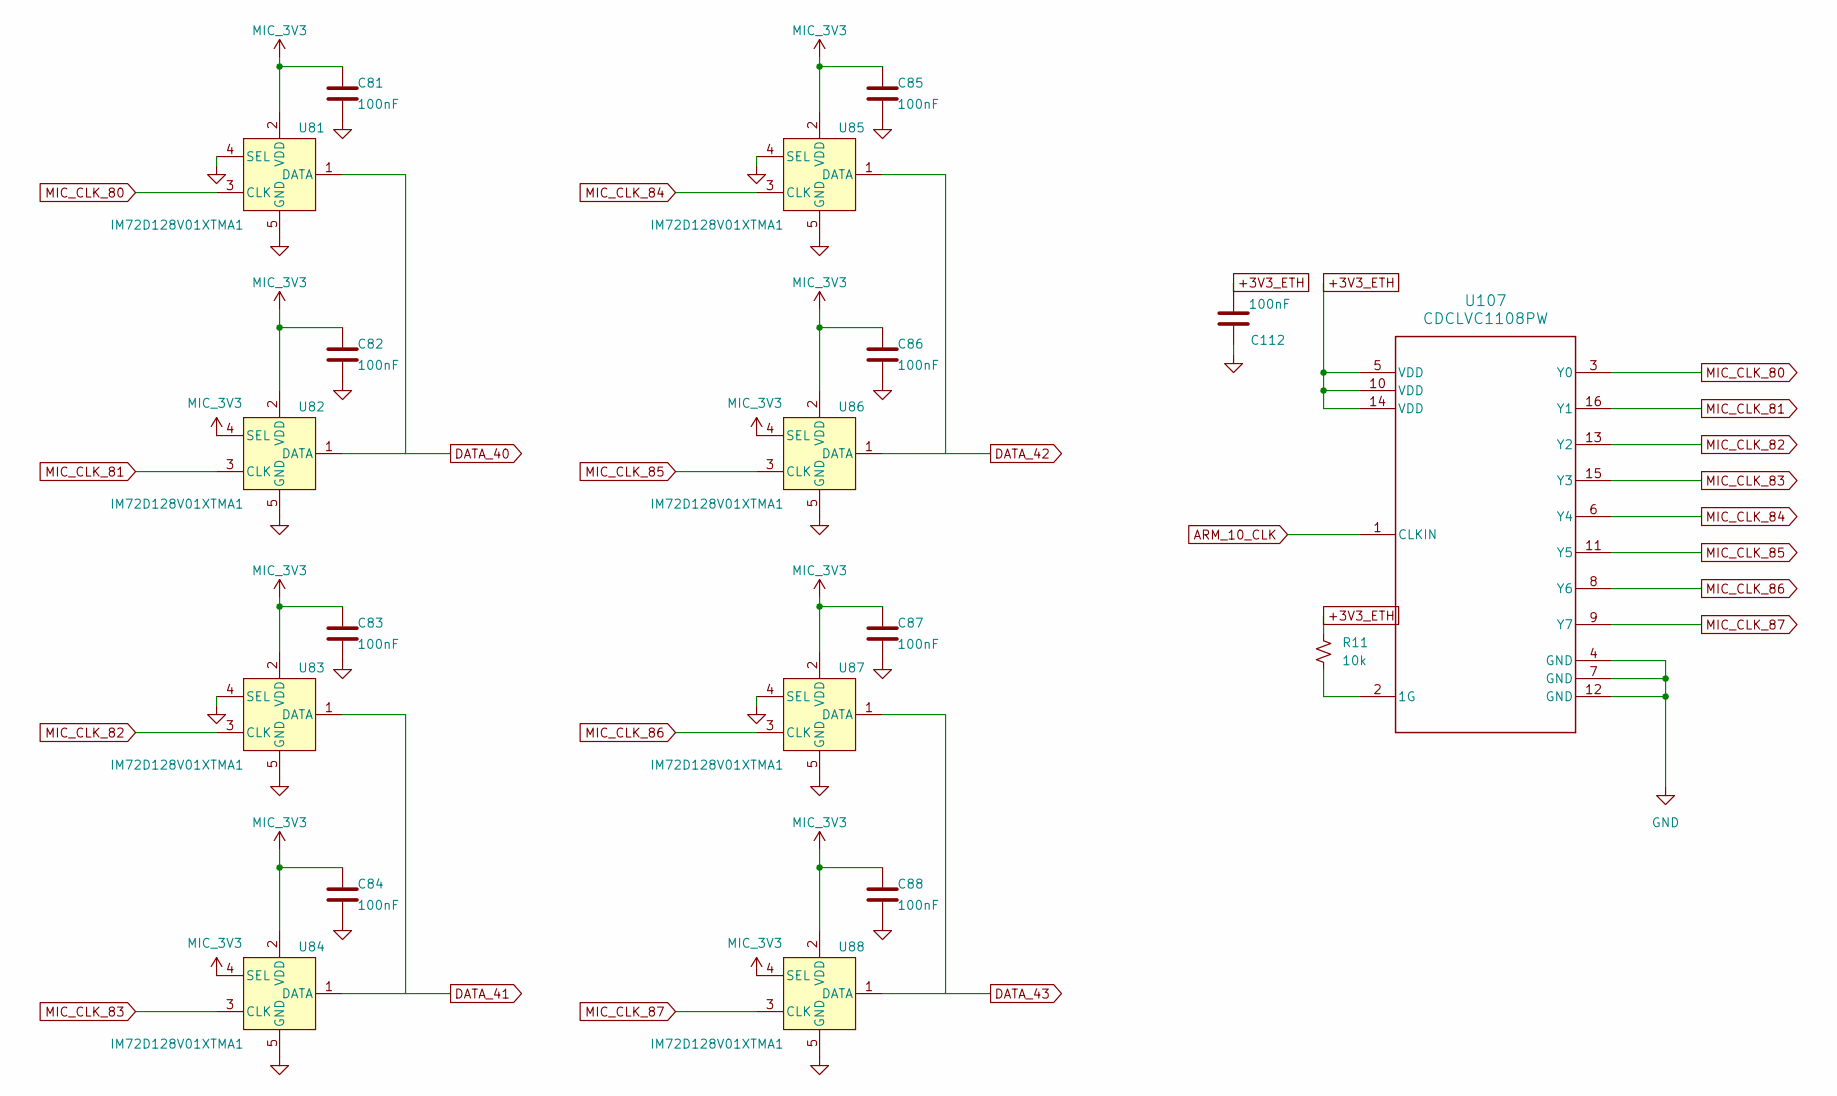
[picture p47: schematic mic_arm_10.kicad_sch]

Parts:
C81, C82, C83, C84, C85, C86, C87, C88, C112: 100nF; C_0603_1608Metric
R11: 10k; R_0603_1608Metric
U81, U82, U83, U84, U85, U86, U87, U88: IM72D128V01XTMA1; IFX-PG-LLGA-5-4
U107: CDCLVC1108PW; PW0016A_N

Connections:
ARM_10_CLK: U107.1 (CLKIN); also elsewhere on the board
DATA_40: U81.1 (DATA), U82.1 (DATA); also elsewhere on the board
DATA_41: U83.1 (DATA), U84.1 (DATA); also elsewhere on the board
DATA_42: U85.1 (DATA), U86.1 (DATA); also elsewhere on the board
DATA_43: U87.1 (DATA), U88.1 (DATA); also elsewhere on the board
GND: C81.2, C82.2, C83.2, C84.2, C85.2, C86.2, C87.2, C88.2, C112.1, U81.4 (SEL), U81.5 (GND), U82.5 (GND), U83.4 (SEL), U83.5 (GND), U84.5 (GND), U85.4 (SEL), U85.5 (GND), U86.5 (GND), U87.4 (SEL), U87.5 (GND), U88.5 (GND), U107.4 (GND), U107.7 (GND), U107.12 (GND); also elsewhere on the board
MIC_3V3: C81.1, C82.1, C83.1, C84.1, C85.1, C86.1, C87.1, C88.1, U81.2 (VDD), U82.2 (VDD), U82.4 (SEL), U83.2 (VDD), U84.2 (VDD), U84.4 (SEL), U85.2 (VDD), U86.2 (VDD), U86.4 (SEL), U87.2 (VDD), U88.2 (VDD), U88.4 (SEL); also elsewhere on the board
MIC_CLK_80: U81.3 (CLK), U107.3 (Y0)
MIC_CLK_81: U82.3 (CLK), U107.16 (Y1)
MIC_CLK_82: U83.3 (CLK), U107.13 (Y2)
MIC_CLK_83: U84.3 (CLK), U107.15 (Y3)
MIC_CLK_84: U85.3 (CLK), U107.6 (Y4)
MIC_CLK_85: U86.3 (CLK), U107.11 (Y5)
MIC_CLK_86: U87.3 (CLK), U107.8 (Y6)
MIC_CLK_87: U88.3 (CLK), U107.9 (Y7)
unnamed: R11.1, U107.2 (1G)

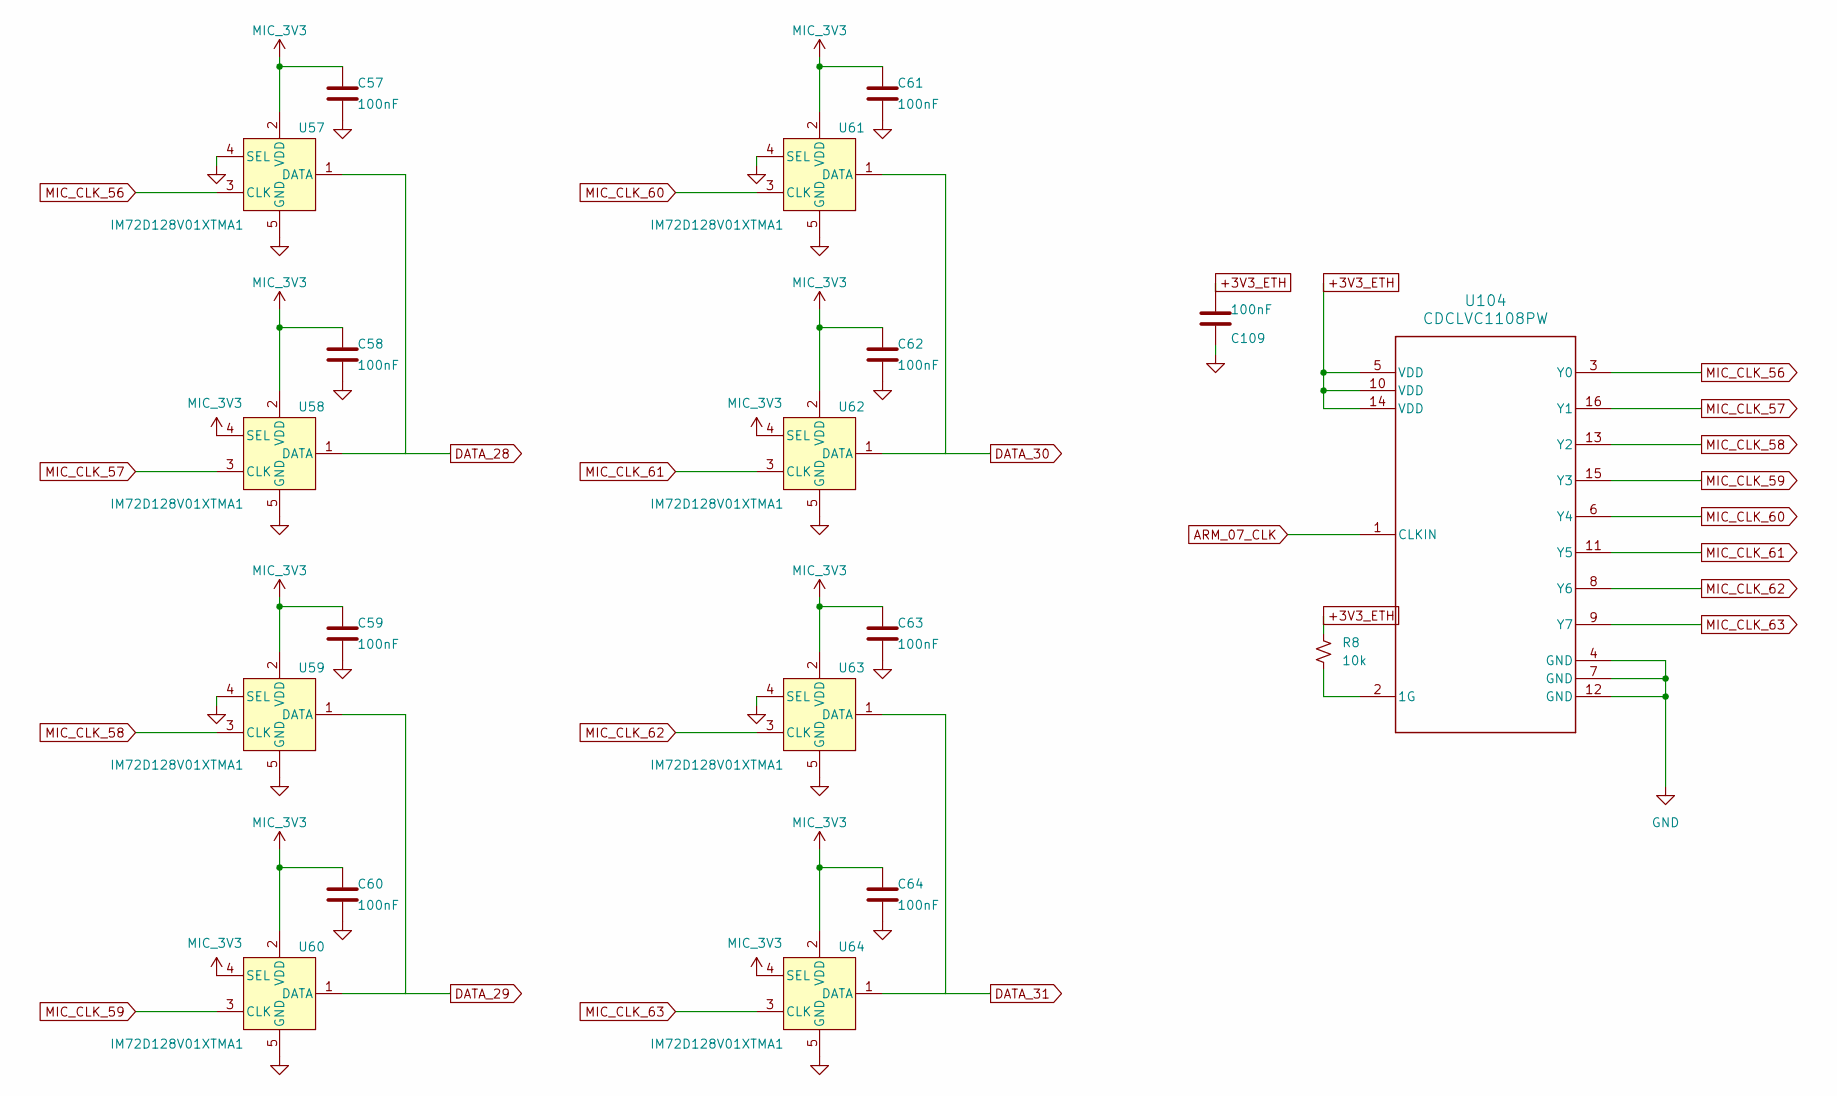
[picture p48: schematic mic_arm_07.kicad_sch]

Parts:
C57, C58, C59, C60, C61, C62, C63, C64, C109: 100nF; C_0603_1608Metric
R8: 10k; R_0603_1608Metric
U57, U58, U59, U60, U61, U62, U63, U64: IM72D128V01XTMA1; IFX-PG-LLGA-5-4
U104: CDCLVC1108PW; PW0016A_N

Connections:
ARM_07_CLK: U104.1 (CLKIN); also elsewhere on the board
DATA_28: U57.1 (DATA), U58.1 (DATA); also elsewhere on the board
DATA_29: U59.1 (DATA), U60.1 (DATA); also elsewhere on the board
DATA_30: U61.1 (DATA), U62.1 (DATA); also elsewhere on the board
DATA_31: U63.1 (DATA), U64.1 (DATA); also elsewhere on the board
GND: C57.2, C58.2, C59.2, C60.2, C61.2, C62.2, C63.2, C64.2, C109.1, U57.4 (SEL), U57.5 (GND), U58.5 (GND), U59.4 (SEL), U59.5 (GND), U60.5 (GND), U61.4 (SEL), U61.5 (GND), U62.5 (GND), U63.4 (SEL), U63.5 (GND), U64.5 (GND), U104.4 (GND), U104.7 (GND), U104.12 (GND); also elsewhere on the board
MIC_3V3: C57.1, C58.1, C59.1, C60.1, C61.1, C62.1, C63.1, C64.1, U57.2 (VDD), U58.2 (VDD), U58.4 (SEL), U59.2 (VDD), U60.2 (VDD), U60.4 (SEL), U61.2 (VDD), U62.2 (VDD), U62.4 (SEL), U63.2 (VDD), U64.2 (VDD), U64.4 (SEL); also elsewhere on the board
MIC_CLK_56: U57.3 (CLK), U104.3 (Y0)
MIC_CLK_57: U58.3 (CLK), U104.16 (Y1)
MIC_CLK_58: U59.3 (CLK), U104.13 (Y2)
MIC_CLK_59: U60.3 (CLK), U104.15 (Y3)
MIC_CLK_60: U61.3 (CLK), U104.6 (Y4)
MIC_CLK_61: U62.3 (CLK), U104.11 (Y5)
MIC_CLK_62: U63.3 (CLK), U104.8 (Y6)
MIC_CLK_63: U64.3 (CLK), U104.9 (Y7)
unnamed: R8.1, U104.2 (1G)

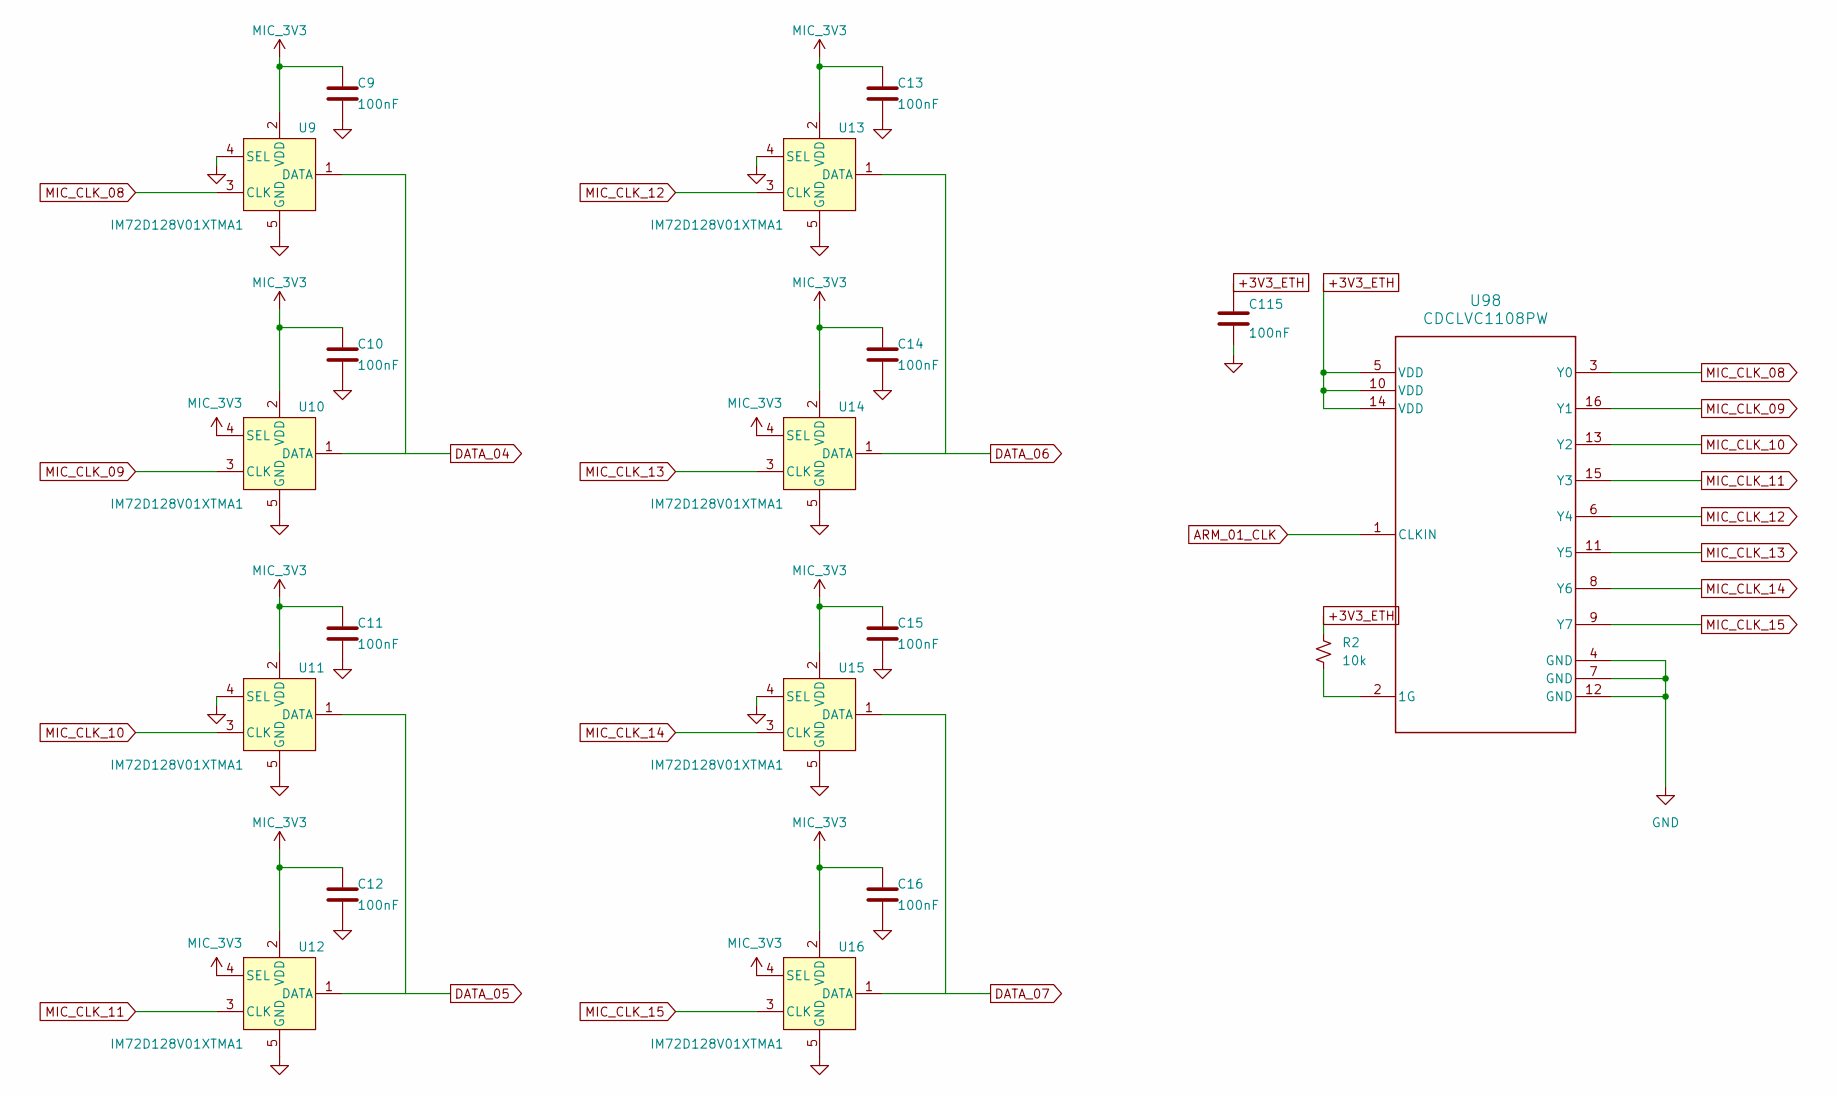
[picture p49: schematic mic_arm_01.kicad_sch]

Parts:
C9, C10, C11, C12, C13, C14, C15, C16, C115: 100nF; C_0603_1608Metric
R2: 10k; R_0603_1608Metric
U9, U10, U11, U12, U13, U14, U15, U16: IM72D128V01XTMA1; IFX-PG-LLGA-5-4
U98: CDCLVC1108PW; PW0016A_N

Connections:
ARM_01_CLK: U98.1 (CLKIN); also elsewhere on the board
DATA_04: U9.1 (DATA), U10.1 (DATA); also elsewhere on the board
DATA_05: U11.1 (DATA), U12.1 (DATA); also elsewhere on the board
DATA_06: U13.1 (DATA), U14.1 (DATA); also elsewhere on the board
DATA_07: U15.1 (DATA), U16.1 (DATA); also elsewhere on the board
GND: C9.2, C10.2, C11.2, C12.2, C13.2, C14.2, C15.2, C16.2, C115.2, U9.4 (SEL), U9.5 (GND), U10.5 (GND), U11.4 (SEL), U11.5 (GND), U12.5 (GND), U13.4 (SEL), U13.5 (GND), U14.5 (GND), U15.4 (SEL), U15.5 (GND), U16.5 (GND), U98.4 (GND), U98.7 (GND), U98.12 (GND); also elsewhere on the board
MIC_3V3: C9.1, C10.1, C11.1, C12.1, C13.1, C14.1, C15.1, C16.1, U9.2 (VDD), U10.2 (VDD), U10.4 (SEL), U11.2 (VDD), U12.2 (VDD), U12.4 (SEL), U13.2 (VDD), U14.2 (VDD), U14.4 (SEL), U15.2 (VDD), U16.2 (VDD), U16.4 (SEL); also elsewhere on the board
MIC_CLK_08: U9.3 (CLK), U98.3 (Y0)
MIC_CLK_09: U10.3 (CLK), U98.16 (Y1)
MIC_CLK_10: U11.3 (CLK), U98.13 (Y2)
MIC_CLK_11: U12.3 (CLK), U98.15 (Y3)
MIC_CLK_12: U13.3 (CLK), U98.6 (Y4)
MIC_CLK_13: U14.3 (CLK), U98.11 (Y5)
MIC_CLK_14: U15.3 (CLK), U98.8 (Y6)
MIC_CLK_15: U16.3 (CLK), U98.9 (Y7)
unnamed: R2.1, U98.2 (1G)

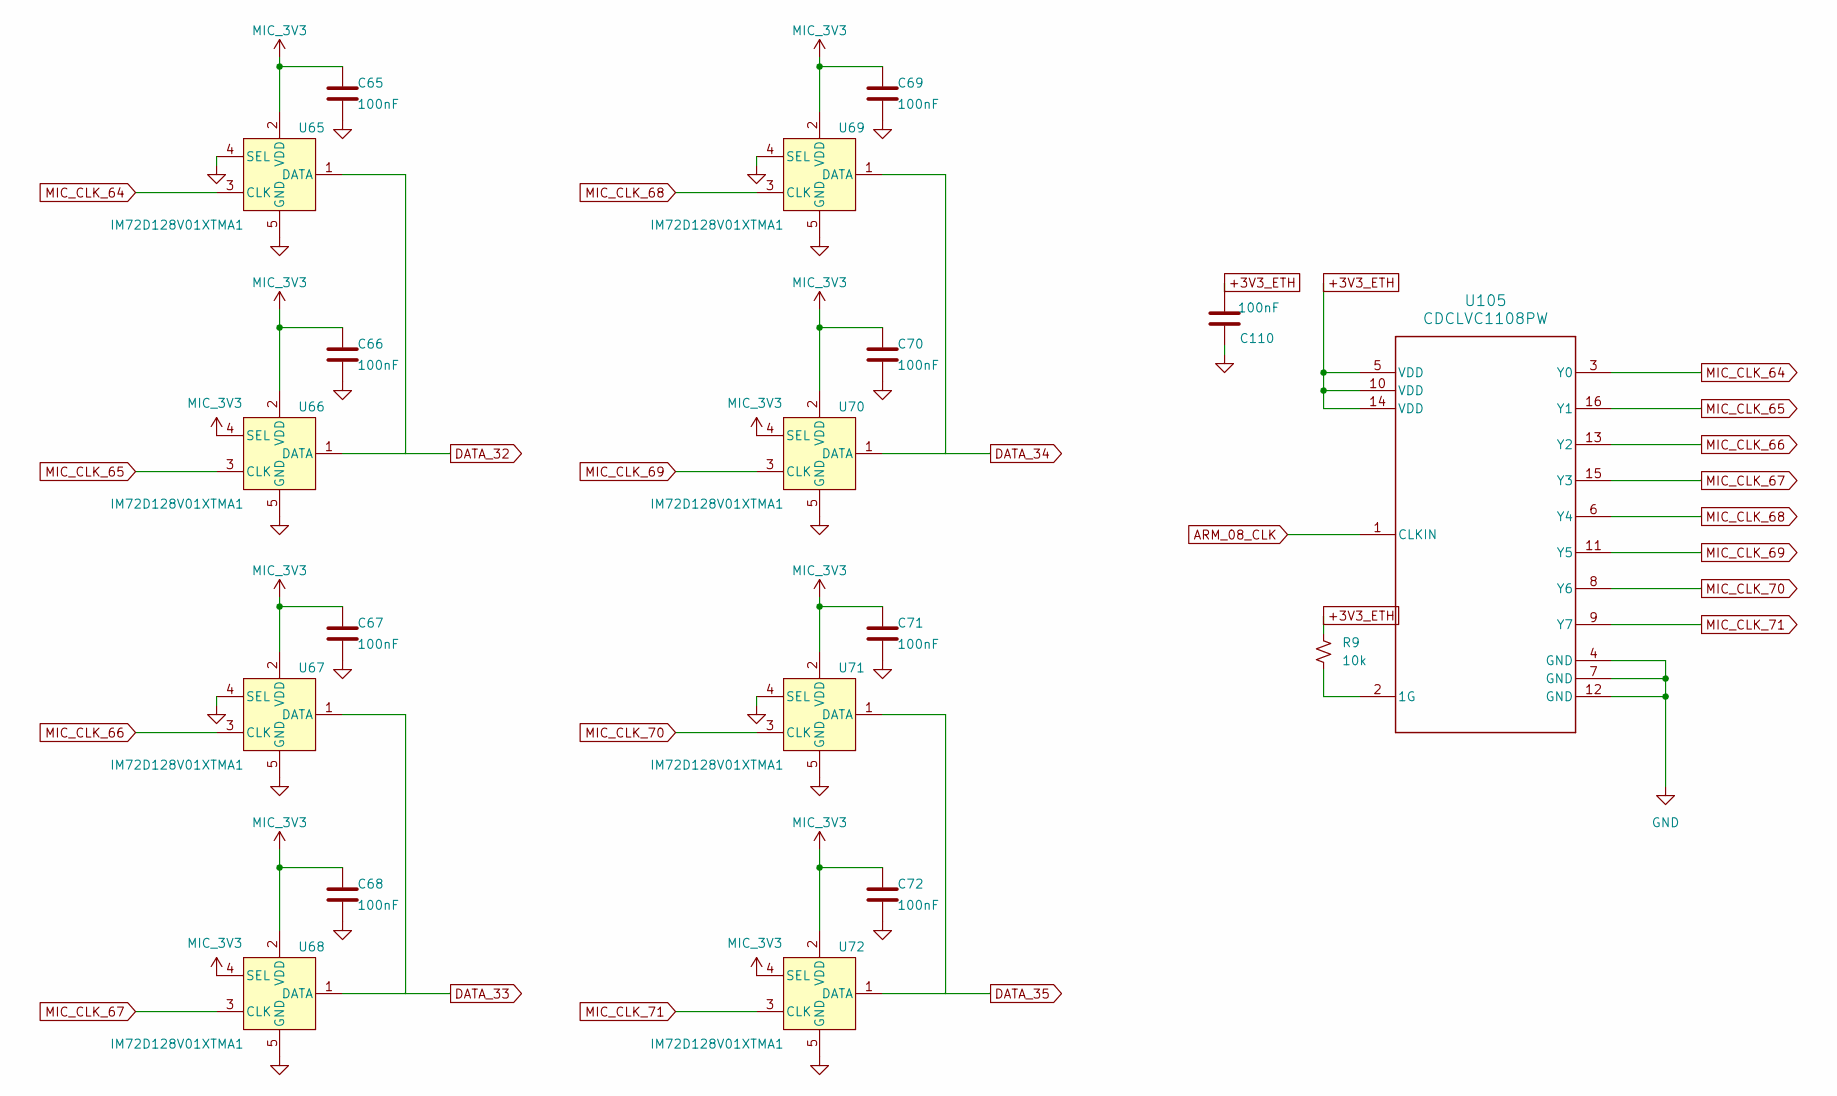
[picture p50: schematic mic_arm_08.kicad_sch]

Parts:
C65, C66, C67, C68, C69, C70, C71, C72, C110: 100nF; C_0603_1608Metric
R9: 10k; R_0603_1608Metric
U65, U66, U67, U68, U69, U70, U71, U72: IM72D128V01XTMA1; IFX-PG-LLGA-5-4
U105: CDCLVC1108PW; PW0016A_N

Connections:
ARM_08_CLK: U105.1 (CLKIN); also elsewhere on the board
DATA_32: U65.1 (DATA), U66.1 (DATA); also elsewhere on the board
DATA_33: U67.1 (DATA), U68.1 (DATA); also elsewhere on the board
DATA_34: U69.1 (DATA), U70.1 (DATA); also elsewhere on the board
DATA_35: U71.1 (DATA), U72.1 (DATA); also elsewhere on the board
GND: C65.2, C66.2, C67.2, C68.2, C69.2, C70.2, C71.2, C72.2, C110.1, U65.4 (SEL), U65.5 (GND), U66.5 (GND), U67.4 (SEL), U67.5 (GND), U68.5 (GND), U69.4 (SEL), U69.5 (GND), U70.5 (GND), U71.4 (SEL), U71.5 (GND), U72.5 (GND), U105.4 (GND), U105.7 (GND), U105.12 (GND); also elsewhere on the board
MIC_3V3: C65.1, C66.1, C67.1, C68.1, C69.1, C70.1, C71.1, C72.1, U65.2 (VDD), U66.2 (VDD), U66.4 (SEL), U67.2 (VDD), U68.2 (VDD), U68.4 (SEL), U69.2 (VDD), U70.2 (VDD), U70.4 (SEL), U71.2 (VDD), U72.2 (VDD), U72.4 (SEL); also elsewhere on the board
MIC_CLK_64: U65.3 (CLK), U105.3 (Y0)
MIC_CLK_65: U66.3 (CLK), U105.16 (Y1)
MIC_CLK_66: U67.3 (CLK), U105.13 (Y2)
MIC_CLK_67: U68.3 (CLK), U105.15 (Y3)
MIC_CLK_68: U69.3 (CLK), U105.6 (Y4)
MIC_CLK_69: U70.3 (CLK), U105.11 (Y5)
MIC_CLK_70: U71.3 (CLK), U105.8 (Y6)
MIC_CLK_71: U72.3 (CLK), U105.9 (Y7)
unnamed: R9.1, U105.2 (1G)


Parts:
C89, C90, C91, C92, C93, C94, C95, C96, C113: 100nF; C_0603_1608Metric
R12: 10k; R_0603_1608Metric
U89, U90, U91, U92, U93, U94, U95, U96: IM72D128V01XTMA1; IFX-PG-LLGA-5-4
U108: CDCLVC1108PW; PW0016A_N

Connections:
ARM_11_CLK: U108.1 (CLKIN); also elsewhere on the board
DATA_44: U89.1 (DATA), U90.1 (DATA); also elsewhere on the board
DATA_45: U91.1 (DATA), U92.1 (DATA); also elsewhere on the board
DATA_46: U93.1 (DATA), U94.1 (DATA); also elsewhere on the board
DATA_47: U95.1 (DATA), U96.1 (DATA); also elsewhere on the board
GND: C89.2, C90.2, C91.2, C92.2, C93.2, C94.2, C95.2, C96.2, C113.1, U89.4 (SEL), U89.5 (GND), U90.5 (GND), U91.4 (SEL), U91.5 (GND), U92.5 (GND), U93.4 (SEL), U93.5 (GND), U94.5 (GND), U95.4 (SEL), U95.5 (GND), U96.5 (GND), U108.4 (GND), U108.7 (GND), U108.12 (GND); also elsewhere on the board
MIC_3V3: C89.1, C90.1, C91.1, C92.1, C93.1, C94.1, C95.1, C96.1, U89.2 (VDD), U90.2 (VDD), U90.4 (SEL), U91.2 (VDD), U92.2 (VDD), U92.4 (SEL), U93.2 (VDD), U94.2 (VDD), U94.4 (SEL), U95.2 (VDD), U96.2 (VDD), U96.4 (SEL); also elsewhere on the board
MIC_CLK_88: U89.3 (CLK), U108.3 (Y0)
MIC_CLK_89: U90.3 (CLK), U108.16 (Y1)
MIC_CLK_90: U91.3 (CLK), U108.13 (Y2)
MIC_CLK_91: U92.3 (CLK), U108.15 (Y3)
MIC_CLK_92: U93.3 (CLK), U108.6 (Y4)
MIC_CLK_93: U94.3 (CLK), U108.11 (Y5)
MIC_CLK_94: U95.3 (CLK), U108.8 (Y6)
MIC_CLK_95: U96.3 (CLK), U108.9 (Y7)
unnamed: R12.1, U108.2 (1G)


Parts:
C1, C2, C3, C4, C5, C6, C7, C8, C114: 100nF; C_0603_1608Metric
R1: 10k; R_0603_1608Metric
U1, U2, U3, U4, U5, U6, U7, U8: IM72D128V01XTMA1; IFX-PG-LLGA-5-4
U97: CDCLVC1108PW; PW0016A_N

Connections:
ARM_00_CLK: U97.1 (CLKIN); also elsewhere on the board
DATA_00: U3.1 (DATA), U4.1 (DATA); also elsewhere on the board
DATA_01: U1.1 (DATA), U2.1 (DATA); also elsewhere on the board
DATA_02: U5.1 (DATA), U6.1 (DATA); also elsewhere on the board
DATA_03: U7.1 (DATA), U8.1 (DATA); also elsewhere on the board
GND: C1.2, C2.2, C3.2, C4.2, C5.2, C6.2, C7.2, C8.2, C114.1, U1.4 (SEL), U1.5 (GND), U2.5 (GND), U3.4 (SEL), U3.5 (GND), U4.5 (GND), U5.4 (SEL), U5.5 (GND), U6.5 (GND), U7.4 (SEL), U7.5 (GND), U8.5 (GND), U97.4 (GND), U97.7 (GND), U97.12 (GND); also elsewhere on the board
MIC_3V3: C1.1, C2.1, C3.1, C4.1, C5.1, C6.1, C7.1, C8.1, U1.2 (VDD), U2.2 (VDD), U2.4 (SEL), U3.2 (VDD), U4.2 (VDD), U4.4 (SEL), U5.2 (VDD), U6.2 (VDD), U6.4 (SEL), U7.2 (VDD), U8.2 (VDD), U8.4 (SEL); also elsewhere on the board
MIC_CLK_00: U1.3 (CLK), U97.3 (Y0)
MIC_CLK_01: U2.3 (CLK), U97.16 (Y1)
MIC_CLK_02: U3.3 (CLK), U97.13 (Y2)
MIC_CLK_03: U4.3 (CLK), U97.15 (Y3)
MIC_CLK_04: U5.3 (CLK), U97.6 (Y4)
MIC_CLK_05: U6.3 (CLK), U97.11 (Y5)
MIC_CLK_06: U7.3 (CLK), U97.8 (Y6)
MIC_CLK_07: U8.3 (CLK), U97.9 (Y7)
unnamed: R1.1, U97.2 (1G)


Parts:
C73, C74, C75, C76, C77, C78, C79, C80, C111: 100nF; C_0603_1608Metric
R10: 10k; R_0603_1608Metric
U73, U74, U75, U76, U77, U78, U79, U80: IM72D128V01XTMA1; IFX-PG-LLGA-5-4
U106: CDCLVC1108PW; PW0016A_N

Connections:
ARM_09_CLK: U106.1 (CLKIN); also elsewhere on the board
DATA_36: U73.1 (DATA), U74.1 (DATA); also elsewhere on the board
DATA_37: U75.1 (DATA), U76.1 (DATA); also elsewhere on the board
DATA_38: U77.1 (DATA), U78.1 (DATA); also elsewhere on the board
DATA_39: U79.1 (DATA), U80.1 (DATA); also elsewhere on the board
GND: C73.2, C74.2, C75.2, C76.2, C77.2, C78.2, C79.2, C80.2, C111.1, U73.4 (SEL), U73.5 (GND), U74.5 (GND), U75.4 (SEL), U75.5 (GND), U76.5 (GND), U77.4 (SEL), U77.5 (GND), U78.5 (GND), U79.4 (SEL), U79.5 (GND), U80.5 (GND), U106.4 (GND), U106.7 (GND), U106.12 (GND); also elsewhere on the board
MIC_3V3: C73.1, C74.1, C75.1, C76.1, C77.1, C78.1, C79.1, C80.1, U73.2 (VDD), U74.2 (VDD), U74.4 (SEL), U75.2 (VDD), U76.2 (VDD), U76.4 (SEL), U77.2 (VDD), U78.2 (VDD), U78.4 (SEL), U79.2 (VDD), U80.2 (VDD), U80.4 (SEL); also elsewhere on the board
MIC_CLK_72: U73.3 (CLK), U106.3 (Y0)
MIC_CLK_73: U74.3 (CLK), U106.16 (Y1)
MIC_CLK_74: U75.3 (CLK), U106.13 (Y2)
MIC_CLK_75: U76.3 (CLK), U106.15 (Y3)
MIC_CLK_76: U77.3 (CLK), U106.6 (Y4)
MIC_CLK_77: U78.3 (CLK), U106.11 (Y5)
MIC_CLK_78: U79.3 (CLK), U106.8 (Y6)
MIC_CLK_79: U80.3 (CLK), U106.9 (Y7)
unnamed: R10.1, U106.2 (1G)

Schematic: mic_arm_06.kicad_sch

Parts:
C49, C50, C51, C52, C53, C54, C55, C56, C108: 100nF; C_0603_1608Metric
R7: 10k; R_0603_1608Metric
U49, U50, U51, U52, U53, U54, U55, U56: IM72D128V01XTMA1; IFX-PG-LLGA-5-4
U103: CDCLVC1108PW; PW0016A_N

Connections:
ARM_06_CLK: U103.1 (CLKIN); also elsewhere on the board
DATA_24: U49.1 (DATA), U50.1 (DATA); also elsewhere on the board
DATA_25: U51.1 (DATA), U52.1 (DATA); also elsewhere on the board
DATA_26: U53.1 (DATA), U54.1 (DATA); also elsewhere on the board
DATA_27: U55.1 (DATA), U56.1 (DATA); also elsewhere on the board
GND: C49.2, C50.2, C51.2, C52.2, C53.2, C54.2, C55.2, C56.2, C108.1, U49.4 (SEL), U49.5 (GND), U50.5 (GND), U51.4 (SEL), U51.5 (GND), U52.5 (GND), U53.4 (SEL), U53.5 (GND), U54.5 (GND), U55.4 (SEL), U55.5 (GND), U56.5 (GND), U103.4 (GND), U103.7 (GND), U103.12 (GND); also elsewhere on the board
MIC_3V3: C49.1, C50.1, C51.1, C52.1, C53.1, C54.1, C55.1, C56.1, U49.2 (VDD), U50.2 (VDD), U50.4 (SEL), U51.2 (VDD), U52.2 (VDD), U52.4 (SEL), U53.2 (VDD), U54.2 (VDD), U54.4 (SEL), U55.2 (VDD), U56.2 (VDD), U56.4 (SEL); also elsewhere on the board
MIC_CLK_48: U49.3 (CLK), U103.3 (Y0)
MIC_CLK_49: U50.3 (CLK), U103.16 (Y1)
MIC_CLK_50: U51.3 (CLK), U103.13 (Y2)
MIC_CLK_51: U52.3 (CLK), U103.15 (Y3)
MIC_CLK_52: U53.3 (CLK), U103.6 (Y4)
MIC_CLK_53: U54.3 (CLK), U103.11 (Y5)
MIC_CLK_54: U55.3 (CLK), U103.8 (Y6)
MIC_CLK_55: U56.3 (CLK), U103.9 (Y7)
unnamed: R7.1, U103.2 (1G)

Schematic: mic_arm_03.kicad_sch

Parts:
C25, C26, C27, C28, C29, C30, C31, C32, C105: 100nF; C_0603_1608Metric
R4: 10k; R_0603_1608Metric
U25, U26, U27, U28, U29, U30, U31, U32: IM72D128V01XTMA1; IFX-PG-LLGA-5-4
U100: CDCLVC1108PW; PW0016A_N

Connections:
ARM_03_CLK: U100.1 (CLKIN); also elsewhere on the board
DATA_12: U25.1 (DATA), U26.1 (DATA); also elsewhere on the board
DATA_13: U27.1 (DATA), U28.1 (DATA); also elsewhere on the board
DATA_14: U29.1 (DATA), U30.1 (DATA); also elsewhere on the board
DATA_15: U31.1 (DATA), U32.1 (DATA); also elsewhere on the board
GND: C25.2, C26.2, C27.2, C28.2, C29.2, C30.2, C31.2, C32.2, C105.1, U25.4 (SEL), U25.5 (GND), U26.5 (GND), U27.4 (SEL), U27.5 (GND), U28.5 (GND), U29.4 (SEL), U29.5 (GND), U30.5 (GND), U31.4 (SEL), U31.5 (GND), U32.5 (GND), U100.4 (GND), U100.7 (GND), U100.12 (GND); also elsewhere on the board
MIC_3V3: C25.1, C26.1, C27.1, C28.1, C29.1, C30.1, C31.1, C32.1, U25.2 (VDD), U26.2 (VDD), U26.4 (SEL), U27.2 (VDD), U28.2 (VDD), U28.4 (SEL), U29.2 (VDD), U30.2 (VDD), U30.4 (SEL), U31.2 (VDD), U32.2 (VDD), U32.4 (SEL); also elsewhere on the board
MIC_CLK_24: U25.3 (CLK), U100.3 (Y0)
MIC_CLK_25: U26.3 (CLK), U100.16 (Y1)
MIC_CLK_26: U27.3 (CLK), U100.13 (Y2)
MIC_CLK_27: U28.3 (CLK), U100.15 (Y3)
MIC_CLK_28: U29.3 (CLK), U100.6 (Y4)
MIC_CLK_29: U30.3 (CLK), U100.11 (Y5)
MIC_CLK_30: U31.3 (CLK), U100.8 (Y6)
MIC_CLK_31: U32.3 (CLK), U100.9 (Y7)
unnamed: R4.1, U100.2 (1G)

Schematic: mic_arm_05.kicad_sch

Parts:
C41, C42, C43, C44, C45, C46, C47, C48, C107: 100nF; C_0603_1608Metric
R6: 10k; R_0603_1608Metric
U41, U42, U43, U44, U45, U46, U47, U48: IM72D128V01XTMA1; IFX-PG-LLGA-5-4
U102: CDCLVC1108PW; PW0016A_N

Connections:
ARM_05_CLK: U102.1 (CLKIN); also elsewhere on the board
DATA_20: U41.1 (DATA), U42.1 (DATA); also elsewhere on the board
DATA_21: U43.1 (DATA), U44.1 (DATA); also elsewhere on the board
DATA_22: U45.1 (DATA), U46.1 (DATA); also elsewhere on the board
DATA_23: U47.1 (DATA), U48.1 (DATA); also elsewhere on the board
GND: C41.2, C42.2, C43.2, C44.2, C45.2, C46.2, C47.2, C48.2, C107.1, U41.4 (SEL), U41.5 (GND), U42.5 (GND), U43.4 (SEL), U43.5 (GND), U44.5 (GND), U45.4 (SEL), U45.5 (GND), U46.5 (GND), U47.4 (SEL), U47.5 (GND), U48.5 (GND), U102.4 (GND), U102.7 (GND), U102.12 (GND); also elsewhere on the board
MIC_3V3: C41.1, C42.1, C43.1, C44.1, C45.1, C46.1, C47.1, C48.1, U41.2 (VDD), U42.2 (VDD), U42.4 (SEL), U43.2 (VDD), U44.2 (VDD), U44.4 (SEL), U45.2 (VDD), U46.2 (VDD), U46.4 (SEL), U47.2 (VDD), U48.2 (VDD), U48.4 (SEL); also elsewhere on the board
MIC_CLK_40: U41.3 (CLK), U102.3 (Y0)
MIC_CLK_41: U42.3 (CLK), U102.16 (Y1)
MIC_CLK_42: U43.3 (CLK), U102.13 (Y2)
MIC_CLK_43: U44.3 (CLK), U102.15 (Y3)
MIC_CLK_44: U45.3 (CLK), U102.6 (Y4)
MIC_CLK_45: U46.3 (CLK), U102.11 (Y5)
MIC_CLK_46: U47.3 (CLK), U102.8 (Y6)
MIC_CLK_47: U48.3 (CLK), U102.9 (Y7)
unnamed: R6.1, U102.2 (1G)

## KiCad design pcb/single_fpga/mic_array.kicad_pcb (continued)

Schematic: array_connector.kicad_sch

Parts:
J1: AXK6S80347YG; CONN80_AXK6S80347YG_PAN

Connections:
+3V6: J1.1, J1.2, J1.3, J1.4, J1.5, J1.6, J1.7, J1.8; also elsewhere on the board
DATA_00: J1.11; also elsewhere on the board
DATA_01: J1.12; also elsewhere on the board
DATA_02: J1.13; also elsewhere on the board
DATA_03: J1.14; also elsewhere on the board
DATA_04: J1.15; also elsewhere on the board
DATA_05: J1.16; also elsewhere on the board
DATA_06: J1.17; also elsewhere on the board
DATA_07: J1.18; also elsewhere on the board
DATA_08: J1.21; also elsewhere on the board
DATA_09: J1.22; also elsewhere on the board
DATA_10: J1.23; also elsewhere on the board
DATA_11: J1.24; also elsewhere on the board
DATA_12: J1.25; also elsewhere on the board
DATA_13: J1.26; also elsewhere on the board
DATA_14: J1.27; also elsewhere on the board
DATA_15: J1.28; also elsewhere on the board
DATA_16: J1.31; also elsewhere on the board
DATA_17: J1.32; also elsewhere on the board
DATA_18: J1.33; also elsewhere on the board
DATA_19: J1.34; also elsewhere on the board
DATA_20: J1.35; also elsewhere on the board
DATA_21: J1.36; also elsewhere on the board
DATA_22: J1.37; also elsewhere on the board
DATA_23: J1.38; also elsewhere on the board
DATA_24: J1.78; also elsewhere on the board
DATA_25: J1.77; also elsewhere on the board
DATA_26: J1.76; also elsewhere on the board
DATA_27: J1.75; also elsewhere on the board
DATA_28: J1.74; also elsewhere on the board
DATA_29: J1.73; also elsewhere on the board
DATA_30: J1.72; also elsewhere on the board
DATA_31: J1.71; also elsewhere on the board
DATA_32: J1.68; also elsewhere on the board
DATA_33: J1.67; also elsewhere on the board
DATA_34: J1.66; also elsewhere on the board
DATA_35: J1.65; also elsewhere on the board
DATA_36: J1.64; also elsewhere on the board
DATA_37: J1.63; also elsewhere on the board
DATA_38: J1.62; also elsewhere on the board
DATA_39: J1.61; also elsewhere on the board
DATA_40: J1.58; also elsewhere on the board
DATA_41: J1.57; also elsewhere on the board
DATA_42: J1.56; also elsewhere on the board
DATA_43: J1.55; also elsewhere on the board
DATA_44: J1.54; also elsewhere on the board
DATA_45: J1.53; also elsewhere on the board
DATA_46: J1.52; also elsewhere on the board
DATA_47: J1.51; also elsewhere on the board
GND: J1.9, J1.10, J1.19, J1.20, J1.29, J1.30, J1.39, J1.40, J1.49, J1.50, J1.59, J1.60, J1.69, J1.70, J1.79, J1.80; also elsewhere on the board

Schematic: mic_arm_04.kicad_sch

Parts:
C33, C34, C35, C36, C37, C38, C39, C40, C106: 100nF; C_0603_1608Metric
R5: 10k; R_0603_1608Metric
U33, U34, U35, U36, U37, U38, U39, U40: IM72D128V01XTMA1; IFX-PG-LLGA-5-4
U101: CDCLVC1108PW; PW0016A_N

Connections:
ARM_04_CLK: U101.1 (CLKIN); also elsewhere on the board
DATA_16: U33.1 (DATA), U34.1 (DATA); also elsewhere on the board
DATA_17: U35.1 (DATA), U36.1 (DATA); also elsewhere on the board
DATA_18: U37.1 (DATA), U38.1 (DATA); also elsewhere on the board
DATA_19: U39.1 (DATA), U40.1 (DATA); also elsewhere on the board
GND: C33.2, C34.2, C35.2, C36.2, C37.2, C38.2, C39.2, C40.2, C106.2, U33.4 (SEL), U33.5 (GND), U34.5 (GND), U35.4 (SEL), U35.5 (GND), U36.5 (GND), U37.4 (SEL), U37.5 (GND), U38.5 (GND), U39.4 (SEL), U39.5 (GND), U40.5 (GND), U101.4 (GND), U101.7 (GND), U101.12 (GND); also elsewhere on the board
MIC_3V3: C33.1, C34.1, C35.1, C36.1, C37.1, C38.1, C39.1, C40.1, U33.2 (VDD), U34.2 (VDD), U34.4 (SEL), U35.2 (VDD), U36.2 (VDD), U36.4 (SEL), U37.2 (VDD), U38.2 (VDD), U38.4 (SEL), U39.2 (VDD), U40.2 (VDD), U40.4 (SEL); also elsewhere on the board
MIC_CLK_32: U33.3 (CLK), U101.3 (Y0)
MIC_CLK_33: U34.3 (CLK), U101.16 (Y1)
MIC_CLK_34: U35.3 (CLK), U101.13 (Y2)
MIC_CLK_35: U36.3 (CLK), U101.15 (Y3)
MIC_CLK_36: U37.3 (CLK), U101.6 (Y4)
MIC_CLK_37: U38.3 (CLK), U101.11 (Y5)
MIC_CLK_38: U39.3 (CLK), U101.8 (Y6)
MIC_CLK_39: U40.3 (CLK), U101.9 (Y7)
unnamed: R5.1, U101.2 (1G)

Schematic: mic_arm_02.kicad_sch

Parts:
C17, C18, C19, C20, C21, C22, C23, C24, C116: 100nF; C_0603_1608Metric
R3: 10k; R_0603_1608Metric
U17, U18, U19, U20, U21, U22, U23, U24: IM72D128V01XTMA1; IFX-PG-LLGA-5-4
U99: CDCLVC1108PW; PW0016A_N

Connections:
ARM_02_CLK: U99.1 (CLKIN); also elsewhere on the board
DATA_08: U17.1 (DATA), U18.1 (DATA); also elsewhere on the board
DATA_09: U19.1 (DATA), U20.1 (DATA); also elsewhere on the board
DATA_10: U21.1 (DATA), U22.1 (DATA); also elsewhere on the board
DATA_11: U23.1 (DATA), U24.1 (DATA); also elsewhere on the board
GND: C17.2, C18.2, C19.2, C20.2, C21.2, C22.2, C23.2, C24.2, C116.1, U17.4 (SEL), U17.5 (GND), U18.5 (GND), U19.4 (SEL), U19.5 (GND), U20.5 (GND), U21.4 (SEL), U21.5 (GND), U22.5 (GND), U23.4 (SEL), U23.5 (GND), U24.5 (GND), U99.4 (GND), U99.7 (GND), U99.12 (GND); also elsewhere on the board
MIC_3V3: C17.1, C18.1, C19.1, C20.1, C21.1, C22.1, C23.1, C24.1, U17.2 (VDD), U18.2 (VDD), U18.4 (SEL), U19.2 (VDD), U20.2 (VDD), U20.4 (SEL), U21.2 (VDD), U22.2 (VDD), U22.4 (SEL), U23.2 (VDD), U24.2 (VDD), U24.4 (SEL); also elsewhere on the board
MIC_CLK_16: U17.3 (CLK), U99.3 (Y0)
MIC_CLK_17: U18.3 (CLK), U99.16 (Y1)
MIC_CLK_18: U19.3 (CLK), U99.13 (Y2)
MIC_CLK_19: U20.3 (CLK), U99.15 (Y3)
MIC_CLK_20: U21.3 (CLK), U99.6 (Y4)
MIC_CLK_21: U22.3 (CLK), U99.11 (Y5)
MIC_CLK_22: U23.3 (CLK), U99.8 (Y6)
MIC_CLK_23: U24.3 (CLK), U99.9 (Y7)
unnamed: R3.1, U99.2 (1G)

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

Board: 4 copper layers, 320.0 x 320.0 mm, 252 parts (0 on the bottom side), 174 nets.

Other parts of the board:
HCAM1, HCAM2, HCAM3, HCAM4: MountingHole_2.2mm_M2
HENC1, HENC2, HENC3, HENC4: MountingHole_4.3mm_M4

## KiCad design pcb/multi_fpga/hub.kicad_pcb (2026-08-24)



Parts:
A5: FTDI UM232H USB Hi-Speed FT232H Development Module; UM232H
A6: DIP-48_W15.24mm_Socket
C13: 100uF; CP_Elec_10x10
C14: 10uF; C_1206_3216Metric
C15: .1uF; C_0603_1608Metric
C16, C17: 1uF; C_1206_3216Metric
J9: Cluster00_Power; PinSocket_1x02_P2.54mm_Vertical
J10: Cluster03_Power; PinSocket_1x02_P2.54mm_Vertical
J11: Cluster01_Power; PinSocket_1x02_P2.54mm_Vertical
J12: Cluster02_Power; PinSocket_1x02_P2.54mm_Vertical
J13: Main Power Input; JST_XH_B2B-XH-A_1x02_P2.50mm_Vertical
J14: Cluster03_SpokeBus; PinSocket_2x06_P2.54mm_Vertical
J15: Cluster00_SpokeBus; PinSocket_2x06_P2.54mm_Vertical
J16: Cluster01_SpokeBus; PinSocket_2x06_P2.54mm_Vertical
J17: Cluster02_SpokeBus; PinSocket_2x06_P2.54mm_Vertical
J19: FPGA Reset; PinHeader_1x03_P2.54mm_Vertical
R1, R2, R3, R4, R5: 10k; R_0603_1608Metric
VR5: MCP1700T-3302E/TT; SOT-23
Y1: ECS-TXO-5032-122.8-TR

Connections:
+3V3: C15.1, C17.1, R5.2, VR5.2 (VO), Y1.4 (VDD)
+5V: A6.24 (VU), C13.1, C14.1, C16.1, J9.1, J10.1, J11.1, J12.1, J13.1, VR5.3 (VI)
/OE#: A5.J1-8 (AC6), R2.1
/RD#: A5.J1-12 (AC2), R4.1
/RESET_N: A6.48 (PIO48), J19.1
/RXF#: A5.J1-14 (AC0)
/SIWU#: A5.J1-10 (AC4), R3.1
FPGA_RESET_N: J14.11, J15.11, J16.11, J17.11, J19.2
GND: A5.J1-1 (GND), A5.J2-1 (SLD), A5.J2-6 (GND), A6.25 (GND), C13.2, C14.2, C15.2, C16.2, C17.2, J9.2, J10.2, J11.2, J12.2, J13.2, J14.5, J14.6, J15.5, J15.6, J16.5, J16.6, J17.5, J17.6, J19.3, VR5.1 (GND), Y1.2 (GND)
unnamed: A5.J2-2 (VIO), A5.J2-3 (3V3), R1.2, R2.2, R3.2, R4.2
unnamed: A5.J1-2 (5V0), A5.J1-3 (USB)
unnamed: A5.J1-4 (RST#), R1.1
SPOKE0_D0: A6.1 (PIO01), J15.1
SPOKE0_D1: A6.2 (PIO02), J15.2
SPOKE0_D2: A6.3 (PIO03), J15.3
SPOKE0_D3: A6.4 (PIO04), J15.4
SPOKE0_D4: A6.5 (PIO05), J15.7
SPOKE0_D5: A6.6 (PIO06), J15.8
SPOKE0_STROBE: A6.7 (PIO07), J15.9
SPOKE1_D0: A6.8 (PIO08), J16.1
SPOKE1_D1: A6.9 (PIO09), J16.2
SPOKE1_D2: A6.10 (PIO10), J16.3
SPOKE1_D3: A6.11 (PIO11), J16.4
SPOKE1_D4: A6.12 (PIO12), J16.7
SPOKE1_D5: A6.13 (PIO13), J16.8
SPOKE1_STROBE: A6.14 (PIO14), J16.9
SPOKE2_D0: A6.17 (PIO17), J17.1
SPOKE2_D1: A6.18 (PIO18), J17.2
SPOKE2_D2: A6.19 (PIO19), J17.3
SPOKE2_D3: A6.20 (PIO20), J17.4
SPOKE2_D4: A6.21 (PIO21), J17.7
SPOKE2_D5: A6.22 (PIO22), J17.8
SPOKE2_STROBE: A6.23 (PIO23), J17.9
SPOKE3_D0: A6.26 (PIO26), J14.1
SPOKE3_D1: A6.27 (PIO27), J14.2
SPOKE3_D2: A6.28 (PIO28), J14.3
SPOKE3_D3: A6.29 (PIO29), J14.4
SPOKE3_D4: A6.30 (PIO30), J14.7
SPOKE3_D5: A6.31 (PIO31), J14.8
SPOKE3_STROBE: A6.32 (PIO32), J14.9
SPOKES_ALIVE: A6.33 (PIO33), J14.12, J15.12, J16.12, J17.12, R5.1
SPOKE_CLK: A6.34 (PIO34), J14.10, J15.10, J16.10, J17.10
TCXO_CLK: A6.47 (PIO47), Y1.3 (OUTPUT)
USB_CLKOUT: A5.J1-9 (AC5), A6.46 (PIO46)
USB_D0: A5.J2-7 (AD0), A6.35 (PIO35)
USB_D1: A5.J2-8 (AD1), A6.36 (PIO36)
USB_D2: A5.J2-9 (AD2), A6.37 (PIO37)
USB_D3: A5.J2-10 (AD3), A6.38 (PIO38)
USB_D4: A5.J2-11 (AD4), A6.39 (PIO39)
USB_D5: A5.J2-12 (AD5), A6.40 (PIO40)
USB_D6: A5.J2-13 (AD6), A6.41 (PIO41)
USB_D7: A5.J2-14 (AD7), A6.42 (PIO42)
USB_TXE_N: A5.J1-13 (AC1), A6.44 (PIO44)
USB_WR_N: A5.J1-11 (AC3), A6.43 (PIO43)

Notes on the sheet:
USB-C/Micro-B cable to Raspberry Pi 5 USB 3.0 port Standalone: Pi 5 runs beamforming locally Tethered: Pi 5 relays stream out its own on-board GbE to external host
Jumper between 1-2 for normal operation Jumper between 2-3 to hold spoke FPGAs in Reset



Board: 4 copper layers, 131.8 x 128.5 mm, 24 parts (8 on the bottom side), 53 nets.

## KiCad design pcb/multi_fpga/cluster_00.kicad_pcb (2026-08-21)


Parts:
A1: DIP-48_W15.24mm_Socket
C1: 10uF; C_1206_3216Metric; Voltage 10V; Tolerance 20%
C2, C3: 1uF; C_0603_1608Metric
J1: Cluster0_SpokeBus; PinHeader_2x06_P2.54mm_Vertical
J2: Cluster0_Power
VR1: MCP1700x-330xxTT; SOT-23

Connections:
+5V: A1.24 (VU), C1.1, C2.1, J2.1, VR1.3 (VI)
C0_3V3: C3.1, VR1.2 (VO); also elsewhere on the board
C0_PDM_CLK: A1.1 (PIO01); also elsewhere on the board
DATA_00: A1.2 (PIO02); also elsewhere on the board
DATA_01: A1.3 (PIO03); also elsewhere on the board
DATA_02: A1.4 (PIO04); also elsewhere on the board
DATA_03: A1.5 (PIO05); also elsewhere on the board
DATA_04: A1.6 (PIO06); also elsewhere on the board
DATA_05: A1.7 (PIO07); also elsewhere on the board
DATA_06: A1.8 (PIO08); also elsewhere on the board
DATA_07: A1.9 (PIO09); also elsewhere on the board
DATA_08: A1.10 (PIO10); also elsewhere on the board
DATA_09: A1.11 (PIO11); also elsewhere on the board
DATA_10: A1.12 (PIO12); also elsewhere on the board
DATA_11: A1.13 (PIO13); also elsewhere on the board
FPGA_RESET_N: A1.29 (PIO29), J1.11
GND: A1.25 (GND), C1.2, C2.2, C3.2, J1.5, J1.6, J2.2, VR1.1 (GND); also elsewhere on the board
SPOKE0_ALIVE: A1.30 (PIO30), J1.12
SPOKE0_CLK: A1.18 (PIO18), J1.10
SPOKE0_D0: A1.20 (PIO20), J1.1
SPOKE0_D1: A1.21 (PIO21), J1.2
SPOKE0_D2: A1.22 (PIO22), J1.3
SPOKE0_D3: A1.23 (PIO23), J1.4
SPOKE0_D4: A1.26 (PIO26), J1.7
SPOKE0_D5: A1.27 (PIO27), J1.8
SPOKE0_STROBE: A1.28 (PIO28), J1.9


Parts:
C18, C19, C20, C21, C22, C23, C24, C25: 100nF; C_0603_1608Metric
U1, U2, U3, U4, U5, U6, U7, U8: IM72D128V01XTMA1

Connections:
C0_3V3: C18.1, C19.1, C20.1, C21.1, C22.1, C23.1, C24.1, C25.1, U1.2 (VDD), U2.2 (VDD), U2.4 (SEL), U3.2 (VDD), U4.2 (VDD), U4.4 (SEL), U5.2 (VDD), U6.2 (VDD), U6.4 (SEL), U7.2 (VDD), U8.2 (VDD), U8.4 (SEL); also elsewhere on the board
C0_PDM_CLK: U1.3 (CLK), U2.3 (CLK), U3.3 (CLK), U4.3 (CLK), U5.3 (CLK), U6.3 (CLK), U7.3 (CLK), U8.3 (CLK); also elsewhere on the board
DATA_00: U1.1 (DATA), U2.1 (DATA); also elsewhere on the board
DATA_01: U3.1 (DATA), U4.1 (DATA); also elsewhere on the board
DATA_02: U5.1 (DATA), U6.1 (DATA); also elsewhere on the board
DATA_03: U7.1 (DATA), U8.1 (DATA); also elsewhere on the board
GND: C18.2, C19.2, C20.2, C21.2, C22.2, C23.2, C24.2, C25.2, U1.4 (SEL), U1.5 (GND), U2.5 (GND), U3.4 (SEL), U3.5 (GND), U4.5 (GND), U5.4 (SEL), U5.5 (GND), U6.5 (GND), U7.4 (SEL), U7.5 (GND), U8.5 (GND); also elsewhere on the board

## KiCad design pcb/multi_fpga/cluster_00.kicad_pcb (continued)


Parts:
C26, C27, C28, C29, C30, C31, C32, C33: 100nF; C_0603_1608Metric
U9, U10, U11, U12, U13, U14, U15, U16: IM72D128V01XTMA1

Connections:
C0_3V3: C26.1, C27.1, C28.1, C29.1, C30.1, C31.1, C32.1, C33.1, U9.2 (VDD), U10.2 (VDD), U10.4 (SEL), U11.2 (VDD), U12.2 (VDD), U12.4 (SEL), U13.2 (VDD), U14.2 (VDD), U14.4 (SEL), U15.2 (VDD), U16.2 (VDD), U16.4 (SEL); also elsewhere on the board
C0_PDM_CLK: U9.3 (CLK), U10.3 (CLK), U11.3 (CLK), U12.3 (CLK), U13.3 (CLK), U14.3 (CLK), U15.3 (CLK), U16.3 (CLK); also elsewhere on the board
DATA_04: U15.1 (DATA), U16.1 (DATA); also elsewhere on the board
DATA_05: U11.1 (DATA), U12.1 (DATA); also elsewhere on the board
DATA_06: U13.1 (DATA), U14.1 (DATA); also elsewhere on the board
DATA_07: U9.1 (DATA), U10.1 (DATA); also elsewhere on the board
GND: C26.2, C27.2, C28.2, C29.2, C30.2, C31.2, C32.2, C33.2, U9.4 (SEL), U9.5 (GND), U10.5 (GND), U11.4 (SEL), U11.5 (GND), U12.5 (GND), U13.4 (SEL), U13.5 (GND), U14.5 (GND), U15.4 (SEL), U15.5 (GND), U16.5 (GND); also elsewhere on the board


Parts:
C34, C35, C36, C37, C38, C39, C40, C41: 100nF; C_0603_1608Metric
U17, U18, U19, U20, U21, U22, U23, U24: IM72D128V01XTMA1

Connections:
C0_3V3: C34.1, C35.1, C36.1, C37.1, C38.1, C39.1, C40.1, C41.1, U17.2 (VDD), U18.2 (VDD), U18.4 (SEL), U19.2 (VDD), U20.2 (VDD), U20.4 (SEL), U21.2 (VDD), U22.2 (VDD), U22.4 (SEL), U23.2 (VDD), U24.2 (VDD), U24.4 (SEL); also elsewhere on the board
C0_PDM_CLK: U17.3 (CLK), U18.3 (CLK), U19.3 (CLK), U20.3 (CLK), U21.3 (CLK), U22.3 (CLK), U23.3 (CLK), U24.3 (CLK); also elsewhere on the board
DATA_08: U23.1 (DATA), U24.1 (DATA); also elsewhere on the board
DATA_09: U17.1 (DATA), U18.1 (DATA); also elsewhere on the board
DATA_10: U21.1 (DATA), U22.1 (DATA); also elsewhere on the board
DATA_11: U19.1 (DATA), U20.1 (DATA); also elsewhere on the board
GND: C34.2, C35.2, C36.2, C37.2, C38.2, C39.2, C40.2, C41.2, U17.4 (SEL), U17.5 (GND), U18.5 (GND), U19.4 (SEL), U19.5 (GND), U20.5 (GND), U21.4 (SEL), U21.5 (GND), U22.5 (GND), U23.4 (SEL), U23.5 (GND), U24.5 (GND); also elsewhere on the board


Board: 4 copper layers, 208.8 x 161.7 mm, 58 parts (0 on the bottom side), 26 nets.

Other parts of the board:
H1A: MountingHole_2.7mm_M2.5
H1E1, H1E2: MountingHole_3.2mm_M3

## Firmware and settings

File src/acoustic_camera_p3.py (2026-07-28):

#!/usr/bin/env python3
"""Phase 3 live acoustic camera: UMA-16 v2 (16-mic 4×4 URA) → 2D beamform → OpenCV overlay.

Usage:
    python src/acoustic_camera_p3.py
    python src/acoustic_camera_p3.py --algo mvdr
    python src/acoustic_camera_p3.py --algo music --nsrc 2
    python src/acoustic_camera_p3.py --cal test/UMA16/cal.npy --video 4

The beamforming frequency is set live by the on-screen F lo / F hi sliders
(freq = midpoint of the selected band), not by a CLI argument.
"""
import argparse
import collections
import json
import subprocess
import sys
import threading
import time
from pathlib import Path

import cv2
import numpy as np
import sounddevice as sd

from beamforming import (FS, N_MICS, NYQUIST,
                         beamform_ds, beamform_mvdr, beamform_clean,
                         beamform_music, compute_csm)

# UPS battery gauge (Waveshare UPS 3S, see RASPBERRY_PI.md §8) — its INA219 driver
# lives outside src/, so it needs its directory added to sys.path. Only present on
# the Pi deployment (needs apt's python3-smbus, not pip) — ImportError on a dev
# machine just means the battery indicator stays hidden (see _poll_battery).
sys.path.insert(0, str(Path(__file__).resolve().parent.parent / 'ups' / 'UPS_Module_3S_V2'))
try:
    from INA219 import INA219
except ImportError:
    INA219 = None


# --- Overlay rendering ---

_REF_POWER_FLOOR = 1e-10  # shared 0 dB reference: auto-mode's initial ref_power AND
                           # manual-mode's fixed reference


def acoustic_overlay(P_flat, frame, N_az, N_el, ref, alpha=0.5, db_range=30,
                      auto=True, thresh_db=30.0, crop_frac=None):
    """Blend 2D power map onto video frame as full-frame overlay.

    auto=True (default): percentile-stretch, ref-normalized against the caller's
    running-max `ref_power` — original behavior.
    auto=False: caller passes ref=_REF_POWER_FLOOR. Hard-gates on thresh_db: cells
    below thresh_db show the plain camera frame, untouched (no tint); cells at/above
    it are colored, rescaled over a fixed db_range-wide span starting at thresh_db
    (thresh_db + db_range saturates at the hottest color).

    crop_frac=(fx0, fx1, fy0, fy1): optional az/el sub-range, as fractions of the
    full az_fov/el_fov extent, to render instead of the whole grid — used by Zoom
    mode so the heatmap lines up with a cropped/zoomed-in video frame that only
    shows that same az/el sub-range.
    """
    h, w = frame.shape[:2]
    P_db = 10 * np.log10(np.maximum(P_flat.reshape(N_az, N_el) / max(ref, 1e-30), 1e-10))

    if auto:
        # Percentile stretch: maps 10th–100th percentile to full colormap range
        p_lo = np.percentile(P_db, 10)
        p_hi = P_db.max()
        norm = np.clip((P_db - p_lo) / max(p_hi - p_lo, 1e-6), 0, 1)
    else:
        norm = np.clip((P_db - thresh_db) / db_range, 0, 1)

    # Remap axes: (N_az, N_el) → (N_el, N_az) with +el at top (screen y=0)
    img8 = (norm.T[::-1, :] * 255).astype(np.uint8)
    # Gate mask (manual mode only): kept as its own uint8 grid, resized with nearest-
    # neighbor separately from img8's linear resize, so the gate stays a hard edge at
    # cell boundaries instead of picking up interpolation blur at the mask's edges.
    mask8 = None if auto else ((P_db >= thresh_db).T[::-1, :] * 255).astype(np.uint8)
    if crop_frac is not None:
        fx0, fx1, fy0, fy1 = crop_frac
        n_el, n_az = img8.shape
        c0 = max(0, min(n_az - 1, int(fx0 * n_az)))
        c1 = max(c0 + 1, min(n_az, int(np.ceil(fx1 * n_az))))
        r0 = max(0, min(n_el - 1, int(fy0 * n_el)))
        r1 = max(r0 + 1, min(n_el, int(np.ceil(fy1 * n_el))))
        img8 = img8[r0:r1, c0:c1]
        if mask8 is not None:
            mask8 = mask8[r0:r1, c0:c1]
    colored = cv2.applyColorMap(
        cv2.resize(img8, (w, h), interpolation=cv2.INTER_LINEAR),
        cv2.COLORMAP_JET,
    )
    blended = cv2.addWeighted(frame, 1 - alpha, colored, alpha, 0)
    if mask8 is None:
        return blended
    mask_full = cv2.resize(mask8, (w, h), interpolation=cv2.INTER_NEAREST) > 0
    return np.where(mask_full[..., None], blended, frame)


def spectrum_panel(audio_arr, w, freq_mark, n_bars=64, height=90, fmin=0, fmax=6000):
    """Render real-time per-band power spectrum as a standalone strip
    (frequency axis left-to-right, magnitude as bar height)."""
    panel = np.full((height, w, 3), 28, dtype=np.uint8)
    block = 2048
    if audio_arr is None or audio_arr.shape[0] < block:
        return panel
    seg = audio_arr[-block:] * np.hanning(block)[:, np.newaxis]
    F = np.fft.rfft(seg, axis=0)
    psd = np.mean(np.abs(F) ** 2, axis=1)
    bin_freqs = np.fft.rfftfreq(block, 1.0 / FS)

    edges = np.linspace(fmin, fmax, n_bars + 1)
    bar_power = np.array([
        psd[(bin_freqs >= edges[k]) & (bin_freqs < edges[k + 1])].mean()
        if np.any((bin_freqs >= edges[k]) & (bin_freqs < edges[k + 1])) else 0.0
        for k in range(n_bars)
    ])
    bar_db = 10 * np.log10(bar_power + 1e-30)
    norm = np.clip((bar_db - bar_db.max() + 40) / 40, 0, 1)

    LABEL_H = 18   # pixels reserved at the bottom for axis labels (fits the larger tick font)
    bar_top = height - LABEL_H

    for k, v in enumerate(norm):
        x0 = int(k * w / n_bars)
        x1 = max(x0 + 1, int((k + 1) * w / n_bars))
        bar_h = int(v * (bar_top - 4))
        if bar_h > 0:
            cv2.rectangle(panel, (x0, bar_top - bar_h), (x1 - 1, bar_top - 1), (0, 200, 80), -1)

    span = max(fmax - fmin, 1)
    xf = max(1, min(w - 2, int((freq_mark - fmin) / span * w)))
    cv2.line(panel, (xf, 0), (xf, bar_top), (255, 255, 255), 2)
    if fmin < NYQUIST < fmax:
        xn = max(1, min(w - 2, int((NYQUIST - fmin) / span * w)))
        cv2.line(panel, (xn, 0), (xn, bar_top), (255, 0, 255), 1)

    # Frequency axis ticks and labels
    steps = [100, 200, 500, 1000, 2000, 5000]
    step = next((s for s in steps if span / s <= 6), 5000)
    first = int(np.ceil(fmin / step)) * step
    for f in range(first, fmax + 1, step):
        xl = int((f - fmin) / span * w)
        if xl < 2 or xl > w - 2:
            continue
        cv2.line(panel, (xl, bar_top), (xl, bar_top + 3), (140, 140, 140), 1)
        lbl = f'{f // 1000}k' if f % 1000 == 0 else f'{f / 1000:.1f}k' if f >= 1000 else str(f)
        (lw, _), _ = cv2.getTextSize(lbl, cv2.FONT_HERSHEY_SIMPLEX, 0.4, 1)
        cv2.putText(panel, lbl, (xl - lw // 2, height - 3),
                    cv2.FONT_HERSHEY_SIMPLEX, 0.4, (160, 160, 160), 1)

    return panel


# --- Virtual sliders (mouse/touch-draggable) ---
# Layout, top to bottom: video frame -> Fhi strip -> spectrum plot -> Flo strip.
# Fhi and Flo are on opposite sides of the spectrum plot (not stacked together) so
# they have enough vertical separation to be reliable touch targets on a touchscreen.

_SLIDER_H = 44          # height of each individual slider strip
_SPECTRUM_H = 90        # height of the spectrum panel between the two slider strips
_FREQ_MAX = 8000        # shared max for both sliders, so the same track position means the same Hz on either

_SLIDER_FONT_SCALE = 0.7   # larger than the track-side margins strictly need, for
_SLIDER_FONT_THICK = 2     # readability — label and value live outside the track's
                           # x-range (see _track_geom); the handle is clamped to that
                           # same range below so it can't overhang into the margins
                           # and collide with them at the extreme ends of the range.
_SUB_FONT_SCALE = 0.45     # "hi"/"lo" subscript on the "F" label — smaller and
_SUB_FONT_THICK = 1        # baseline-shifted down (see _slider_strip)
_SUB_GAP = 2               # horizontal gap between "F" and its subscript
_SUB_DROP = 5              # how far the subscript's baseline sits below "F"'s
_SLIDER_TEXT_PAD = 6       # gap from the strip's left/right edge to the label/value text

# Track insets are asymmetric on purpose: the label ("F" + subscript, narrow) and the
# value ("NNNN Hz", up to 4 digits, much wider) need different amounts of margin to
# leave the *same visual gap* to the track on both sides. Sized from actual glyph
# widths (worst case: "hi"/"lo", whichever is wider; value width at _FREQ_MAX, the
# widest the live value ever gets) rather than hardcoded, so this stays correct if the
# fonts or _FREQ_MAX ever change.
_TRACK_GAP = 30  # desired empty space between the track and the text on each side
_label_w = max(
    cv2.getTextSize('F', cv2.FONT_HERSHEY_SIMPLEX, _SLIDER_FONT_SCALE, _SLIDER_FONT_THICK)[0][0]
    + _SUB_GAP
    + cv2.getTextSize(sub, cv2.FONT_HERSHEY_SIMPLEX, _SUB_FONT_SCALE, _SUB_FONT_THICK)[0][0]
    for sub in ('hi', 'lo')
)
_value_w_max = cv2.getTextSize(f'{_FREQ_MAX} Hz', cv2.FONT_HERSHEY_SIMPLEX,
                                _SLIDER_FONT_SCALE, _SLIDER_FONT_THICK)[0][0]
_TRACK_LEFT = _SLIDER_TEXT_PAD + _label_w + _TRACK_GAP
_TRACK_RIGHT = _SLIDER_TEXT_PAD + _value_w_max + _TRACK_GAP

# Settings tab + popup (auto/manual range toggle + energy threshold), drawn inside the
# video frame itself rather than as a new full-width strip, since the display is fit
# exactly to a 1280x720 touch panel (see Picam2Capture's size comment below).
_TAB_SIZE = 48          # settings tab is a square button in the video frame's corner
                        # (sized for a comfortable touch target, not just a mouse click)
_TAB_MARGIN = 8         # inset from the video frame's top-right corner
_BATT_TAB_GAP = 16      # horizontal gap between the battery indicator and the tab,
                        # wider than _TAB_MARGIN so the tab keeps clear touch space
_POPUP_W = 260          # popup panel width (height is derived — see _popup_layout)
_POPUP_PAD = 8          # inner padding for popup contents
_POPUP_BTN_H = 28       # AUTO/MANUAL toggle button height
_POPUP_ROW_GAP = 8      # vertical gap between stacked popup rows
_THRESH_MAX = 100       # thresh_db slider range: 0-100 dB
_ALGOS = ['ds', 'mvdr', 'clean', 'music']  # algorithm dropdown order
_ALGO_ROW_H = 26        # height of each option row in the expanded algorithm list
_NSRC_MAX = N_MICS - 1  # beamform_music's own constraint: N_MICS - n_src >= 1
_SNAP_FLASH_S = 0.15    # duration of the on-screen "camera flash" after a screenshot
_SNAP_TEXT_S = 1.5      # duration of the "Saved ..." confirmation text
_ZOOM_FRAC = 0.35       # zoom crop width as a fraction of the native camera width
                        # (~3x digital zoom); crop height is derived to match the
                        # display's own aspect ratio so the crop resizes back up
                        # without distortion

# Dwell slider: how long Zoom mode holds its frozen crop before auto-recentering on
# the current peak. Discrete detents (not a continuous range) since the useful steps
# are non-uniform — fine-grained near 0 (fractions of a minute), coarser toward a few
# minutes — and the last entry is a sentinel (None) for "hold" (today's default
# behavior: never auto-recenter, stay until the user taps Recenter or exits Zoom).
_DWELL_LEVELS = (0, 2, 5, 10, 15, 20, 30, 45, 60, 90, 120, 150, 180, None)
_DWELL_MAX = len(_DWELL_LEVELS) - 1
_DWELL_HOLD_IDX = _DWELL_MAX  # last slot is the "HOLD" sentinel


def _dwell_label(seconds):
    """Human label for a dwell setting: None -> 'HOLD', 0 -> 'Follow', else Ns/Nm."""
    if seconds is None:
        return 'HOLD'
    if seconds == 0:
        return 'Follow'
    if seconds < 60:
        return f'{seconds:g}s'
    return f'{seconds / 60:g}m'


_sliders  = {'flo': 500, 'fhi': 4000, 'drag': None, 'frame_h': 480, 'frame_w': 640,
             'pan_x0': 0, 'pan_flo0': 500, 'pan_fhi0': 4000,
             'auto_range': True, 'thresh_db': 30, 'popup_open': False,
             'algo': 'ds', 'algo_open': False, 'nsrc': 1, 'paused': False,
             'exit_requested': False, 'screenshot_requested': False,
             'zoom_mode': False, 'recenter_requested': False, 'dwell_idx': _DWELL_HOLD_IDX}
# Guards _sliders: written by _on_mouse (OpenCV's Qt backend may dispatch input
# callbacks off the main loop's thread) and read/corrected by the main loop each frame.
_sliders_lock = threading.Lock()


def _track_geom(w):
    """Shared by both sliders (and _on_mouse) so Flo/Hi always agree on where a
    given Hz value sits on screen: inset by _TRACK_LEFT/_TRACK_RIGHT — asymmetric so
    the visual gap to the label and to the value text matches on both sides despite
    their very different widths (see the constants above)."""
    return _TRACK_LEFT, max(w - _TRACK_LEFT - _TRACK_RIGHT, 1)


def _slider_strip(w, sub, val, vmax, color):
    """"F" with a subscript ('hi' or 'lo') in the left margin, the live Hz value in
    the right margin — same layout for both sliders so Flo and Fhi line up."""
    strip = np.full((_SLIDER_H, w, 3), 28, dtype=np.uint8)
    track_x0, track_w = _track_geom(w)
    yc = _SLIDER_H // 2
    cv2.rectangle(strip, (track_x0, yc - 3), (track_x0 + track_w, yc + 3), (80, 80, 80), -1)
    xh = track_x0 + int(val / vmax * track_w)
    handle_x0 = max(track_x0, xh - 5)
    handle_x1 = min(track_x0 + track_w, xh + 5)
    cv2.rectangle(strip, (handle_x0, yc - 7), (handle_x1, yc + 7), color, -1)

    (f_w, f_h), _ = cv2.getTextSize('F', cv2.FONT_HERSHEY_SIMPLEX,
                                     _SLIDER_FONT_SCALE, _SLIDER_FONT_THICK)
    # Combined glyph block spans [main_y - f_h, main_y + _SUB_DROP] (F's top to the
    # subscript's baseline); solving (top + bottom) / 2 == yc for main_y:
    main_y = yc + (f_h - _SUB_DROP) // 2
    cv2.putText(strip, 'F', (_SLIDER_TEXT_PAD, main_y),
                cv2.FONT_HERSHEY_SIMPLEX, _SLIDER_FONT_SCALE, (180, 180, 180), _SLIDER_FONT_THICK)
    cv2.putText(strip, sub, (_SLIDER_TEXT_PAD + f_w + _SUB_GAP, main_y + _SUB_DROP),
                cv2.FONT_HERSHEY_SIMPLEX, _SUB_FONT_SCALE, (180, 180, 180), _SUB_FONT_THICK)

    value_text = f'{val} Hz'
    (value_w, value_h), _ = cv2.getTextSize(value_text, cv2.FONT_HERSHEY_SIMPLEX,
                                             _SLIDER_FONT_SCALE, _SLIDER_FONT_THICK)
    cv2.putText(strip, value_text, (w - value_w - _SLIDER_TEXT_PAD, yc + value_h // 2),
                cv2.FONT_HERSHEY_SIMPLEX, _SLIDER_FONT_SCALE, (180, 180, 180), _SLIDER_FONT_THICK)
    return strip


def _popup_layout(w, algo_open, algo, zoom_mode):
    """Settings tab + popup rects, in video-frame (x, y) coordinates, derived purely
    from frame width w (and algo_open/algo, for the expandable algorithm list and the
    MUSIC-only Nsrc row; and zoom_mode, for the Zoom-only Recenter button and Dwell
    slider rows) — mirrors _track_geom's style so drawing and _on_mouse hit-testing
    can't disagree."""
    tab_x1 = w - _TAB_MARGIN
    tab_x0 = tab_x1 - _TAB_SIZE
    tab = (tab_x0, _TAB_MARGIN, tab_x1, _TAB_MARGIN + _TAB_SIZE)

    popup_x1 = tab_x1
    popup_x0 = max(popup_x1 - _POPUP_W, 0)
    popup_y0 = tab[3] + 4

    pause_btn = (popup_x0 + _POPUP_PAD, popup_y0 + _POPUP_PAD,
                 popup_x1 - _POPUP_PAD, popup_y0 + _POPUP_PAD + _POPUP_BTN_H)

    zoom_btn = (pause_btn[0], pause_btn[3] + _POPUP_ROW_GAP,
                pause_btn[2], pause_btn[3] + _POPUP_ROW_GAP + _POPUP_BTN_H)

    recenter_btn = None
    dwell_label_y = dwell_track_x0 = dwell_track_w = dwell_track_y = None
    zoom_bottom = zoom_btn[3]
    if zoom_mode:
        recenter_btn = (zoom_btn[0], zoom_bottom + _POPUP_ROW_GAP,
                         zoom_btn[2], zoom_bottom + _POPUP_ROW_GAP + _POPUP_BTN_H)
        dwell_label_y = recenter_btn[3] + _POPUP_ROW_GAP + 10
        dwell_track_x0 = recenter_btn[0] + 4
        dwell_track_w = max((recenter_btn[2] - 4) - dwell_track_x0, 1)
        dwell_track_y = dwell_label_y + _POPUP_ROW_GAP + 10
        zoom_bottom = dwell_track_y + 7  # handle half-height, mirrors nsrc's content_bottom pattern

    toggle = (zoom_btn[0], zoom_bottom + _POPUP_ROW_GAP,
              zoom_btn[2], zoom_bottom + _POPUP_ROW_GAP + _POPUP_BTN_H)

    label_y = toggle[3] + _POPUP_ROW_GAP + 10

    track_x0 = toggle[0] + 4
    track_w = max((toggle[2] - 4) - track_x0, 1)
    track_y = label_y + _POPUP_ROW_GAP + 10

    algo_btn = (toggle[0], track_y + 7 + _POPUP_ROW_GAP,
                toggle[2], track_y + 7 + _POPUP_ROW_GAP + _POPUP_BTN_H)

    algo_opts = []
    if algo_open:
        oy = algo_btn[3]
        for _ in _ALGOS:
            algo_opts.append((algo_btn[0], oy, algo_btn[2], oy + _ALGO_ROW_H))
            oy += _ALGO_ROW_H

    content_bottom = algo_opts[-1][3] if algo_opts else algo_btn[3]

    nsrc_label_y = nsrc_track_x0 = nsrc_track_w = nsrc_track_y = None
    if algo == 'music':
        nsrc_label_y = content_bottom + _POPUP_ROW_GAP + 10
        nsrc_track_x0 = toggle[0] + 4
        nsrc_track_w = max((toggle[2] - 4) - nsrc_track_x0, 1)
        nsrc_track_y = nsrc_label_y + _POPUP_ROW_GAP + 10
        content_bottom = nsrc_track_y + 7  # handle half-height

    snap_btn = (toggle[0], content_bottom + _POPUP_ROW_GAP,
                toggle[2], content_bottom + _POPUP_ROW_GAP + _POPUP_BTN_H)
    content_bottom = snap_btn[3]

    # Exit sits last, separated from the frequently-used controls above it, and is
    # always present regardless of algo/algo_open state.
    exit_btn = (toggle[0], content_bottom + _POPUP_ROW_GAP,
                toggle[2], content_bottom + _POPUP_ROW_GAP + _POPUP_BTN_H)
    content_bottom = exit_btn[3]

    popup_bottom = content_bottom + _POPUP_PAD
    popup = (popup_x0, popup_y0, popup_x1, popup_bottom)

    return {'tab': tab, 'popup': popup, 'pause_btn': pause_btn,
            'zoom_btn': zoom_btn, 'recenter_btn': recenter_btn,
            'dwell_label_y': dwell_label_y, 'dwell_track_x0': dwell_track_x0,
            'dwell_track_w': dwell_track_w, 'dwell_track_y': dwell_track_y,
            'toggle': toggle,
            'label_y': label_y, 'track_x0': track_x0, 'track_w': track_w,
            'track_y': track_y, 'algo_btn': algo_btn, 'algo_opts': algo_opts,
            'nsrc_label_y': nsrc_label_y, 'nsrc_track_x0': nsrc_track_x0,
            'nsrc_track_w': nsrc_track_w, 'nsrc_track_y': nsrc_track_y,
            'snap_btn': snap_btn,
            'exit_btn': exit_btn}


def _draw_tab(frame, layout):
    """Always-visible tab in the video frame's corner; tapping it opens/closes the
    settings popup. Drawn as a hamburger icon (three bars) rather than text — OpenCV's
    Hershey fonts don't reliably render gear/settings glyphs, and a plain geometric
    icon reads clearly at touch-target size."""
    x0, y0, x1, y1 = layout['tab']
    fill = np.full((y1 - y0, x1 - x0, 3), 28, dtype=np.uint8)
    frame[y0:y1, x0:x1] = cv2.addWeighted(frame[y0:y1, x0:x1], 0.35, fill, 0.65, 0)
    bar_x0, bar_x1 = x0 + 11, x1 - 11
    for frac in (0.32, 0.5, 0.68):
        by = y0 + int((y1 - y0) * frac)
        cv2.line(frame, (bar_x0, by), (bar_x1, by), (220, 220, 220), 2)


_BATT_W = 44          # battery icon body width
_BATT_H = 20           # battery icon body height (matches the settings tab's row)
_BATT_NUB_W = 4        # width of the small terminal nub on the icon's right edge


def _draw_battery(frame, x1, percent):
    """Battery icon + percentage text, right edge at x1, vertically centered on the
    (taller) settings tab. Fill color shifts green -> amber -> red as charge drops."""
    y0 = _TAB_MARGIN + (_TAB_SIZE - _BATT_H) // 2
    y1 = y0 + _BATT_H
    body_x1 = x1 - _BATT_NUB_W - 2
    body_x0 = body_x1 - _BATT_W
    nub_y0 = y0 + _BATT_H // 4
    nub_y1 = y1 - _BATT_H // 4

    if percent >= 50:
        color = (80, 200, 80)
    elif percent >= 20:
        color = (0, 200, 220)
    else:
        color = (0, 0, 220)

    cv2.rectangle(frame, (body_x0, y0), (body_x1, y1), (200, 200, 200), 1)
    cv2.rectangle(frame, (body_x1, nub_y0), (body_x1 + _BATT_NUB_W, nub_y1), (200, 200, 200), -1)
    fill_w = int((_BATT_W - 4) * percent / 100)
    if fill_w > 0:
        cv2.rectangle(frame, (body_x0 + 2, y0 + 2), (body_x0 + 2 + fill_w, y1 - 2), color, -1)

    label = f'{percent:.0f}%'
    (tw, th), _ = cv2.getTextSize(label, cv2.FONT_HERSHEY_SIMPLEX, 0.4, 1)
    cv2.putText(frame, label, (body_x0 - tw - 6, y0 + (_BATT_H + th) // 2),
                cv2.FONT_HERSHEY_SIMPLEX, 0.4, (220, 220, 220), 1)
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

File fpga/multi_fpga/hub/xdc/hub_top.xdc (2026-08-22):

set_property -dict {PACKAGE_PIN U8 IOSTANDARD LVCMOS33} [get_ports TCXO_CLK]
set_property -dict {PACKAGE_PIN V8 IOSTANDARD LVCMOS33} [get_ports FPGA_RESET_N]
set_property -dict {PACKAGE_PIN G17 IOSTANDARD LVCMOS33} [get_ports SPOKES_ALIVE]
set_property -dict {PACKAGE_PIN M3 IOSTANDARD LVCMOS33} [get_ports SPOKE0_D0]
set_property -dict {PACKAGE_PIN L3 IOSTANDARD LVCMOS33} [get_ports SPOKE0_D1]
set_property -dict {PACKAGE_PIN A16 IOSTANDARD LVCMOS33} [get_ports SPOKE0_D2]
set_property -dict {PACKAGE_PIN K3 IOSTANDARD LVCMOS33} [get_ports SPOKE0_D3]
set_property -dict {PACKAGE_PIN C15 IOSTANDARD LVCMOS33} [get_ports SPOKE0_D4]
set_property -dict {PACKAGE_PIN H1 IOSTANDARD LVCMOS33} [get_ports SPOKE0_D5]
set_property -dict {PACKAGE_PIN A15 IOSTANDARD LVCMOS33} [get_ports SPOKE0_STROBE]
set_property -dict {PACKAGE_PIN B15 IOSTANDARD LVCMOS33} [get_ports SPOKE1_D0]
set_property -dict {PACKAGE_PIN A14 IOSTANDARD LVCMOS33} [get_ports SPOKE1_D1]
set_property -dict {PACKAGE_PIN J3 IOSTANDARD LVCMOS33} [get_ports SPOKE1_D2]
set_property -dict {PACKAGE_PIN J1 IOSTANDARD LVCMOS33} [get_ports SPOKE1_D3]
set_property -dict {PACKAGE_PIN K2 IOSTANDARD LVCMOS33} [get_ports SPOKE1_D4]
set_property -dict {PACKAGE_PIN L1 IOSTANDARD LVCMOS33} [get_ports SPOKE1_D5]
set_property -dict {PACKAGE_PIN L2 IOSTANDARD LVCMOS33} [get_ports SPOKE1_STROBE]
set_property -dict {PACKAGE_PIN M1 IOSTANDARD LVCMOS33} [get_ports SPOKE2_D0]
set_property -dict {PACKAGE_PIN N3 IOSTANDARD LVCMOS33} [get_ports SPOKE2_D1]
set_property -dict {PACKAGE_PIN P3 IOSTANDARD LVCMOS33} [get_ports SPOKE2_D2]
set_property -dict {PACKAGE_PIN M2 IOSTANDARD LVCMOS33} [get_ports SPOKE2_D3]
set_property -dict {PACKAGE_PIN N1 IOSTANDARD LVCMOS33} [get_ports SPOKE2_D4]
set_property -dict {PACKAGE_PIN N2 IOSTANDARD LVCMOS33} [get_ports SPOKE2_D5]
set_property -dict {PACKAGE_PIN P1 IOSTANDARD LVCMOS33} [get_ports SPOKE2_STROBE]
set_property -dict {PACKAGE_PIN T3 IOSTANDARD LVCMOS33} [get_ports SPOKE3_D0]
set_property -dict {PACKAGE_PIN R2 IOSTANDARD LVCMOS33} [get_ports SPOKE3_D1]
set_property -dict {PACKAGE_PIN T1 IOSTANDARD LVCMOS33} [get_ports SPOKE3_D2]
set_property -dict {PACKAGE_PIN T2 IOSTANDARD LVCMOS33} [get_ports SPOKE3_D3]
set_property -dict {PACKAGE_PIN U1 IOSTANDARD LVCMOS33} [get_ports SPOKE3_D4]
set_property -dict {PACKAGE_PIN W2 IOSTANDARD LVCMOS33} [get_ports SPOKE3_D5]
set_property -dict {PACKAGE_PIN V2 IOSTANDARD LVCMOS33} [get_ports SPOKE3_STROBE]
set_property -dict {PACKAGE_PIN W3 IOSTANDARD LVCMOS33} [get_ports SPOKE_CLK]
set_property -dict {PACKAGE_PIN B16 IOSTANDARD LVCMOS33} [get_ports led0_g]
set_property -dict {PACKAGE_PIN C17 IOSTANDARD LVCMOS33} [get_ports led0_r]
set_property -dict {PACKAGE_PIN B17 IOSTANDARD LVCMOS33} [get_ports led0_b]
set_property -dict {PACKAGE_PIN W7 IOSTANDARD LVCMOS33} [get_ports USB_CLKOUT]
set_property -dict {PACKAGE_PIN V3 IOSTANDARD LVCMOS33} [get_ports USB_D0]
set_property -dict {PACKAGE_PIN W5 IOSTANDARD LVCMOS33} [get_ports USB_D1]
set_property -dict {PACKAGE_PIN V4 IOSTANDARD LVCMOS33} [get_ports USB_D2]
set_property -dict {PACKAGE_PIN U4 IOSTANDARD LVCMOS33} [get_ports USB_D3]
set_property -dict {PACKAGE_PIN V5 IOSTANDARD LVCMOS33} [get_ports USB_D4]
set_property -dict {PACKAGE_PIN W4 IOSTANDARD LVCMOS33} [get_ports USB_D5]
set_property -dict {PACKAGE_PIN U5 IOSTANDARD LVCMOS33} [get_ports USB_D6]
set_property -dict {PACKAGE_PIN U2 IOSTANDARD LVCMOS33} [get_ports USB_D7]
set_property -dict {PACKAGE_PIN W6 IOSTANDARD LVCMOS33} [get_ports USB_WR_N]
set_property -dict {PACKAGE_PIN U3 IOSTANDARD LVCMOS33} [get_ports USB_TXE_N]
set_property ASYNC_REG true [get_cells -hier -filter { NAME =~ "*/tgl?_meta_reg" || NAME =~ "*/tgl?_sync_reg" || NAME =~ "*rst_usb_meta_reg" || NAME =~ "*rst_usb_reg" }]
# Hub FPGA (Digilent Cmod A7-35T) pin constraints for hub_top.v.
#
# All ports hub_top.v currently declares are populated, including the USB
# FIFO bridge (usb_framer.v -- see fpga/USB_FRAMING.md) to the FTDI UM232H
# module (A5). USB_D0-7/USB_WR_N/USB_TXE_N land on A6 DIP pins 35-44, same
# range the old (removed) async Adafruit FT232H design used -- this design
# needs one fewer pin (11 vs. 12: no RD_N/RXF_N ports, see usb_framer.v's
# header comment for why), so no spoke-bus pin needed to move.
#
# USB_CLKOUT specifically had to land on an MRCC/SRCC P-side pin (it feeds a
# BUFG in hub_top.v) -- pio[45]/U7 (IO_L19P_T3_34, where the schematic
# originally routed it) is NOT clock-capable and fails Vivado's placer with
# a hard rule_gclkio_bufg error ("Poor placement for routing between an IO
# pin and BUFG" / "IO Clock Placer failed"), confirmed by an actual
# synth+place run before the schematic was corrected -- same class of issue
# as the earlier SPOKE_CLK/PDM_D08 pin swap. Moved to pio[46]/W7
# (IO_L13P_T2_MRCC_34, P-side MRCC), which was unused and satisfies the
# requirement directly.
#
# Net -> Cmod A7 PIOnn / JAn assignments read directly off
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

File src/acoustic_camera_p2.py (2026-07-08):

#!/usr/bin/env python3
"""Phase 2 live acoustic camera: ReSpeaker 4-mic → beamform → OpenCV overlay.

Historical Phase 2 pipeline (retired ReSpeaker hardware, 1D azimuth-only);
kept as-is. The shared Phase 3+ beamforming math lives in beamforming.py.

Usage:
    python src/acoustic_camera_p2.py
    python src/acoustic_camera_p2.py --algo mvdr --freq 2000
    python src/acoustic_camera_p2.py --algo ds --freq 1000 --cal test/ReSpeaker/cal.npy
    python src/acoustic_camera_p2.py --video 2
"""
import argparse
import collections
import threading
import time

import cv2
import numpy as np
import sounddevice as sd
from scipy.linalg import inv

# --- Array geometry (4-mic circular, 90mm diameter) ---
C = 343.0
RADIUS = 0.045
_angles = np.array([0.0, 90.0, 180.0, 270.0])
MIC_X = RADIUS * np.cos(np.radians(_angles))
MIC_Y = RADIUS * np.sin(np.radians(_angles))
MIC_SLICE = slice(2, 6)   # USB ch2-5 = Mic 0-3 raw


# --- Beamforming ---

def _sm(az_grid, freq):
    u = np.sin(np.radians(az_grid))
    return np.exp(1j * 2 * np.pi * freq / C * np.outer(MIC_X, u)) / np.sqrt(4)


def beamform_ds(R, freq, az_grid):
    H = _sm(az_grid, freq)
    return np.real(np.sum(H.conj() * (R @ H), axis=0))


def beamform_mvdr(R, freq, az_grid, diag_load=0.01):
    N = R.shape[0]
    Rl = R + diag_load * np.trace(R) / N * np.eye(N)
    Ri = inv(Rl)
    H = _sm(az_grid, freq)
    d = np.real(np.sum(H.conj() * (Ri @ H), axis=0))
    return 1.0 / np.maximum(d, 1e-300)


def beamform_clean(R, freq, az_grid, n_iter=20, loop_gain=0.5):
    H = _sm(az_grid, freq)
    R_w = R.copy()
    clean = np.zeros(len(az_grid))
    for _ in range(n_iter):
        P = np.real(np.sum(H.conj() * (R_w @ H), axis=0))
        k = np.argmax(P)
        h = H[:, k]
        P_src = np.real(h.conj() @ (R_w @ h))  # scalar source power at peak
        R_w -= loop_gain * P_src * np.outer(h, h.conj())
        clean[k] += loop_gain * P_src
    return clean


def beamform_music(R, freq, az_grid, n_src=1):
    N = R.shape[0]
    _, V = np.linalg.eigh(R)       # eigenvalues ascending; V[:,i] = i-th eigenvector
    En = V[:, :N - n_src]          # noise subspace: smallest N-n_src eigenvectors
    H = _sm(az_grid, freq)
    proj = En.conj().T @ H         # (N-n_src, n_az)
    denom = np.real(np.sum(proj.conj() * proj, axis=0))
    return 1.0 / np.maximum(denom, 1e-300)


def compute_csm(audio, freq, block_size=256, hop=128):
    n_samp, n_ch = audio.shape
    freqs = np.fft.rfftfreq(block_size, 1 / 16000)
    f_idx = np.argmin(np.abs(freqs - freq))
    R = np.zeros((n_ch, n_ch), dtype=complex)
    count = 0
    win = np.hanning(block_size)
    for start in range(0, n_samp - block_size, hop):
        block = audio[start:start + block_size] * win[:, np.newaxis]
        F = np.fft.rfft(block, axis=0)[f_idx]
        R += np.outer(F, F.conj())
        count += 1
    return R / max(count, 1)


# --- Overlay rendering ---

def energy_strip(P, frame_w, strip_h, ref, db_range=30):
    """1D power map → BGR color strip of shape (strip_h, frame_w, 3)."""
    P_db = 10 * np.log10(np.maximum(P / max(ref, 1e-30), 1e-10))
    norm = np.clip((P_db + db_range) / db_range, 0, 1)
    row = (norm * 255).astype(np.uint8).reshape(1, -1)
    row_w = cv2.resize(row, (frame_w, 1), interpolation=cv2.INTER_LINEAR)
    strip = cv2.applyColorMap(row_w, cv2.COLORMAP_INFERNO)
    return np.repeat(strip, strip_h, axis=0)


# --- Main ---

def find_device():
    for i, d in enumerate(sd.query_devices()):
        if d['max_input_channels'] >= 6 and (
                'respeaker' in d['name'].lower() or 'xvf' in d['name'].lower()):
            return i
    return None


def main():
    ap = argparse.ArgumentParser(description='Phase 2 acoustic camera live demo')
    ap.add_argument('--algo',   choices=['ds', 'mvdr', 'clean', 'music'], default='ds')
    ap.add_argument('--freq',   type=float, default=1000.0,  help='beamforming frequency (Hz)')
    ap.add_argument('--snap',   type=int,   default=64,      help='CSM blocks to average')
    ap.add_argument('--device', type=int,   default=None,    help='sounddevice index')
    ap.add_argument('--nsrc',   type=int,   default=1,       help='number of sources (MUSIC only)')
    ap.add_argument('--cal',    type=str,   default=None,    help='path to cal.npy')
    ap.add_argument('--fov',    type=float, default=90.0,    help='display FOV (deg)')
    ap.add_argument('--video',  type=int,   default=0,       help='cv2.VideoCapture device index')
    args = ap.parse_args()

    cal_e = np.load(args.cal) if args.cal else None
    az_grid = np.linspace(-args.fov / 2, args.fov / 2, 901)

    dev_idx = args.device if args.device is not None else find_device()
    if dev_idx is None:
        raise RuntimeError('ReSpeaker not found — use --device IDX to specify')

    ALGO = {
        'ds':    beamform_ds,
        'mvdr':  beamform_mvdr,
        'clean': beamform_clean,
        'music': lambda R, f, az: beamform_music(R, f, az, args.nsrc),
    }[args.algo]

    # Audio circular buffer: holds enough samples for args.snap CSM blocks
    n_buf = args.snap * 128 + 256
    audio_buf: collections.deque = collections.deque(maxlen=n_buf)
    buf_lock = threading.Lock()

    def audio_cb(indata, frames, ts, status):  # ts avoids shadowing `time` module
        mic = indata[:, MIC_SLICE].copy()
        with buf_lock:
            for row in mic:
                audio_buf.append(row)

    stream = sd.InputStream(
        samplerate=16000, channels=6, dtype='float32',
        device=dev_idx, blocksize=256, callback=audio_cb,
    )

    cam = cv2.VideoCapture(args.video)
    if not cam.isOpened():
        print('No webcam — showing audio-only overlay on black frame')
        cam = None

    print(f'algo={args.algo}  freq={args.freq:.0f}Hz  fov=±{args.fov/2:.0f}°  '
          f'snap={args.snap}  cal={"yes" if cal_e is not None else "no"}')
    print('Press q to quit.')

    label = 'Filling buffer...'
    P = None
    ref_power = 1e-10   # running peak reference; decays toward current level
    t_last = time.monotonic()
    fps = 0.0

    win = 'Acoustic Camera — Phase 2'
    cv2.namedWindow(win, getattr(cv2, 'WINDOW_GUI_NORMAL', cv2.WINDOW_NORMAL))

    with stream:
        while True:
            time.sleep(0.05)

            if cam is not None:
                ret, frame = cam.read()
                if not ret:
                    frame = np.zeros((480, 640, 3), dtype=np.uint8)
            else:
                frame = np.zeros((480, 640, 3), dtype=np.uint8)

            h, w = frame.shape[:2]
            strip_h = max(40, h // 8)

            with buf_lock:
                n_avail = len(audio_buf)

            if n_avail >= n_buf:
                with buf_lock:
                    arr = np.array(list(audio_buf), dtype=np.float32)  # (n_buf, 4)
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

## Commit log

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2026-05-07 Fixed display loop bug.
    [acoustic_camera_p2.py]
2026-05-07 Fixed energy display strip.
    [acoustic_camera_p2.py]
2026-05-07 Fixed error in clean algo.
    [acoustic_camera_p2.py]
2026-05-23 Fixed x-axis mirror. Added temporal smoothing.
    [acoustic_camera_p3.py]
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2026-07-06 Updated after additional (failed) calibration attempts.
2026-07-07 Fixed loop delay bug.
    [acoustic_camera_p3.py]
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2026-07-07 Fixed hi/lo freq sliders.
    [acoustic_camera_p3.py]
2026-07-07 Fixed format of fhi line.
    [acoustic_camera_p3.py]
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2026-07-08 Fix small p3 defects: dead --freq arg, cal guard, cleanup on exception.
    - Remove --freq (sliders own the beamforming frequency; the arg was
    overwritten every frame but still advertised at startup)
    - Validate --cal before use: file exists, shape (16,), no zero entries
    - try/finally around the main loop so camera/window cleanup runs even
    if a frame iteration raises
    - Note Phase 2 script as historical; point README at src/beamforming.py
    [acoustic_camera_p2.py, acoustic_camera_p3.py]
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2026-07-12 Adjusted snap message location.
    [acoustic_camera_p3.py]
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2026-07-21 Fixed bug in calibration.
    [calibrate_uma16.py]
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2026-07-21 Removed placeholder connector - direct wired now.
    [cluster_00.kicad_sch, cluster_01.kicad_sch, cluster_02.kicad_sch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]
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2026-07-22 Updated to KiCad 10.0 and fixed errors.
    [arm_00.kicad_sch, arm_01.kicad_sch, arm_02.kicad_sch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]
2026-07-22 Updated by new generator.
    [arm_00.kicad_sch, arm_01.kicad_sch, arm_02.kicad_sch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]
2026-07-22 Updated with fixed generator.
    [arm_00.kicad_sch, arm_01.kicad_sch, arm_02.kicad_sch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]
2026-07-22 Manualy fixed cosmetic issues.
    [arm_00.kicad_sch, arm_01.kicad_sch, arm_02.kicad_sch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]
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2026-07-22 Manual cosmetic fixes.
    [arm_00.kicad_sch, arm_01.kicad_sch, arm_02.kicad_sch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]
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2026-07-22 Added footprint link issues.
2026-07-22 Updated for layout, also added page for decoupling caps.
    [arm_00.kicad_sch, arm_01.kicad_sch, arm_02.kicad_sch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]
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2026-07-22 Changed to place cmod s7 modules radially.
    [layout.kicad_pcb]
2026-07-22 Adjusted location of cmod S7 modules.
    [layout.kicad_pcb]
2026-07-22 Fixed chord bug. Made board-to-board interconnect and standoffs to hub.
2026-07-22 Updated with b-2-b connectors.
    [arm_00.kicad_sch, arm_01.kicad_sch, arm_02.kicad_sch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]
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2026-07-22 Fixed inner circle of mics.
    [cluster_00.kicad_pcb, cluster_01.kicad_pcb, cluster_02.kicad_pcb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]
2026-07-23 Removed individual arm pages.
    [cluster_00.kicad_pcb, cluster_01.kicad_pcb, cluster_02.kicad_pcb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]
2026-07-23 Made single arm board with regular layout.
    [hub.kicad_pcb]
2026-07-23 Made hub rectangular and manhattan.
    [arm_board.kicad_pcb, hub.kicad_pcb]
2026-07-23 Regularized and shrunk the hub board.
    [arm_board.kicad_pcb, hub.kicad_pcb]
2026-07-23 Manual adjustments to the layout.
    [hub.kicad_pcb]
2026-07-23 First cut at routing.
    [arm_board.kicad_pcb, hub.kicad_pcb]
2026-07-23 Manual routing of mic SEL lines.
    [arm_board.kicad_pcb, hub.kicad_pcb]
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2026-07-23 Fixed Y1 overlap.
    [hub.kicad_pcb]
2026-07-23 Updated after mic and cap fixes.
    [arm_00.kicad_sch, arm_01.kicad_sch, arm_02.kicad_sch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]
2026-07-23 Fixed mic pinout error. Fixed cap placement.
    [route_arm_board.py]
2026-07-23 Manually fixed tracks_crossing error. Fixed GND_POUR zone.
    [arm_board.kicad_pcb, hub.kicad_pcb]
2026-07-23 Put more space between caps and mics.
    [arm_board.kicad_pcb]
2026-07-23 Grounded pad ring around mic orfice. Moved caps further from mics. Manually fixed around U20.
    [arm_board.kicad_pcb]
2026-07-23 Manually fixed four caps that were too close. Excluded hole-related DRC errors.
    [arm_board.kicad_pcb]
2026-07-23 Fixed DATA_07 bridge and duplicate stub near U2.
    [arm_board.kicad_pcb]
2026-07-23 Moved labels to avoid mask clipping. DRC clean.
    [arm_board.kicad_pcb]
2026-07-24 Manually fixed autorouter failures. DRC-clean.
    [hub.kicad_pcb]
2026-07-24 Moved A6 and manually fixed connections. DRC-clean.
    [hub.kicad_pcb]
2026-07-24 Reduced size of the hub board.
    [hub.kicad_pcb]
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2026-07-26 Changed to current version of FT232H.
    [arm_board.kicad_pcb, hub.kicad_pcb, hub.kicad_sch]
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2026-07-26 Updated after change of FT232H. DRC-Clean.
    [arm_00.kicad_sch, arm_01.kicad_sch, arm_02.kicad_sch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]
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2026-07-26 Added ground copper pour.
    [hub.kicad_pcb]
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2026-07-27 Flipped 6x2 recepticles to back side.
    [arm_board.kicad_pcb, cluster_00.kicad_sch, cluster_01.kicad_sch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]
2026-07-27 Updated schematic generator to make cosmetic changes.
    [arm_00.kicad_sch, arm_01.kicad_sch, arm_02.kicad_sch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]
2026-07-27 Fixed locations of power and spoke connectors.
    [arm_board.kicad_pcb, arm_board.step, hub.kicad_pcb]
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2026-07-28 Fixed with real TXO.
    [hub.kicad_pcb, hub.kicad_sch]
2026-07-28 Hand routed after TXO fix.
    [hub.kicad_pcb]
2026-07-28 Fixed origin bug with 3D model of TXO.
    [hub.kicad_pcb]
2026-07-28 Fixed bad orientation of TXO.
    [hub.kicad_pcb, hub.step]
2026-07-29 Added new Adafruit FT232H.
    [hub.kicad_pcb]
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2026-07-29 Updated after finished hand-routing.
    [arm_board.step]
2026-07-29 Rotated USB-C connector down. Hand-routed. DRC-clean.
    [hub.kicad_pcb, hub.kicad_sch]
2026-07-29 Fixed FT232H footprint.
    [cluster_00.kicad_sch, cluster_01.kicad_sch, cluster_02.kicad_sch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]
2026-07-30 Hand-routed/-placed. Fixed camera mounts. DRC-clean.
    [hub.kicad_pcb, hub.step]
2026-07-30 Fixed FT232H footprint file reference.
2026-07-30 Fixed location of FT232H 3D model.
    [hub.kicad_pcb]
2026-07-30 Updated with proper locations.
    [arm_board.step, hub.step]
2026-08-01 Changed to 4-layer board. Minor replacement/rerouting.
    [hub.kicad_pcb, hub.step]
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2026-08-03 Fixed library and power issues.
    [arm_00.kicad_sch, arm_01.kicad_sch, arm_02.kicad_sch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]
2026-08-03 Fixed power and C ref des collisions.
    [arm_00.kicad_sch, arm_01.kicad_sch, arm_02.kicad_sch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]
2026-08-03 Fixed annotations.
    [cluster_00.kicad_sch, cluster_01.kicad_sch, cluster_02.kicad_sch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]
2026-08-03 Fixed C and PWR ref des errors.
    [arm_00.kicad_sch, arm_01.kicad_sch, arm_02.kicad_sch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]
2026-08-03 Fixed annotation issues.
    [cluster_00.kicad_sch, cluster_01.kicad_sch, cluster_02.kicad_sch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]
2026-08-03 Fixed mis-wiring.
    [arm_01.kicad_sch, arm_02.kicad_sch]
2026-08-03 Fixed ref des collisions.
    [cluster_00.kicad_sch, cluster_01.kicad_sch]
2026-08-03 Fixed regulator connection errors and dangling wire.
    [arm_03.kicad_sch, arm_04.kicad_sch, arm_05.kicad_sch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]
2026-08-03 Added the LDO regulator part numbers.
    [cluster_00.kicad_sch, cluster_01.kicad_sch, cluster_02.kicad_sch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]
2026-08-03 Removed clock and data, rerouted bus and power.
    [arm_board.kicad_pcb]
2026-08-04 Cleaned spoke bus wires.
    [arm_board.kicad_pcb]
2026-08-04 Fixed FPGA module symbols.
    [cluster_00.kicad_sch, cluster_01.kicad_sch, cluster_02.kicad_sch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]
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2026-08-04 Removed - replaced by top.kicad_pro.
2026-08-04 Rerouted after fixing bodies and adding power caps.
    [hub.kicad_pcb, hub.kicad_sch]
2026-08-04 Global fix of res defs.
    [arm_00.kicad_sch, arm_01.kicad_sch, arm_02.kicad_sch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]
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2026-08-04 Added mic clocks. WIP.
    [arm_board.kicad_pcb]
2026-08-04 Changed to use generic cap symbols and footprints.
    [arm_00.kicad_sch, arm_01.kicad_sch, arm_02.kicad_sch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]
2026-08-04 Added stock footprints for C symbols.
    [arm_01.kicad_sch, arm_02.kicad_sch, arm_03.kicad_sch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]
2026-08-04 Changed to generic C symbols and footprints.
    [cluster_01.kicad_sch, cluster_02.kicad_sch, cluster_03.kicad_sch]
2026-08-04 Fixed wire breaks due to changing Cs.
    [cluster_00.kicad_sch, cluster_01.kicad_sch, cluster_02.kicad_sch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]
2026-08-04 Updated with stock C footprints and bodies.
    [hub.kicad_pcb, hub.kicad_sch]
2026-08-04 Made everything consistent with top.
    [arm_00.kicad_sch, arm_01.kicad_sch, arm_02.kicad_sch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]
2026-08-04 Fixed C footprint.
    [cluster_00.kicad_sch, cluster_01.kicad_sch, cluster_02.kicad_sch]
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2026-08-05 Fixed bug in footprint.
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2026-08-05 Copied from arm_board. Need to fix.
    [cluster_01.kicad_pcb, cluster_02.kicad_pcb, cluster_03.kicad_pcb]
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2026-08-05 Added reset and spoke_alive signals. Hub FPGA LED indicates boot state.
2026-08-05 Added spoke alive signals.
    [cluster_00.kicad_sch, cluster_01.kicad_sch, cluster_02.kicad_sch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]
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2026-08-05 New Cmod-A7 PMOD pins.
    [hub.kicad_sch]
2026-08-05 Added header for PMOD cable and pins for FPGA reset.
    [hub.kicad_sch]
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2026-08-05 Added footprint to reset jumper pins.
    [hub.kicad_sch]
2026-08-05 Removed PMOD from CMOD_A7 symbol.
    [hub.kicad_sch]
2026-08-06 Added reset and alive signals.
    [cluster_00.kicad_pcb]
2026-08-06 Renamed reset wire coming from FPGA.
    [hub.kicad_sch]
2026-08-06 Added reset and alive and PMOD pins.
    [hub.kicad_pcb]
2026-08-19 Added the Cmod-A7's PMOD connector.
    [hub.kicad_sch]
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2026-08-20 Switched to use only cluster_00 pcb.
    [cluster_00.kicad_pcb, cluster_00.step, cluster_01.kicad_sch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]
2026-08-20 Swapped moved spoke clk to a clock pin.
    [cluster_top.xdc]
2026-08-20 Changed CMOD-S7 to CMOD-A7 to fit design.
    [cluster_00.kicad_sch, cluster_01.kicad_sch, cluster_02.kicad_sch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]
2026-08-20 Swapped to proper clock pin.
    [cluster_00.kicad_pcb, cluster_00.kicad_sch, cluster_01.kicad_sch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]
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2026-08-20 Commented on timing (non-)issues.
    [cluster_top.xdc]
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2026-08-21 Changed USB to UM232H, in hub schematic and PCB.
    [hub.kicad_pcb, hub.kicad_sch]
2026-08-21 Fixed UM232H board's 3D model positioning.
    [hub.kicad_pcb]
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2026-08-22 Fixed UM232H 3D model positioning.
    [hub.kicad_pcb]
2026-08-22 Changed from per-spoke to shared spoke alive signals.
    [cluster_00.kicad_sch, cluster_01.kicad_sch, cluster_02.kicad_sch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]
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2026-08-24 Cleaned up old references to S7 FPGA and made everything be A7.
    [cluster_00.kicad_sch, cluster_01.kicad_sch, cluster_02.kicad_sch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]
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2026-08-25 Fixed connectors.
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2026-08-25 Added AC7200 connector group. Placed mics and caps. Added mounting holes and camera holes.
    [top.kicad_pcb, top.kicad_sch]
2026-08-25 Fixed mounting holes for Rpi Cam3 Wide.
    [top.kicad_pcb]
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2026-08-26 Fixed buck converter wiring.
    [power_clock.kicad_sch]
2026-08-26 Fixed power symbols/labels.
    [ac7200_conn1.kicad_sch, ac7200_conn2.kicad_sch, ac7200_conn3.kicad_sch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]
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2026-08-26 Fixed typo in signal name.
    [power_clock.kicad_sch]
2026-08-26 Fixed up naming/numbering.
    [mic_arm_00.kicad_sch, mic_arm_01.kicad_sch]
2026-08-26 Fixed clocks and names.
    [mic_arm_02.kicad_sch, mic_arm_03.kicad_sch, mic_arm_04.kicad_sch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]
2026-08-26 Added resister fix.
2026-08-26 Fixed all duplicate refdes's.
    [ac7200_conn1.kicad_sch, ac7200_conn2.kicad_sch, ac7200_conn3.kicad_sch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]
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2026-08-26 Fixed MIC_3V3 symbol.
    [mic_arm_00.kicad_sch, mic_arm_01.kicad_sch, mic_arm_04.kicad_sch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]
2026-08-26 Fixed symbol library references.
    [mic_arm_00.kicad_sch, mic_arm_01.kicad_sch, mic_arm_02.kicad_sch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]
2026-08-26 Fixed missing footprint.
2026-08-26 Fixed footprints.
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2026-08-26 Reorganized sheets for two-boards. Fixed connector off-grid problems.
    [ac7200_conn1.kicad_sch, ac7200_conn2.kicad_sch, ac7200_conn3.kicad_sch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]
2026-08-26 Fixed another off-grid issue. Connected power and DATA_?? pins to inter-board connector.
    [ac7200_conn2.kicad_sch, ac7200_conn3.kicad_sch, ac7200_conn4.kicad_sch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]
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2026-08-26 Fixed footprints. Added missing mic. Relinked placed footprints.
    [mic_arm_00.kicad_sch, mic_arm_01.kicad_sch, mic_arm_02.kicad_sch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]
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2026-08-27 Changed inter-board connectors (J1 and J2) to be taller.
    [array_connector.kicad_sch, front_end.kicad_sch, mic_array.kicad_pcb]
2026-08-27 Cleaned up after the change of J1 and J2.
    [array_connector.kicad_sch, front_end.kicad_sch]
2026-08-27 Fixed power nets.
    [ac7200_conn1.kicad_sch, ac7200_conn2.kicad_sch, ac7200_conn3.kicad_sch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]
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2026-08-27 Added power flag to where 3V6 comes onto the board.
    [array_connector.kicad_sch]
2026-08-27 Fixed references.
    [front_end.kicad_sch, mic_array.kicad_sch]
2026-08-27 Fixed problems caused by saving from top.kicad_pro.
    [ac7200_conn1.kicad_sch, ac7200_conn2.kicad_sch, ac7200_conn3.kicad_sch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]
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2026-08-27 Fixed ref des's to match schematics.
    [mic_array.kicad_pcb]
2026-08-27 Fixed res defs. New mic_array PCB layout.
    [array_connector.kicad_sch, mic_arm_00.kicad_sch, mic_arm_01.kicad_sch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]
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2026-08-27 Moved mic caps a little more. Moved per-arm clock drivers to mid-arm.
    [mic_array.kicad_pcb]
2026-08-27 Cleaned up silk-screen overlaps. Moved clock driver resistors closer.
    [mic_array.kicad_pcb]
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2026-08-27 Fixed silkscreen/soldermask clipping issue with J1 connector.
    [mic_array.kicad_pcb]
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2026-08-27 Added pwr and gnd to mics and caps.
    [mic_array.kicad_pcb]
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2026-09-22 ERC-clean after change to new mic symbol and body.
    [mic_array.kicad_pcb]
2026-09-23 Moved and connected caps to mics. Fixed RefDes on F.Silk.
    [front_end.kicad_sch, mic_arm_00.kicad_sch, mic_arm_01.kicad_sch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]
2026-09-23 Locked down all footprints and the mic-cap traces.
    [mic_array.kicad_pcb]
2026-09-23 Fixed inner layers setup. Locked bodies down.
    [mic_arm_00.kicad_sch, mic_arm_02.kicad_sch, mic_arm_03.kicad_sch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]
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2026-09-24 Fixed all DRC warnings.
    [mic_arm_00.kicad_sch, mic_arm_01.kicad_sch, mic_arm_02.kicad_sch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]
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2026-09-25 Balanced clocks on arms 00, 01, and 02.
    [mic_array.kicad_pcb]
2026-09-26 Balanced clock lines and added five test points.
    [mic_array.kicad_pcb]
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2026-09-30 Added Ethernet interface. Fixed power rails. ERC-clean.
    [ac7200_conn1.kicad_sch, ac7200_conn2.kicad_sch, ac7200_conn3.kicad_sch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]
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2026-10-02 Fixed magjack.
    [front_end.kicad_pcb, front_end.kicad_sch, gbe.kicad_sch]
2026-10-03 Fixed 3V6 power.
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2026-10-06 Rerouted with correct J2 pinout.
    [ac7200_conn1.kicad_sch, front_end.kicad_pcb]
2026-10-06 Fixed RJ45 3D model.
    [front_end.kicad_pcb]
2026-10-07 Made AC7200 interface a composite footprint. Fixed routing. DRC-/ERC-clean.
    [ac7200_conn1.kicad_sch, ac7200_conn2.kicad_sch, ac7200_conn3.kicad_sch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]
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2026-10-12 Made CON1-4 separate parts. Fixed board-to-board connectors.
2026-10-12 Fixed power and gnd. ERC-clean.
2026-10-13 Fixed power rails. Fixed C3. Changed U4. ERC FEB.
2026-10-13 Use correct footprints with boss holes.
2026-10-13 Fixed power rails. Ripped out single tracks. Ready for re-routing.
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2026-10-22 Fixed TXCO_CLK and PDM_CLK traces.
2026-10-22 FIxed references to 3D models of clock driver parts.
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2026-10-30 Improved layout of regulators. Fixed capped/filled vias.
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2026-10-31 Fixed output directory and wrote gerbers.
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2026-11-01 Fixed swapped DATA_00/01 traces and rebalanced clock lines.
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2026-11-02 Fixed ground island.
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

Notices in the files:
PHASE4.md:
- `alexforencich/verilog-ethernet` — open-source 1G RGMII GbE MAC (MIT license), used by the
